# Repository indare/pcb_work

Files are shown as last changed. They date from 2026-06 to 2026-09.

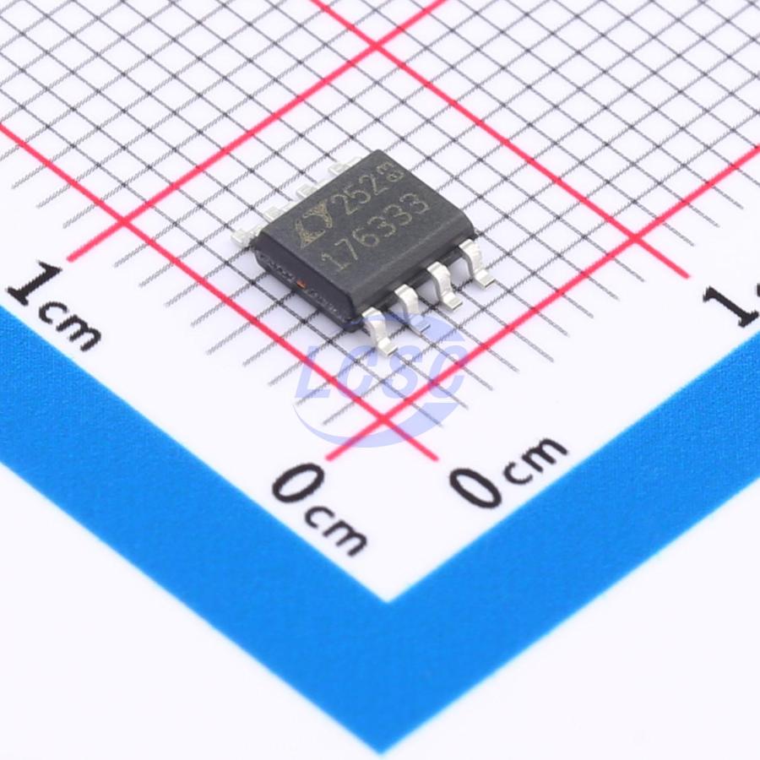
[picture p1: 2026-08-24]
tmp_lt1763_ref/lcsc_tr_front.jpg

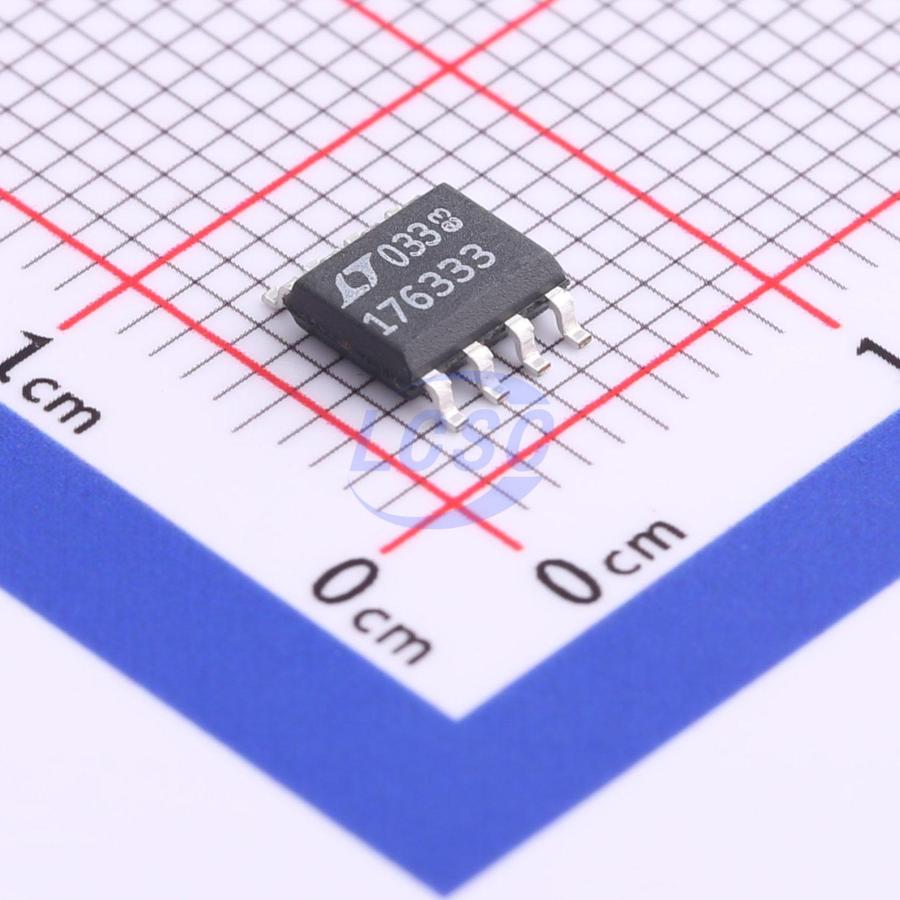
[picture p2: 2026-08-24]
tmp_lt1763_ref/lcsc_is8_front.jpg

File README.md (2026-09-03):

# PCB Work

KiCad 10 の基板・回路図リポジトリです。**いま設計作業をしているのは `AudioV2/`**。
v1 の実機（AudioCase / MeasurementADC）は `Audio/` にあり、こちらは組んで動いているものです。

## ディレクトリ

| パス | 内容 |
| --- | --- |
| `AudioV2/` | 現行の設計作業。回路図・生成スクリプト・検討メモ。[案内](AudioV2/AGENT_HANDOFF.md) |
| `Audio/` | v1 実機。AudioCase 本体・MeasurementADC・分割 Gerber・計測 FW。[案内](Audio/README.md) |
| `Control/` | Controll 用 Pico2 ファーム（親／子） |
| `docker/` | KiCad 10.0.6 のヘッドレス検証環境（ERC / ネットリスト / DRC / Gerber）。[案内](docker/kicad-cloud-build/README.md) |
| `scripts/` | 環境セットアップ。ローカルで回せない検証をクラウドエージェントへ投げるための導入手順。[案内](scripts/README.md) |
| `.cursor/` | Cursor 用ルール・MCP 設定 |

## いまの実機（要約）

- **Amp → MeasurementADC（LCD スペアナ）** が接続して動作中
- Controll 2 段は外している。EQ は今号では使わない
- 次は MeasurementADC 初号ジャンパの次号解消 → 端子台／ケース
- 詳細: [Audio/MeasurementADC_STATUS.md](Audio/MeasurementADC_STATUS.md)

## Cursor MCP（KiCad）

プロジェクト設定: [`.cursor/mcp.json`](.cursor/mcp.json)  
雛形: [`.cursor/mcp.json.example`](.cursor/mcp.json.example)

個人の絶対パスはコミットしません。Cursor の変数展開を使います。
**2026-09-04 に Cursor で実際に動作確認済み**（`${workspaceFolder}` は展開され、`uvx` は PATH から解決される）。

```json
{
  "mcpServers": {
    "kicad": {
      "type": "stdio",
      "command": "uvx",
      "args": ["kicad-mcp-pro"],
      "env": {
        "KICAD_MCP_PROJECT_DIR": "${workspaceFolder}/AudioV2",
        "KICAD_MCP_PROFILE": "full",
        "KICAD_MCP_OPERATING_MODE": "write"
      }
    }
  }
}
```

### 前提

1. [uv](https://docs.astral.sh/uv/) を入れる（`uvx` が PATH に載ること）
2. Cursor を再起動し、**Settings → Tools & MCP** で `kicad` を ON
3. KiCad で基板を開くときは IPC API を有効にしておく（MCP のライブ連携用）

### 変数

| 値 | 意味 |
| --- | --- |
| `${workspaceFolder}` | このリポジトリのルート（`.cursor/mcp.json` がある側） |
| `KICAD_MCP_PROJECT_DIR` | KiCad プロジェクトディレクトリ（現行は `AudioV2/`） |
| `KICAD_MCP_PROFILE` | `full`（2026-09-02 に `build` から変更。AudioV2 移行と同時） |
| `KICAD_MCP_OPERATING_MODE` | `write`（読み取り専用にしたい場合は `readonly`） |

### PATH に `uvx` が無い場合

ユーザー設定 `~/.cursor/mcp.json`（コミット対象外）にだけフルパスを書いてください。  
ローカル上書き用: `.cursor/mcp.local.env`（gitignore 済み）。

### Windows / Git Bash

このリポジトリの KiCad CLI は Git Bash 経由を想定しています。`kicad-cli` は KiCad 10.0 の bin が PATH にあること。

## MeasurementADC メモ

- 進捗: `Audio/MeasurementADC_STATUS.md`
- 発注: `Audio/MeasurementADC_ORDER.md`
- ブリングアップ履歴: `Audio/MeasurementADC_BRINGUP.md`
- MBC2596-01 FP（0°）: 左上 IN+ / 左下 IN- / 右上 OUT+ / 右下 OUT-

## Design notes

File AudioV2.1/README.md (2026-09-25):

# AudioV2.1

**「オペアンプを電子的に切り替えて、なんとなく音が違うのを楽しむ箱」の KiCad プロジェクト。**
計測系が載っているのは表示と簡易分析のためで、装置そのものは計測器ではない。優劣は測定ではなく耳で決める。

v2.1 は「選んだ ch だけ電源と入力を生かす」構成。何を決めたかは [DECISIONS.md](DECISIONS.md)、いま何待ちかは [NOW.md](NOW.md)。
この段落より詳しいことは以下の文書が正。**README には書かない。**

## 入口

| | 何が書いてあるか |
|---|---|
| [NOW.md](NOW.md) | **いま何待ちか・次の一手。再開はここから** |
| [CLAUDE.md](CLAUDE.md) | 守ること。シートの所有権・禁止事項・検証コマンドと期待値 |
| [DECISIONS.md](DECISIONS.md) | **決定の正。** 何を決めたか・なぜか・何を捨てたか。v2 から引き継いだものは §7 |

## この下にあるもの

| | |
|---|---|
| `*.kicad_sch` / `AudioV2.kicad_sym` / `AudioV2Case.kicad_pro` / `AudioV2Case.kicad_pcb` | 回路図と PCB |
| [lib/](lib/) | プロジェクトの KiCad ライブラリ（`Library.pretty`・`BP5293_ROHM`・`MeasurementADC1804`・`MeasurementADC_Extras`）。名前は図の `lib_id` と PCB の footprint 名が使うので変えない |
| [ds_facts/](ds_facts/) | データシートから読んだ事実（照合済み） |
| [datasheets/](datasheets/README.md) | 参照したデータシート PDF。手持ちオペアンプの DS は `datasheets/opamps/` |
| [OPAMP_STOCK.md](OPAMP_STOCK.md) | 手持ちオペアンプの一覧（ユーザー申告） |
| [PARTS.md](PARTS.md) | 品番と機能等価の代替。BOM のブロックは回路図から生成する |
| [review/](review/README.md) | 調査・否定側査読・棚卸しの記録（凍結。行番号の基準は `review/README.md`） |
| [spice/](spice/README.md) | 設計判断の根拠に回した ngspice ネットリスト |
| [scripts/](scripts/) | 回路図の生成・編集・検証の道具（v2 からの写し。扱いは [CLAUDE.md](CLAUDE.md)） |
| [firmware/](firmware/README.md) | Pico のファーム（骨格） |
| [legacy/](legacy/README.md) | 道具が読む旧シート（v2 からの写し。設計には反映されない） |
| 発注リスト | **持たない。** 発注のときに [PARTS.md](PARTS.md) の生成部品表から起こす。ベンダのデータを読むときの罠は §0b |

部品数・ERC 件数・ネット名・ピン接続は**回路図が正**。文書の値は当時のもの。

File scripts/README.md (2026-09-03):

# scripts/

リポジトリ横断のインフラ・環境系スクリプト。

## `cloud-agent-setup.sh`

Cursor Cloud Agent の**ダッシュボード管理（DB管理）開発環境**用の冪等セットアップスクリプト。

このリポジトリの検証ワークフローが前提とするツールを導入する:

| ツール | 用途 |
|---|---|
| KiCad 10 本体 (`kicad-cli` + `pcbnew`) | S式チェック後の `kicad-cli sch export netlist`、ERC / DRC / Gerber / ドリル出力、`Audio/scripts` の pcbnew 依存スクリプト |
| KiCad 標準ライブラリ (`kicad-symbols` / `kicad-footprints` / `kicad-templates`) | 標準シンボル / フットプリントの解決、グローバル lib-table |
| `ngspice` | `AudioV2/spice/*.cir` を `ngspice -b` で回す（設計判断の根拠にした波形の再現） |
| `uv` / `uvx` | README「前提」記載の kicad-mcp-pro（KiCad MCP サーバ）の起動 |

KiCad は公式 PPA `ppa:kicad/kicad-10.0-releases`（Ubuntu 24.04 で `10.0.6`）から
`--no-install-recommends` で導入する。GUI ではなくヘッドレス CLI 検証が目的のため、
`docker/kicad-cloud-build/` のソースビルドイメージと違いフルビルドは不要。

パッケージ構成は `docker/kicad-cloud-build/Dockerfile.10.0.6` の runtime 段にそろえてある
（本体 + シンボル / フットプリント / テンプレート + `ngspice` + グローバル lib-table のシード）。
3D モデル (`kicad-packages3d`, 展開 ~5.6GB) は Dockerfile 側も含めないため対象外。

### モード

| | 動き |
|---|---|
| 既定 | `apt-get` があれば導入する。無ければ**検証のみに落ちる**（下記） |
| `--verify` | 何も導入せず、揃っているかだけ見て報告する。足りなければ非ゼロ終了 |

```sh
bash scripts/cloud-agent-setup.sh            # Cloud Agent の install コマンド
bash scripts/cloud-agent-setup.sh --verify   # 環境が揃っているかだけ見る
```

冪等なので再実行しても安全。

### Windows / macOS では検証のみ

`apt-get` が無い環境では導入せず検証だけする。**黙って「セットアップ完了」と
言わせないため** — 以前は `kicad-cli` と `uv` が既にあるとどちらもスキップし、
`/usr/share/kicad/template/` が無いので lib-table のコピーも飛ばして、
何も検証せずに成功を名乗っていた。

検証は置き場の違いを吸収する。KiCad の設定は Linux が `~/.config/kicad/<ver>`、
Windows が `%APPDATA%/kicad/<ver>`。lib-table の雛形は `kicad-cli` の実体から
`../share/kicad/template` を辿るので、`/usr/share` でも
`C:/Program Files/KiCad/<ver>/share` でも同じ式で当たる。

Windows で KiCad は公式インストーラで入れる（このリポジトリは WSL2 / Docker を
前提にしない）。詳細は `.cursor/rules/kicad-cli-git-bash.mdc`。

> **`ngspice` は Windows の KiCad には CLI が入らない。** 同梱されるのは内蔵
> シミュレータ用の `ngspice.dll` と `lib/ngspice` だけで、`ngspice -b` は打てない。
> `AudioV2/spice/*.cir` を回すなら別途入れる。`--verify` はこれを検出する。

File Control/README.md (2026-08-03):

# Pico 2 Control Notes

## Board

- Board: Raspberry Pi Pico 2
- MCU: RP2350
- Firmware: MicroPython v1.28.0
- Bootloader drive name before flashing: `RP2350`

## Dual-board layout

| | Parent | Expansion (child) |
| --- | --- | --- |
| Firmware | `main.py` | `slave.py`（書き込み時は `:main.py`） |
| OLED | あり（J17） | なし |
| Encoder | あり（J13） | なし |
| Relays | UI CH1–5 | UI CH6–10（基板上はローカルCH1–5） |
| I2C role | master `400kHz` | slave `0x42` |

Parent J17（`GND` / `3V3` / `SCL` / `SDA`）を child J17 に延長する。エンコーダは親だけ。

## OLED Connection

| Pico 2 physical pin | Pico 2 signal | OLED signal |
| --- | --- | --- |
| 26 | GP20 / I2C0 SDA | SDA |
| 27 | GP21 / I2C0 SCL | SCL |
| 36 | 3V3 OUT | VCC |
| GND | GND | GND |

## I2C expansion protocol

Shared constants live in `protocol.py`.

| Register | Meaning |
| --- | --- |
| 0 | command（親が書く） |
| 1 | status |
| 2 | completion counter（コマンド完了で +1） |

| Command | Meaning |
| --- | --- |
| `0x00` | 全ローカルCH RESET |
| `0x01`–`0x05` | ローカルCH apply（ポップ対策シーケンス込み） |
| `0x10` | ping → status `0xA5` |

バス速度は 400kHz。100kHz に落とすと SSD1306 の 1KB フレーム転送が I2C タイムアウトに掛かり、描画が砂嵐になる。カスケードで波形が厳しい場合は速度を下げるのではなく `show()` をページ分割すること。

親の挙動:

- 起動時に `0x42` を scan + ping。いなければ **CH1–5 のみ**
- CH1–5 apply 時: 子へ RESET → 親ローカル apply
- CH6–10 apply 時: 親ローカル RESET → 子へ apply(`CH-5`)

## Files

| File | Role |
| --- | --- |
| `main.py` | 親UI（エンコーダ / OLED / 振り分け） |
| `slave.py` | 子I2Cスレーブ |
| `relays.py` | リレーGPIOと切替シーケンス |
| `protocol.py` | アドレス・コマンド定義 |
| `ssd1306.py` | OLEDドライバ |
| `encoder_debug.py` | エンコーダ生ログ |

## Rotary Encoder Connection

| Pico physical pin | Pico signal | Encoder signal |
| --- | --- | --- |
| 29 | GP22 | ENC_A |
| 31 | GP26 / ADC0 | ENC_B |
| 32 | GP27 / ADC1 | ENC_SW |

J13 pinout: `1=ENC_A`, `2=ENC_B`, `3=ENC_SW`, `4=3V3`, `5=GND`  
（逆挿しすると 3V3–GND 短絡でハングするので向き注意）

## Relay mapping (local board)

| Local CH | AUDIO | PWR |
| --- | --- | --- |
| 1 | K4 | K3 |
| 2 | K2 | K1 |
| 3 | K8 | K5 |
| 4 | K9 | K6 |
| 5 | K10 | K7 |

Apply sequence: AUDIO RESET → 0.1s → PWR RESET → selected PWR SET → 0.3s → selected AUDIO SET。コイルは 0.1s パルス。

## Upload

macOS example（親）:

```bash
python3 -m mpremote connect /dev/cu.usbmodem* fs cp Control/protocol.py :protocol.py
python3 -m mpremote connect /dev/cu.usbmodem* fs cp Control/relays.py :relays.py
python3 -m mpremote connect /dev/cu.usbmodem* fs cp Control/ssd1306.py :ssd1306.py
python3 -m mpremote connect /dev/cu.usbmodem* fs cp Control/main.py :main.py
python3 -m mpremote connect /dev/cu.usbmodem* reset
```

macOS example（子 / 拡張）:

```bash
python3 -m mpremote connect /dev/cu.usbmodem* fs cp Control/protocol.py :protocol.py
python3 -m mpremote connect /dev/cu.usbmodem* fs cp Control/relays.py :relays.py
python3 -m mpremote connect /dev/cu.usbmodem* fs cp Control/slave.py :main.py
python3 -m mpremote connect /dev/cu.usbmodem* reset
```

Windows では `py -3.13 -m mpremote connect COMx ...`。

BOOTSEL 時は Pico 2 の UF2 を `RP2350` ドライブへコピーして MicroPython を入れる。

## Confirmed so far (single board)

- MicroPython v1.28.0 on Pico 2
- OLED `0x3c` SSD1306 128x64
- Encoder channel select + relay apply on CH1–5
- Controll schematic ERC 0

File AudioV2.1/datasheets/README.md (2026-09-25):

# AudioV2.1 — データシート

v2.1 の設計・査読で引いている部品の一次資料。オフライン参照用にローカル PDF を置く。
DS から読んだ事実（照合済み）は [../ds_facts/](../ds_facts/)、決定は [../DECISIONS.md](../DECISIONS.md)。
2026-09-25 に、v1 の置き場から引いていた手持ちオペアンプの DS と Traco `TMR9`・`TMR6` をここへ写した（v2.1 はここだけを読む）。

## サブディレクトリ

| | 中身 |
|---|---|
| [opamps/](opamps/) | 手持ちオペアンプ 16 石＋ NE5532 本家の DS。石と PDF の対応は [../OPAMP_STOCK.md](../OPAMP_STOCK.md) |
| [boundary/](boundary/) | 境目の切替素子の候補（照合は [../ds_facts/verify_boundary.md](../ds_facts/verify_boundary.md)） |
| [detect/](detect/README.md) | 娘のレール検知の候補 |
| [relay4/](relay4/) | 4 回路リレーの候補（`ds_facts/relay4.md` は未照合） |
| [tap/](tap/) | 計測タップの結合・絶縁の候補 |
| [arch/](arch/) | 制御の木（デコーダ・ロードスイッチ・監視）の候補 |
| [reference/](reference/) | 参考製品の取説 |

## 電源・PD

| 部品 | 用途 | ローカル | 取得元 |
|---|---|---|---|
| **RS6-1215D**（Recom） | ±15 V DC-DC（v2.1 の主電源、DECISIONS §3-1） | [Recom_RS6.pdf](Recom_RS6.pdf) | Recom |
| **REC20K-2415DZ**（Recom） | ±15 V DC-DC（今の図。v2 から） | [Recom_REC20K-Z_Rev3-2025.pdf](Recom_REC20K-Z_Rev3-2025.pdf) | Recom |
| **TMR 9 / TMR 6**（Traco） | 主電源の比較の候補 | [TMR9_Datasheet.pdf](TMR9_Datasheet.pdf)・[TMR6_Datasheet.pdf](TMR6_Datasheet.pdf) | Traco |
| **[50224] CH224** | USB-PD（外付けモジュール、板上は受け端子） | [StrawberryLinux_CH224K_manual.pdf](StrawberryLinux_CH224K_manual.pdf) 他 | ストロベリーリナックス |
| **DKMW20F-15** | ±15 V DC-DC（v2 の初期に使った。今の図には無い） | [MeanWell_SKMW20_DKMW20.pdf](MeanWell_SKMW20_DKMW20.pdf) | [Mean Well SKMW20/DKMW20](https://www.meanwell.com/webapp/product/search.aspx?prod=DKMW20) |
| **BP5293-50** | +5 V（コイル・デジ） | [ROHM_BP5293-xx.pdf](ROHM_BP5293-xx.pdf) | [ROHM BP5293-xx](https://www.rohm.com/products/power-management/switching-regulators-integrated-fet/bp5293-xx-series) |
| **L7805C / L7809** | コイルの 5 V（v2.1）／PT2314E の 9 V | [ST_L78.pdf](ST_L78.pdf) | ST |
| **TPS7A49 / TPS7A30** | ch ごとの LDO（v2.1） | [TI_TPS7A49.pdf](TI_TPS7A49.pdf)・[TI_TPS7A30.pdf](TI_TPS7A30.pdf) | TI |

### DC-DC の候補（2026-09-05 の再探索。**採否は未決**）

`dcdc_survey.py` で 431 件を引き、±12 V 両レール・MOQ 1・在庫あり・12 V 入力対応の
220 件から実読した分。**選定の決め手になる `Cout`（最大容量負荷）・軽負荷での `Fsw` の
扱い・絶縁容量・最小負荷は、どれも DigiKey API には無くデータシートにしかない。**
だからここに置いてある（以下は v2 のときの探索の記録。v2.1 の比較は `../review/main_power_compare.md` ほか）。

**⚠ この表の数値は ±12 V 両出力版のもの。** 同じ系列でも単出力版・±15 V 版では `Cout` が
まるで違う（TEL 10WI は単出力 12 V が 560 µF、±12 V dual は 390 µF。EC7AW は単出力 24S12 が
833 µF、±12 V dual は 417 µF）。**モデル行を取り違えると倍以上ずれる。**

**⚠⚠ `Fsw` の欄で候補を比べてはいけない。** 「Aimtec は @100% load と条件付き、Recom は
条件が書いていない」という差は**見せかけ**だった —— Recom は同じ条件を**表の見出し**に
書いている（`REC10K-AW.pdf` p2 *"BASIC CHARACTERISTICS (measured @ TAMB= 25°C, nom. VIN,
**full load** and after warm-up unless otherwise stated)"*）。Cincon も Traco も同様の全負荷注記が
あり、**下の候補は9品すべて全負荷規定**。しかも Recom の 350 kHz は **Max. 列**（Min./Typ. 欄は空）で、
軽負荷で下がることと矛盾しない。

**この欄で意味があるのは次の2つだけ:**
- **Mornsun `URA_ZP-10WR3` / `URA_LD-20WR3` は「軽負荷（50%以下）で周波数を下げる」と明記**（不採用の根拠。この箱が追っている 1.2 kHz スパーの第一容疑者と同系統の挙動）
- **Traco `TEL`/`TMR` は "(PWM)" と明記**（PFM／バーストではない、という積極的な主張）

それ以外の「書いていない」は**全部同じ**で、優劣を付ける材料にならない。

| 部品 | ローカル | `Cout`（±12V dual） | `Fsw` の書かれ方 | 絶縁容量 | 最小負荷 | 効率 |
|---|---|---|---|---|---|---|
| **REC20K-Z**（Recom） | [Recom_REC20K-Z_Rev3-2025.pdf](Recom_REC20K-Z_Rev3-2025.pdf) | `2415DZ`=**±3000 µF** / `2412DZ`=**±4000 µF**（p1） | "Internal Operating Frequency" 265 kHz、Max. 列（p2） | **2000 pF** typ（p6） | **0 %**（p2） | 88 % |
| **REC10K-AW**（Recom） | [Recom_REC10K-AW_Rev2-2025.pdf](Recom_REC10K-AW_Rev2-2025.pdf) | `2412DAW`=**±470 µF** / `2415DAW`=±270 µF（p1） | "Internal Operating Frequency" 350 kHz、**Max. 列**・条件欄空（p2） | 1000 pF typ（p6） | **0 %**（p2、Min. 列） | 85 % |
| **AM10TW-LPZ**（Aimtec） | [Aimtec_AM10TW-LPZ.pdf](Aimtec_AM10TW-LPZ.pdf) | `2412DLPZ`=**470 µF**（± 表記なし、p2） | 300 kHz、条件 **"100% load"**、Min./Max. 欄空（p3） | **2000 pF**（p2） | 項目なし | 87 % |
| **AM15CW-LPZ**（Aimtec） | [Aimtec_AM15CW-LPZ.pdf](Aimtec_AM15CW-LPZ.pdf) | `2412DLPZ`=**±470 µF**、±625 mA（p2） | 300 kHz、条件 **"100% load"**（p3） | **2000 pF**（p3） | 項目なし | 90 % |
| **NSD10-D**（MEAN WELL） | [MeanWell_NSD10-D.pdf](MeanWell_NSD10-D.pdf) | **±1000 µF** と最大。ただし**6モデル横断の1セル**でモデル別値ではない（p1） | 仕様表に**記載なし**。p2 ブロック図に "fosc : 350KHz" とあるだけ | **記載なし** | 項目なし（`CURRENT RANGE` 下限が 0.02 A） | **77 %** |
| **EC7AW**（Cincon） | [Cincon_EC7AW.pdf](Cincon_EC7AW.pdf) | **417 µF**（± 表記なし、p1） | **"Fixed Switching Frequency"**（p1 Features、**文書内ここ1箇所のみ**）。特性表は 477/530/**583** kHz ≒ ±10 % の幅で、**両者を結ぶ注記は無い**（p3） | 1000 pF typ（p3） | 項目なし（`OUTPUT CURRENT MIN.` が 0 mA） | 88.5 % |
| **EC2SBW**（Cincon） | [Cincon_EC2SBW.pdf](Cincon_EC2SBW.pdf) | **470 µF**（± 表記なし、p1） | **"100 kHz min."**（p2、条件記載なし。**下限表記＝可変を示唆**） | 1000 pF typ（p2） | 項目なし（`OUTPUT CURRENT MIN.` が 0 mA） | 86 % |
| **TEL 10WI**（Traco） | [Traco_TEL10WI.pdf](Traco_TEL10WI.pdf) | **390 / 390 µF**（p2） | 355-485 kHz (PWM) / 420 kHz typ（p3） | **1'500 pF max**（p3、候補中で最大） | **"Not required"**（p2） | 87 % |
| **TMR 10WI**（Traco） | [Traco_TMR10WI.pdf](Traco_TMR10WI.pdf) | **390 / 390 µF**（p2） | 390-450 kHz (PWM) / 420 kHz typ（p3） | 1'000 pF typ / **1'500 pF max**（p4） | **"Not required"**（p2） | 88 % |

**⚠ 絶縁容量は候補ごとに桁ではなく倍で違う。** この設計の絶縁は `PD_GND` と `A_GND` を
分ける構造そのもので、効くのは耐電圧（functional）ではなく**絶縁容量**の方
（v2 のときの否定側査読）。**Aimtec 2品は 2000 pF で Recom / Cincon の2倍。**
安いのはこの2品だが、**この設計がいちばん気にしている欄で最下位**にいる。

**`U1604` の下流 LDO**（置き換え候補の足切りを決める）:

| 部品 | ローカル | この設計に効く数字 |
|---|---|---|
| **LT1763**（ADI） | [ADI_LT1763.pdf](ADI_LT1763.pdf)（`1763fh`） | **⚠ `LT1763-5` の実負荷での規定は `6V < VIN < 20V, 1mA < ILOAD < 500mA`**（p4）。`VIN=5.5V` の行は `ILOAD=1mA` のときだけ。**これで固定 6 V の三端子が全部落ちる**（DECISIONS `V21-継-13`）。Ripple Rejection **50 min / 65 typ dB**（p5、条件に `CBYP` は入っていない）。Figure 3（p16）が「容量を増やせば最小 ESR は 0 に近づく」を示す |

⚠ `analog.com` はこの環境から不通（接続自体が落ちる）。**DigiKey API の `DatasheetUrl` で正しい版（`1763fh`）を特定し、`bdtic.com` のミラーから取得**した。

**`+9V` の三端子レギュレータ**（±12 V 化の障害③に直結）:

| 部品 | ローカル | この設計に効く数字 |
|---|---|---|
| **NJM7809FA**（日清紡マイクロデバイス） | [NJR_NJM7800.pdf](NJR_NJM7800.pdf)（`Ver.1.2`） | **規定入力範囲の下限は 11.5 V**（p3、Line Regulation の試験条件が `VIN=11.5 to 25V, IO=0.5A`）。**ドロップアウト特性のグラフは NJM7805 と NJM7812 にしかなく、7809 には無い**（p8-9）＝ 30 mA 級での規定が無い。`IQ` typ 4.3 / max 6.0 mA、絶対最大入力 35 V |

**⚠ 上の値は2版で照合済み。** 旧 `Ver.2007-05-16`（New JRC 表記）と現行 `Ver.1.2`（日清紡）を
突き合わせたところ、**NJM7809 の行は 19 年間まったく変わっていない** —— 出力 8.65/9.0/9.35 V、
`VIN=11.5 to 25V`、`IQ` 4.3/6.0 mA、絶対最大 35 V、**7809 のドロップアウト曲線が無いことまで同じ**。
違ったのは絶対最大定格のモデル群の括り方（`7805 to 7809` → `7805 to 7810`）と
パッケージ表記（`DL1` → `DL1A`）だけ。**旧版はリポジトリに置かない**（同じ事実を2箇所に
置くと片方が腐る）。

**⚠ `L7809CV` は ST 純正が DigiKey に存在しない**（UMW / Lumimax / EVVO のセカンドソースのみ。
2026-09-05 に API で確認）。**なので入力範囲の議論は ST 版ではなく、実際に買える石で
やること。** 手持ちの `NJM7809FA`（在庫 9263・アクティブ）は**同じ 11.5 V 下限**なので、
**障害③は石を替えても消えない。** ⚠ `NJM7809FA` は TO-220F なのでフットプリントが別。

**不採用が確定した候補の一次資料**（落選根拠がデータシートの一文にあるので置く）:

| 部品 | ローカル | 落選根拠（原文） |
|---|---|---|
| **URA_ZP-10WR3**（Mornsun） | [Mornsun_URA_ZP-10WR3.pdf](Mornsun_URA_ZP-10WR3.pdf) | **p3 注①** *"Switching frequency is measured at full load. **The module reduces the switching frequency for light load (below 50%) efficiency improvement.**"* —— この箱が追っている 1.2 kHz スパーと同系統の挙動を自分で作りに行くことになる。`Cout` 470 µF（**注③「Vo1 と Vo2 の値は同一」＝片レール**）・絶縁容量 **2000 pF** |
| **URA_LD-20WR3**（Mornsun） | [Mornsun_URA_LD-20WR3.pdf](Mornsun_URA_LD-20WR3.pdf) | **p3 Note \*** に同一文。加えて 2"×1" で面積が倍 |
| **PYBE10**（CUI / Bel） | [CUI_PYBE10.pdf](CUI_PYBE10.pdf) | **p3 note 9** *"Value is based on full load. **At loads <50%, the switching frequency decreases with decreasing load**"* —— Mornsun と同じ。`Cout` 470 µF・絶縁容量 2000 pF・350 kHz PWM・±416 mA と**数値が全部一致**する。DigiKey では **NFND**。⚠ `belfuse.com` のリンクは製品ナビの HTML を返す。**実体は CUI 側**（`cui.com/product/resource/pybe10.pdf`） |

**TDK-Lambda `CCG15-30W`**（2026-09-05）。`product.tdk.com` は TDK 自身の Akamai が 403 を返し、
`curl`・`WebFetch`・実 Chromium すべて不可。**⚠ ただし「取得不能」と結論したのは誤りだった** ——
**公開ミラーで取れる**（`docs.rs-online.com/b44f/A700000006915758.pdf` が取説、
`4donline.ihs.com` にカタログ。どちらも認証なしで 200）。**4つ試して諦めたのが早すぎた。**
Farnell と Octopart のミラーが単出力のみだったのは事実だが、**それは短縮版を引いていただけ**:

| ローカル | 中身 |
|---|---|
| [TDK-Lambda_CCG15-30.pdf](TDK-Lambda_CCG15-30.pdf) | カタログ。p1 モデル表、p3 仕様表 |
| [TDK-Lambda_CCG15-30_manual.pdf](TDK-Lambda_CCG15-30_manual.pdf) | 取説。**p8 Table 5-1 が最大外部出力容量** |

| 項目 | 値 | 出典 |
|---|---|---|
| **最大外部出力容量** | **±12V: ±1,200 µF / ±15V: ±1,000 µF** | 取説 p8 Table 5-1・カタログ p3 |
| **その容量はどこに繋ぐ値か** | **`CCG-D` は「+Vout と COM の間」「−Vout と COM の間」＝ 片レール**（取説 p8 に明記） | 取説 p8 |
| 最小負荷 | **"No minimum load required"** | カタログ p3 |
| `Fsw` | `CCG-D`: **430 kHz**。**取説 p4 のブロック図が `Switching Frequency(fixed) : 430kHz` と "fixed" を明記**（⚠ 当初「記載なし」としたのは誤り。同上） | カタログ p3 / 取説 p4 |
| **絶縁容量** | **1000 pF**（取説 p17 §6-19 *"This product has internal capacitor connected between input and output. Capacitance of input - output : 1000pF"*）。**⚠ 当初「非公表」と記録したのは誤り —— カタログ p3 にしか無いと思い込み、同時に持っていた取説を見ていなかった。** この欄では `EC4SBW`(1500 pF) より良く、`REC20K`(2000 pF) の半分 | 取説 p17 |
| **`RC` ピン** | **⚠ サフィックス無しは負論理 —— *"ON when pin is shorted, OFF when open"*。`REC10K` の「開放 = ON」と逆で、ON にするのに `−Vin` へのショートが要る**（取説 §6-7 Note 1）。`/P` サフィックスが正論理（開放 = ON）だが、**`/P` 品は DigiKey に無い**（`CCG15-24-12D/P` / `-15D/P` / `CCG30-24-15D/P` すべて 0 件）。**⚠ この事実は Farnell / Octopart の短縮版 p1 にも書かれていた**（*"Standard: Low = ON, Open = OFF"*）。**欄の名前だけ見て行を読まなかったせいで「DigiKey 属性は信用できないので裏取り待ち」と誤って記録した** | カタログ p2・p3、取説 §6-7 |
| OCP | **hiccup mode, >105 %**（`REC10K` の 150 % に比べてかなり狭い） | カタログ p3 |
| 寸法 | 25.4×25.4×9.9（1"×1"） | カタログ p3 |
| 該当品 | `CCG15-24-12D` ±12V ±650 mA 89 % ¥5,082 在庫 80 ／ `CCG15-24-15D` ±15V ±500 mA 90 % ¥5,082 在庫 108 | カタログ p1・API |

**⚠⚠ 記録が「`Cout` ≥ 102 µF の足切りで TDK-Lambda `CC`/`CCG` 系が落ちた」としていたのは誤り。**
`CCG` の `Cout` は **1,000〜1,200 µF** で、その足切りの10倍以上ある。**落ちる理由が無かった。**

**不採用が確定した候補の一次資料**（落選根拠がデータシートの一文にあるので置く）:

| 部品 | ローカル | 落選根拠（原文） |
|---|---|---|
| **URA_ZP-10WR3**（Mornsun） | [Mornsun_URA_ZP-10WR3.pdf](Mornsun_URA_ZP-10WR3.pdf) | **p3 注①** *"Switching frequency is measured at full load. **The module reduces the switching frequency for light load (below 50%) efficiency improvement.**"* —— この箱が追っている 1.2 kHz スパーと同系統の挙動を自分で作りに行くことになる。`Cout` 470 µF（**注③「Vo1 と Vo2 の値は同一」＝片レール**）・絶縁容量 **2000 pF** |
| **URA_LD-20WR3**（Mornsun） | [Mornsun_URA_LD-20WR3.pdf](Mornsun_URA_LD-20WR3.pdf) | **p3 Note \*** に同一文。加えて 2"×1" で面積が倍 |
| **PYBE10**（CUI / Bel） | [CUI_PYBE10.pdf](CUI_PYBE10.pdf) | **p3 note 9** *"Value is based on full load. **At loads <50%, the switching frequency decreases with decreasing load**"* —— Mornsun と同じ。`Cout` 470 µF・絶縁容量 2000 pF・350 kHz PWM・±416 mA と**数値が全部一致**する。DigiKey では **NFND**。⚠ `belfuse.com` のリンクは製品ナビの HTML を返す。**実体は CUI 側**（`cui.com/product/resource/pybe10.pdf`） |

**⚠ TDK-Lambda `CC`/`CCG` 系はこの環境から取得できない。** `product.tdk.com` は
**TDK 自身の Akamai** が 403 を返す（本文に `errors.edgesuite.net` の参照番号）。
`curl`・`WebFetch`・**プリインストールの実 Chromium** すべて 403 で、
**クライアント指紋ではなく IP レピュテーションでの遮断**。代理店ミラー
（Farnell / Octopart）は本物の TDK 文書だが**単出力のみ・`Cout` 欄そのものが無い**短縮版。
`Cout` は `ccg_e.pdf`（カタログ）と `ccg_apl.pdf`（取説 Table 5-1）にしかなく、
どちらも `product.tdk.com` のみ。**`CCG15-24-12D`（¥5,082・在庫 80・±650 mA・1"×1"）は
`Cout` 不明のまま未評価。** 判断するには通常回線からの人手が要る。

| **EC4SBW**（Cincon） | [Cincon_EC4SBW.pdf](Cincon_EC4SBW.pdf) | `24D15`=**650 µF/レール**（p1） | **p1 features に "Fixed Switching Frequency" を明記**。`Others` は **330 kHz typ**、3.3/5V のみ 270 kHz（p2） | **1500 pF typ**（p2） | **0 mA**（p1） | 89 % |

**⚠ `REC20K-2415DZ` にはメーカーの EMC フィルタ推奨が無い。** `Recom_REC20K-Z_Rev3-2025.pdf` p8
**Note8: *"Filter suggestions are valid for `REC20K-2405SZ` only."*** —— `REC10K` 側の
「Dual 用推奨に `2415DAW` が入っていない」より穴が広い（`REC20K` は単出力1品にしか無い）。

**⚠⚠ `REC20K-Z` は ±15 V のままで `Cout` の宿題を閉じられる。** 現行 `REC10K-2415DAW/H2` の
`Cout ±270 µF` はレール総容量に対して余裕が無いが、**同じ Recom・同じ 1"×1"・同じピン配置**
（Dual: 1 +Vin / 2 −Vin / 3 CTRL / 4 −Vout / 5 COM / 6 +Vout。`REC20K-Z` p9）の
`REC20K-2415DZ` は **±3000 µF**・±667 mA・88 %・絶縁 2 kVDC（**grade basic**、`REC10K` は
functional）で、差額は **+¥1,216**（¥3,620 / 在庫 162 / MOQ1）。
**`TMUX7612` の膝も `L7809` の入力下限もネット名の改名も、一切触らずに済む。**
代償は絶縁容量が 1000 → **2000 pF** に悪化することと、ピン径が Ø1.0→**Ø1.4 mm**（穴径が別。PCB 未設計なので実害なし）。
**この選択肢は 2026-09-05 の否定側査読で出た。それまでの記録は ±15 V 側を「逃げ道が乏しい」と
誤って結論していた（REC10K 系列しか見ていなかった）。**

**⚠ Recom の EMC フィルタ推奨は `2412DAW` にあって `2415DAW` に無い。**
`Recom_REC10K-AW_Rev2-2025.pdf` **p8** の EN55032 Class B / Dual Output の Component List に
挙がっているのは `REC10K-2412DAW/H2` / `REC10K-2405DAW/H2` / `REC10K-4824DAW/H2` の3つで、
**現行採用の `2415DAW/H2` は入っていない**。Note7: *"Filter suggestions are valid for indicated
part numbers only. For other part numbers, please contact RECOM for advice."*
なお部品表に載っているのは**定数だけ**（C 10 µF / L1 10 µH / CMC1 5 µH / C4,C5 4.7 nF）で、
フィルタ部品のメーカ型番は書かれていない。単出力版は L1 が 33 µH で Dual と違う。

## 音量・トーン

| 部品 | 用途 | ローカル | 取得元 |
|---|---|---|---|
| **PT2314E SOP-28** | Bass / Treble（I²C、Amp 前） | **[Princeton_PT2314E.pdf](Princeton_PT2314E.pdf)** | PT2314E V1.0 / 2010-01 / **15ページ完全版**。ELECTRICAL CHARACTERISTICS あり（`VIH` min 3 V・`RL` 5 kΩ・THD 0.03 % 等 → DECISIONS `V21-継-05`） |
| ~~PT2314 DIP-28~~ | 無印（**不採用**。参考） | [Princeton_PT2314.pdf](Princeton_PT2314.pdf) | v1.1 の**3ページ抜粋**。ピン配置とアプリケーション回路のみで**電気的特性が無い**。ピン配置は E と同一 |
| **Alps RK27112A00CF** ×2 | HP / LINE 手回し音量（A50k Dual） | （メーカーカタログ） | [PARTS.md](../PARTS.md) |
| **Cosland 2MD1 / 2MS1** | DEST（DPDT ON–ON）／PWR | （秋月の商品ページ） | [PARTS.md](../PARTS.md) §2.1 |
| ~~PGA2310PA~~ | **不採用**（DECISIONS `V21-継-02`） | [TI_PGA2310.pdf](TI_PGA2310.pdf) | TI |

## アンプ切替

v2.1 は娘ごとの電源用・音声用ラッチングリレー（1 段目）と、娘の中の TMUX7612（2 段目）の 2 段（DECISIONS §2）。

| 部品 | 用途 | ローカル | 取得元 |
|---|---|---|---|
| **TMUX7612** | 娘の中で ch を選ぶ（4回路SPST） | [TI_TMUX7612.pdf](TI_TMUX7612.pdf) | [TI TMUX7612](https://www.ti.com/lit/ds/symlink/tmux7612.pdf) |
| **AZ850P2-5** | ラッチング DPDT（5 V コイル）。娘の電源用・音声用（DECISIONS §2-2） | [Zettler_AZ850.pdf](Zettler_AZ850.pdf)（[detect/AmericanZettler_AZ850.pdf](detect/AmericanZettler_AZ850.pdf) も） | Zettler |
| **TBD62083A** | コイル駆動（DMOS。ULN2803A とピン互換） | [Toshiba_TBD62083A.pdf](Toshiba_TBD62083A.pdf) | Toshiba |
| **MCP23017** | I²C GPIO 拡張（UI・娘。娘に残すかは V21-未決-03） | [Microchip_MCP23017.pdf](Microchip_MCP23017.pdf) | [Microchip DS20001952C](https://ww1.microchip.com/downloads/en/devicedoc/20001952c.pdf) |
| ~~ULN2803A~~ | コイル駆動（**不採用**） | [ST_ULN2803A.pdf](ST_ULN2803A.pdf) | ダーリントンの約 1 V 降下が 5 V レールの 20 % を食い、40 ℃ で仕様割れ |

## UI・MCU

| 部品 | 用途 | ローカル | 取得元 |
|---|---|---|---|
| ~~SSD1306 / SSD1309~~ | 制御 OLED（**廃止**。図・PCB に無い） | [Solomon_SSD1306.pdf](Solomon_SSD1306.pdf) | — |
| **WAVESHARE-29318** | スペアナ 3.5″ タッチ LCD（ST7796S + FT6336U） | （Wiki） | [スイッチサイエンス 10138](https://www.switch-science.com/products/10138)。状態表示もここ |
| **RP2350** | Pico 2 | [RaspberryPi_RP2350.pdf](RaspberryPi_RP2350.pdf) | [Raspberry Pi RP2350](https://datasheets.raspberrypi.com/rp2350/rp2350-datasheet.pdf) |
| **ロータリ ENC ×3** | CH / BASS / TREBLE | [RotaryEncoder_EC11_generic.md](RotaryEncoder_EC11_generic.md) | 押し SW 付き EC11（DECISIONS `V21-継-01`） |

## 計測

| 部品 | 用途 | ローカル | 取得元 |
|---|---|---|---|
| **PCM1804** | 計測 ADC | [TI_PCM1804.pdf](TI_PCM1804.pdf) | [TI PCM1804](https://www.ti.com/lit/ds/symlink/pcm1804.pdf) |

## 未収録（回路起こし時に追加）

- PD モジュールの差し替え候補（CH224 以外を試す場合）
- 購入 ENC のメーカー寸法図（フットプリント作成時）
- Alps RK27 の紙 DS（メーカーページで足りる。必要なら追加）

## 更新

- 2026-09-25: v2.1 の索引に書き直した。手持ちオペアンプの DS（`opamps/`）と `TMR9`・`TMR6` を v1 の置き場から写した。v2 の決定ログへのリンクを外した
- それより前の更新履歴は v2 のもの（git の履歴にある）

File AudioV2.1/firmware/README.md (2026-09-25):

# AudioV2.1 firmware（MicroPython / Pico 2）

1 台の Pico（`MeasureControl` の Pico）向けの**骨格**。v2 から写したままで、v2.1 の制御の木（電源用・音声用リレー、ch の LDO の EN、レール監視）はまだ入っていない。
v2.1 でファームが守ること・ハードが保証することの正は [DECISIONS.md](../DECISIONS.md) §6。コード中のコメントで v1・v2 を引いているところは v2 のときの記録。

## 方針（今の骨格の形）

| | |
|---|---|
| 操作 | ENC×3 / DEST SW / ポット（回路どおり。タッチ必須にしない） |
| 表示 | Waveshare LCD に CH / DEST / Bass / Treble（OLED なし） |
| Amp 切替 | `amp_select.py` が入口。今は v2 の 2 版（Switch / Relay）用の形。v2.1 の娘は 1 種類で、娘の MCP を残すかは未決（V21-未決-03） |
| I²C0 | PT2314E 同居のため **100 kHz** |
| 計測 | スペアナ／キャプチャは v2.1 には無い。後で同じ LCD 上にモードとして足す |

ピン・アドレスの正は回路図（MeasureControl の Pico 注記、FrontPanel の MCP）。ここに数値を複製しない。

### Switch SEL（起動、今の骨格）

外付け SEL→`D_GND` プルは回路に置かない（TMUX7612 内蔵プルダウン）。
v2.1 では EN は既定 OFF のデコーダと ±15 V の確認の後にだけ出す（DECISIONS §2-9・§6）。詳細は [`amp_select.py`](amp_select.py) 先頭（v2 の形）。

## ディレクトリ

```
firmware/
  README.md
  main.py           # 起動（状態表示＋ENC ループ）
  board.py          # ネット名 → GP / I²C の対応（回路図と揃える）
  encoders.py       # FrontPanel MCP23017（INTA/INTB）
  tone.py           # PT2314E（Bass/Treble）
  amp_select.py     # CH 切替の共通入口
  ui_status.py      # LCD 上の状態バー
  vendor/
    lcd_st7796.py   # Waveshare ST7796S（v1 の計測ファームの LCD ドライバから分岐）
```

## 書き込み（骨格）

```bash
cd AudioV2.1/firmware
mpremote connect <port> fs cp board.py encoders.py tone.py amp_select.py ui_status.py main.py :
mpremote connect <port> fs cp vendor/lcd_st7796.py :lcd_st7796.py
mpremote connect <port> reset
```

実機未検証の骨格。動かすときはまず `ui_status` の静的表示、次に ENC INT、最後に Amp 切替。

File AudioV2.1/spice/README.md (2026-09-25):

# AudioV2 回路シミュレーション

設計判断の根拠として回した ngspice ネットリスト。**v2.1 の判断そのものは [DECISIONS.md](../DECISIONS.md) が正。**
ここはその根拠となった波形を再現するためのもの。多くは v2 の構成（全ソケット常時通電）のときに回したもので、
本文の判定文・「v2 の決定ログ §nn」は v2 のときの記録（v2.1 の決定ではない）。

```bash
ngspice -b AudioV2.1/spice/<file>.cir
```

## `ampbank_switch_pop.cir` — 出力カップリングの置き場所

`AmpBank` でアンプ出力をバスへ繋ぐとき、カップリングコンデンサをアナログスイッチの
**前**に置くか**後**に置くか。後に置けば全 ch 共通の1組で済むが、前に置くと ch 毎に要る。

オペアンプの DC オフセット（NE5532 代表 ±3 mV）を持つ 2 台の間で切り替え、
バスに出る段差を測る。信号を載せると段差が振幅に埋もれるので DC のみで観測する。

| | バスに出る段差 |
|---|---|
| 案A: カップリングが SW の前 | **≈ 0 V**（4e-18） |
| 案B: カップリングが SW の後（共通1組） | **−6.0 mV**、150 ms かけて減衰 |

6 mV は信号 7 V に対し −61 dB でアンプの雑音フロアの約3000倍。低周波過渡なので
「ボツッ」と聴こえる。**案A（ch 毎に前置き）を採用。**

> **⚠ このデッキの限界（2026-09-02 追記）:** 案A側の `a1s`（`Ca1` とスイッチの間）には
> 漏れ電流源を入れていない。そのため「前置きにすると今度はカップリング C の右極板が
> 非選択中に浮く」という論点をこのデッキは検証していない。実際その節点は
> `ampbank_input_pulldown.cir` が扱ったのと同じ構造で、**出力側にも 220 kΩ の
> プルダウンが要る**（2026-09-02 に追加）。2.2 µF に 0.15 nA で 68 µV/s、
> 非選択 1 分で 4 mV。ここで案B を却下した根拠の −6 mV を数分で超える。
出力カップリングを 470 µF → 2.2 µF に小さくしたことで、ch 毎に持っても
面積が 3.6 cm² に収まる（470 µF なら 24.5 cm² で不可能だった）。

## `ampbank_input_pulldown.cir` — 入力 220 kΩ プルダウンの置き場所

現行 AmpModule の入力プルダウン（`R701`/`R706` = 220 kΩ）を、スイッチの
**前**（音源側）と**後**（結合コンデンサの左極板側）のどちらに置くか。

スイッチのオフ漏れ電流（TMUX7612 の max 0.15 nA）を注入し、非選択を 5 秒続けた
あとに再接続する。

| | 非選択中の結合C左極板 | 再接続時の段差 |
|---|---|---|
| 案P: 220 kΩ が SW の**後** | **0.000033 V** | なし |
| 案Q: 220 kΩ が SW の**前** | **150 V**（浮いて漏れ電流で充電） | **−149 V** |

案Q の 150 V は理想モデルゆえの誇張（実機では ESD ダイオードや基板漏れでクランプ
される）だが、「浮いた節点が漏れ電流で充電され再接続時に放電する」機序は実在し、
数百 mV〜数 V の段差になる。**案P（SW の後ろへ移す）を採用。**

これにより 220 kΩ の役割は「ケーブル未接続時に入力を浮かせない」から
**「非選択中に結合コンデンサの左極板を 0 V に保つ」**へ変わる。10 ch すべてに必要。

## `switch_thd.py` — アナログスイッチが足す THD（2026-09-02）

「TMUX7612 は高いので DG412 で足りないか」という検討のために作った。
**`ΔRon / R_load` は THD ではない**（あれは非線形分圧の大きさの目安で、
実際の THD は `Ron(V)` 曲線の形で決まる。TI SCDA058 も同じ説明）ので、
データシートのグラフを **PDF のベクタパスから数値として抽出**し、
時系列を解いて FFT した。目視の読み取りではない。

    data/dg412_ron_curve.json     Vishay 61564 の ±15V カーブ（68点）
    data/tmux7612_ron_curve.json  TI Figure 5-4 の ±15V カーブ（151点）

### 分かったこと1: TMUX7612 の平坦領域は ±11V で終わる

| 信号範囲 | TMUX7612 | DG412 |
|---|---:|---:|
| ±6.5 V（入力側） | 0.001 Ω※ | 1.59 Ω |
| ±13 V（出力側） | **0.313 Ω** | 5.70 Ω |
| ±15 V | 6.309 Ω | 5.70 Ω |

※ グラフの分解能限界。仕様表は 0.0003 Ω。**グラフから mΩ 精度を主張しないこと。**

TI が DS 本文で「best linear performance には上下レールから 5V の headroom」と
書いているのが数値で裏付けられた（±15V 電源なら ±10V まで）。

### 分かったこと2: 出力振幅に膝がある

通し（入力SW → OpAmp×2 → 出力SW → 50kΩ）の THD、Rbias 47k:

| 出力 | TMUX7612 | DG412 |
|---|---:|---:|
| 7.07 Vrms（±10V） | **−162.8 dB** | −90.9 dB |
| 9.2 Vrms（±13V、現仕様） | −115.2 dB | −90.0 dB |
| 10.0 Vrms（±14.1V） | −88.3 dB | −91.2 dB |

**現仕様の 9.2 Vrms は TMUX7612 の性能を 47 dB 捨てている。** ±14V では DG412 に逆転される。

### 分かったこと3: DG412 は出力側で律速される

DG412 は Rbias をいくら上げても通しで −90 dB 止まり（出力側スイッチが −93 dB で律速、
しかも振幅を下げても改善しない）。**出力を理想スイッチ（機械リレー）にすると**
入力側の真の限界が見え、Rbias 220k で −113 dB、1M で −126 dB まで伸びる。

### 手法の妥当性

- **linear と PCHIP の差は 0.1 dB 以内。** cubic spline は点間でオーバーシュートして
  偽の曲率＝偽の THD を作るので使わない
- `ΔRon/R_load` の目安は実際の THD より 11〜14 dB 悲観的だった

## `switch_offiso.py` — OFF の9chから何が漏れるか（2026-09-02）

ON のスイッチの THD だけ見ていては足りない。10ch セレクタでは**非選択9chの OFF 経路**が
別の律速になりうる。`CS(off)` の比では判断できない（あれはソース対グランド容量）。
**ソース→ドレインの貫通は OISO 規格が捉えている**ので、そこから実効直列容量を逆算する。

| | OISO @100kHz (RL=50Ω) | 逆算 C_off |
|---|---:|---:|
| TMUX7612 | −105 dB | **0.18 pF** |
| TMUX4821 | −50 dB | **100.6 pF**（562倍） |

10ch を節点方程式で解いた結果（Rbias 47k / 負荷 50k / 1 ON・9 OFF）:

| 周波数 | TMUX7612 BUS漏れ | TMUX4821 BUS漏れ | TMUX4821 の特性誤差 |
|---:|---:|---:|---:|
| 1 kHz | −126 dB | −71 dB | 0.0024 dB |
| 20 kHz | −100 dB | **−46.8 dB** | **0.040 dB** |

**漏れは信号の同相コピーなので THD にはならない**（周波数特性の誤差になる）。
非選択アンプ自身の歪みが漏れてくる分は −145 dB で無視できる。
つまり OISO の差は TMUX4821 を失格にしない。

ただし **20kHz では非選択アンプの入力に −5.9 dB も漏れる**（TMUX7612 は −59.5 dB）。
高域では10台全部が信号を増幅している。害はないが「非選択chは休んでいる」は成り立たない。

## `adg1407_ron_curve.json` — ADG1407 の実測（2026-09-02）

「入力を10 DUTへ常時ブロードキャストし、出力だけ切替える」構成の検討で、ADG1407（ADI、
dual 8:1 差動マルチプレクサ、EN付き）が2 IC で10ch分の出力選択を賄える候補として浮上した。
データシート（`AudioV2.1/datasheets/ADI_ADG1406_1407.pdf`）の **Figure 10**（VDD=+15V/VSS=−15V
固定、TA=−40/+25/+85/+125℃の4本）をベクタパスから数値抽出した（TMUX7612/DG412と同じ手法。
目視ではない）。

**⚠ 電気的特性表の「1.6 Ω typ」はこのボードの±15V電源の値ではない。** 表の条件は
`VDD=+13.5V, VSS=−13.5V, VS=±10V`（TMUX7612で踏んだのと同じ「表の電源電圧を読み違える」罠）。
Figure 10（実電源±15V固定）から読むと:

| 温度 | Ron@VS≈0 | flatness(\|VS\|≤10V) | Ron@\|VS\|≈13V |
|---|---:|---:|---:|
| −40°C | 6.32 Ω | 0.874 Ω | 8.88 Ω |
| **+25°C(typ)** | **7.79 Ω** | **1.063 Ω** | **10.55 Ω** |
| +85°C | 9.74 Ω | 1.251 Ω | 13.08 Ω |
| +125°C | 10.70 Ω | 1.477 Ω | 14.46 Ω |

+25°C カーブを `data/adg1407_ron_curve.json` として保存し、`switch_thd.py` で通しの THD を実測
（9.2Vrms、curve-based）:

| 部品 | 入力段のみ(Rbias47k) | 出力段のみ | 入出力通し |
|---|---:|---:|---:|
| **ADG1407** | −114.3 dB | −96.1 dB | **−95.1 dB**（Rbias を上げても頭打ち＝出力側律速） |
| DG412（参考） | — | −92.9 dB | −90.0 dB |
| TMUX7612（現行） | −166.2 dB | −115.2 dB | −115.2 dB |

**ADG1407 は TMUX7612 に対し約20dB劣るが、PT2314自身の歪み（0.1%≈−60dB）は余裕で下回る。**
DG412 が却下された理由（Rbias を上げても改善しない＝出力側律速）と同じ症状が出ており、
DG412 よりは5dB良いが同じ弱点を共有する。IC 2個で済むメリットとのトレードオフ。

**この抽出の未解決点:** 同じ Figure 7（±10/12/13.5/15/16.5V の5本重ね書き）から±13.5V条件の
カーブを分離して flatness を再計算すると 2.46 Ω となり、表の「1.6 Ω typ」と約1.5倍の開きがある
（5本の重なりで色の対応付けが厚みのある推定になった可能性。x軸の実データ範囲＝供給電圧に応じた
プロット幅からの推定で色を同定したが、確信度はFigure 10単独の抽出より低い）。**Figure 10 自体
（1本のグラフに温度4本のみ、混雑が少なく色分離の曖昧さが小さい）は単独では内的整合性が高い**
（4本が物理的に妥当な単調順序＝高温ほど高Ron、を示す）ので、上表はFigure 10由来の数値として
相応の信頼度で扱ってよいが、他部品より一段低い confidence として扱うこと。

## `switch_offiso.py --broadcast` — 入力ブロードキャスト構成でのBUS合成誤差（2026-09-02）

`solve()`（既存）は「入力OFF→DUT→出力OFF」の2段OFFモデルで、旧アーキテクチャ
（入出力とも切替）向け。**入力を全DUTへ常時配信し出力だけ切替える**構成では前提が違う
——非選択9chも選択chと**同じ強さの信号**を出しているので、「弱い幽霊信号の漏れ」ではなく
「ほぼ同一信号を出す9台がCoff経由でBUSに相乗りする合成誤差」になる。`solve_broadcast()`
を追加し、非選択9chに意図的なゲイン/位相ミスマッチとDUT自身のTHDを持たせる感度分析も
できるようにした（`--broadcast --gain-pct --phase-deg --dut-thd`）。

**結果: 確認した4部品（TMUX7612/TMUX4821/ADG1407/DG507B）すべてで、BUS合成誤差は無視できる。**

| | 誤差なし・20kHz | ±1%gain/±1°phase(最悪ケース)・20kHz | DUT自身THD(-94dB)漏れ・20kHz<br>RSS / coherent |
|---|---:|---:|---:|
| TMUX7612 | 0.0000 dB | −0.0000 dB | −203.7 / **−194.2** dB |
| TMUX4821 | 0.0000 dB | −0.0008 dB | −148.9 / **−139.4** dB |
| ADG1407 | 0.0000 dB | −0.0000 dB | −190.6 / **−181.1** dB |
| DG507B | 0.0000 dB | −0.0000 dB | −189.7 / **−186.2** dB |
| MAX14753 | 0.0000 dB | −0.0002 dB | −156.8 / **−147.3** dB |
| MAX14778 | 0.0000 dB | −0.0000 dB | −178.8 / **−169.3** dB |

**漏れ歪みは RSS（位相ランダム）と coherent（9ch 同相＝最悪）の両方を出す**
（`--broadcast --dut-thd`）。全 DUT は同一正弦波を受けているので同じ次数の高調波が
同相で揃う可能性があり、そのとき 9ch では RSS の √9 倍 = **+9.5dB** 悪化する。
最悪の TMUX4821 でも −139.4dB。**ただしこの1点だけで「非問題」と断定してはいけない** ——
下の「20kHz 単発で判断しない」を読むこと。

### OFF漏れを「20kHz 単発」で判断しない（#33 で再指摘、2026-09-03）

`TMUX4821` の −139.4 dB は `OPA1612`（−136 dB）と **3.4 dB しか離れていない**。
振幅比 0.68 なので同相で重なれば **合成 −131.5 dB** になり、DUT の −136 dB を数dB動かせる。

ただしこの数字は条件が混ざっている。**OFF 結合は容量性主体なので漏れは周波数に比例し、
非選択ソケットに何が刺さっているかで絶対値が変わる。**

    python3 AudioV2.1/spice/switch_offiso.py --harmonics

基本波 1kHz の THD 試験で実際に見るのは H2=2k / H3=3k / H5=5k:

| 非選択9ch | 部品 | H2=2k | H3=3k | H5=5k | 20kHz |
|---|---|---:|---:|---:|---:|
| NE5532(−94dB) | TMUX7612 | −214.2 | −210.7 | −206.2 | −194.2 |
| NE5532(−94dB) | **TMUX4821** | **−159.4** | **−155.9** | **−151.4** | **−139.4** |
| OPA1612(−136dB) | TMUX4821 | −201.4 | −197.9 | −193.4 | −181.4 |

**10石を比較する装置なので「最良の石を測っている最中に、残り9ソケットに最悪の石が
刺さっている」は現実に起きる**（表の1〜2行目がその条件）。それでも:

- **基本波 1kHz なら TMUX4821 でも H2 で −159.4 dB**、`OPA1612` の −136 dB より 23dB 下。余裕はある
- −139.4 dB が効くのは **基本波を 10kHz まで掃引して H2 が 20kHz に来たとき**だけ。
  その領域ではオペアンプ自身の THD も上がるので、−136 dB を保つ前提の方が先に崩れる
- `TMUX7612` はどの周波数でも 55dB 以上の余裕があり、この論点の影響を受けない

**用途別の結論:** PT2314 通常経路とリスニング比較では完全に無視してよい。
DIRECT 絶対 THD でも 1kHz 基本波なら余裕があるが、**高域まで掃引するなら `TMUX4821` は
再確認が要る**。なお ②の ADC 側（THD+N −102 dB）が先に効くので、実務上はそちらの実測が先。

理由は単純: `Coff` がどの部品も sub-pF〜約100pF しかなく、20kHz でもインピーダンスが
（選択ch側の `Ron+47Ω` に対して）桁違いに高い。非選択chが選択chと**同じ信号**を出している
分、漏れても「相関のある信号がわずかに位相/振幅ズレて足される」だけで、独立ノイズのように
は効かない。**この構成では OFF isolation は、ON経路の THD（`switch_thd.py` 側）ほどには
効かない**——ただし `TMUX4821` の高域だけは上記のとおり例外扱いにする。TMUX4821 だけ ±1%/±1° 感度で −0.0008dB と非ゼロだが、
これも実用上無視できる水準。

## `switch_compare.py` — 候補5部品の同条件比較（2026-09-02）

入力ブロードキャスト＋出力のみMUX構成での最終比較。条件は
**±15V電源 / ゲイン2 / 出力最大 9.2Vrms(±13Vpk) / 負荷50kΩ / Riso 47Ω / 1kHz**。

    python3 AudioV2.1/spice/switch_compare.py

| 部品 | IC数 | 確度 | 4.0Vrms | 7.07Vrms | 8.0Vrms | **9.2Vrms** |
|---|---:|---|---:|---:|---:|---:|
| TMUX7612 (4×SPST) | 5 | 実カーブ | −166.2 | −166.8 | −136.1 | **−115.2 dB** |
| ADG1407 (dual 8:1) | 2 | 実カーブ | −117.8 | −105.3 | −101.6 | **−96.1 dB** |
| DG507B (dual 8:1) | 2 | 実カーブ | −84.6 | −75.6 | −72.5 | **−70.3 dB** |
| MAX14753 (dual 4:1) | 3 | モデル | −158.1 | −148.5 | −146.4 | **−144.0 dB** |
| MAX14778 (dual 4:1) | 3 | モデル | −168.7 | −167.3 | −166.5 | **−165.3 dB** |

`|V|≤13V` での Ron(V) の広がり（これが歪みを決める。絶対Ronではない）:

| 部品 | Ron@0V | flatness |
|---|---:|---:|
| TMUX7612 | 1.11 Ω | 0.313 Ω |
| ADG1407 | 7.82 Ω | 2.758 Ω |
| DG507B | 139.8 Ω | 62.151 Ω |
| MAX14753 | 60.0 Ω | 0.013 Ω |
| MAX14778 | 0.84 Ω | 0.001 Ω |

**絶対 Ron は歪みをほとんど決めない。** MAX14753 は Ron 60Ω で TMUX7612 の44倍あるが、
**仮定モデル上では** 9.2Vrms で29dB良い（実 Ron(V) 由来の値ではない。後述の確度を参照）。
50kΩ負荷では Ron 130Ω（max）でも挿入損失は −0.031dB に過ぎない。
効くのは信号振幅にわたる Ron の変動幅だけ。

### 判定の基準線 — 3つの「床」を混ぜないこと

> **ここは3回間違えた場所**なので経緯ごと残す（すべて [issue #33](https://github.com/indare/pcb_work/issues/33)）。
> 1. 「測定床 = PCM1804 の DR 112dB」→ **DR は広帯域の雑音指標で、歪みの床ではない**
> 2. 「FFT 処理利得 30.1dB を足して −142.1dBFS」→ **処理利得が効くのはランダム雑音だけで、
>    ADC 自身の高調波（離散トーン）には効かない**。加えて実使用 N は 1024、窓は Hann
> 3. 「THD+N から SNR を引いて ADC の高調波は −102.6dB」→ **THD+N は無加重、SNR は A特性で
>    条件が揃っておらず引き算できない**。さらに「床より下だから見えない」も誤り（合成は残る）
>
> 共通する誤りは **「雑音の床」と「歪みの床」を同じものとして扱ったこと**、そして
> **「下にあれば無視できる」と考えたこと**。同じ次数の成分は複素ベクトル和で必ず残る。

**性質の違う量が3つあり、用途ごとに効くものが違う。そして「下にあれば無視できる」わけではない。**

> **⚠ ①②はどちらも「確定した測定床」ではない**（#33、2026-09-03）。
> **理想化した概算**であって、実測で置き換えるべき目安。**これを根拠に部品を落とさないこと。**

| # | 量 | 概算値 | FFT長で下がるか | 性質 |
|---|---|---:|---|---|
| ① | 理想化した bin noise floor | 約 **−137 dBFS** | **下がる** | **雑音**。白色仮定を置いた概算 |
| ② | PCM1804 の **THD+N 基準値** | typ **−102 dB** | **下がらない** | **歪み+雑音の総量**。次数別内訳は不明 |
| ③ | 前段の歪み（PT2314） | −60 dB | — | 通常経路では常にこれが支配 |

- **絶対 THD で効くのは ②側**（①は雑音なので歪みの床ではない）
- ただし ②は **THD+N のデータシート基準値**であって、**「絶対 THD の床」そのものではない**。
  **実際の高調波測定限界は、これから行う H2/H3 baseline 実測で決まる**

#### ① 理想化した bin noise floor（約 −137 dBFS）← **概算。実測で置き換える**

`DR = 112 dB`（**A特性**、`fS=48k`）に FFT の処理利得を足した**理想化値**。2点直した:

- **実使用 N は 1024**。`spectrum.py` の `MAX_N = 2048` はコメントどおり
  「起動時に確保する最大点数」で、`SpectrumAnalyzer.__init__` の既定は `n=1024`、
  `spectrum_lcd.py` も `FFT_SIZES = (1024, 2048)` / `self.ni = 0` なので既定は 1024。
  2k は明示的に切り替えたときだけ
- **窓は Hann**（`fft.py:51` `_hann`）なので ENBW ≈ 1.5 bin ぶん（1.76 dB）床が上がる

    N=1024: 10log10(512) − 10log10(1.5) = 27.09 − 1.76 = 25.33 dB → 約 −137 dBFS
    N=2048: 30.10 − 1.76 = 28.34 dB → 約 −140 dBFS

> **⚠ これは確定値ではない。** `112 dB` は **A特性の積分値**なので、
> **雑音スペクトルが白色・平坦だと仮定しない限り、ここから正確な 1 bin の floor は決まらない**。
> ΔΣ 変調器は原理的に雑音整形をしていて高域が持ち上がるので、平坦ではない。
> **実際の bin noise floor は ADC 無入力の実測で確定させること。**

#### ② PCM1804 の THD+N 基準値（typ −102 dB）← **床そのものではない**

| 条件 | THD+N |
|---|---:|
| `VIN = −0.5 dB`, `fS=48k/256fS` | **−102 dB** |
| `VIN = −0.5 dB`, `fS=96k/192k` | −101 dB |
| `VIN = −60 dB` | −47〜−49 dB（信号比。絶対では約 −107 dBFS） |

> **⚠ 「THD+N から SNR を引いて高調波分 −102.6 dB」という計算は取り下げた**（#33、2026-09-03）。
> **2つの値は測定条件が揃っていない。** データシート p.7 の脚注より:
> - **THD+N**: `fIN = 1 kHz`, Audio Precision System Two, RMS mode, **20-kHz LPF + 400-Hz HPF**（無加重）
> - **SNR / DR**: **A-weighted** と明記
>
> 加重の違う量を線形電力で引き算することはできない。**ADC 自身の H2/H3 の実値は不明。**

したがって言えるのはここまで:

- `THD+N typ ≈ −102 dB` は **TI 公式値**（この数字自体は正しい）
- **絶対 THD の測定能力はこの近辺で制約される可能性が高い**
- ただしこれは **THD+N（歪み+雑音の総量）の基準値**であって、**「絶対 THD の床」ではない**
- **実際の高調波測定限界は、ADC 直結の H2/H3 baseline 実測で決まる**

#### 「床より下だから見えない」は言い過ぎ（合成を忘れない）

ADC の高調波と切替素子由来の高調波は、**同じ次数なら複素ベクトル和**になる。
差が何dBあってもゼロにはならない。同相最悪の誤差は `20log10(1 + 10^(−margin/20))`:

| 下位成分とのマージン | 同相最悪の誤差 |
|---:|---:|
| 13 dB | +1.75 dB |
| 18 dB | +1.03 dB |
| 25 dB | +0.48 dB |
| 30 dB | +0.27 dB |
| 39 dB | +0.10 dB |

> **⚠ この式を PCM1804 と切替素子にそのまま当てはめてはいけない**（#33、2026-09-03）。
> **合成できるのは同じ次数の成分どうし**だが、比較しようとしている2つはどちらも「総量」:
> - `−102 dB` は **THD+N の総量**（次数別の内訳は不明）
> - 切替素子の `−115.2 dB` は **H2〜H9 を RSS した総 THD**
>
> **総量どうしをベクトル合成しても意味がない。** 上の表は
> **「仮に同一次数の成分がそのレベルにあれば」という一般式の例示**として読むこと。
> `PCM1804` と `TMUX7612` が実際に何dB動くかは、**ADC の実測 H2/H3 と素子の H2/H3 を
> 次数別に突き合わせるまで分からない。**

#### 切替素子側は次数別に出せる（ADC 側が未知なだけ）

`switch_thd.py` は H2 / H3 を総 THD と別に返しているので、素子側は次数別に見られる。

    python3 AudioV2.1/spice/switch_compare.py

> **⚠ 2026-09-03 に条件バグを修正**（#33）。この表を最初に出したとき
> `stage="both"` / `rbias=100k` をハードコードしており、**上の総 THD 比較表
> （`--stage` 既定 `output`、`--rbias` 既定 47k）と違う回路を計算していた**。
> 現行構成は入力ブロードキャスト＋**出力のみ MUX** なので `output` が正しい。
> 修正後は **THD(RSS) 列が上の表と完全一致**する（一致していなければ条件がずれている）。

| 部品 | Vrms | THD(RSS) | H2 | H3 |
|---|---:|---:|---:|---:|
| TMUX7612 | 4.0 | −166.2 | −166.6 | −181.1 |
| **TMUX7612** | **9.2** | **−115.2** | **−121.2** | **−119.7** |
| ADG1407 | 4.0 | −117.8 | −133.6 | −117.9 |
| **ADG1407** | **9.2** | **−96.1** | **−133.4** | **−96.3** |
| DG507B | 4.0 | −84.6 | −91.2 | −85.9 |
| DG507B | 9.2 | −70.3 | −73.1 | −77.4 |

**総 THD で比べると像が変わる部品がある:**

- **`ADG1407` は H3 支配。** 9.2Vrms で **H2 −133.4 / H3 −96.3 と 37 dB も違う**。
  総 THD（−96.1）だけ見ていると、この偏りが完全に隠れる。
  H2 は `TMUX7612` @9.2Vrms（−121.2）より 12 dB も**良い**
- `TMUX7612` @9.2Vrms は総 THD −115.2 だが、**個々の次数は −121.2 / −119.7 で
  総量より 4〜6 dB 低い**。「ADC の −102 dB と 13 dB 差」という比較は
  総量どうしの比較で、次数別ではない
- `DG507B` は逆に H2 支配（9.2Vrms で H2 −73.1 / H3 −77.4）
- `MAX14753`/`MAX14778` の H2 が両振幅で同値（−169.1 dB）なのは**数値床**。
  モデルが左右対称パラボラなので偶数次が原理的に出ない。**実チップの値ではない**

#### 経路歪みリスクの一次スクリーニング（ADC 非依存）

> **⚠ 「②より上だから確実に測定を汚す」は撤回した**（#33）。①②を確定床ではないと書いた
> 直後に②を確定床として部品を落としており、自己矛盾だった。
> 代わりに **ADC を経由しない基準**を使う —— スイッチ自身の H2/H3 を DUT の THD と比べる。
>
> **ただしこれも「判定」ではなく「スクリーニング」。条件が揃っていない**（#33、2度目の指摘）:
> - **switch 側** = この計算の実条件（`G=2` / `Vout 4.0・9.2 Vrms` / `RL 50k` / ±15V）
> - **DUT 側** = データシート値。**DUT どうしですら条件が揃っていない**（下表）
> - さらに switch は **H2/H3 の最大次数**、DUT は **THD+N の総量**（内訳不明）
>
> **保守的なふるい分けには使えるが、「その石は測れない」の証明にはならない。**

**DUT 側の条件（`AudioV2.1/datasheets/opamps/` で確認済み）:**

| DUT | 値 | 条件 | 出典 |
|---|---:|---|---|
| OPA1612 | −136.0 dB | `G=+1, f=1kHz, VO=3Vrms` | `TI_OPA1612.pdf` p.5 |
| LME49860 | −130.5 dB | `AV=1, f=1kHz, VOUT=3Vrms, RL=2k` | `TI_LME49860.pdf` p.3 |
| MUSES02 | −100.0 dB | **`AV=+10`**, `f=1kHz`, **`Vo=5Vrms`**, `RL=2k` | `NJR_MUSES02.pdf` p.3 |
| NE5532 | −94.0 dB | **★TI DS に THD 規定なし。通説値で出典不明** | — |

**`MUSES02` だけゲインも振幅も違い、`NE5532` に至っては規定自体が無い。**
`RL=2k` はこちらの `50k` より重い（＝ DS 値は悲観側）ので、実回路の DUT は
これより良い可能性があり、**その場合スイッチが支配的になる方向**に効く。

#### 振幅を揃えて比べ直した（`extract_dut_thd.py`、2026-09-03）

条件不一致のうち**一番効いていた振幅軸**は、データシートのカーブを抽出すれば揃えられる。
`OPA1612` p.1「THD+N Ratio vs Output Amplitude」を Ron 曲線と同じベクタ抽出で数値化した。

    python3 AudioV2.1/spice/extract_dut_thd.py

**校正の検証:** 抽出カーブの `G=+1, RL=2k` @3.0Vrms は **−138.4 dB**。
データシート実表の規定値（`G=+1, f=1kHz, VO=3Vrms`）は **−136 dB**。2.4 dB 差で妥当。
軸校正は左軸の % 目盛（0.01% = −80dB）とも一致する。

| 条件 | 3.0V | 4.0V | 9.2V | クリップ開始 |
|---|---:|---:|---:|---|
| G=−1, RL=2k | −136.9 | −139.4 | **−145.3** | 9.59〜10.28 Vrms |
| G=+10, RL=2k | −137.2 | −139.5 | −144.3 | 9.95〜10.62 Vrms |
| G=+1, RL=2k | −138.4 | −140.6 | **クリップ** | 8.94〜9.59 Vrms |

> **⚠ クリップ点をまたいで内挿しないこと。** 曲線の末端は出力が電源に当たって
> THD が数十dB跳ね上がる。**実際にやらかした** —— 9.2Vrms を 8.94V/−141.3 と
> 9.59V/−99.8 の間で内挿して **「−124.8 dB」という存在しない値**を作った。
>
> **代理カーブに `G=−1, RL=2k` を使う理由**（#33 で補強された）:
> - **`G=−1` のノイズゲインは 2 で、非反転 `G=+2` のノイズゲインと一致する**
> - `G=+1` が早くクリップするのは**非反転バッファの入力同相電圧の制限**。
>   `OPA1612` の同相入力範囲は電源レールから 2V 内側＝±15V なら約 ±13V。
>   **`G=+2` で 9.2Vrms 出力なら +入力は約 6.5 Vpk しか振れない**ので余裕がある

**振幅を揃えて掃引した結果:**

| Vrms | Vpk | switch 最大次数 | OPA1612 THD+N | 差 |
|---:|---:|---:|---:|---:|
| 4.00 | 5.66 | −166.6 | −139.4 | −27.2 |
| 5.00 | 7.07 | −166.8 | −141.1 | −25.7 |
| 7.00 | 9.90 | −167.2 | −143.4 | −23.8 |
| 7.50 | 10.60 | −167.1 | −144.0 | −23.1 |
| **7.78** | **11.00** | **−150.5** | −144.4 | **−6.1** |
| **7.90** | **11.17** | **−144.9** | −144.5 | **−0.4 ← 交差** |
| 8.00 | 11.31 | −141.4 | −144.5 | **+3.1** |
| 9.20 | 13.01 | −119.7 | −145.3 | **+25.6** |

**交差点 7.9 Vrms は `Ron` 平坦領域の膝（±11V = 7.78 Vrms）とほぼ一致する。**
膝を越えた瞬間にスイッチが DUT を上回る。独立に出した2つの数字が一致したので、
**「膝より下で使う」は数値でも裏付いた。**

**データシートの規定点（−136 dB）で比べると 9.2V の問題を過小評価する。**
THD+N は*比*なので振幅が上がるほど（雑音支配から外れて）良くなり、
9.2Vrms の `OPA1612` は規定点より 9 dB 良い。
**つまり振幅を揃えると、スイッチの相対的な悪さは 16 dB → 26 dB へ拡大する。**

> **⚠ `OPA1612` の値は typical グラフのベクタ抽出**なので、**小数点1桁の絶対値として
> 扱わないこと**。9.2Vrms なら **「概ね −144〜−146 dB 級」**が適切な言い方。
> ただし差が 25 dB あるので、抽出誤差 2〜3 dB では結論は逆転しない
> （3Vrms での校正差が 2.4 dB）。

**この掃引から経路ごとの振幅上限が決まる**（v2 の決定ログ §11.1a。v2.1 での扱いは [DECISIONS.md](../DECISIONS.md) §1-5）:
**通常 4〜5 Vrms / 精密 DIRECT 約 7 Vrms（10 Vpk）/ フルレンジ 9.2 Vrms はリレー等**。
**`TMUX7612` を「4〜5 Vrms まで」に縛る必要はない。**

> **⚠ 7 Vrms の根拠を「`OPA1612` より 23.8 dB 下だから」に置かないこと。**
> その差は設計保証値にならない —— DUT 側は `G=−1, RL=2k` の THD+N、実回路は
> `G=+2, RL≈50k`、switch 側は H2/H3 の個別次数。**`50k` の軽い負荷なら実 `OPA1612` は
> `2k` 時より良くなる可能性が高く、差は縮む方向。**
>
> **直接の根拠はスイッチ単独で完結させる: 7 Vrms = 9.90 Vpk は膝（±11V）の明確に内側で、
> その領域ではスイッチ自身の歪みが約 −167 dB 級（絶対値）。**
> こうしておけば `OPA1612` の 50kΩ 実測がどれだけ良くても設計判断は崩れない。
>
> **交差点 7.9 Vrms は物理モデルの検証用**（膝 7.78 Vrms と独立に一致したことが
> 「膝を外れると急に悪化する」の裏付けになる）。**設計上限の根拠ではない。**

**残る不一致:** switch は H2/H3 の個別次数 / DUT は THD+N 総量、
負荷 DS 2k vs 実回路 50k、ゲイン DS −1 vs 実回路 +2。
`LME49860` p.5 と `MUSES02` p.5 にも同種のカーブがあるが未抽出。

    python3 AudioV2.1/spice/switch_compare.py

| 部品 | Vrms | 最大次数 | NE5532 −94 | MUSES02 −100 | LME49860 −130.5 | OPA1612 −136 |
|---|---:|---:|---:|---:|---:|---:|
| TMUX7612 | 4.0 | −166.6 | −72.6 | −66.6 | −36.1 | −30.6 |
| TMUX7612 | 9.2 | −119.7 | −25.7 | −19.7 | **要注意** | **要注意** |
| ADG1407 | 4.0 | −117.9 | −23.9 | −17.9 | **要注意** | **要注意** |
| **ADG1407** | **9.2** | **−96.3** | −2.3 | **要注意** | **要注意** | **要注意** |
| **DG507B** | **4.0** | **−85.9** | **要注意** | **要注意** | **要注意** | **要注意** |
| **DG507B** | **9.2** | **−73.1** | **要注意** | **要注意** | **要注意** | **要注意** |

「要注意」＝ switch の高調波成分が DUT の公称総量を上回る。**「測れない」ではない。**

- **`DG507B` は 4Vrms でも全 DUT で要注意。差が大きく条件差では覆らないので不適**
  （ADC を持ち出すまでもない）
- **`ADG1407` @9.2Vrms は H3≈−96dB。** 低歪比較系には高リスク。
  落とすなら「②より上だから」ではなく**「素子自身が H3 −96dB を出すから」**
- **⚠ `TMUX7612` も 9.2Vrms では H3 が −119.7 dB まで悪化する**（4Vrms は −166.6 dB）。
  **「9.2V では `OPA1612` を絶対測れない」とまでは言えない**（条件不一致）が、
  **46 dB の悪化は低歪比較系にとって余計な変数**。
  **「膝（±11V）より下で使う」の設計理由としては、これで十分強い**

厳密な可否は**同一条件の DUT 特性 or ADC baseline 実測**後に確定する。

#### ⚠ 繰り返している失敗パターン: 「条件を揃えずに数値を比べる」

**この議論だけで3回やっている。**（すべて [issue #33](https://github.com/indare/pcb_work/issues/33) で指摘された）

| # | やったこと | なぜ駄目か |
|---|---|---|
| 1 | `THD+N`(無加重) − `SNR`(A特性) | **加重が違う量**は引き算できない |
| 2 | 総THD表は `a.stage`、次数別表は `"both"` 固定 | **同じスクリプト内で違う回路**を計算 |
| 3 | switch(G2/9.2Vrms/50k) vs DUT(DS の G1/3Vrms/2k) | **測定条件が違う量**を直接比較 |

**数値を並べる前に、必ず「この2つは同じ条件で測られたものか」を確認すること。**
データシートから数字を拾うときは、**値だけでなく脚注の条件も一緒に写す。**
（1 は同じデータシートの同じページに条件が書いてあったのに読まなかった）

#### 「相対比較は成立する」も条件付き

「ADC の歪みは全 DUT に共通に乗るからキャンセルする」は**単純には成り立たない**。
観測される H2 は `H2_ADC + H2_DUT` の**複素ベクトル和**で、DUT ごとに振幅も位相も違うので、
ADC の −102 dB に対してわずかに足したり引いたりする（−136 dB の DUT なら最大 ±0.17 dB）。

| 用途 | 可否 |
|---|---|
| 大きな THD 差の相対比較 | **十分可能** |
| −90〜−100 dB 級 と −130 dB 級 の区別 | 条件次第 |
| −130 dB vs −136 dB の絶対比較 | **そのままではかなり難しい** |
| baseline を**複素振幅**で測って差分を取る | 可能性あり |

**正確な言い方は「相対比較は成立」ではなく
「ADC の再現性と baseline 除去精度の範囲で相対比較可能」。**

#### ⚠ ②は実測で確定させること ← **ここが今の最大の未決事項**

`−102 dB` は **THD+N の typ 値**で、条件は `VIN = −0.5 dB` の1点。雑音込みなので
**ADC 自身の H2/H3 の実値ではない**し、実機では入力バッファ・基準電圧・レイアウトでも変わる。

**必要なのは SPICE ではなく実測。** 手順:

1. **ADC 直結 baseline** — 基準信号を直接 ADC へ入れ、H2/H3 の**振幅と位相**を測る
2. **同レベルで繰り返し測定** — 再現性（振幅・位相のばらつき）を見る
3. その再現性が、**「どこまでの THD 差を比較できるか」の実用的な限界**になる
4. できればレベルスイープも取る（②は `VIN` 依存。`VIN=−60dB` では絶対値が約 −107 dBFS）

**この実測が済むまで、②を根拠に部品を落とさないこと。**

### データ確度の違い（重要）

- **実カーブ**（TMUX7612 / DG412 / ADG1407 / DG507B）: データシートの Ron vs 信号電圧
  グラフをベクタパスから数値抽出。
- **モデル**（MAX14753 / MAX14778）: flatness スペックを満たす対称パラボラの仮定形状。
  MAX14753 はグラフのy軸分解能（0.0816Ω/px）が 0.03Ω の flatness を解像できず、
  MAX14778 は Ron(V) グラフ自体が存在しない。**実チップにキンクや非対称があれば外れる。**

### 手法の妥当性検証（DG507B で取れた）

DG507B のデータシートは THD **0.04% @ RL=10kΩ, 5Vrms** を公称している。
抽出カーブによる計算は 4.0Vrms/50kΩ で −84.6dB。負荷を 10k→50k にすると +14dB
効くので、公称値 −68dB は 50kΩ換算で約 −82dB に相当し、**振幅差を考えれば一致する**。
メーカー実測値と抽出＋シミュレーションが合った初めての例で、手法の裏付けになる。

## `max14753` / `max14778` の Ron(V) について（2026-09-02）

**MAX14753**: p.10「ON-RESISTANCE vs. VOUT (DUAL SUPPLIES)」はモノクロで線種違い。
色分離できないので、各水平ダッシュ群の x 範囲（=その電源条件でプロットされている
信号範囲）で同定した。

| 電源 | Ron | プロット範囲 |
|---|---:|---|
| ±35V | 55.00 Ω | −35.0 .. +34.7 V |
| ±30V | 54.91 Ω | −30.0 .. +29.7 V |
| ±20V | 54.60 Ω | −20.1 .. +19.8 V |
| ±10V | 54.40 Ω | −10.1 .. +9.8 V |

**4本とも完全にフラットで、±10V電源でもレールぎりぎりまでフラット。**
これが TMUX7612（±15V電源で±11Vから膝）との決定的な差。
なお表の flatness 0.03Ω の測定条件は **±35V電源/±20V信号**（レールまで15Vの余裕）で、
うちの ±15V/±13V ではない。グラフが「±10V電源でもレールまでフラット」を示しているので
外挿してよい、という理屈で使っている。

**MAX14778**: Ron(V) グラフが存在しない。THD+N の公称 0.003% も
**振幅条件がテーブルにもグラフにも書かれていない**（`RS=RL=1kΩ, f=20Hz to 20kHz` のみ）
ため 9.2Vrms 条件との直接比較には使えない。flatness 3mΩ（−25V≤VIN≤+25V 全域、
ICOM=−300mA）だけが手がかり。

## MAX14778 の charge-pump スプリアスと ADC エイリアス（2026-09-02）

MAX14778 は内部に3つのチャージポンプを持つ。p.9「CHARGE PUMP NOISE — SWITCH ENABLED」
（MEASURED AT BCOM, RBW=5.1kHz）をベクタ抽出したピーク:

| 周波数 | レベル |
|---:|---:|
| 35 MHz | **−74.6 dB** |
| 71 MHz | **−76.4 dB** |
| （フロア） | −101 dB |

AudioV2 の計測系は `PCM1804`、**48kHz / 256fs（SCKI=12.288MHz）マスタ**。
前段のアンチエイリアスは `R709-712 (1kΩ) + C713-716 (1.8nF C0G)` の**1次RC、fc≈88kHz**。
1次なので 35MHz で約 52dB、71MHz で約 58dB の減衰。
スプリアス −75dB を仮に dBV とすると 178µV、RC 後で約 0.45µV。
PCM1804 は FS ±2.5V・DR 約112dB なので自身の雑音フロアが約 8.9µV あり、
**最悪（帯域内へ丸ごと折り返した場合）でも ADC 雑音フロアより約26dB下**。

エイリアス先も、12.288MHz でも 64fs=3.072MHz でも 35/71MHz は整数倍から外れている。

**結論: 一次見積では問題なさそう。ただし実測必須。** 以下3点が未確定なので、
この計算を「ブロッカーではない」の根拠にしてはいけない。

1. **グラフの dB 基準が明示されていない。** 上の 178µV は dBV 仮定。dBm/50Ω なら別値
2. **35/71MHz が信号ピンからだけ来るとは限らない。** 内部チャージポンプなので
   電源・GND 経由の結合もありうる。その経路は入力側の 1次RC では落ちない
3. **エイリアスは「クロックの整数倍から外れている」だけでは保証できない。**
   ΔΣ変調器の実効サンプリングと折り返しは単純な整数倍判定では決まらず、
   スプリアスの実周波数も ±数MHz の幅がある

## `input_topology.py` — 入力側 A / B / C 案（2026-09-02）

入力ブロードキャスト化にあたり、バイアスの持たせ方3案を比較した。

    A案: PT2314 ─┬─[C]─┬─Rb(100k)─GND        （×10）
    B案: PT2314 ─[C]─┬─Rb_c(10k)─GND ├─[Rs]─ DUT （×10）
    C案: PT2314 ─[共通バッファ]─┬─[C]─┬─Rb(10〜22k)─GND （×10）

PT2314 の特性規定は RL=10kΩ なので、直結する A/B 案は「10本並列で 10kΩ 以上」の
制約を受ける（A案 Rb=100k、B案 Rb_c=10k）。C案はバッファが受けるので Rb を小さくできる。

> **⚠ 2026-09-07: `PT2314E` に確定して前提が緩んだ。** 完全版 DS
> （[`../datasheets/Princeton_PT2314E.pdf`](../datasheets/Princeton_PT2314E.pdf) p.12）は
> **`RL` 最小を 5 kΩ** と規定している（`OUT_L`/`OUT_R`。`LOUT`/`ROUT` も Vo=2 Vrms で 5 kΩ）。
> この設計が使うのは `OUT_L`/`OUT_R` なので、**A案の 10ch 並列 10.0 kΩ は下限の2倍**になる。
> 「10 kΩ が下限で余裕ゼロ」という評価は E では過剰。上の 10kΩ は**特性を測った条件**であって
> 動作の下限ではなかった、という読みが正しい。**`Rb` 100k 据え置きでよく、ch を増やす余地もある。**

**交流と直流で効き方が違うのが要点。** 結合Cが直流を切るので、DC 経路は Rb だけ
＝オフセットは Rb に比例する。一方 AC では結合Cが短絡なので、雑音は前段の出力抵抗
（PT2314 typ **1.9Ω**）が支配し、Rb にほとんど依存しない。

| | A案 Rb=100k | B案 Rb_c=10k | C案 Rb=22k | C案 Rb=10k |
|---|---:|---:|---:|---:|
| 前段が見る負荷 | 10.0 k | 10.0 k | 2.2 k | 1.0 k |
| 必要な結合C（-3dB 2Hz） | **0.80 µF** | 7.96 µF | 3.62 µF | 7.96 µF |
| フィルム化 | **現実的** | 非現実的 | やや大きい | 非現実的 |
| 雑音 @1kHz [nV/√Hz] | 0.195 | 1.295 | 0.056 | 0.048 |
| 雑音 @20Hz | 4.040 | 1.818 | 1.894 | 1.277 |
| Ib×Rb（LT1364 typ/max） | 60 / **200** mV | 6 / 20 mV | 13 / 44 mV | 6 / 20 mV |
| Ib×Rb（NE5532 typ/max） | 20 / 80 mV | 2 / 8 mV | 4.4 / 17.6 mV | 2 / 8 mV |
| 結合C漏れ×Rb（電解上限） | 300 mV | 30 mV | 66 mV | 30 mV |
| 結合C漏れ×Rb（**フィルム**） | **0.036 mV** | — | — | — |
| 部品 | C×10+R×10 = 20 | C×1+R×1+Rs×10 = 12 | buf+C×10+R×10 | 同左 |
| ch 独立性 | 独立 | **全ch連動** | 独立 | 独立 |

### 電解コンデンサの漏れ電流について

PT2314 の出力は直流 4.5V（データシート `DC Voltage Level` typ）なので結合Cには
直流がかかる。アルミ電解の漏れ電流スペックは一般に `0.01·C·V または 3µA の大きい方`
で、**A案の 100k と組むと最大 300mV** になる。これは Ib×Rb より大きい。

**ただし A案は Rb が大きいぶん必要な結合容量が 0.80µF まで下がり、フィルムが使える。**
フィルムの絶縁抵抗（10,000MΩ·µF 級）なら漏れは 0.036mV で消える。
逆に C案は Rb が小さいので必要容量が 3.6〜8µF になり、フィルムは非現実的＝電解確定。
**「電解の漏れ」は A案の弱点ではなく、A案でだけ回避できる。**

### 20Hz で A案の雑音が上がる理由

0.80µF は 20Hz で 9.9kΩ あり、Rb=100k との並列の実部が 982Ω になるため
4.04nV/√Hz まで上がる（1kHz 以上では 0.2nV/√Hz 未満）。オペアンプ自身の
雑音（2〜8nV/√Hz）と同程度なので実用上は問題ないが、C案より不利な唯一の帯域。

### 判断

- **A案 + 1µF フィルム結合C** — 1kHz 以上の雑音・漏れ電流とも最小、ch 独立、
  前段の追加なし。残る代償は Ib×100k の直流オフセット（LT1364 max 200mV）だが、
  出力は 47Ω+2.2µF で AC 結合されるので後段には出ず、ヘッドルームにも影響しない
- **B案** — 共通ノードの直流が「刺さっている全10石の Ib の和」で決まり、
  1石差し替えると全chが動く。比較装置としては筋が悪い
- **C案** — Ib の影響を 1/5〜1/10 にでき、現行の Rb=1k に近い条件で比較できる点は
  A案より優れる。代償は (a) バッファ自身の歪み・雑音が全DUTの前に入る
  (b) 電解C確定 (c) 部品と電源が増える。
  **(a) は全chに共通なので「比較」には効かないが、DIRECT 経路で「オペアンプ単体の
  絶対THD」を測る用途では新しい床になる**（在庫最良の OPA1612 が −136dB なので、
  バッファもそれ以上でなければ意味がない）。その用途を残すならDIRECTはバッファも迂回が要る

**LT1364 級の 200mV を許容できるなら A案 + フィルム。許容できないなら C案。**
この判断は「Ib×Rb の直流オフセットを、比較条件の乱れとしてどこまで嫌うか」に尽きる。

## 前提と限界

- オペアンプは理想（電圧源）で置いている。GBW・スルーレート・出力インピーダンスは見ていない
- スイッチは ngspice の `SW` モデルに `Ron` と漏れ電流を与えただけ。
  チャージインジェクションと寄生容量は入っていない
- **切替時のクリック音そのもの**（チャージインジェクション由来）は別問題で、
  ここでは扱っていない。TMUX7612 の 2 pC は ADG1412 の 1/10

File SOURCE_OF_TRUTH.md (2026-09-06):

# source of truth — 何をどこに書くか

このリポジトリには「同じことが2箇所に書いてある」ことによる事故が繰り返し起きている。
その予防のための方針。**エージェント（Claude / Cursor）も人間もこれに従う。**

関連: シートごとの「生成スクリプト vs KiCad」の所有権と再生成の順は
[CLAUDE.md](CLAUDE.md) が正。ここでは重複させない。
そう決めた理由と移行期の記録は [AudioV2/AGENT_HANDOFF.md §2.8](AudioV2/AGENT_HANDOFF.md)。
**いま何待ちか・次の一手**は [AudioV2/NOW.md](AudioV2/NOW.md) が正（HANDOFF の現況節より優先）。

---

## 1. 判断ロジック（これ1問）

> **その情報は回路図から機械的に導出できるか？**

| | 正 | 具体例 |
|---|---|---|
| **導出できる** | **KiCad の回路図** | ネットリスト、参照(designator)、ピン接続、部品数、部品値 |
| **導出できない** | **ドキュメント** | 決定と理由、却下した代替案、外部世界（パネル配置・現物端子・箱配線）、意図・制約・未確定事項 |

導出できる情報をドキュメントに書き写した時点で、それは**必ず腐る負債**になる。書くなら生成する。

---

## 2. なぜこの方針なのか（2026-09-01 の実例）

KiCad で再アノテーションした結果、58件の参照が振り直された。そのとき壊れたもの:

- `PARTS.md` の「R705–708 = 20 kΩ」→ 振り直しで連番でなくなり**嘘になった**
- `AGENT_HANDOFF.md` の「I2Cプルアップは `R210`/`R211`」→ 実物は `R501`/`R502`
- `wire_circuit_design.py` が旧参照をハードコードしており、**再生成するとアノテーションが巻き戻る**状態だった

いずれも「回路図から導出できる事実を手書きしていた」ことが原因。

---

## 3. 語彙のルール — designator でなくネット名で書く

同じアノテーションで、**動いたもの／動かなかったもの**がはっきり分かれた。

| | 例 | 2026-09-01 の再アノテーションで |
|---|---|---|
| **designator** | `U301`, `R210`, `C205`, `SW1`, `RV101` | **58件が変わった** |
| **ネット名 / 機能名** | `CH1_SET`, `I2C_SDA`, `TONE_L`, `AMP_SEL_L` | **1件も変わらなかった** |

designator は **KiCad が採番する割り当ての産物**で、再アノテーションで動く。
ネット名は**設計者が決めた意図**なので動かない。だからドキュメントはネット名で書く。

```
❌ 「I2Cプルアップは R210/R211 の 4.7 kΩ」
⭕️ 「I2Cプルアップは ControlPanel 側にのみ置く（並列化を避けるため RelayBoard には置かない）」
```

後者は designator を含まないのに情報量が落ちておらず、しかも**なぜそうするか**という
導出不能な情報（＝ドキュメントが本来担うべきもの）まで書けている。

### 適用状況（2026-09-01 時点）

この語彙ルールを**適用済み**なのは `AudioV2/AGENT_HANDOFF.md` と `AudioV2/WIRING.md` の2本だけ。
`AudioV2/CIRCUIT_DESIGN.md` と `AudioV2/DECISIONS.md` は**まだ旧記法（designator 直書き）**が残っている。
どちらが現行か迷ったら、この節が正。未適用の文書を読むときは designator が古い可能性を疑うこと。

---

## 4. それでも designator が要る場所

BOM・発注・パネルの現物対応表は designator が本質的に必要。
ここは**手書きせず回路図から生成する**。

```bash
docker/kicad-cloud-build/kicad-run.sh cli sch export bom -o @OUT@/bom.csv @WORK@/AudioV2/AudioV2Case.kicad_sch
```

`PARTS.md` の AmpModule 部品表は 2026-09-01 にこの方式へ移行済み（`AudioV2/scripts/gen_parts_bom.py`、マーカー囲みブロック）。他に手書きで残っている導出可能な表があれば、同じように生成へ寄せる。

---

## 5. 実務チェックリスト

ドキュメントに1行足すとき:

1. これは回路図を見れば分かることか？ → **Yes なら書かない**
2. 書く必要があるなら、designator でなくネット名・機能名で書けないか？
3. designator を書くしかないなら、それは BOM 系か？ → **生成に寄せる**
4. どれでもない（＝決定理由・外部世界・意図）→ **ドキュメントが正。しっかり書く**

回路図を変えたとき:

- 参照が変わる操作（再アノテーション等）をしたら、`wire_circuit_design.py` と
  `*.md` の追随が必要か確認する。**追随が必要になった時点で、それは 1. 違反のサイン**
- 検証は `docker/kicad-cloud-build/kicad-run.sh erc` / `netlist`

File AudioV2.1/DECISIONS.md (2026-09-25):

# AudioV2.1 決定ログ（DECISIONS）

> **これは v2.1 自身の決定ログ（2026-09-25 から）。** v2 から引き継いだ決定は §7 に v2.1 の項目（`V21-継-nn`）として書き直してある。v2 の決定ログは読まない。
> このファイルは、v2 の全コピーのときにできた v2 の決定ログの写し（バイト一致）を置き換えたもの。

- 2026-09-25: エージェントの下書き（[review/DECISIONS_v21_draft.md](review/DECISIONS_v21_draft.md)）に、否定側査読（[review/DECISIONS_v21_review.md](review/DECISIONS_v21_review.md)）とユーザーの回答を反映して置いた
- 現況（いま何待ちか・次の一手）の正は [NOW.md](NOW.md)。この文書は「何を決めたか・なぜか・何を捨てたか」だけを持つ
- 回路図から導出できる事実（ネットリスト・参照・部品数・部品値）は書かない（[../SOURCE_OF_TRUTH.md](../SOURCE_OF_TRUTH.md)）。部品は機能名かネット名で書く。**選定として決めた型番**（RS6-1215D など）と、決定を支える DS の数値は書き、出典を付ける
- v2 から引き継いだものは §7、v2.1 では成り立たない v2 の決定と訂正された記録の表は [review/v2_carryover.md](review/v2_carryover.md)。本文で「v2 の『…』」と書くのは v2 でそう決めていたことの呼び名で、v2 の本文は引かない
- **`[NOW] Lnn` はコミット `a63caac` の NOW.md の行番号**（`git show a63caac:AudioV2.1/NOW.md`）。この文書を置いたときに NOW の「v2.1 で決まったこと」を短い要旨へ差し替えたので、今の NOW.md とは行が合わない

---

## 0. v2.1 とは

### 0-1 目的

オペアンプを電子的に切り替えて、音の差を耳で楽しむ箱。**計測器ではない。** 切替素子の優劣も耳で決める（[NOW.md](NOW.md)「装置」）。
計測系（ADC・スペアナ）は表示と簡易分析のためにあり、**本線（聴く経路）を汚さないことが計測の精度より優先**する（§4-2）。

### 0-2 v2 との関係

- v2.1 は 2026-09-25 に v2 の図・スクリプトを**全部写して**始めた（[NOW.md](NOW.md) 冒頭）
- 目的は「選んだ ch だけ電源と入力を生かす」構成の検討。v2 は「全ソケット常時通電・入力はブロードキャスト」だった
- v2 の決定のうち、v2.1 でもそのまま効くものは §7、成り立たなくなったものは [review/v2_carryover.md](review/v2_carryover.md) に表で置いた（棚卸し: [review/decisions_audit_1.md](review/decisions_audit_1.md)・[_2](review/decisions_audit_2.md)・[_3](review/decisions_audit_3.md) とそれぞれの `_review`。**査読が監査を直したところは査読を採った**）

### 0-3 読み方

各項目は次の形で書く。

| 欄 | 中身 |
|---|---|
| **決定** | 1〜3 行 |
| **理由** | いちばん強い理由 1 つ |
| **根拠** | `ds_facts/`・`review/`・`spice/`・`scripts/`・DS へのリンク |
| **前提・外れる条件** | これが崩れたら見直す |
| **却下した案** | 1 案 1 行、理由とリンク |
| **状態** | 下の表のどれか。1 項目に複数あるときは箇条に割る |

| 状態 | 意味 |
|---|---|
| **決定** | ユーザーが決めた。条件つきのものは条件を書く |
| **いったんの決め** | 推奨をユーザーが受けた（「よい」「おすすめで」「良さそう」）もの、査読で出た値を仮に採ったもの |
| **未決（推奨）** | 推奨はあるが、ユーザーは決めていない |
| **未決** | 推奨もまだ無い |
| **要実測** | 実測の結果で決める |
| **v2 の却下を引き継ぐ** | v2 で却下され、v2.1 で個別の判断はしていない |
| **v2 から引き継ぎ（v2.1 で再考していない）** | v2 で決め、v2.1 の前提で見直さずに持っている（§7） |
| **DS の制約** | DS が求めること。判断ではない |

略記: [NOW] = 上の注のとおり（コミット `a63caac` の [NOW.md](NOW.md)）、[pow] = [ds_facts/power.md](ds_facts/power.md)、[sw] = [ds_facts/switch_control.md](ds_facts/switch_control.md)、[op] = [ds_facts/opamps.md](ds_facts/opamps.md)、[tap] = [ds_facts/tap.md](ds_facts/tap.md)、[bnd] = [ds_facts/boundary.md](ds_facts/boundary.md)（照合 [verify_boundary.md](ds_facts/verify_boundary.md)）。`ds_facts/relay4.md` は**未照合**なので根拠に使っていない。
§10 の未決・実測は `V21-未決-nn`・`V21-実測-nn` で呼ぶ（他の査読ファイルの記号と衝突させないため）。

---

## 1. 設計の根本

### 1-1 コールドスタンバイ — 電源要求の違う回路を切り替える

- **決定**: 解く問題を「電源要求の違う回路を同じバスへ切り替えること」と置く。非選択の回路は**電源ごと落とし**、バスとの境目には「電源が無いときにも切れている素子」を置く（コールドスタンバイ）。回路ごとに自分の電源（LDO で電圧を選ぶ）を持たせて同じバスに混ぜる
- **理由**: v2 の形では、非選択の回路が境目の素子（TMUX7612）を生かすために通電していた（ホットスタンバイ）。TMUX7612 の DS には**電源を切ったときの漏れ・高インピーダンスの規定が無く**、端子はレールへダイオードでクランプされている
- **根拠**: [NOW] L22「設計の根本」／[bnd] §1.1（TMUX7612: 電源断時の規定なし、"Pins are diode-clamped to the power-supply rails."、電源シーケンスは任意）。[NOW] L22 は「議論中」と書いているが、境目の素子（ラッチングリレー）と 1 枚の ch 数（4）は L24 で決まった
- **前提・外れる条件**: 境目の素子が電源断でも切れていること（§2-1 のラッチングリレー）。境目の外（親）の PT2314E と計測系は常時通電。TMUX7612 は娘の上で電源リレーの後ろにあり、**選んだ娘の中では ch の EN で切らずに通電したまま**、選んでいない娘では電源ごと落ち、境目のリレーでバスから切られる
- **却下した案**: v2 の「全 ch 常時通電・入力ブロードキャスト」— 選んだ ch だけを生かす目的と逆
- **状態**: 決定（ユーザー判断 2026-09-25）

### 1-2 同時に生かすのは厳密に 1 ch

- **決定**: 電源と入力を生かすのは**選んだ 1 ch だけ**。ファームは全 OFF → 1 ch ON。温めておく ch は作らない。ハードは ch ごとに独立して切れる。ヘッドホンは 32 Ω を想定
- **理由**: 主電源（RS6-1215D、±200 mA）の予算がこの前提で成り立つ（§3-1）。温めておく ch を許すと、同時に通電できる数が DC-DC の型番で決まってしまう（最悪の石で 5 ch、80 % で使うなら 3 ch という見積もりがあった）
- **根拠**: [NOW] L9／[review/rejected_review.md](review/rejected_review.md) #5・[rejected_review_review.md](review/rejected_review_review.md) #5（温める数の見積もりと訂正）
- **前提・外れる条件**: 石の熱の整定（通電してから音が落ち着くまで）が許せる長さであること。v2 の反対理由「今つけた石と、ずっとついていた石を比べる」はハードでは解けず、切り替えてから聴くまでの待ち時間の問題として残る（[rejected_review_review.md](review/rejected_review_review.md) §6 U2、V21-実測-09）
- **却下した案**: 「最低 1 ch、温める数はファームが決める」— 同上（DC-DC の余裕を食う）
- **状態**: 決定（ユーザー判断 2026-09-25）

### 1-3 制御の木は 2 段

- **決定**: 1 段目＝**基板（娘）1 枚だけ ON**、2 段目＝**その基板の中で 1 ch だけ**。どちらも「全リセット → 1 つだけセット」のブレーク・ビフォア・メイク
- **理由**: 選んだ 1 ch だけ給電する形なら、1 段目の故障（別の基板にも電源が入る）でも ch の EN が 2 つ目の関門になる（[review/dcdc_2stage_review.md](review/dcdc_2stage_review.md) 要約 3）。逆に基板をまたぐ排他が無いと、娘 4 枚が 1 ch ずつ ON の最悪で RS6 の +15 V が定格の 110 % になり、過負荷保護（150 %）は働かない
- **根拠**: [NOW] L24／[review/bulk_parent_sim.md](review/bulk_parent_sim.md) §0.3（4 枚 110 %、2 枚以下なら 89 %）／[review/dcdc_2stage.md](review/dcdc_2stage.md)・[_review](review/dcdc_2stage_review.md)
- **前提・外れる条件**: 1 段目・2 段目の中身は §2
- **却下した案**: 親のスロットごとの電源スイッチで 1 段目を作る案 — §2-1 の縦積みリレーに差し替えた（[NOW] L24「旧 N1/N2 は不要」、§2-1 の却下欄）
- **状態**: 決定（ユーザー判断 2026-09-25）

### 1-4 基板は 1 種類、1 枚 4 ch、切替素子の聴き比べはしない

- **決定**: 娘は 1 種類だけ（中は TMUX7612 で ch を選ぶ）、1 枚 4 ch。ch ごとのリレーの基板と、切替素子の聴き比べは v2.1 ではやらない
- **理由**: ユーザーの判断（[NOW] L24–25）
- **根拠**: [NOW] L24「決定（2026-09-25、差し替え）: DC-DC は RS6、1 枚 4 ch、基板は 1 種類だけ」、L25
- **前提・外れる条件**: —
- **却下した案**: v2 の「リレー版とスイッチ版を別 PCB 2 種で起こし、実機で比べる」— v2.1 の目的から外した／ch ごとにラッチングリレーを置く娘（[review/arch_zero_base.md](review/arch_zero_base.md) §0.1 #11）— 同上
- **状態**: 決定（ユーザー判断 2026-09-25）

### 1-5 DIRECT（PT2314E を飛ばす経路）は聴くためのライン入力用

- **決定**: DIRECT はライン入力を聴くための経路とする。v2 の「経路ごとの振幅上限」のうち**精密 DIRECT・フルレンジ DIRECT は要件から外す**。PT2314E を通る通常経路の上限の考え方は残る
- **理由**: 装置は計測器ではない（§0-1）。精密 DIRECT は TMUX の膝の近くまで振る運用のためのもので、耳で比べる用途には要らない
- **根拠**: [NOW] L18／[review/decisions_audit_3_review.md](review/decisions_audit_3_review.md)（v2 の「経路ごとの振幅上限」は「無効」ではなく「前提変更」。無効なのは DIRECT の 2 行だけ）
- **前提・外れる条件**: DIRECT の置き場所・切替の形、ライン入力の振幅の定義（2 Vrms か、それ以上か）は未決（V21-未決-14、[NOW] L27、[review/rejected_review.md](review/rejected_review.md) §3.4）
- **却下した案**: —
- **状態**:
  - 決定: DIRECT は聴くためのライン入力用、精密／フルレンジ DIRECT は要件外（ユーザー判断 2026-09-25）
  - 未決: 置き方（V21-未決-14）

---

## 2. 制御の木

### 2-1 1 段目: 縦積みの各娘に電源用ラッチングリレー → レールがそろってから音声用

- **決定**: ±15 V は全段に常時通す。各娘で **電源用ラッチングリレー（DPDT 1 個、+15 V と −15 V に 1 極ずつ）** をセット → 両レールがそろってから **音声用ラッチングリレー（DPDT 2 個、`TONE_L/R` と `AMP_SEL_L/R` の 4 本）** をセット。リセット（NC 側）は切り離し。**コイルの電源（`+5V_COIL`）と全リセットは常時系統から出す**（電源の無い娘にもリセットが届く）
- **理由**: ラッチングなら聴取中に音声の近くを制御電流が流れない（ユーザーの好み）
- **根拠**: [NOW] L24／[review/arch_zero_base.md](review/arch_zero_base.md) §1.1「ユーザーはラッチングリレーを好む」／[review/stack_relay_power.md](review/stack_relay_power.md)・[_review](review/stack_relay_power_review.md)
- **前提・外れる条件**:
  - ラッチングリレーは衝撃・前歴で状態が変わりうる（G6K・TQ の DS が「リセット位置で出荷、衝撃で変わりうる、初期化せよ」と明記 [bnd] §3、[verify_boundary.md](ds_facts/verify_boundary.md) 要約）。**電源投入時とすべての切替で全リセットから始める**こと（§6）
  - 縦積みで上下・隣のリレーは **5 mm 以上離す**（AZ850 p2 が隣接 5.0 mm を推奨、Panasonic・Omron も近接の影響を明記。[review/stack_relay_power_review.md](review/stack_relay_power_review.md) §3 (c)、[review/rail_detect_review.md](review/rail_detect_review.md) §1 の表）。PCB を起こすときの制約
- **却下した案**:
  - 親のスロットごとの電源 IC（TPS26600 eFuse）— 内部にチャージポンプがあり周波数も DS に無い（電源経路に発振器・チャージポンプを置かない要件に反する）（[review/arch_zero_base_review.md](review/arch_zero_base_review.md) §0.1）
  - スロットごとの ±15 V スイッチ（LM5067／ディスクリート、発振器なしで合格。[review/arch_zero_base_review.md](review/arch_zero_base_review.md) §6 冒頭・§6.1）— [NOW] L24 で電源リレーに差し替えた。**差し替えの理由の記録は無い**
  - 境目を非ラッチングリレー／電源断保護つきアナログ SW／PhotoMOS にする案 — [NOW] L22 の候補で、L24 でラッチングリレーに決めた。**個別の却下理由の記録は無い**（DS 事実は [bnd]）
- **状態**:
  - 決定: 電源用 → 音声用の縦積みラッチングリレー、コイル電源と全リセットは常時系統から（ユーザー判断 2026-09-25、[NOW] L24）
  - DS の制約: リレーの間隔 5 mm 以上

### 2-2 リレーの品種 — 音声用は AZ850P2-5（v2 から）、電源用も同じ石を推奨

- **決定**: 音声用は `AZ850P2-5`（v1/v2 と同じ石）。電源用にも同じ石を使う方向（推奨）
- **理由**: 直列 R を 15 Ω 以上にすれば電源の役でも突入のピークが抵抗負荷の開閉電流 1 A の内に入り（22 Ω で 0.68 A）、音声の役は最小開閉 10 mV / 10 µA・AgPd 金クラッド。2 コイル型なので今のシンク型ドライバ（TBD62083A）で SET/RESET とも駆動でき、FP・BOM・駆動が 1 種で済む
- **根拠**: [review/stack_relay_power.md](review/stack_relay_power.md) §0.1-5・§1.4／[sw] §2（AZ850）／[NOW] L222（v2 から引き継いだ「リレーは AZ850P2-5 に固定（2026-09-09）」）
- **前提・外れる条件**: 容量負荷のメイクは DS の規定の外（1 A は抵抗負荷）。**実機のメイク回数試験**が最終的な根拠（[review/stack_relay_power_review.md](review/stack_relay_power_review.md) 1-3・1-4、V21-実測-11）。直列 R を 15 Ω 未満にするなら電源用だけ 2 A 級（TQ2SA-L2）
- **却下した案**: Omron G6KU・Fujitsu FTR-B3 — 単巻線ラッチで極性反転の駆動が要り、シンク型ドライバでは組めない（[review/stack_relay_power.md](review/stack_relay_power.md) §1.1）／`TQ2-L2` を AZ850 の FP に挿す — COM/NC/NO のピン番号が違い SET/RESET が反転する（[NOW] L222）
- **状態**:
  - 決定: 音声用は AZ850P2-5（v2 の確定 2026-09-09 を引き継ぐ、[NOW] L222）
  - 未決（推奨）: 電源用にも AZ850P2-5。推奨は両役、容量負荷のメイク試験で決める（V21-未決-05、V21-実測-11）

### 2-3 配線: COM＝娘側、NO＝バス（スタック）、NC＝抵抗越しに GND

- **決定**: 音声・電源とも、接点の COM を娘側、NO をバス側、NC を抵抗越しに GND へ。リセット状態で娘側の音声の節とレールが抵抗で放電される
- **理由**: この向きなら NC の抵抗はセット・リセットのどちらの状態でもバスに載らない（バスに見えるのは開いた NO 接点だけ）。逆にするとバスを抵抗で負荷する
- **根拠**: [review/stack_relay_power.md](review/stack_relay_power.md) §0.1-6・§5.1／[review/stack_relay_power_review.md](review/stack_relay_power_review.md) 5-1・5-2（AZ850 p2 の図と v1 のピンの使い方で確認）
- **前提・外れる条件**: 抵抗値は推奨どまり（音声 10 kΩ、レール 2.2 kΩ）
- **却下した案**: 逆向きの配線 — NC の抵抗が並列でバスを負荷する（[review/stack_relay_power_review.md](review/stack_relay_power_review.md) 5-2）
- **状態**:
  - いったんの決め: 配線の向き
  - 未決: 抵抗値（V21-未決-04）

### 2-4 電源接点に直列 22 Ω（ヒューズ抵抗）、NO（スタック）側

- **決定**: 電源接点の後ろに各レール **22 Ω**。品種は**ヒューズ抵抗**（突入パルスには耐え、2 W 連続で開く）。**±15 V は DPDT 1 個で切り、22 Ω は NO（スタック）側へ置く**
- **理由**: 22 Ω で突入のピークが 0.68 A（接点の開閉電流 1 A の 68 %）。NO 側に置けば、リレーの中でどこの極間が短絡しても ±15 V の間に 44 Ω 以上が入る
- **根拠**: [NOW] L25／[review/stack_relay_power.md](review/stack_relay_power.md) §1.3（R ごとの突入のピーク）／[review/rail_detect.md](review/rail_detect.md) §0.4／[review/rail_detect_review.md](review/rail_detect_review.md) 冒頭のユーザー決定 (3)・§6（極間短絡のときの 22 Ω の電力。耐パルスの 1206 では焼けるので溶断型が要る）／[spice/stack_relay/](spice/stack_relay/)
- **前提・外れる条件**: 査読の範囲は 15〜33 Ω。22 Ω は [review/stack_relay_power.md](review/stack_relay_power.md) の推奨を採ったもの（33 Ω を退ける理由は、しきい値を下げた後は残っていない: [_review](review/stack_relay_power_review.md) 3-4・§4、[review/rail_detect_review.md](review/rail_detect_review.md) 要約 5）。最悪の角でも LDO のヘッドルームは目安（≥ 1 V、DS の設計例の "for optimal performance"）を満たす（[_review](review/stack_relay_power_review.md) 3-2〜3-4）。**ヒューズ抵抗の品番の単発パルス曲線は未収集**
- **却下した案**:
  - 4.7〜10 Ω — 突入のピーク 1.48〜3.10 A は DS の保証の外（抵抗負荷の開閉 1 A を物差しにすると超える）。RS6 が 300 mA で頭打ちなら、娘のバルク無しでも親の +15 V は 9.8〜10.7 V まで落ちる〔仮定〕（[review/stack_relay_power_review.md](review/stack_relay_power_review.md) 1-3・2-2）
  - 22 Ω を COM 側 — 極間短絡が ±15 V の直結になる（[review/rail_detect.md](review/rail_detect.md) §0.4）
  - ±15 V を DPDT 2 個に分ける — ユーザーが 1 個のままを選んだ
- **状態**:
  - 決定: ±15 V は DPDT 1 個・22 Ω は NO 側（[review/rail_detect_review.md](review/rail_detect_review.md) 冒頭のユーザー決定 (3)）
  - いったんの決め: 22 Ω・ヒューズ抵抗（[NOW] L25）

### 2-5 制御線は全段共通、各娘はジャンパで自分の段を選ぶ

- **決定**: 制御線は全段に同じ番号で素通しする。電源用 SET は段ごと（4 本）で、各娘はジャンパで 1 本を選ぶ。**リセットは音声用（ARST）と電源用（PRST）の 2 本で、どちらも全段共通**。ch 選択線は共通。音声用 SET は共通 1 本（§2-6）。スタックの制御・電源のコネクタは **2×12（24 本、[NOW] L25）**
- **理由**: 縦積みで各娘が同じピンを見るので、段ごとに違う線を通すなら番号をずらす仕掛けが要る。全段共通＋ジャンパなら娘の基板は 1 種類のまま
- **根拠**: [NOW] L24・L25／[review/stack_relay_power.md](review/stack_relay_power.md) §7.2（線の表）・§5.3（リセットの順番）／[review/stack_relay_power_review.md](review/stack_relay_power_review.md) 6-1・7-2（音声 SET を共通にしても 21 本で 2×10 には入らない）。[NOW] L24 の「RESET 共通 1 本」は古い（順番をファームで守るには 2 本要る）
- **前提・外れる条件**:
  - 24 本の内訳は下書きの算術〔計算〕: [review/stack_relay_power.md](review/stack_relay_power.md) §7.2 の 24 本（段ごとの音声 SET 4 本を含む）から 3 本を引いた 21 本（`PG_N` を含む）に、`MON_P`・`MON_N`・`RAIL_OK`（§5-2・§5-3）を足した数。`PG_N` を残すか、予備の GND を何本にするかは未確定（V21-未決-22）
  - 娘の MCP23017 を残して I²C を通すなら 2 本増えて入らない（同 §7.2、V21-未決-03）。電源用 SET と音声用 SET で選ぶ段を食い違えない配置が要る（同 §7.2）
- **却下した案**: 今の 2×8 のまま — 本数が足りない（同 §7）／親にスロット 4 口を横に並べるバックプレーン — 縦積みに決めた（[review/arch_zero_base.md](review/arch_zero_base.md) §0.1 #15 は横並びを推していた）
- **状態**:
  - 決定: 全段共通・ジャンパで段を選ぶ（[NOW] L24）
  - いったんの決め: 2×12・24 本（[NOW] L25。音声 SET を共通 1 本にした決定の帰結）

### 2-6 音声用 SET は全段共通の 1 本（査読で D10 と呼んだ件）

- **決定**: 音声用リレーの SET は**スタック全段に共通の 1 本**。条件: 音声 SET は「全リセット（全娘の電源リレーと音声リレー）→ 選んだ娘の電源 SET → レール良好 → 共通の音声 SET」の**1 つの手順の中でだけ出す**（ファームの責務、§6-2）
- **理由**: レールの無い娘は B1（§5-4）で音声 SET のコイルに電源が来ないので、共通の SET が届いても**セットできない**。共通線だけに残る弱点（選んでいない娘の電源リレーが衝撃でラッチすると、その娘でも B1 が通る）は、上の手順が必ず全リセットから始まることで消える
- **根拠**: ユーザー判断（2026-09-25「共通で破綻しないならそれで決定」）／[NOW] L25／[review/stack_relay_power.md](review/stack_relay_power.md) §7.2（共通案の弱点）／[review/stack_relay_power_review.md](review/stack_relay_power_review.md) 7-4（段ごとの SET でも、衝撃でセットされた音声リレーは消せない）／[review/rail_detect_review.md](review/rail_detect_review.md) §3.3（B1）
- **前提・外れる条件**: 聴取中に衝撃で別の娘の電源リレーがラッチすると、その娘はレールが立ち、共通の ch 選択でその娘の ch の LDO も入る（音声リレーはリセットのままなのでバスには出ない）。RS6 の負荷は最悪 2 ch 分で +15 V 89 %（HP 最大、[review/bulk_parent_sim.md](review/bulk_parent_sim.md) §0.3）。次の切替の全リセットで切れる。ジャンパの重複で 2 枚が同じ段を選ぶ事故は [review/stack_relay_power.md](review/stack_relay_power.md) §7.2 の弱点として残る
- **却下した案**: 段ごとの音声 SET（4 本）— 衝撃でラッチした音声リレーはどちらでも防げず、残る弱点はファームの手順で消せるので、ピンを 3 本使う理由が弱い
- **状態**: 決定（条件つき、ユーザー判断 2026-09-25）

### 2-7 全リセット → 1 つだけセット。リセットの順番はファーム

- **決定**: 切替はいつも全リセットから。リセットの順番（音声を先・電源を後）は**ファームで守り、ハードは足場だけ**置く。パルス幅もファーム（§6）
- **理由**: 娘のバルクを外したので、電源接点が開いてから LDO が落ち始めるまで 0.4〜3.8 ms しかなく、リセット時間と同じ桁。同時に切るとバスに制御されない過渡が出うる。ただし**壊れはしない**ので、ハードで保証するのは必須ではなく保険
- **根拠**: [NOW] L25／[review/stack_relay_power.md](review/stack_relay_power.md) §0.1-7・§5.3／[review/stack_relay_power_review.md](review/stack_relay_power_review.md) 6-1（ファームの ARST → 20 ms → PRST で足りる）
- **前提・外れる条件**: ハードで順序を保証する（PRST が音声のリセットも叩き、電源だけ 10 ms 遅らせる）かは未決（V21-未決-06、[review/rail_detect.md](review/rail_detect.md) §0.5 D6）
- **却下した案**: —
- **状態**: いったんの決め（[NOW] L25）

### 2-8 2 段目: 娘の中は TMUX7612 で ch を選び、選んだ ch の石だけ LDO の EN で給電

- **決定**: 娘の中の ch 選択は TMUX7612。ch の**出力だけでなく入力も**切る（入出力 L/R＝ch あたり 1 パッケージ）。選んだ ch のソケットだけ、ch ごとの正負 LDO（TPS7A49／TPS7A30）の EN で給電する。TMUX は娘の電源リレーの後ろの ±15 V（LDO の前）に載り、**選んだ娘の中では常時（ch の EN では切らない）**。選んでいない娘では電源ごと落ち、境目のリレーでバスから切られる
- **理由**: 電源を落とした石の入力が共有の `TONE` バスにつながったままだと、どの石でも入力の絶対最大を越え、入力保護ダイオード越しにバスを低いインピーダンスで負荷する（PT2314E の最小負荷 5 kΩ を大きく割る）。アナログスイッチ自身も、バスにつながっている間は通電していないとスイッチがクランプになる
- **根拠**: [NOW] L9・L17・L25／[review/pm12_judgement.md](review/pm12_judgement.md) §5・[_review](review/pm12_judgement_review.md) §E／[review/ds_errata_review.md](review/ds_errata_review.md) O1〜O3（OPA1652・OPA1612・NJM5532 の入力保護ダイオード）／[review/dcdc_2stage_review.md](review/dcdc_2stage_review.md) 1.1（ch に 1 パッケージ、娘の上なので板スイッチの後ろに載る）／V21-継-15（入力クランプ）・V21-継-16（アナログスイッチはバスにつながっている間は通電）
- **前提・外れる条件**: 電源を切った石の出力も ESD 構造でレールにつながるので、出力も切る（V21-継-14）。正側 LDO だけが切れて負側が残る状態は NJM5532 の DS が注意する形（[review/pm12_judgement.md](review/pm12_judgement.md) §5.3-2）
- **却下した案**: 出力だけ切る（v2 の図）— 電源の無い石の入力に信号がかかる（[review/arch_zero_base_review.md](review/arch_zero_base_review.md) §6.3-2）／ch ごとの絶縁 DC-DC — 同時に生きる ch が 1 つなら守る相手が無い（[review/rejected_review.md](review/rejected_review.md) N1）
- **状態**: 決定（ユーザー判断 2026-09-25）

### 2-9 EN は娘の切られたレールから作る。1 ch だけ ON のデコーダは既定 OFF

- **決定**: ch の LDO の EN の論理は娘の切られたレール（電源リレーの後ろ）から給電し、**EN が LDO の IN を超えない形にする**。娘ごとに「1 ch だけ ON できる」デコーダを置き、有効化の既定は OFF。レールが落ちたら EN も切る（§5-5）
- **理由**: TPS7A49 の絶対最大は「EN – IN −36 / +0.3 V」。`3V3` が生きていて ±15 V が無いとき（主電源スイッチ OFF で Pico が USB だけで動く場合、RS6 が保護で止まっている間）に 3.3 V の EN を出すと定格を破る。起動の順序では防げず、DC-DC の型番でも直らない
- **根拠**: [NOW] L15・L25／[pow] §2（TPS7A49 絶対最大 EN–IN、VEN(high) 2.1 V、VEN ≤ VIN）・§3（TPS7A30 EN–IN −0.3/+36 V）／[review/main_power_compare_review.md](review/main_power_compare_review.md) 1-6・§3.3／[review/arch_zero_base_review.md](review/arch_zero_base_review.md) §6 冒頭・§6.2・§6.3-1
- **前提・外れる条件**: EN 保護は要る（ユーザー決定、[review/arch_zero_base.md](review/arch_zero_base.md) 冒頭）。手段は「EN をレールから作る」（決定）で、[NOW] L15 の直列 R＋EN→IN ショットキー＋プルダウンは査読の読みでは不要（[review/arch_zero_base_review.md](review/arch_zero_base_review.md) §6.2）。残すかは未決。**1 ch だけ**をハードで守るのは娘の中だけで、娘をまたぐ排他は §2-6・§6 に残る
- **却下した案**: ファームの規約だけで排他する — MCP23017 の POR 後は全ピンが入力で、プルダウンが守るのはリセット中だけ。ファームのバグ（ポートに全ビット 1 を書く等）には効かない（[review/main_power_compare_review.md](review/main_power_compare_review.md) 1-5）
- **状態**:
  - 決定: EN の論理を娘の切られたレールから給電（[review/arch_zero_base_review.md](review/arch_zero_base_review.md) §6 冒頭のユーザー決定、[NOW] L25）。1 ch だけ ON のデコーダ・既定 OFF（[NOW] L15）
  - 未決: デコーダの素子と置き場所、娘の 3.3 V の作り方（発振器・チャージポンプの無いもの）、直列 R＋ショットキーを残すか（V21-未決-02、[review/arch_zero_base_review.md](review/arch_zero_base_review.md) §6.4 A1）

### 2-10 切替の間は音声を GND へ落とすミュート

- **決定**: 切替の間は、音声を GND へ落として無音にする
- **理由**: 過渡の出どころ（TMUX と境目のリレーの切替、LDO の立ち上がり、出力結合の整定、娘のレールの切替）は全部 `AMP_SEL` バスに出るので、バスより上流の PT2314E のミュートでは消せない
- **根拠**: [NOW] L25／[review/arch_zero_base_review.md](review/arch_zero_base_review.md) §6.3-5／参考製品 [datasheets/reference/Kyohritsu_KP-HAMP61_manual.pdf](datasheets/reference/Kyohritsu_KP-HAMP61_manual.pdf) — PDF p2（本文テキスト層）「切り替え時はオペアンプの電源の切り替えと音声回路の切り替えを行いますが、…1 秒程度の無音期間（音声回路を安全な GND 信号と接続）が取られる構造」、PDF p3（画像、[review/arch_zero_base_review.md](review/arch_zero_base_review.md) §6 で読んだもの）「選択されていないオペアンプが、電源も含めて回路から完全に切り離されている」。操作子はスイッチ 1 個（p1）。無音を検出して電源を切る機構がある（p1・p2）
- **前提・外れる条件**:
  - `AMP_SEL` を直接 GND に落とすと、選んだ石の出力を結合コンデンサ越しに交流短絡するので避ける（[review/arch_zero_base_review.md](review/arch_zero_base_review.md) §6.3-5）
  - ミュートの長さの 2τ/3τ は τ 0.48 s の場合。NC 10 kΩ を採り、TMUX で ch を選んでから音声リレーをセットする順なら τ は約 21 ms で、待ちはずっと短くなりうる（[review/stack_relay_power.md](review/stack_relay_power.md) §0.1-6、[_review](review/stack_relay_power_review.md) 5-3）。実測（V21-実測-12）で決める
- **却下した案**: —
- **状態**:
  - 決定: 方針（切替の間は GND へ落とすミュート）
  - 未決: 場所（ポットの前／HP 入力と LINE 出力／HP 出力の後ろ）、素子（常開・常閉・ラッチング・半導体）、時間（V21-未決-01、[review/arch_zero_base_review.md](review/arch_zero_base_review.md) §6.4）

### 2-11 `TONE` バスに 100 kΩ のプルダウン

- **決定**: 親の `TONE_L/R` に 100 kΩ で GND への DC の基準を置く
- **理由**: `TONE` バスは直列のコンデンサに挟まれて DC が浮いている（査読時の回路図で確認: [review/stack_relay_power_review.md](review/stack_relay_power_review.md) 5-4）。音声リレーをセットした瞬間に娘側（NC 抵抗で 0 V）とバスの DC の段差が入りうる
- **根拠**: [NOW] L25／[review/stack_relay_power_review.md](review/stack_relay_power_review.md) 5-4／[review/arch_zero_base_review.md](review/arch_zero_base_review.md) §6.1（20 Hz で約 −0.08 dB、PT2314E の最小負荷 5 kΩ の内側）
- **前提・外れる条件**: —
- **却下した案**: —
- **状態**: いったんの決め（[NOW] L25）

---

## 3. 電源

### 3-1 主電源の DC-DC は RS6-1215D

- **決定**: ±15 V の絶縁 DC-DC は `RS6-1215D`（入手できれば）。SIP8 の新しいフットプリント（推奨穴 Ø1.00 +0.15/−0 mm）を作る
- **理由**: 1 ch の設計点で出力の合計が定格の **36〜63 %** で、候補の中で軽負荷の領域からいちばん遠い（軽負荷の振る舞いを決めるのは片側ではなく合計の電力）。あわせて最大容量性負荷 ±660 µF（出力ごと）、絶縁容量 110 pF max
- **根拠**: [NOW] L14／[review/main_power_compare.md](review/main_power_compare.md)・[_review](review/main_power_compare_review.md) §3.1（理由の順番を直した）／[pow] §1（±200 mA、9–18 V、±660 µF、110 pF max、内部動作周波数「0-100% load」Min 200 kHz、起動 2 ms、UVLO ON 9 V typ、OLP 150 %、SIP8 のピン配置と穴径。CTRL は開放で ON）／[scripts/rail_budget.py](scripts/rail_budget.py)（`--adc-from-pd`）／[scripts/dcdc2/](scripts/dcdc2/)
- **前提・外れる条件**:
  - ADC の LDO を ±15 V に載せない（§4-4。載せると定格に入らない）
  - 突入をどこまで出せるか・OLP の形（出力ごとか合計か、定電流かヒカップか）は要実測（V21-実測-01）。8 ch が同時に入る故障では +15 V が定格の 136〜161 % のまま流れ続けうるので、§2-9 のデコーダと §6 の手順で防ぐ
  - 今のフットプリント（1″×1″）にも、リポジトリにある SIP8 の FP（穴 Ø0.8）にも合わないので、新しい FP が要る
  - v2 の記録にある 6 W 低 Ciso 群（10〜20 pF）は 1 ch 通電で候補の電力帯に入ったが、比較に入れていない（[review/v2_carryover.md](review/v2_carryover.md) の「絶縁 DC-DC の絶縁容量 — 探索結果」の行、V21-未決-21）
- **却下した案**:
  - `TMR 9-1223` — Cout ±200 µF でレールの見込みの上側を超えうる、500 kHz は全負荷の値で軽負荷の記載が無い、金属ケース（[review/main_power_compare.md](review/main_power_compare.md) §2.1、[_review](review/main_power_compare_review.md) 1-3）（次点。絶縁容量 50 pF max は RS6 より良い。−15 V は軽負荷側でベンチ確認が要る、[_review](review/main_power_compare_review.md) §3.1）
  - `TMR 10-1223WI` — Cout ±220 µF、絶縁容量 1000 pF typ、4.1〜4.5 V で起動するので PD が交渉する前の 5 V で動いてしまう（同上）
  - `REC20K-2415DZ`（v2 の石）— 1 ch では −15 V が定格の約 8 % で DS の Note4（10 % 未満は仕様を満たさないことがある）より下、絶縁容量 2000 pF typ（同上、[review/dcdc_2stage_review.md](review/dcdc_2stage_review.md) 1.2）
  - Mornsun `URA` — v2 と同じく NFND（V21-継-13）。「軽負荷で周波数を下げる」は決め手ではない（[review/rejected_review_review.md](review/rejected_review_review.md) #12）
  - ±15 V を 2 台に分ける（ソケット用と常時系）— HP バッファの電流は分けても共有側に残る（[review/rejected_review_review.md](review/rejected_review_review.md) N4）
- **状態**: 決定（ユーザー判断 2026-09-25、入手できれば）

### 3-2 PD は 12 V 固定

- **決定**: PD の受け電圧は 12 V に固定する（他の設定にしない）
- **理由**: ADC の LDO（LT1763）を PD 12 V から直接取るので、IN の絶対最大 ±20 V に対して 20 V 設定は許容差の分だけ超えうる。RS6 の入力範囲も 9〜18 V（サージ 25 V は 1 秒まで）
- **根拠**: [NOW] L11／[review/adc_gnd_retree_review.md](review/adc_gnd_retree_review.md) §1 の表（LT1763 の IN 絶対最大）・§7.4／[pow] §1（RS6 入力範囲）
- **前提・外れる条件**: PD モジュールは交渉前に 5 V を出す。主電源スイッチを入れたまま USB-C を挿すと、その間 ADC 側だけが立つ（[review/adc_gnd_retree_review.md](review/adc_gnd_retree_review.md) §7.4「PD の 5 V の窓」）。RS6 は UVLO で止まっている
- **却下した案**:
  - 20 V — LT1763 の絶対最大を許容差の分だけ超えうる
  - 15 V — LT1763・RS6 とも範囲内だが、固定にした（v2 の「PD 入力 — どの電圧で受けるか」「12 V が出なかったときの手順」の 15 V は v2.1 では使わない）。15 V を退ける理由の記録は無い
- **状態**: いったんの決め（[NOW] L11）

### 3-3 PT2314E・計測は生の ±15 V、TMUX は娘の切られた ±15 V、ソケットは ch ごとの LDO で ±12 V

- **決定**: ±15 V はそのまま、親の PT2314E（9 V レギュレータ経由）と計測系、娘の TMUX7612 に使う（TMUX は娘の電源リレーの後ろ。選んだ娘の中では ch の EN で切らない、§2-8）。ソケットは ch ごとの正負 LDO（TPS7A49／TPS7A30）で ±12 V。LDO の出力電圧は帰還の分圧で決まるので、ch ごとに選べる
- **理由**: ±12 V を DC-DC で直に作ると TMUX7612 の平坦域の膝がレールに追従して下がる（DS 本文: 平坦域は「概ね VSS+5 V〜VDD−5 V」。Figure 5-4 の目読みで Ron が底から離れ始めるのは ±15 V で約 +10.6 V、±12 V で約 +7.6 V）。ソケットだけを LDO の後ろで ±12 V にすれば膝は動かず、ch ごとの EN（§2-8）と PSRR も LDO が持つ
- **根拠**: [NOW] L17・L22／[sw] §1（平坦域の本文、Figure 5-4）／[pow] §2（TPS7A49 の出力電圧の式 R1 = R2 (VOUT/VFB − 1)、PSRR 72 dB @120 Hz）・§3（TPS7A30）／[review/rejected_review.md](review/rejected_review.md) #9／[review/pm12_judgement.md](review/pm12_judgement.md)・[_review](review/pm12_judgement_review.md)
- **前提・外れる条件**: ±12 V で電源範囲から外れる石は無い。ただし ±12 V で振幅が保証されるのは OPA1612・OPA2140 だけ。最悪要求（9.45 Vpk）と LDO の総合精度 ±2.5 % を入れると、余裕が正で残るのは保証の 2 石と typ グラフの 5 石。推定 min の石は 0 dB 前後か負（[review/pm12_judgement_review.md](review/pm12_judgement_review.md) 要約 3・5・6、A 表）。TPS7A49 の IOUT は 150 mA まで（[pow] §2）
- **却下した案**:
  - ±12 V の DC-DC で系全体を ±12 V（v2 の「±15 V の理由は3つとも消えた…±12 V 側にも重い障害」の検討、`REC10K-2412DAW/H2` ほか）— TMUX の膝が下がる。PT2314E の 9 V レギュレータ（L7809）の入力も 11.5 V（出力の許容差を保証する試験条件の下限）を割る（v2 の「`+9V`…が規定入力範囲を割る」。11.5 V の読みは [review/v2_carryover.md](review/v2_carryover.md) の訂正 #5）
  - `NSD10-12D12` — 2″×1″ で新しいフットプリント、最小負荷 20 mA/レール（1 ch 運転と合わない）、±12 V 出力（V21-継-13、[review/decisions_audit_1.md](review/decisions_audit_1.md)）
- **状態**: 決定（ユーザー判断 2026-09-25）

### 3-4 PT2314E は +15 V → L7809 のまま

- **決定**: PT2314E の電源は今までどおり +15 V から L7809 で 9 V
- **理由**: 電源だけ一次側（PD）へ移すと、PT2314E の帰り電流がグランドの木の中の唯一の橋を通る（v2 で一度潰したバグの再導入）
- **根拠**: v2 の「副次案『`+9V` 枝を `+15V` から外す』は一度潰したバグの再導入」／[review/decisions_audit_1_review.md](review/decisions_audit_1_review.md) 修正の要点 1（この v2 の項は「却下の再検討」ではなく維持）／[review/rejected_review_review.md](review/rejected_review_review.md) #8
- **前提・外れる条件**: +15 V の負荷を非対称にする唯一の塊がこれ（+15 V だけに 35〜48 mA）で、動かせない（[review/main_power_compare.md](review/main_power_compare.md) §3.2）
- **却下した案**: PT2314E を PD 12 V 側へ — 上の理由
- **状態**: 決定（ユーザー判断 2026-09-25。[review/decisions_audit_1.md](review/decisions_audit_1.md) の決定⑤）

### 3-5 娘のダンパのバルクは外す

- **決定**: 娘の ±15 V のバルク（ダンパ）を外す
- **理由**: 直列 R が 1 Ω 以上なら、どの角でも親→娘の伝達に共振の山が無い。バルクを残すと突入の電荷が増えて親の落ち込みを大きくするだけになる
- **根拠**: [NOW] L25／[review/stack_relay_power.md](review/stack_relay_power.md) §0.1-3・§4（1 Ω 以上で 144/144 組とも山なし、22 Ω・バルク無しで fsw 帯 −42.7 dB 以下）／[review/stack_relay_power_review.md](review/stack_relay_power_review.md) 4-1（安定性の懸念なし）／[spice/stack_relay/](spice/stack_relay/)
- **前提・外れる条件**: ch LDO の CIN は 10 µF（DS の強い推奨、[pow] §2）。リセット時に電源接点が開いてから LDO が落ちるまでの余裕は小さくなる（§2-7）
- **却下した案**: 娘ごとに RC ダンパ（35〜45 µF・0.1〜0.2 Ω）— [NOW] L19–20 の旧方針。直列 22 Ω を入れた後は突入を増やすだけ（上の根拠）／親だけにバルク（直列 R なし、**ユーザー案**）— 共振が娘の側に残り、親を盛っても直らない（[review/bulk_parent_sim.md](review/bulk_parent_sim.md) §0.1・§0.2）
- **状態**: いったんの決め（[NOW] L19 の「残す」を L25 で差し替え）

### 3-6 親の +15 V/−15 V に +100 µF は任意

- **決定**: 親のバルク +100 µF は足場として置けるようにし、**要否は RS6 の突入を実測して決める**。実測は基板を起こす前に
- **理由**: 22 Ω・娘のバルク無しなら、RS6 が 300 mA で頭打ちでも親の最低は約 12.25 V で、PT2314E の 9 V は動かない。+100 µF が効くのは RS6 の OLP がヒカップ型か 300 mA 以下で頭打ちするときの保険だけ
- **根拠**: [NOW] L25／[review/stack_relay_power_review.md](review/stack_relay_power_review.md) 2-5・2-6（L7809 の挙動モデル）・2-3（どの R でも RS6 の電流は 300 mA を超える）
- **前提・外れる条件**: RS6 の出力インピーダンスと電流制限の形は DS に無く、シミュレーションは〔仮定〕の上（[review/stack_relay_power.md](review/stack_relay_power.md) §8）
- **却下した案**: 必須にする（[review/stack_relay_power.md](review/stack_relay_power.md) §0.2 の推奨）— 査読で任意に格下げ
- **状態**:
  - いったんの決め: 任意＝足場を置く（[NOW] L25）
  - 要実測: 実装するか。基板を起こす前に（V21-実測-01）

### 3-7 ch LDO: CNR/SS は必須、後ろの容量は合計 22 µF 以下

- **決定**: ch の LDO には CNR/SS（10 nF）を付ける。LDO の出力側の容量は合計 22 µF 以下
- **理由**: CNR 無しだと立ち上がりが電流制限になり、娘のレールが 8.6〜12.6 V まで落ちる。DS 上は安定に必須ではないが、この構成では必須
- **根拠**: [NOW] L25／[review/stack_relay_power_review.md](review/stack_relay_power_review.md) 4-4・2.4（自作の LDO 起動モデル）／[pow] §2（tSS = 1.4 × CNR[nF] ms）
- **前提・外れる条件**: 22 µF の上限は、レール良好のしきい値を 13.0 V に置いていたときの制約。しきい値を約 10.5 V に下げた（§5-1）後は制約が消える、と査読が支持している（[review/rail_detect.md](review/rail_detect.md) §0.2、[review/rail_detect_review.md](review/rail_detect_review.md) 要約 5）
- **却下した案**: —
- **状態**: いったんの決め（CNR/SS 必須・合計 22 µF 以下: [NOW] L25）。**ただし 22 µF の前提（しきい値 13.0 V）はしきい値を下げたことで消えた** → 上限を外すかはユーザー確認待ち（V21-未決-07）

### 3-8 コイル電源は L7805C（PD 12 V からのリニア）

- **決定**: `+5V_COIL` は `BP5293-50` をやめて `L7805C`。入力側の PPTC は、コイルの最悪の同時通電（約 560 mA・30 ms）で切れない値にする
- **理由**: `+5V_COIL` は全娘へ配られ、娘の上でリレーの間を音声の近くに通る。BP5293 は 570 kHz の内部発振器を持ち、軽負荷で間欠動作に入る。聴取中はコイル電流が 0 なので、スイッチングの無いリニアで足りる
- **根拠**: [NOW] L25／[review/arch_zero_base.md](review/arch_zero_base.md) §0.1 #9／[review/arch_zero_base_review.md](review/arch_zero_base_review.md) §0.1（BP5293 の発振器）・§6.1／[review/stack_relay_power_review.md](review/stack_relay_power_review.md) 7-3（最悪 46.7 mA × 12 ＝ 560 mA、リニアでは入力電流＝出力電流で、今の PPTC 0.4 A 保持をパルスの間超える）
- **前提・外れる条件**: PPTC のトリップ曲線は未照合
- **却下した案**: BP5293 のまま — 発振器（上の理由）
- **状態**: いったんの決め（[NOW] L25）

### 3-9 電源系統の独立は b-1、PD 入口に CMC の足場

- **決定**: 「電源系統の独立」は **b-1**（系統ごとに自分のレギュレータ、グランドは 1 点で結ぶ木）と読む。PD の受け端子の直後にコモンモードチョークの足場（0 Ω で素通し）を置く
- **理由**: ADC のグランドの付け替え（§4-4）で ADC の LDO の直流が `A_GND` を通らなくなり、b-1 が成り立つ形になった。ガルバニックに切る読み（b-2・b-3）が効くかは、PD 充電器が音に出ているかで決まり、誰も測っていない
- **根拠**: [NOW] L16／[review/rejected_review.md](review/rejected_review.md) §0（b-1/b-2 の定義）／[review/rejected_review_review.md](review/rejected_review_review.md) §2（b-3〜b-6）／[review/main_power_compare.md](review/main_power_compare.md) §4／[_review](review/main_power_compare_review.md) 1-7（「字義どおり」なのは ADC の LDO の直流についてだけ。AFE は ±15 V から取って `ADC_GND` へ帰る）
- **前提・外れる条件**: PD 充電器の A-B-A（V21-実測-03）で差が高域なら CMC を実装、音声帯なら b-3（PD だけを絶縁）を検討。木が成り立つのはシャーシを 1 点で落とすときだけ（パネル部品の金属部・ジャックのスリーブ・PD モジュールのシェルがパネルに触れる閉路）（[review/adc_gnd_retree_review.md](review/adc_gnd_retree_review.md) §3.2・§8-1）
- **却下した案**: b-2（一次と音声側を電気的に切る）— ADC の LDO を PD から取る決定と両立しない（帰り道が無くなる）（[review/rejected_review.md](review/rejected_review.md) §3.1-4）
- **状態**:
  - いったんの決め: b-1 の読み、CMC の足場（0 Ω で実装）（推奨をユーザーが受けた、2026-09-25）
  - 要実測: CMC を実装するか（V21-実測-03）

### 3-10 −15 V のプリロード抵抗は足場（DNP、3.0 kΩ）

- **決定**: DC-DC の −Vout と COM の足元に 3.0 kΩ の足場を置き、実装しない（±15 V 間のブリーダではなく −15 V と COM の間のプリロード）
- **理由**: RS6 のクロスレギュレーションは「25 % to 100 % load」で typ だけ規定。1 ch・typ・無音の −15 V は 26.2〜26.7 % で、INA1650 が min 側に振れるか軽い石を挿すと 25 % を割る（軽い端 23.6 %）。3.0 kΩ（5 mA、75 mW）を入れれば軽い端でも 26 % を超える
- **根拠**: [NOW] L16／[review/main_power_compare.md](review/main_power_compare.md) §3.4／[review/dcdc_2stage_review.md](review/dcdc_2stage_review.md) 要約 5・1.2
- **前提・外れる条件**: −15 V が軽いときに電圧がどちらへ振れるかは DS に無い。電圧の偏り自体は、±15 V に直結の負荷をどれも止めない（[review/main_power_compare.md](review/main_power_compare.md) §3.3）。実装は実測で決める（V21-実測-02）
- **却下した案**: —
- **状態**:
  - いったんの決め: 足場（DNP）（推奨をユーザーが受けた、2026-09-25）
  - 要実測: 実装するか（V21-実測-02）

### 3-11 ヘッドホンバッファの電源に RC の足場

- **決定**: ヘッドホンバッファ（OPA1652）の電源に自前の RC を入れられる足場を置く
- **理由**: 32 Ω を鳴らす信号電流（各レール平均 5〜25 mA、瞬時 16〜80 mA）は音声帯で変わる負荷として共有の ±15 V に載る。加えて 32 Ω に連続で出すとバッファの接合温度が定格を超える
- **根拠**: [NOW] L16／[review/main_power_compare.md](review/main_power_compare.md) §1.4・§4（b-5）／[review/main_power_compare_review.md](review/main_power_compare_review.md) 1-2・§3.5（連続正弦で約 0.82 W・+117 °C）
- **前提・外れる条件**: LINE 出力に HP と相関する成分が出るかは未測定（V21-実測-08）。HP の帰りをバッファのデカップの GND へ寄せる配線と組にしないと効きが半分（同 1-7）
- **却下した案**: —
- **状態**:
  - いったんの決め: 足場（推奨をユーザーが受けた、2026-09-25）
  - 要実測: 実装するか（V21-実測-08）

---

## 4. ADC 経路

### 4-1 タップは今の位置（`AMP_SEL_L/R`、ポットの前）

- **決定**: 計測のタップは `AMP_SEL_L/R`（ch 選択の直後、DEST スイッチ・音量ポット・HP バッファの手前）のまま
- **理由**: ユーザーの判断
- **根拠**: [NOW] L12／[review/tap_facts.md](review/tap_facts.md) §1.1（v1 もポットの前で取っていた）
- **前提・外れる条件**: 本線に直接触るのは計測タップのバッファ（OPA1656 フォロワ）だけ。バス負荷は v2 と同じ
- **却下した案**: —
- **状態**: 決定（ユーザー判断 2026-09-25）

### 4-2 ADC 経路に絶対の品質は求めない。優先は本線を汚さないこと

- **決定**: ADC 経路は LCD のスペアナ・VU メーター・USB で Pico 経由の簡易分析ができれば足りる。**本線を汚さないことを優先**する
- **理由**: 装置は計測器ではない（§0-1）
- **根拠**: [NOW] L13・L33／参考値: ソケットの抜き差しで再現できる範囲は記録上 −106 dBc（H3 の差の検出限界、v1 仮配線、n=1）（[review/tap_facts.md](review/tap_facts.md) §4.1）
- **前提・外れる条件**: −106 dBc は「差の再現性」で、鎖の絶対歪みではない。v1 は鎖のベースライン −76 dBc のまま −106 の差を出した（[review/tap_compare_review.md](review/tap_compare_review.md) 2-2・2-3）
- **却下した案**: 分解能を上げること自体を目的にする — v2 の「そもそも: 測定系が答えるべき問いには既に答えが出ている」と同じ
- **状態**: 決定（ユーザー判断 2026-09-25）

### 4-3 結合は差動（INA1650 をタップのバッファの後ろ）、片側（今の形）に戻せる足場

- **決定**: タップのバッファの後ろに INA1650 を置き、− 入力を GND センス線へ、REF を `ADC_GND` へ。逆相を作る反転段は残し、その基準を `ADC_GND` へ移す。ジャンパ／0 Ω で今の片側（Q1）へ戻せる形にする
- **理由**: ch 側のグランドと計測側の `A_GND` の差は、今の片側では信号と直列に乗る（除去 0 dB）。差動なら DS の CMRR（85 dB min、±18 V 条件）で落ち、REF を `ADC_GND` に取れば ADC の電源・グランドの置き場が自由になる（§4-4 の付け替えの前提）
- **根拠**: [NOW] L12／[review/tap_compare.md](review/tap_compare.md) §2.2・[_review](review/tap_compare_review.md) §2.1（「43 dB」は別の差の値で、Q1 の ch↔計測側の差は 0 dB）／[review/adc_gnd_retree.md](review/adc_gnd_retree.md) §2・[_review](review/adc_gnd_retree_review.md) §4／[tap] Q2-2（INA1650: CMRR 85/91 dB、IQ 10.5/12 mA、入力バッファ内蔵）
- **前提・外れる条件**: **そのグランド差が実際に効いているかは測っていない**（V21-実測-07）。効いていなければ Q2 は保険で、実績があるのは Q1（v1 の同じ形で −106 を出した）だけ（[review/tap_compare_review.md](review/tap_compare_review.md) §3）。±15 V での CMRR の規定値は無い
- **却下した案**: INA1620・SSM2141・SSM2143・AD8274・INA134/137・THAT1200 — 入力インピーダンスが低く両脚にバッファが要る、差動アンプとしての CMRR の規定が無い、個別高調波の規定が無い、など（[review/tap_compare.md](review/tap_compare.md) §2.2）／絶縁系の結合は §4-10
- **状態**:
  - 決定: Q2（差動）と、Q1 に戻せる足場（ユーザー判断 2026-09-25）
  - いったんの決め: REF を `ADC_GND`・反転段の基準を `ADC_GND` へ（提案で査読が支持したもの）
  - 未決: GND センス点と切替の形（V21-未決-08）

### 4-4 ADC の LDO は PD 12 V（主電源スイッチの後ろ）から。ADC のグランドの木を付け替える

- **決定**: 計測系の LDO（`+3V3_A` / `+5V_A`）は PD 12 V（ネット `PD_12V_SW`、主電源スイッチの後ろ）から取る。`ADC_GND`–`A_GND` の NetTie をやめ、**グランド選択の 1×3 ヘッダ**で Q2 は `ADC_GND` を `D_GND` 側の葉に、Q1 へ戻すときは `A_GND` 側へ結ぶ
- **理由**: RS6 で ADC を +15 V に載せると、1 ch・max・無音で約 212 mA（定格の 106 %）、HP 最大で約 237 mA（119 %）〔計算: [review/main_power_compare.md](review/main_power_compare.md) §1.5 の 124.8／150.2 mA ＋ `rail_budget.py` の ADC 枝 max 86.9 mA〕。**定格に入らない**。記録の 197.7 mA／98.9 % は INA1650 を足す前の値（[review/v2_carryover.md](review/v2_carryover.md) の訂正 #31）
- **根拠**: [NOW] L10／[review/adc_gnd_retree.md](review/adc_gnd_retree.md) §0.1・§3・[_review](review/adc_gnd_retree_review.md) §0・§3（骨格は覆らなかった。付け替え後は ADC の直流の帰りが `ADC_GND` → ヘッダ → `D_GND` → `PD_GND` と帰り、`A_GND` を通らない）／[review/DECISIONS_v21_review.md](review/DECISIONS_v21_review.md) B2（212 mA の算術）／[scripts/rail_budget.py](scripts/rail_budget.py) `--adc-from-pd`
- **前提・外れる条件**: 1×3 ヘッダ＋シャント 1 個なら、Q1・Q2 を同時に結ぶ閉路は物理的に起きない（[review/adc_gnd_retree_review.md](review/adc_gnd_retree_review.md) §3.1）。「木」はガルバニックな話で、DC-DC の絶縁容量の輪・`±15V_AFE` の R・筐体の閉路は別（同 §3.2）。PD 給電では電源断のたびに「±15 V はあるが ADC の電源が無い」窓が開く（§4-6）
- **却下した案**:
  - ADC の LDO を +15 V のまま（v2 の「非絶縁バック…を削除。ADC の LDO は `+15V` 直結」）— 上の理由（RS6 の定格に入らない）
  - `ADC_GND` を `PD_GND` へ結ぶ — 木にはなるが I²S の帰りが 2 ホップになる（[review/adc_gnd_retree.md](review/adc_gnd_retree.md) §3.1）
  - ADC 枝の電源に絶縁 DC-DC（v2 の「…を別の DC-DC に替える案」「絶縁コンバータで置き換える案について」）— b-1 の読み（§3-9）では要らない。スイッチング源が 1 つ増える（[review/rejected_review.md](review/rejected_review.md) #2）
- **状態**: 決定（PD 12 V から・付け替えの方向: ユーザー判断 2026-09-25）

### 4-5 ADC の枝に PPTC を新設

- **決定**: PD 12 V から ADC の LDO へ行く枝に PPTC を置く
- **理由**: PD 本線（受け端子 → 主電源スイッチ → `PD_12V_SW`）には枝より手前のヒューズが無く、他の枝はそれぞれ自分の保護を持つ。ADC の枝だけが無保護になる。v2 の「戻さない」は LDO が +15 V（DC-DC の短絡保護の後ろ）にあることが前提だった
- **根拠**: [NOW] L10–11／[review/adc_gnd_retree.md](review/adc_gnd_retree.md) §6.1・[_review](review/adc_gnd_retree_review.md) §2・§7.4／v2 の「ADC 枝の PPTC は戻さない」（[review/v2_carryover.md](review/v2_carryover.md)）
- **前提・外れる条件**: 定格は PPTC の DS（温度ディレーティング）を取ってから（hold 0.25 A 級が候補、未照合）。LDO 前の直列 R はフォールト電流を受けるのでパルス定格のある品（[review/adc_gnd_retree_review.md](review/adc_gnd_retree_review.md) §6.2）
- **却下した案**: 計測の 5 V レギュレータ入口の PPTC の後ろ（`PD_12V_MEAS`）から取る — PPTC は増えないが、ADC の枝の短絡で Pico も落ち、5 V レギュレータの入力脈流の隣になる（同 §7.4 の表・§10-4）
- **状態**: いったんの決め（[NOW] L11）

### 4-6 ADC 前の直列 47 Ω → 100 Ω（電源断ごとの窓は許す）

- **決定**: ADC を直接駆動するドライバと ADC 入力の間の直列抵抗を 47 Ω から 100 Ω にする。電源を切るたびに開く窓は許す
- **理由**: PD 給電では電源断のとき ADC の電源が ±15 V より先に落ち、その間（約 15〜40 ms）ドライバの出力が ADC 入力のクランプへ流れる。フルスケールで 14〜16 mA pk と PCM1804 の絶対最大 ±10 mA を超えるが、100 Ω なら 6.5 mA
- **根拠**: [NOW] L11／[review/adc_gnd_retree_review.md](review/adc_gnd_retree_review.md) §7.1・§7.4（代償は ADC 入力 10 kΩ との分圧 −0.09 dB と DS の値からの逸脱）
- **前提・外れる条件**: この構成では 47 Ω はドライバの帰還ループの外にあるので電流を制限できる（DS の図はループの中）（同 §9 訂正の一覧、47 Ω の行）
- **却下した案**: ドライバを `+5V_A` の単電源にする — 構造で解けるが `+5V_A` の負荷と ADC の VCC への信号電流が増え、過剰（同 §7.4 (b)）／何もしない — 窓は「事故のときだけ」ではなく電源を切るたびに開く（同 (c)）
- **状態**:
  - いったんの決め: 100 Ω、窓は許す（[NOW] L11）
  - 未決: VCOM とドライバ +IN の間の 1 kΩ（逆向きの窓の保険。RS6 なら故障時だけの保険）（同 (d)、V21-未決-10）

### 4-7 `±15V_AFE` の直列は 22〜33 Ω

- **決定**: ADC 側のオペアンプ（INA1650・反転段・ドライバ）の ±15 V デカップを `ADC_GND` に揃え、その手前に各レール 22〜33 Ω の直列抵抗（`±15V_AFE`）
- **理由**: デカップを `ADC_GND` に置くと、±15 V のリップル電流が `ADC_GND` → `D_GND` → `A_GND` と渡り、その大きさはほぼ Vripple / R。4.7 Ω だと 265 kHz で最大 10〜21 mA p-p を `A_GND` の星点へ入れるが、22〜33 Ω なら 1.5〜4.5 mA p-p
- **根拠**: [NOW] L11／[review/adc_gnd_retree_review.md](review/adc_gnd_retree_review.md) §6.1（表）・§9 C3
- **前提・外れる条件**: 33 Ω で V+ が約 13.7 V まで下がっても、INA1650 の同相の上限（V+ − 2 V）はフルスケール 7.74 Vpk の上（同 §1 の表）。ADC の HF の電流（ドライバのキックバック）は `ADC_GND` の中で閉じる（[review/adc_gnd_retree.md](review/adc_gnd_retree.md) §4）
- **却下した案**: 4.7 Ω — 上の理由／フェライトビーズ — 265 kHz ではほとんど効かない（[review/adc_gnd_retree_review.md](review/adc_gnd_retree_review.md) §6.1）
- **状態**: いったんの決め（[NOW] L11）

### 4-8 INA1650 の RCOM は 0 Ω（1 MΩ に替えられる足場）

- **決定**: INA1650 の COM は 0 Ω で `ADC_GND` へ。1 MΩ に替えられるフットプリントにする
- **理由**: RCOM = 0 ならセンス線が切れても Q1 相当に落ちるだけで、センス線の電流は nA 級。1 MΩ だと断線で −9.5 dB になり、センス線に約 6 µA pk/ch の信号電流が出る
- **根拠**: [NOW] L11／[review/adc_gnd_retree_review.md](review/adc_gnd_retree_review.md) §4・§9 C1・C2・§10-6／[tap] Q2-2（20 Ω の不整合で 83.7 dB、RCOM 1 MΩ で 89.6 dB）
- **前提・外れる条件**: 源インピーダンスの不整合は 1 Ω 未満の見込みで、RCOM の差は小さい（同 §1 の表）
- **却下した案**: 1 MΩ（[review/adc_gnd_retree.md](review/adc_gnd_retree.md) の推奨）— 上の理由で仮置きは 0 Ω
- **状態**: いったんの決め（仮置き、[NOW] L11）

### 4-9 計測側の予備 12 V 入口は残し、主電源スイッチを迂回する旨を注記

- **決定**: 計測側の予備 12 V 入口とそのヒューズは残し、「ここから給電すると主電源スイッチを迂回する（受け端子から給電しているときはスイッチ後の 12 V が出ている端子になる）」と図に注記する
- **理由**: 予備入口はスイッチ後の `PD_12V_SW` につながっている（査読時の回路図、[review/adc_gnd_retree_review.md](review/adc_gnd_retree_review.md) §2）
- **根拠**: [NOW] L11／[review/adc_gnd_retree_review.md](review/adc_gnd_retree_review.md) §2（副作用）・§10-7
- **前提・外れる条件**: 両方から同時に給電すると電源が並列になる（同 §2）
- **却下した案**: —
- **状態**: いったんの決め（仮置き、[NOW] L11）

### 4-10 却下した結合・絶縁の案

- **決定**: 計測タップの経路は、絶縁アンプ・信号トランス・デジタル絶縁・ADC の絶縁島のどれも採らない
- **理由**: どれも −106 dBc（差の検出）を良くする根拠が記録に無く、ADC の電源の置き場を先に決めてしまうか、ADC の隣に新しい高周波源を置く
- **根拠**: [review/tap_compare.md](review/tap_compare.md) §2.3〜§2.5・[_review](review/tap_compare_review.md) §2・§3／[review/rejected_review.md](review/rejected_review.md) #1・[_review](review/rejected_review_review.md) #1
- **前提・外れる条件**: b-2（ガルバニックに切る）を採るなら見直す（§3-9）
- **却下した案**:
  - 絶縁アンプ（ISO224B・AMC3330 ほか）— DS の THD は −84 dB（10 kHz）で 1 kHz 未満の規定が無い。ISO224 の雑音は DS の中で 3 倍食い違い、悪い方なら雑音だけで −106 を割る。内部の ΔΣ・搬送波・DC-DC が ADC の隣に来る（[review/tap_compare_review.md](review/tap_compare_review.md) 6-1・6-2）
  - ライン・トランス（JT-11P-1）— 1 kHz の「<0.001 %」は typ 列で、1320 Hz の H3 とその安定性は DS に無い。二次側にバッファが要り、寸法も不明（同 3-5・6-3）
  - デジタル絶縁（ISO7741 を I²S に）— −106 に効く筋が記録から立たず（「本命」の記録は ADC 自身の床の話）、ADC の電源を ±15 V 側に固定する。部品代ほぼゼロの比較相手（ADC 出力への直列抵抗）がある（同 5-4〜5-6、§3「別枠」）
  - ADC を絶縁した島（v2 の「【却下】ADC を絶縁した島にする案」）— 却下のまま。島が動かすのは測定床の実用律速より下の部分で、装置は計測器ではない（[review/rejected_review.md](review/rejected_review.md) #1）。RS6 で絶縁容量が下がっても「島の性能は DC-DC の絶縁容量で決まる」構図は残る（[review/decisions_audit_1_review.md](review/decisions_audit_1_review.md) 修正の要点 4）
  - PT2314E 境界の絶縁 I²C（`ADuM1250` 級、v2 の「`DGND`(25) はチップの足元で `A_GND` へ」の節。V21-継-05）— b-1 なら理由（`D_GND` はどのみち娘へ引く）は成り立ち、むしろ強まる（[review/decisions_audit_2_review.md](review/decisions_audit_2_review.md) 3.3）
  - USB アイソレータ（`ADuM3160`）— USB を抜いた A/B で床の差 2.9 dB（n=1）（[review/rejected_review_review.md](review/rejected_review_review.md) #10）
- **状態**: v2 の却下を引き継ぐ（v2.1 で個別の判断はしていない。Q2 の選択はこれらを退けた判断ではない）。絶縁アンプ・トランス・デジタル絶縁は v2.1 の査読の順位で採っていないだけで、ユーザーは判断していない

---

## 5. 監視と連動

### 5-1 レール検知はしきい値つき、しきい値は下げる

- **決定**: 娘の ±レールの検知はしきい値で行い、立ち上がり（遅延つき）で音声 SET を許し、立ち下がり（即時）で音声を自動リセット。+ と − の両方。しきい値は 13.0 V から下げる。検知の分圧は **0.1 %**、ただし他の公差・不良にも耐える作りにする
- **理由**: 立ち下がりのしきい値を約 10.5 V まで下げると、ch LDO の起動時の落ち込み（最悪 13.44 V）から離れて迷惑トリップしない。分圧 1 % だと立ち下がり帯の下端が約 10 V を割る
- **根拠**: [NOW] L25／[review/rail_detect.md](review/rail_detect.md) 冒頭（ユーザー決定）・§0.2（0.1 % で帯 10.24〜10.79 V / 11.68〜12.22 V（+））／[review/rail_detect_review.md](review/rail_detect_review.md) 冒頭（ユーザー決定）・要約 3・§2（帯の重なりの判定は不要な条件、1 % の弱点は下端だけ）
- **前提・外れる条件**: 13.0 V のしきい値（[review/stack_relay_power.md](review/stack_relay_power.md) §0.2）は公差込みで窓の上端に張り付いていた（[review/stack_relay_power_review.md](review/stack_relay_power_review.md) 3-7）。EN の保護（EN ≤ IN + 0.3 V）だけなら、しきい値を高く置く必要は DS 上は無い
- **却下した案**: 13.0 V — 上の理由
- **状態**:
  - 決定: しきい値で検知・しきい値を下げる・分圧 0.1 %（ユーザー判断 2026-09-25）
  - 値は案: 立ち上がり ≈ ±12 V・遅延 10〜20 ms／立ち下がり ≈ ±10.5 V（[NOW] L25）

### 5-2 レールは Pico が読む（共通の `MON_P`/`MON_N`、LM4040 で比率校正）

- **決定**: 各娘の分圧したレールをダイオード OR でスタック共通の `MON_P`/`MON_N` に載せ、Pico の ADC で読む。**ADC0 の `DEST_ADC` を解放**して LM4040-2.5 を読み、比率で校正する。しきい値・遅延・読みの妥当性の判定はファーム
- **理由**: 娘の部品が監視 IC 案の約半分で、しきい値をファームで変えられ、読みの妥当性（張り付き・片側だけ等）を見て誤「良」の多くを検出できる
- **根拠**: [NOW] L25／[review/rail_detect_review.md](review/rail_detect_review.md) §7・§8-1（(c) を第一候補）
- **前提・外れる条件**: RP2350 の ADC はオフセット・利得・INL の規定が無く、比率校正が前提。Pico の 3V3 の公差はどの DS にも無い（V21-実測-04）。`DEST_ADC` は v2 で位置センスラダーを廃止した後の空きで、ファームは読んでいない（[NOW] L208）。Pico 2 の `AGND` の扱いは Pico 2 の DS で確かめる（リポジトリに無い）（[review/rail_detect_review.md](review/rail_detect_review.md) §7.1・§10）
- **却下した案**:
  - (a) 娘ごとに窓型の監視 IC（TPS3701 ＋ TPS3808 ＋ LM4040）— 単一の不良（オープンドレインの配線の開放、基準側の抵抗の開放、LM4040 の短絡など）で誤「良」になる経路が 4 つ以上あり、TPS3808 の遅延は CT の公差込みで 9.1〜23.4 ms と 10〜20 ms に入らない。娘 1 枚で IC 約 10 個（[review/rail_detect_review.md](review/rail_detect_review.md) §3.2・§2-3・§1 表）
  - (b) Pico だけ（I²C 経由で切る）— 突然の断では EN が切れる前にレールが割れる（I²C の書き込み 0.29 ms ＋ 待ち 最大約 0.9 ms に対し 0.20 ms）。ファームが止まると何も守られない（同 §7.4・§7.5）
  - ディスクリート（ツェナー＋トランジスタ）だけで精度の層を作る — ツェナーの公差で下端 10 V を守れない（[review/rail_detect.md](review/rail_detect.md) §2.2）
- **状態**: いったんの決め（[NOW] L25）

### 5-3 `RAIL_OK` を Pico から直接（Pico が High を出している間だけ「良」）

- **決定**: Pico の空き GPIO から直接 `RAIL_OK` をスタックへ出す。**Pico が能動的に High を出している間だけ「良」**（外付けプルダウン）。娘の上で EN の許可と音声 SET のゲートに AND し、立ち下がりで音声リレーをリセット。Pico のリセット・停止で全段の音声がリセットされる
- **理由**: I²C（100 kbit/s・共用）経由では突然の断に間に合わない。直結の GPIO なら EN が 0.1〜0.2 ms で切れる。既定が「不良」なのでフェイルセーフの向き
- **根拠**: [NOW] L25／[review/rail_detect_review.md](review/rail_detect_review.md) §7.4・§7.5・§9 R3
- **前提・外れる条件**: ファームがハングして High を出し続ける形は残る → §5-4 の後ろ盾で塞ぐ。BOOTSEL・デバッガの停止・起動中はウォッチドッグも助けない（同 §7.5）
- **却下した案**: 娘がオープンドレインで引き下げる PG 線 — 電源の無い娘が線を放すと既定が「良」になる向き（[review/arch_zero_base_review.md](review/arch_zero_base_review.md) §6.3-3）
- **状態**: いったんの決め（[NOW] L25）

### 5-4 精度の要らない後ろ盾（B1・B2）

- **決定**: **B1**: 音声 SET のコイル電源を、娘の ±レールがおおむねある（約 ±7 V を越える）ときだけ ON になる PMOS 越しにする（ツェナー＋トランジスタ）。どこが開放しても SET 不可に倒れる。RESET のコイル電源は常時の `+5V_COIL` のまま。**B2**: その「レールがある」信号の立ち下がりでもリセットの単安定を撃つ
- **理由**: 精度の層（§5-2）が誤「良」で固まっても、電源の無い娘の音声がバスにつながる形をハードで消せる。AZ850P2 は SET と RESET のコイルの＋端子が別ピンなので、SET 側だけをゲートできる
- **根拠**: [NOW] L25／[review/rail_detect_review.md](review/rail_detect_review.md) §3.3・§8-2／[review/arch_zero_base_review.md](review/arch_zero_base_review.md) §6.3-6
- **前提・外れる条件**: 部品の DS は未収集。TBD62083A のクランプの COMMON をどちらへ繋ぐかは要整理（同上）。B1 は §2-6（音声 SET を共通にした決定）の理由そのもの
- **却下した案**: —
- **状態**: いったんの決め（[NOW] L25）

### 5-5 レールが落ちたら音声を自動リセット、EN も切る

- **決定**: レールが落ちたら音声リレーをハードで自動リセットする。同じ信号で ch の LDO の EN も切る
- **理由**: 接点の瞬断や衝撃で電源が切れても、音声がバスにつながったまま・ミュートも掛かっていない状態が残る。EN を切らないと EN が IN を超えうる（§2-9）
- **根拠**: [NOW] L25／[review/stack_relay_power_review.md](review/stack_relay_power_review.md) 6-3（自動リセットの経路が無いという指摘）／[review/rail_detect.md](review/rail_detect.md) §0.3／[review/rail_detect_review.md](review/rail_detect_review.md) §8-1
- **前提・外れる条件**: 律速はリレーの復帰時間（AZ850 は 1 ms typ、max は DS に無い、V21-実測-05）。SET と RESET のコイル電流の重なりは µs ではなく sub-ms〜ms になりうるが、リセットパルスが長いので最後はリセットで終わる（[review/rail_detect_review.md](review/rail_detect_review.md) 2-4）。電源リレーまで自動で切るかは未決（[review/rail_detect.md](review/rail_detect.md) §0.5 D5、V21-未決-06）
- **却下した案**: —
- **状態**: いったんの決め（[NOW] L25）

### 5-6 TBD62083A は 5 V 振幅で駆動（`+5V_COIL` の AHCT を 1 段）

- **決定**: コイルドライバ TBD62083A の入力を、`+5V_COIL` で動く AHCT 系を 1 段通して 5 V 振幅にする
- **理由**: TBD62083A の出力電圧（VDS）は VIN = 5 V の条件でしか規定されていない。3.3 V 駆動で保証されるのは「100 mA で VOUT = 2 V」だけで、コイル端の電圧が感動電圧に届く保証が無い。自動リセットという安全機能がこの保証外に乗っていた
- **根拠**: [NOW] L25／[review/arch_zero_base_review.md](review/arch_zero_base_review.md) §0.2-5／[review/rail_detect_review.md](review/rail_detect_review.md) §5-1・§8-3／[sw] §3（TBD62083A）
- **前提・外れる条件**: AHCT の DS は未収集。LVC を 5 V で動かすと 3.3 V の信号を受けられない（同 §5-1）。TBD62083A は VCC ピンが無く入力電圧だけで動くので、電源の無い娘にもリセットが届く（[review/arch_zero_base_review.md](review/arch_zero_base_review.md) §6.1）
- **却下した案**: 3.3 V で直接駆動 — 上の理由（v1/v2 で動いた実績はありうるが DS の保証ではない）
- **状態**: いったんの決め（[NOW] L25）

### 5-7 ±15 V の有無を Pico へ知らせる

- **決定**: ±15 V（スタックの常時側）の有無を Pico が読めるようにし、ファームは ±15 V が無い間は電源 SET も EN も出さない
- **理由**: Pico は USB だけで動くので、主電源 OFF でも `3V3` と制御線が生きている（§2-9 の EN–IN の件）
- **根拠**: [NOW] L15／[review/main_power_compare_review.md](review/main_power_compare_review.md) §3.3
- **前提・外れる条件**: 形は未決（`MON_P`/`MON_N` で兼ねるか、親の +15 V を別に分圧して読むか）
- **却下した案**: —
- **状態**:
  - 決定: 検知線を置く（[NOW] L15）
  - 未決: 形（V21-未決-23）

---

## 6. ファームの責務

ハードが保証することと、ファームが守ることを分けて置く。ハードの後ろ盾は「ファームが間違えたときに壊さない・つながない」ためのもので、手順そのものはファームが持つ。

### 6-1 ハードが保証すること（ファームに依らない）

各行の状態は右端の項目の状態に従う。

| 何を | どうやって | 項目 |
|---|---|---|
| レールの無い娘は音声 SET できない | B1（音声 SET のコイル電源をレールでゲート） | §5-4 |
| レールが落ちたら音声リセット、EN 切り | B2 と `RAIL_OK` の立ち下がりで単安定 → RESET コイル。EN の許可にも AND | §5-4・§5-5 |
| Pico が止まったら全段の音声リセット | `RAIL_OK` は Pico が High を出している間だけ良 | §5-3 |
| 電源の無い娘にもリセットが届く | コイル電源と全リセットは常時系統、TBD62083A は VCC 無し | §2-1・§5-6 |
| EN が LDO の IN を超えない | EN の論理を娘の切られたレールから | §2-9 |
| 娘の中で同時に ON は 1 ch まで、既定 OFF | デコーダ | §2-9 |
| 切ったノードが浮かない | NC 抵抗 → GND、`TONE` バスに 100 kΩ | §2-3・§2-11 |
| 極間短絡で ±15 V を直結しない | 22 Ω を NO 側、溶断型 | §2-4 |

### 6-2 ファームが守ること

- **厳密に 1 ch**: 全 OFF → 1 ch ON。温めておく ch は作らない（§1-2）。状態: 決定
- **切替の手順（娘をまたぐとき）**: ミュート → **全リセット（全娘の音声リレーと電源リレー。音声が先・電源が後、例: ARST → 20 ms → PRST）** → 選んだ娘の電源 SET → レール良好（立ち上がりのしきい値 ＋ 遅延）→ ch 選択 → 整定待ち → **共通の音声 SET** → ミュート解除（[review/arch_zero_base_review.md](review/arch_zero_base_review.md) §6.3-9、[review/stack_relay_power_review.md](review/stack_relay_power_review.md) 6-1）。状態: 決定（全リセットから始め、音声 SET をこの中でだけ出す: §2-6）／いったんの決め（音声を先・電源を後の順: §2-7）
- **音声 SET の規則**: 音声 SET は、上の「全リセット → 電源 SET → レール良好 → 共通の音声 SET」の 1 つの手順の中でだけ出す。それ以外で音声 SET を出さない（§2-6）。状態: 決定（ユーザー判断 2026-09-25）
- **同じ娘の中で ch を変えるとき**: ミュート → ch を全 OFF → 番地 → ch を ON（TMUX と LDO の EN が同時に切り替わる）→ LDO の立ち上がり（CNR 10 nF で正側 14 ms・負側 9 ms、[pow] §2・§3）＋整定待ち → ミュート解除。境目のリレーは動かさない（[review/arch_zero_base_review.md](review/arch_zero_base_review.md) §6.3-9）。状態: 未決（推奨。[NOW] に無い）
- **パルス幅**: コイルのパルスは 20 ms 以上（Panasonic の「セット・リセット時間の 5 倍以上」、AZ850 の typ 2 ms の 10 倍）。SET と RESET のコイルに同時に電圧を加えない（[review/stack_relay_power.md](review/stack_relay_power.md) §6、[review/stack_relay_power_review.md](review/stack_relay_power_review.md) 8-1、[bnd] §3.3 TQ）。状態: 未決（推奨。[NOW] に無い、V21-未決-24）
- **EN を上げる条件**: ±15 V があることを確かめてから（主電源スイッチ OFF で Pico が USB だけで動いているときに EN を上げない）（§2-9・§5-7、[review/main_power_compare_review.md](review/main_power_compare_review.md) 1-6）。状態: 決定（§5-7）
- **レール監視**: `MON_P`/`MON_N` を読み、LM4040 を ADC0 で読んで比率校正。しきい値（案: 約 ±12 V / 約 ±10.5 V）と遅延をファームで持つ。張り付き・片側だけなどの妥当性を見る。`RAIL_OK` は能動的に High を出し、異常では落とす（§5-1〜§5-3）。状態: いったんの決め
- **迷惑トリップを無限に再試行しない**（誤「不良」で EN 切り → 回復 → 良 → EN → 落ち込み…を繰り返しうる）（[review/rail_detect_review.md](review/rail_detect_review.md) §3.1）。状態: 未決（推奨）
- **電源投入時**: 全リセットから始める（ラッチングリレーは停電前・衝撃の状態を保持しうる、§2-1）。PT2314E には電源投入後 50 ms は I²C を送らない（v2 の「電源投入後 Td ≈ 50 ms は叩かない」、[sw] §5）。PT2314E の I²C は 100 kbit/s（3.3 V ロジック × VDD 9 V で Standard）。状態: 決定（全リセット: §2-1）／v2 から引き継ぎ（PT2314E）
- **運用**: 娘は電源を切ってから抜き挿しする。挿したら起動し直す（起動時の全リセットで前歴を消す。セットのまま外した娘を電源の入った箱へ挿すと、音声が前歴のままバスにつながり、起動時のリセットは走らない）（[review/stack_relay_power_review.md](review/stack_relay_power_review.md) §3 (e)）。状態: 未決（推奨、V21-未決-25）
- **待ち時間の目安**: ch の入力結合の整定は 5τ で 0.5 s 級。ミュートの長さは τ の取り方で変わる（§2-10 の前提）。状態: 未決（V21-未決-01、V21-実測-12）

---

## 7. v2 から引き継ぐもの

v2 から引き継いだ決定。どれも状態は「**v2 から引き継ぎ（v2.1 で再考していない）**」— v2 で決めたことを、v2.1 の前提で見直さずにそのまま持っている。
どれを引き継ぐかは棚卸し（[audit_1](review/decisions_audit_1.md)・[_review](review/decisions_audit_1_review.md)／[audit_2](review/decisions_audit_2.md)・[_review](review/decisions_audit_2_review.md)／[audit_3](review/decisions_audit_3.md)・[_review](review/decisions_audit_3_review.md)）の「維持」から選んだ。「前提変更」で原則だけ引き継ぐものはそう書いた。
棚卸しの行番号は [review/README.md](review/README.md) の基準（`5d2cd25` 時点の v2.1）で読む。**v2 の決定ログは読まない。** ここに書いていない v2 の決定は、v2.1 の決定ではない。

### 7-1 UI・操作

- **V21-継-01 エンコーダ ×3（CH / BASS / TREBLE）**
  - 決定: EC11 系・押し SW 付き ×3。回して候補、押して確定。CH の確定で入るのは入力切替と ch LDO の EN（§2-8）
  - 理由: 操作は v2.1 で変えない。音量と DEST は物理操作子なのでエンコーダに載せない
  - 出典: `FrontPanel.kicad_sch`（ENC）、[datasheets/RotaryEncoder_EC11_generic.md](datasheets/RotaryEncoder_EC11_generic.md)
  - 状態: v2 から引き継ぎ（v2.1 で再考していない）
- **V21-継-02 音量は Amp の後の手回し A50k デュアル ×2（HP / LINE 独立）。IC にしない**
  - 決定: PGA2310・digipot は信号経路に入れない。音量は LCD に出さない
  - 理由: 遠隔操作が要らないので音量 IC を入れる理由が無い（UI・コスト・SNR）。「±5 V で振幅が足りない」は振幅の上限の話で、専用電源を足しても解けない
  - 出典: `FrontPanel.kicad_sch`、[datasheets/TI_PGA2310.pdf](datasheets/TI_PGA2310.pdf)（却下した側）、[PARTS.md](PARTS.md) §2.2（ポット）
  - 状態: v2 から引き継ぎ（v2.1 で再考していない）
- **V21-継-03 出力段: PHONE はユニティバッファ、LINE はポット直出し、ゲインは付けない**
  - 決定: HP のバッファは OPA1652（DIP-8 ソケット）、LINE はバッファ無し。バッファは全 ch に共通に掛かるので、1 回の比較の中では差し替えない
  - 理由: ワイパー（最大 12.5 kΩ）では 64〜120 Ω を駆動できない。LINE の相手はアクティブスピーカー。つなぐ実機（HD 560S 120 Ω・Cloud III 64 Ω）では出力は足りないのでなく過剰で、ゲインを足すとポットの使用域が下端に寄る
  - 出典: [ds_facts/opamps.md](ds_facts/opamps.md) §8（OPA1652 の出力 ±30 mA、p1）、[datasheets/opamps/TI_OPA1652.pdf](datasheets/opamps/TI_OPA1652.pdf)、[PARTS.md](PARTS.md) §0a
  - 状態: v2 から引き継ぎ（v2.1 で再考していない）
- **V21-継-04 DEST は機械スイッチ。リレーは使わない**
  - 決定: DPDT ON–ON 1 本で PHONE↔LINE。MUTE 位置と位置センスのラダーは無い（電源断は PWR SW）
  - 理由: 出口はユーザーが手で選ぶもので、ファームが知る必要が無い。音声経路の接点が増えない
  - 出典: `FrontPanel.kicad_sch`
  - 状態: v2 から引き継ぎ（v2.1 で再考していない）
- **V21-継-05 トーンは PT2314E。`DGND` はチップの足元で `A_GND`。I²C 境界は BSS138 ×2 のレベルシフタ**
  - 決定: Bass/Treble だけ使い、音量は 0 dB 固定。ch 選択の前に置き、全 ch に配る。PT 側のプルアップは `VCC_TONE`（9 V）へ
  - 理由: 無印 PT2314 は買えない（E はピン・外付け網とも同じ）。PT2314E の VIH min 3.0 V に 3.3 V のプルアップでは余裕 0.3 V しか無い。P82B96 は Sx 側の VOL 0.8〜1.0 V が PT2314E の VIL max 1.0 V・RP2350 の VIL 0.8 V を食い切る（`PCA9306` 等の見送りも成立）
  - 出典: [ds_facts/switch_control.md](ds_facts/switch_control.md) §5（PT2314E の VIL/VIH、p12）、[datasheets/Princeton_PT2314E.pdf](datasheets/Princeton_PT2314E.pdf)、[datasheets/RaspberryPi_RP2350.pdf](datasheets/RaspberryPi_RP2350.pdf)。P82B96 の DS はリポジトリに無い（v2 で読んだ値）
  - 状態: v2 から引き継ぎ（v2.1 で再考していない）
- **V21-継-06 HP の固定パッドは付けない（0 Ω）。DNP で後から付けられる足場**
  - 理由: ソケットは ±12 V（§3-3）で、固定 −20 dB は過剰
  - 出典: ルート回路図の HP 経路
  - 状態: v2 から引き継ぎ（v2.1 で再考していない）

### 7-2 計測（Q1 の土台）

- **V21-継-07 計測タップの「+」側にユニティバッファ**
  - 理由: 無いとバスから見た負荷が重くなり、TMUX7612 の H3 が悪くなる
  - 出典: `MeasureControl.kicad_sch`、[ds_facts/tap.md](ds_facts/tap.md)、[review/tap_facts.md](review/tap_facts.md) §2、[datasheets/opamps/TI_OPA1656.pdf](datasheets/opamps/TI_OPA1656.pdf)
  - 状態: v2 から引き継ぎ（v2.1 で再考していない）
- **V21-継-08 ADC 前段の入力抵抗 6.19 k（PT2314E 経路について）**
  - 理由: PT2314E の VOMAX typ 2.6 Vrms × Amp ゲイン 2 を ADC のフルスケールに入れる（ヘッドルームの不足を直した）。LPF の極は変えない。DIRECT の振幅は V21-未決-14
  - 出典: [ds_facts/switch_control.md](ds_facts/switch_control.md) §5（PT2314E の VOMAX）、[datasheets/TI_PCM1804.pdf](datasheets/TI_PCM1804.pdf)、`MeasureControl.kicad_sch`
  - 状態: v2 から引き継ぎ（v2.1 で再考していない）
- **V21-継-09 `MCLK_SENSE` は無い**
  - 理由: ファームが読んでいない。12.288 MHz がグランドの境目を渡る経路が一本減る
  - 出典: `MeasureControl.kicad_sch`、`firmware/board.py`
  - 状態: v2 から引き継ぎ（v2.1 で再考していない）
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

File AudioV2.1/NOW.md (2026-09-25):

# AudioV2.1 — いま（現況）

**更新:** 2026-09-25  
v2.1 は 2026-09-25 に v2 の図・PCB・スクリプトを全部写して始めた。**回路図と PCB はまだ写したときのまま**（下の「図と PCB の現況」はその状態）。
v2.1 の決まりごと・検証の期待値は [CLAUDE.md](CLAUDE.md)。`kicad-run.sh erc` の既定は v2 なので、v2.1 は `kicad-run.sh erc AudioV2.1/AudioV2Case.kicad_sch` と明示する。

**v2.1 の決定（2026-09-25・未実装）** — 一覧・理由・状態（決定／いったんの決め／未決）の正は [DECISIONS.md](DECISIONS.md)。ここは要旨だけ:
- **根本**: 選んだ 1 ch だけ電源と入力を生かす（コールドスタンバイ、同時に生かすのは厳密に 1 ch）。娘は 1 種類・1 枚 4 ch・縦積み — DECISIONS §1
- **制御の木**: 1 段目＝各娘の電源用ラッチングリレー（±15 V を DPDT 1 個、22 Ω ヒューズ抵抗を NO 側）→ レール良好 → 音声用ラッチングリレー（DPDT 2 個）。2 段目＝娘の中は TMUX7612 で ch を選び、選んだ ch の石だけ ch ごとの LDO（±12 V）の EN で給電。EN は娘の切られたレールから作る。音声 SET は全段共通 1 本（全リセットから始まる一続きの手順の中でだけ出す）。スタックのコネクタは 2×12 — §2
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

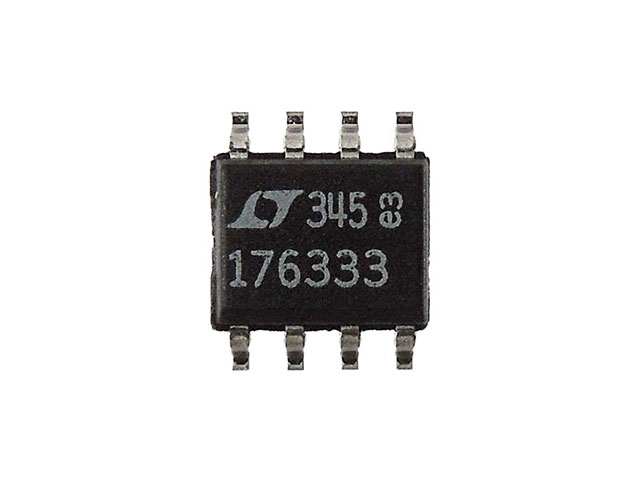
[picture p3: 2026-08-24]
tmp_lt1763_ref/akizuki_L.jpg

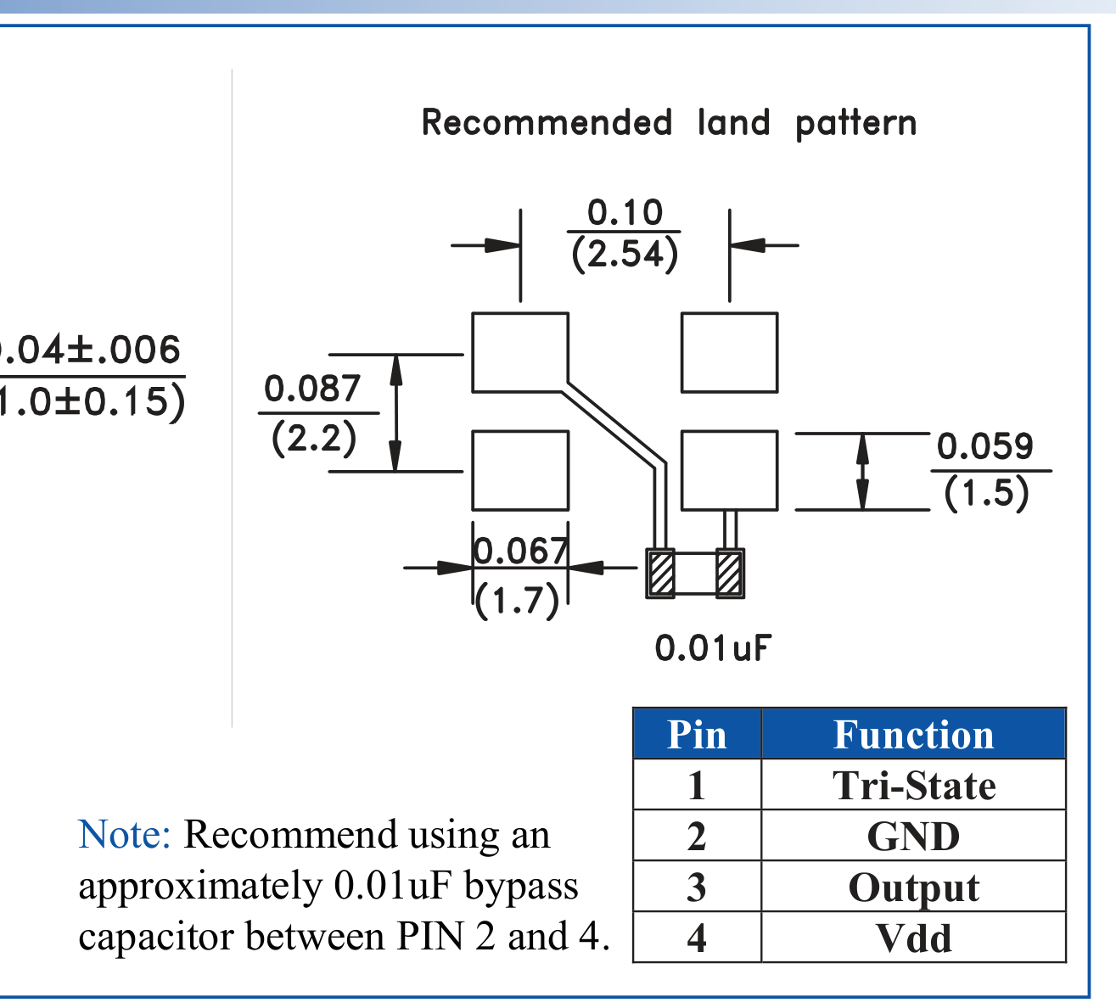
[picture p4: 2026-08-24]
tmp_asfl1_ref/crop_C.png

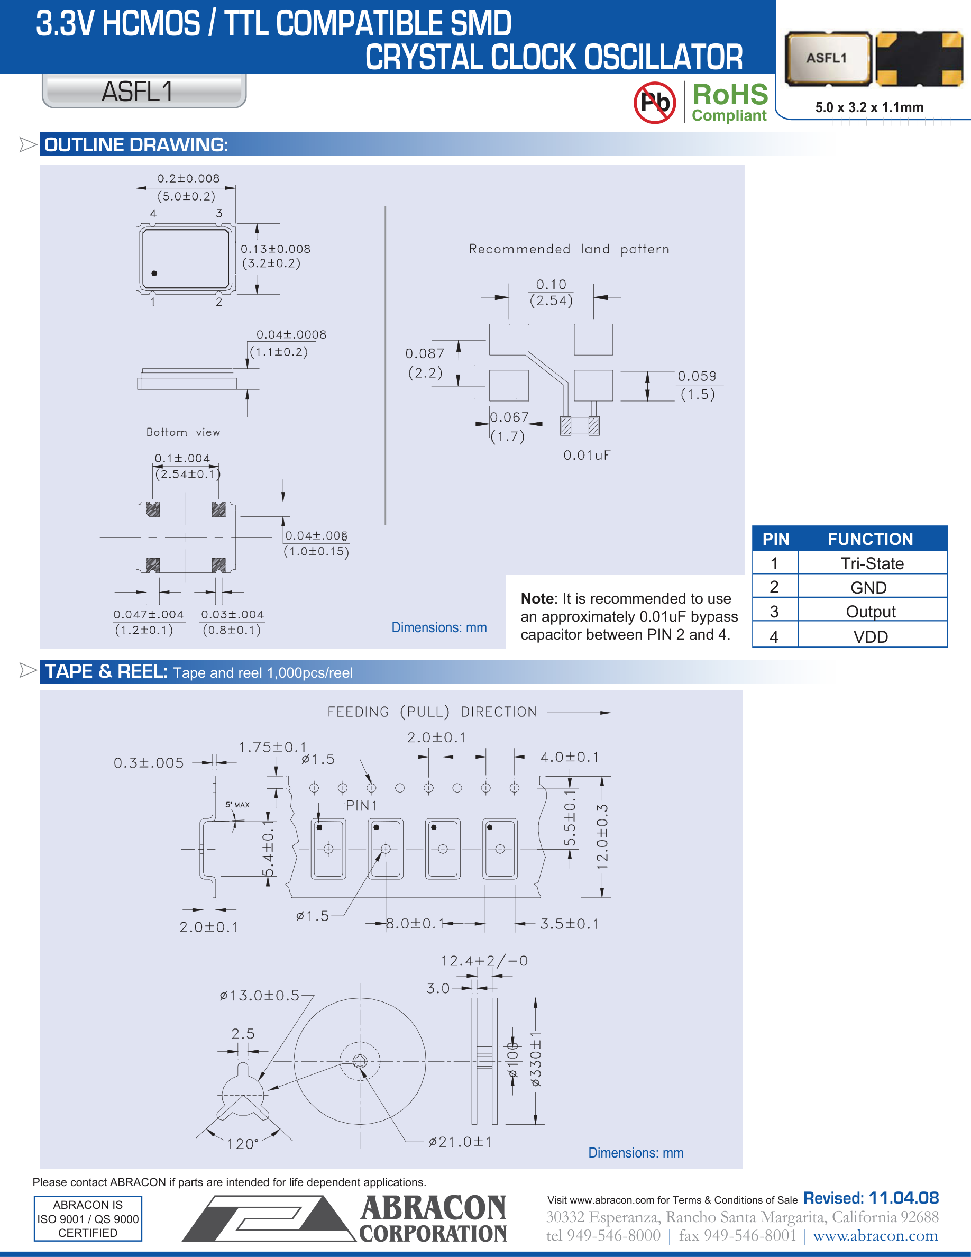
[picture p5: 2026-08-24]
tmp_asfl1_ref/octo_outline.png

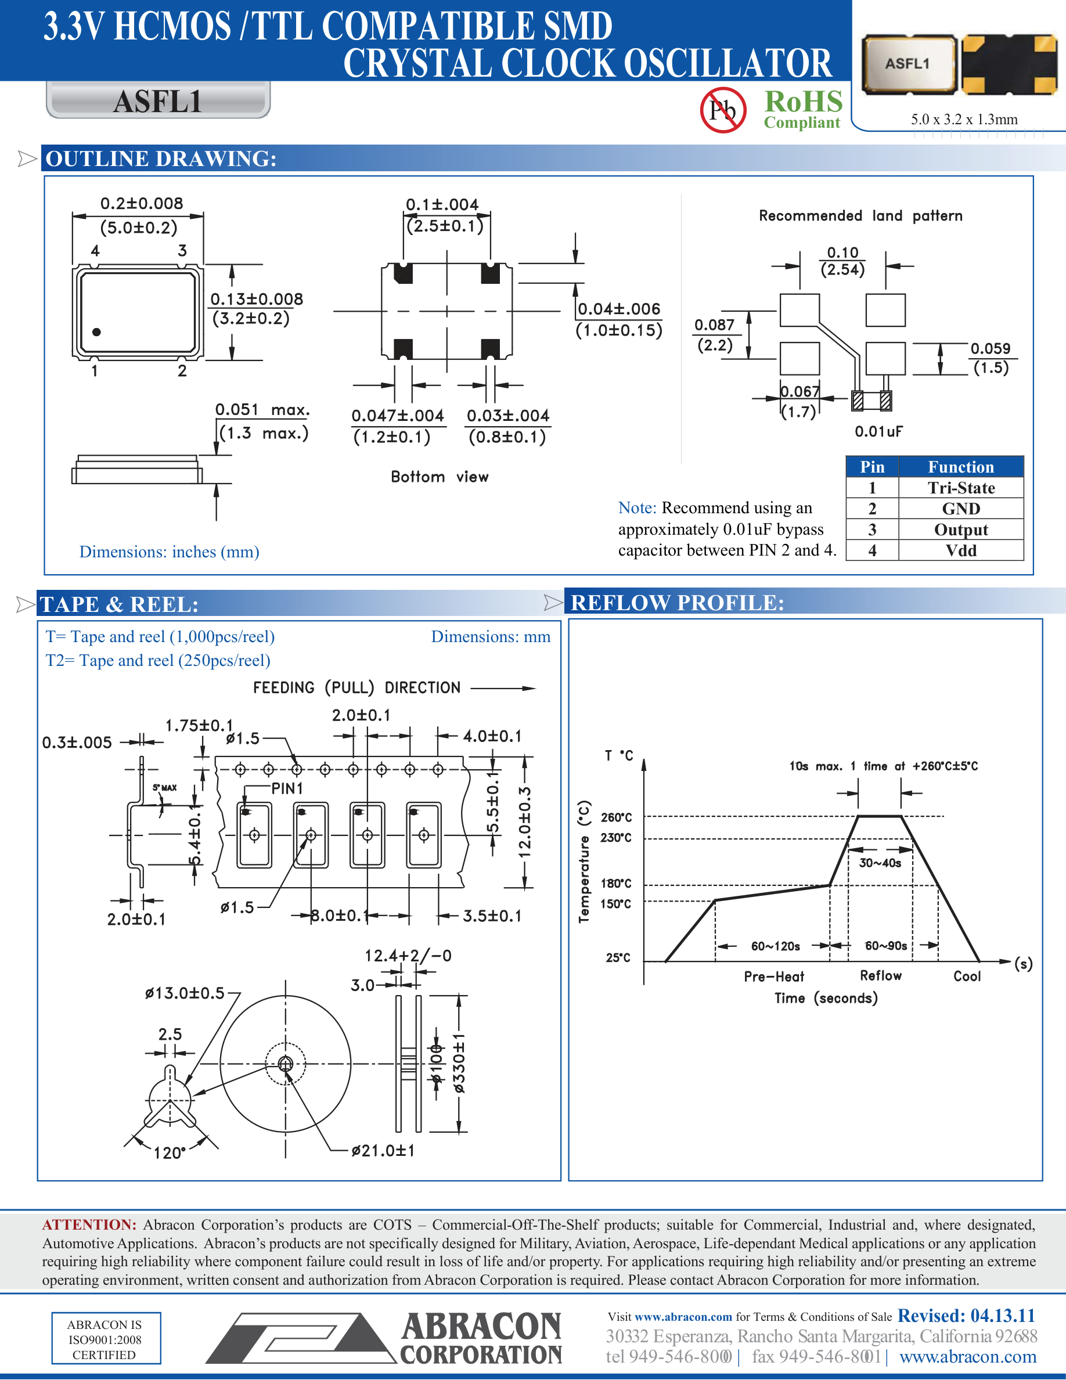
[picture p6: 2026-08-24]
tmp_asfl1_ref/ds_p2.png

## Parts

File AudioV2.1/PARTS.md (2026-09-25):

# AudioV2.1 品番（回路から決めた第一候補）

**目的:** 回路が要求する電気・機械条件から型番を決める。在庫は変動するので **機能等価の代替** を併記する。
決定とその理由は [DECISIONS.md](DECISIONS.md)。ここは品番・調達・実装の置き場。

**実装の型:** RV / SW_DEST / ENC / PWR SW は **パネル実装**（操作系は FrontPanel 子基板に集約）。

> **この文書の読み方 — どこが生成で、どこが手書きか**
>
> `<!-- BEGIN GENERATED: ... -->` 〜 `<!-- END GENERATED: ... -->` で囲まれたブロックは
> **回路図から自動生成**したもの（§4.1 の部品表）。
> **手で編集しても次の再生成で消える。** 直すときは KiCad の回路図側を直して再生成する。
>
> それ以外はすべて**手書きで、こちらが正**。調達先・代替品・選定理由など、**回路図から導出できない情報**を置く場所。
> 手書きの部分は 2026-09-25 の図（v2 から写した状態）に合わせてある。v2.1 の変更（RS6・リレー・LDO など）を図に入れたら、品番もここへ足す。
>
> ```bash
> python3 AudioV2.1/scripts/gen_parts_bom.py          # 再生成して埋め込み直す
> python3 AudioV2.1/scripts/gen_parts_bom.py --check  # 実図とズレていれば非ゼロ終了（検査のみ）
> ```

---

## 0a. 何を繋ぐか（**2026-09-06 確定。バッファの設計はここで決まる**）

**出力段の設計は「先に何を繋ぐか」で決まる**のに、それがどこにも書かれていなかった。ユーザー確定分:

| 出口 | 繋ぐもの | 公称仕様 | 出典 |
|---|---|---|---|
| **PHONE** | **Sennheiser HD 560S** | **120 Ω** / 110 dB SPL/V @1 kHz | メーカー公称（**二次情報**。データシート PDF ではない） |
| **PHONE** | **HyperX Cloud III** | **64 Ω** / 100 dB SPL/mW @1 kHz | 同上 |
| **LINE** | **IK Multimedia iLoud Micro Monitor** | RCA 不平衡 ＋ TRS 1/8" 平衡。**⚠ 入力インピーダンスと入力感度はメーカーが公表していない**（仕様ページは出力特性のみ） | メーカー仕様ページ |

**⚠ 32 Ω 級は無い。** 「32 Ω の低能率を駆動する」という前提で部品を選ばないこと
（v1 の `NJM4556A` 70 mA 級はその前提で選ばれたと思われる）。

**⚠ `iLoud` の入力インピーダンスが不明なのは、ライン出力バッファの要否に直結する。**
`A50k` ポットのワイパーは電気的中点で `Zout` 最大 12.5 kΩ。負荷による追加損失は
**10 kΩ で −7.0 dB / 20 kΩ で −4.2 dB / 47 kΩ で −2.1 dB**（`600 Ω` なら −26.8 dB）。
**アクティブモニタの RCA は 10〜47 kΩ 級が普通**なので、**この範囲なら「損失」ではなく
「A カーブが崩れてつまみの位置が変わる」だけ**で、上に 10 dB 以上の余裕がある以上、実害は小さい。
**測定用途で「つまみを動かすと 20 kHz の応答が動く」ことを嫌うなら、バッファを入れる理由になる。**

---

## 0b. ベンダのデータを読むときの罠（実際に踏んだもの）

価格・在庫は変動するので**スナップショットは残さない**。代わりに読み方を残す。
すべて 2026-09-02 の DC-DC 選定（v2 のとき）で実際に踏んだもの。

| 罠 | どうする |
|---|---|
| **通貨単位** | 当時の価格表が **¥ と $ を取り違えていた**（`¥9.98` と書かれた値の実体は **¥1,581**）。桁が3つ違っても表の中では気づかない。**通貨を明示していない数字を比較に使わない** |
| **MOQ（最小注文数量）** | `UnitPrice` だけで並べると**順位を間違える**。MOQ 19（チューブ）の品は単価最安でも実際に払うのは 19 個分。**「最低購入額 = 単価 × MOQ」で並べる**。API では `ProductVariations[].MinimumOrderQuantity` |
| **包装で品番が分かれる** | 同じ石でもカットテープ / テープ&リール / Digi-Reel で別品番になり、**テープ&リールは MOQ 3000・在庫0**、Digi-Reel は別途リール手数料。**買うのはカットテープ（`...CT-ND`）** |
| **入手性フィールド** | **DigiKey API の入手性フィールドは信用できない**（`AM10TW` で判明。正規ルートから消えているのに在庫ありに見えた）。在庫の判断は実ページで確認する。**⚠ ただし実ページが見られない環境では下の「販売元」を使う** |
| **販売元（Marketplace か直販か）** | **`ProductUrl` のスラグが `Manufacturer.Name` と食い違ったら Marketplace 出品**。DigiKey の商品 URL は `/products/detail/<メーカのスラグ>/<型番>/<id>` なので、両者は普通一致する。**2026-09-05 に 1023 件で試したら不一致は `aimtec → dcomponents` の 25 件だけで、うち 22 件が `BackOrderNotAllowed=True`。** 記録にある `AM10TW` の在庫誤認はこれ —— **在庫を持っていたのは DigiKey ではなく出品者**だった。`MarketPlace` フィールド自体は `None` を返すので役に立たない。**`www.digikey.com` が塞がっている環境でも、この判別は API だけでできる** |
| **`ProductStatus`** | **「新規設計向けに不適合」(NFND) は候補から即落とす。** 性能で比べる前に見ること。2026-09-05 の再探索では `URA2412ZP-10WR3`（Mornsun）と `PYBE10-Q24-D12`（Bel）がこれで、**どちらも `NormallyStocking=False` かつ `BackOrderNotAllowed=True`**。データシートを読む手間ごと省ける |
| **属性 vs データシート** | DigiKey の属性が**データシートと矛盾する**ことがある（`REC10K` の絶縁は属性 3 kV / DS は **1.6 kVDC**）。**データシートを正とする** |
| **足切りは価格ではない** | DC-DC の決め手は価格ではなく **最大容量負荷 Cout** だった。**回路が課す制約（§0）で先に落とす**、価格で並べるのはその後 |

探索そのものは [`scripts/dcdc_survey.py`](scripts/dcdc_survey.py) / [`scripts/digikey_search.py`](scripts/digikey_search.py) で再実行できる。
**ライブ API を叩くので結果は当時と変わる** — 変わってよい。固定したいのは上の読み方だけ。

---

## 0c. 受動部品の調達クラス（PRECISION / MATCH / SPEC）— [issue #38](https://github.com/indare/pcb_work/issues/38)

この箱はオペアンプ以外の部品差が比較結果へ混入しないことが大事。
**高価な部品を目的にしない。** 比較チャネル間の再現性・対称性を優先する。

| クラス | やり方 | いつ使う |
|---|---|---|
| **PRECISION** | メーカ公差で性能を保証。個体選別はしない | 公差がそのままチャネル差になる抵抗など。低コストで 0.1% が買えるとき |
| **MATCH** | 同一シリーズを必要数より多く買い、LCR で実測選別 | 公称公差が ±5〜20% でも個体差が大きいコンデンサなど。「公称に近い」より「互いが近い」 |
| **SPEC** | 回路上必要な仕様を満たせば個体選別しない | デカップ・電源バルク・プルアップ／プルダウン・LED 抵抗など |

計測器は **周波数指定できる LCR メータ**（例: DER EE DE-5000）。TC-1 は選別の主器にしない。
必要なら ZT-703S＋正弦波で実回路の周波数応答を確認する。

### PRECISION（確定）

| 役割 | 値 | 方針 |
|---|---|---|
| AmpChannel `Rf` / `Rg` | **20 kΩ 0.1%**（薄膜、図上 Value も `20k 0.1%`） | ch 間ゲインの支配項。1%→0.174 dB、0.1%→0.017 dB。候補例: Susumu `RG2012` 系（FP は図の 0805）。ADC 前段の 0.1% と同じクラス |
| ADC 前段抵抗 | 既に図上 `… 0.1%` | 据え置き |

### MATCH（確定）

同一ロット／同一シリーズを多めに買い、**同一測定周波数**で C（必要なら ESR / D）を揃える。
絶対値より個体間一致を優先。目安: 必要数の **2〜3 倍**を買い、近い個体を実装。

| 役割 | シリーズ／条件 | 選別 |
|---|---|---|
| AmpChannel 入力カップリング **1 µF film** | **PET（MKT）・P5**。採用: TDK `B32529C0105J000`。FP は図どおり L7.2/W4.5/P5。PP は歪み差が見えず巨大になるので採らない（v2 で決めた） | C 一次 → D/ESR 二次確認 |
| AmpChannel 出力カップリング **2.2 µF film** | 同系統 TDK `B32529D0225…`（P5）。FP は L7.2/W7.2/P5。公称 ±5〜10% で足りるが、**低域カットオフ差は容量差そのもの**なので選別する | 同上 |
| ADC LPF **1.8 nF C0G** | C0G/NP0・1206。公称 ±5% 級を買い、**ch / L/R で C を揃える** | C @ 同一周波数 |
| HP 出力 **470 µF NP** | Muse ES `UES1E471MHM` 想定（Ø16/P7.5）。**L/R をペア選別** | C + ESR |
| ADC 信号経路の **10 µF NP** | 左右対称が目的のカップリング | C で L/R を揃える |

### SPEC（据え置き）

100 nF デカップ、電源バルク、プルアップ／プルダウン、LED 抵抗など。
耐圧・ESR・寿命・温度など、用途ごとのデータシート条件を優先。個体選別しない。

---

## 2. パネル部品と周辺の第一候補

### 2.1 SW_DEST / PWR SW — **Cosland 2MD1 / 2MS1**

| | |
|---|---|
| DEST | **Cosland 2MD1**（DPDT ON–ON、秋月 104028）。PHONE↔LINE の 1 本。MUTE 位置は無い（DECISIONS `V21-継-04`） |
| PWR | **Cosland 2MS1**（秋月 100300）。片側 NC で ON–OFF として使う |
| FP | `Library:SW_Toggle_Cosland_2MD1_VS2_DPDT`／`Library:SW_Toggle_Cosland_2MS1_VS2_SPDT` |

### 2.2 RV_HP / RV_LINE — **Alps RK27112A00CF** ×2

| | |
|---|---|
| 機能 | **A（対数）50 kΩ デュアル**、カーボン、1 回転 |
| 外形 | RK27 **27 mm**、軸 φ6 × 20 mm、取付 M9 |
| 電力 | 0.05 W — 本回路の ~1 mW に対し十分 |
| ギャング誤差 | DS 目安 2 dB（-60〜0 dB）— ステレオ音量として実用 |
| 実装 | **パネル**。ポット本体はユニバーサル基板から `JST XH 6P` で FrontPanel へ（`Device:R_Potentiometer_Dual` のピン番号のまま） |
| なぜ RK097 でないか | v1 は RK097 水平実装。この箱は **ノブを主操作子**にするので 27 mm を第一にする |

**代替**

| 状況 | 内容 |
|---|---|
| RK27 欠品・高い | パネル用 **A50k デュアル**ならピン互換で可（台湾 Alpha RD901 系など）。カーブが **A** であること |
| v1 と見た目を揃える | Alps **RK097 デュアル A50k**（水平ピン）。9 mm で「目立たない」。回路は同一 |
| A100k | 可。中点 Zout が上がるので **A50k 優先** |

RK097 のカタログ現役は 10 kΩ デュアルが多く、**A50k デュアルは RK27 の方が型番が取りやすい**。

### 2.3 その他・回路上まだ曖昧だったもの

| 用途 | 第一候補 | 理由 |
|---|---|---|
| **ENC×3** | 秋月 **EC11 系・押し SW 付き**（D カット、固定足東西） | DECISIONS `V21-継-01`。PPR は CH/Bass/Treble では何周でも可。購入品の寸法で FP を切る |
| **操作 Pico** | **Raspberry Pi Pico 2**（RP2350、**W なし**、SC0915 相当） | Wi-Fi 不要。ヘッダ後付け可 |
| **LCD（スペアナ）** | **Waveshare 29318**（スイッチサイエンス [10138](https://www.switch-science.com/products/10138)） | v1 の計測器と同じ LCD。ST7796S SPI + FT6336U I²C。状態表示（CH / DEST / Bass / Treble）もここへ寄せた（OLED は無い） |
| **12 V LED** | **12 V 内蔵抵抗付き 5 mm**（緑または青、~10 mA） | 素 LED なら 680 Ω–1 kΩ |
| **DEST LED×2** | 3 mm 通常 LED（Vf≈2 V）+ 既存 **1 kΩ** | 3.3 V で ~1.3 mA。暗ければ 330 Ω に落とす |
| **AZ850** | **AZ850P2-5**（秋月 118017） | コイル **5 V** / 125 Ω / ~40 mA。`TBD62083APG` + BP5293-50 と一致。**12 V コイルは使わない**。電源は母板の `BP5293-50` が `PD_12V_SW` から作る **`+5V_COIL`** で、帰路は専用の `GND_COIL`（`NT101` で1点結合）。娘基板側に 100 µF + 100 nF のローカルバイパスがあるので、パルスとフライバックは娘基板内で閉じる |
| **MCP23017** | **`MCP23017-E/SP`**（DIP-28） | UI 側は 0x22。娘の番地はジャンパ（今の図の形。v2.1 で娘の MCP を残すかは V21-未決-03）。**個数は回路図から導出できるので §4.1 の部品表を見る** |
| **DIP-28 ソケット** | **板バネ（dual-wipe）型**、28 pos / 行間隔 0.300"（7.62 mm） | 挿さるのは `MCP23017` だけ＝ I²C のデジタルなので接触抵抗も歪みも効かない。品番は発注時（DECISIONS `V21-継-12`） |
| **リレードライバ** | **`TBD62083APG`**（DIP-18。`ULN2803` とピン互換） | **`ULN2803` は不採用**（D24）。ダーリントンの約 1 V 降下では 40 ℃ 超で `AZ850` の Must Operate を満たさない。DMOS なら 40 mA で 0.13 V |
| **PT2314E** | **PT2314E SOP-28 300 mil**（回路値 `PT2314E`） | 無印 DIP は入手不可。2026-09-07 に E へ確定（DECISIONS `V21-継-05`） |
| **+9 V LDO** | **ST `L7809CV`**（TO-220） | 入力は **+15 V**（`U202.1 → /+15V`）。PT2314 typ 30 mA → 散逸 **(15−9)×30 mA ≈ 0.18 W**。TO-220 なら放熱器なしで余裕。⚠ TI の `LM78xx` は廃番系なので**回路図の Value も `L7809CV` に揃えてある**（KiCad のシンボル名 `Regulator_Linear:LM7809_TO220` は 78xx 共通の型で、そのまま使える）。**⚠ 2026-09-05 に予備として `NJM7809FA`（Nisshinbo/JRC）を購入。これは `TO-220F`（フルモールド）で `L7809CV` の `TO-220` とは別パッケージ。** ピン配置は同じ（1=IN / 2=GND / 3=OUT）だが、**フットプリントは `TO-220F-3_Vertical` に差し替えが要る**。タブが絶縁されているのでシャーシへ直付けするなら絶縁ワッシャが不要という利点はある。散逸 0.18 W なので放熱はどちらでも問題にならない。**実装に使うと決めるまで回路図は `L7809CV` のまま置く** |
| **一次ヒューズ**（PD 入力〜DC-DC 間） | **5×20 mm `F2 A` 速断**（ガラス管＋ホルダ。**ホルダは Schurter OGN `0031.8201`**。中身は秋月 `MF51NR 250V2A` や Littelfuse `0217.002` 系）**確定 2026-09-04、ホルダ 2026-09-09、定格・特性は 2026-09-09 に T1.6A スロー→F2A 速断（入手性＋2Aなら突入猶予は要らない）** | 想定 0.75〜1.00 A に対し余裕。`REC20K` 全能力 1.89 A では定格付近。旧 `T3.15 A` は PD 能力全域で切れず実質「保護なし」だった（DECISIONS `V21-継-13`）。v2.1 での見直しは V21-未決-16 |
| **各コンバータ手前のリセッタブル** | **PPTC** — `+5V_D` に **0.5 A** / `+5V_COIL` に **0.40 A**（0.35 A の品が無い。2026-09-09） / `+9V` に **0.1 A**（I_hold）**確定 2026-09-04**。**型番 2026-09-09: Littelfuse `RXEF050` / `RXEF040` / `RXEF010`（Bourns `MF-R050` / `MF-R040` / `MF-R010` も同寸で可）、FP は `Library:PPTC_Radial_D7.9mm_T3.1mm_P5.08mm`（自作。DigiKey 寸法から）** | 立ち上げ中はプローブを当てるので自己復帰品にする（一発品だと外して交換になる）。**2026-09-06 に全枝が回路図へ入った**。v2.1 では ADC 枝に PPTC を新設し、コイル枝の値を選び直す（DECISIONS §3-8・§4-5） |
| **BP5293** | **BP5293-50**（秋月 111188） | v1 と同じ +5 V |
| **PD 給電モジュール** | **ストロベリーリナックス `50224`**（CH224K。DS: [`datasheets/StrawberryLinux_CH224K_manual.pdf`](datasheets/StrawberryLinux_CH224K_manual.pdf)） | **外付けモジュールとして使う。** 板上に USB-C / CH224K チップは載せず、受けの端子（`PD module in`）で 12 V を受ける。**部品は当初と同じで、変わったのは実装形態だけ**（基板内蔵 → 外付け、2026-09-04 訂正）。12 V/15 V のジャンパはモジュール側 |
| **PD 供給元（AC アダプタ）** | **UGREEN 卓上急速充電器 200 W Type-C 6C2A 8ポート PPS** | 手持ちの実機。⚠ **多ポート充電器は総出力を分配する**ので、他ポートに何を挿すかでネゴシエートされるプロファイルが変わりうる。**12 V 固定が出るかは実機で確認する**（多ポート品は 5/9/15/20 V のみで 12 V を持たない機種がある）。v2.1 は PD 12 V 固定（DECISIONS §3-2）。**実機は 2026-09-04 の実測で 15 V が入っていた** |

---

## 4. 部品表と実装メモ

### 4.1 部品表（回路図から自動生成）

> **1つ目の表が発注数の正。** 階層ルートの `AudioV2Case.kicad_sch` から取っているので、
> `AmpChannel` のインスタンス別参照上書きまで解決されている。
>
> **娘基板シートを単体で export してはいけない。** `AmpBankSwitch` / `AmpBankRelay` を
> ルートとして渡すと kicad-cli は上書きを解決できず、**1ch 分の値しか出ない**。2つ目の表は「1ch に何が要るか」を
> 見るためのテンプレートで、**発注数の根拠にはならない**。
>
> 1つ目の表の部品総数がネットリストの部品数より少ないのは、NetTie が BOM 対象外
> だから（差は NetTie の個数ぶん）。NetTie は基板上の銅箔で、買う部品ではない。
> KiCad 標準 `Device:NetTie_2` の既定も `in_bom=no`。

<!-- BEGIN GENERATED: case-bom -->
**AudioV2 全体部品表（母板 + 娘基板 + 計測 + 親）** — 下の表は `AudioV2.1/AudioV2Case.kicad_sch` から自動生成しています。
**手で編集しないでください**（次の再生成で消えます）。値・フットプリント・役割を直すときは KiCad の回路図側を直し、
`python3 AudioV2.1/scripts/gen_parts_bom.py` で再生成します。

行数 105 / 部品総数 351。

> `Refs` 列と `Value` / `Role` 列に**位置の対応はありません**。kicad-cli はグループ内の値を重複除去してアルファベット順に並べるため、「n 番目の参照 = n 番目の役割」とは読めません。

| Refs | Value | Footprint | Qty | Role |
|---|---|---|---|---|
| A1601 | ADC1804_F_MODULE | `Library:ADC1804_F_KYOHRITSU_56x33mm` | 1 | 共立 ADC1804_F PCM1804 module — Library:ADC1804_F_KYOHRITSU_56x33mm (measured) |
| A1602 | Pico2 | `Module:RaspberryPi_Pico_Common_THT` | 1 |  |
| AMP601,AMP701,AMP801,AMP901,AMP1001,AMP1101,AMP1201,AMP1301 | NE5532 / DIP-8 compatible | `Package_DIP:DIP-8_W7.62mm_Socket` | 8 | Socketed dual op amp under test |
| C201,C205,C207 | 47u | `Capacitor_THT:CP_Radial_D8.0mm_P3.50mm` | 3 |  |
| C202,C204,C206,C208,C402 | 0.1u | `Capacitor_SMD:C_1206_3216Metric_Pad1.33x1.80mm_HandSolder` | 5 |  |
| C203 | 10u | `Capacitor_THT:CP_Radial_D5.0mm_P2.00mm` | 1 |  |
| C311,C312,C313,C314,C322,C_IO301,C_IO302 | 100nF | `Capacitor_SMD:C_0603_1608Metric_Pad1.08x0.95mm_HandSolder` | 7 |  |
| C315,C316,C317,C318 | 1uF 50V X7R | `Capacitor_SMD:C_0603_1608Metric_Pad1.08x0.95mm_HandSolder` | 4 |  |
| C321 | 100uF 25V | `Capacitor_SMD:CP_Elec_10x12.6` | 1 |  |
| C401 | 22u | `Capacitor_THT:CP_Radial_D6.3mm_P2.50mm` | 1 |  |
| C403,C404,C410,C411 | 100n | `Capacitor_SMD:C_1206_3216Metric_Pad1.33x1.80mm_HandSolder` | 4 |  |
| C405,C406,C407,C409 | 2.2u | `Capacitor_THT:C_Rect_L7.2mm_W2.5mm_P5.00mm_FKS2_FKP2_MKS2_MKP2` | 4 |  |
| C408,C412 | 2.7n | `Capacitor_SMD:C_1206_3216Metric_Pad1.33x1.80mm_HandSolder` | 2 |  |
| C501,C502 | 470uF 25V NP | `Capacitor_THT:CP_Radial_D16.0mm_P7.50mm` | 2 | HP 出力の DC ブロック（v1 C901）。無極性電解。役目はオフセットではなく素子故障時の保護（DECISIONS）。FP は Ø16/P7.5（2026-09-10）— Muse ES UES1E471MHM（470µF 25V BP）が入るサイズ / HP 出力の DC ブロック（v1 C902）。無極性電解。FP は Ø16/P7.5（2026-09-10）— Muse ES UES1E471MHM（470µF 25V BP）が入るサイズ |
| C503,C504 | 10uF 25V X7R | `Capacitor_SMD:C_1206_3216Metric_Pad1.33x1.80mm_HandSolder` | 2 | U501 の +15V ローカルバルク（v1 C903） / U501 の -15V ローカルバルク（v1 C905 相当） |
| C505,C506,C608,C609,C708,C709,C808,C809,C908,C909,C1008,C1009,C1108,C1109,C1208,C1209,C1308,C1309,C1604,C1605,C1607,C1612,C1614,C1615,C1617,C1618,C1622,C1624,C1625,C1629,C1634,C1636,C1637,C1638,C1639,C1641,C1642,C1643,C1646,C1647,C1650 | 100nF | `Capacitor_SMD:C_1206_3216Metric_Pad1.33x1.80mm_HandSolder` | 41 | A701 +3V3_A local bypass 100nF / 1206 / A701 +5V_A local bypass 100nF / 1206 / U1611 の +15V_A デカップリング / U1611 の -15V_A デカップリング / U501 の +15V デカップリング / U501 の -15V デカップリング（v1 C906） / U704/U705 VIN HF bypass 100nF / return ADC_GND_IN. / U709 VDD bypass 100nF / VCOML bypass to ADC_GND / VCOMR bypass to ADC_GND / op amp V+ local decoupling / switch VSS local decoupling |
| C601,C604,C701,C704,C801,C804,C901,C904,C1001,C1004,C1101,C1104,C1201,C1204,C1301,C1304 | 2.2uF film | `Capacitor_THT:C_Rect_L7.2mm_W7.2mm_P5.00mm_FKS2_FKP2_MKS2_MKP2` | 16 | L output coupling (before switch) / R output coupling (before switch) |
| C602,C605,C702,C705,C802,C805,C902,C905,C1002,C1005,C1102,C1105,C1202,C1205,C1302,C1305 | 1uF film | `Capacitor_THT:C_Rect_L7.2mm_W4.5mm_P5.00mm_FKS2_FKP2_MKS2_MKP2` | 16 | L input film coupling / R input film coupling |
| C1601,C1608,C1623 | 10nF | `Capacitor_SMD:C_1206_3216Metric_Pad1.33x1.80mm_HandSolder` | 3 | Y701 VDD bypass 10nF (ASFL1 データシート指定: pin2-pin4 間) |
| C1602,C1613,C1626,C1628 | 10uF 25V NP | `Capacitor_THT:C_Radial_D5.0mm_H7.0mm_P2.00mm` | 4 | AC couple unpolarized 10uF 25V (not polar electrolytic) |
| C1603 | 10uF 10V X7R | `Capacitor_SMD:C_1206_3216Metric_Pad1.33x1.80mm_HandSolder` | 1 | LT1763-3.3 OUT bulk, >=10V X7R 1206 |
| C1606,C1619 | 10uF 50V X7R | `Capacitor_SMD:C_1210_3225Metric_Pad1.33x2.70mm_HandSolder` | 2 | LT1763 IN bulk / 16V X7R 1206 (6.7V rail) |
| C1609,C1620,C1627,C1632 | 1.8nF C0G | `Capacitor_SMD:C_1206_3216Metric_Pad1.33x1.80mm_HandSolder` | 4 | LPF C0G/NP0 ceramic |
| C1610 | 47uF 35V | `Capacitor_THT:CP_Radial_D8.0mm_P3.50mm` | 1 | ADC_V_IN bulk 47uF 35V. Return on ADC_GND_IN. |
| C1611,C1631,C1633 | 10uF | `Capacitor_SMD:C_1206_3216Metric_Pad1.33x1.80mm_HandSolder` | 3 | U704/U705 VIN mid-freq ceramic 10uF (unpolarized), return ADC_GND_IN. Parallel with C723 bulk and C725 100nF.,積セラ 10uF50V 3216（秋月 117338・購入済）。U708(XC8107) 入力コンデンサ CIN。データシート推奨 1.0uF 以上、VIN-VSS 間を最短で。,積セラ 10uF50V 3216（秋月 117338・購入済）。U708(XC8107) 出力コンデンサ CL。データシート推奨 1.0uF 以上、IC 直近に配置。 |
| C1616 | 10uF 16V X7R | `Capacitor_SMD:C_1206_3216Metric_Pad1.33x1.80mm_HandSolder` | 1 | LT1763-5 OUT bulk, 10V or 16V X7R 1206 |
| C1621 | 47uF | `Capacitor_THT:CP_Radial_D8.0mm_P3.50mm` | 1 | 導電性高分子アルミ固体電解コンデンサー OS-CON相当 47uF16V以上 +5V_D |
| C1630 | 22uF | `Capacitor_THT:CP_Radial_D6.3mm_P2.50mm` | 1 | 導電性高分子アルミ固体電解コンデンサー OS-CON相当 22uF16V以上 LCD_VCC |
| C1635,C1640 | 10uF 50V | `Capacitor_THT:CP_Radial_D5.0mm_P2.00mm` | 2 | 導電性高分子アルミ固体電解コンデンサー ハイブリッド相当 10μF50V +15V_A / 導電性高分子アルミ固体電解コンデンサー ハイブリッド相当 10μF50V -15V_A |
| C1645 | 10uF 50V | `Capacitor_SMD:C_1206_3216Metric_Pad1.33x1.80mm_HandSolder` | 1 | U1607(BP5293-50) の入力コンデンサ CIN。DS p.2 推奨 10uF。帰り先は D_GND（U1607 の GND と同じ）。PD_GND に落とすと入力の脈流ループが NT1602 を通ってしまう。 |
| C_BULK_N301,C_BULK_N302,C_BULK_P301,C_BULK_P302 | 100uF 35V | `Capacitor_SMD:CP_Elec_10x12.6` | 4 |  |
| D403 | 12V panel LED | `LED_THT:LED_D5.0mm` | 1 |  |
| D1601 | RB160M-30 | `Diode_SMD:D_SOD-123` | 1 | SOD-123 Schottky, +5V_D anode -> Pico VSYS cathode. Blocks USB backfeed into +5V_D. |
| D1610 | DEST 1 | `LED_THT:LED_D5.0mm` | 1 |  |
| D1611 | DEST 2 | `LED_THT:LED_D5.0mm` | 1 |  |
| ENC1601 | ENC_CH | `Rotary_Encoder:RotaryEncoder_Alps_EC11E-Switch_Vertical_H20mm` | 1 | Alps EC11E-class vertical + push SW; shaft L=25mm. Panel nut unused (Z vs Cosland/RK09L). FP pads same as H20mm. |
| ENC1602 | ENC_BASS | `Rotary_Encoder:RotaryEncoder_Alps_EC11E-Switch_Vertical_H20mm` | 1 | Alps EC11E-class vertical + push SW; shaft L=25mm. Panel nut unused (Z vs Cosland/RK09L). FP pads same as H20mm. |
| ENC1603 | ENC_TREBLE | `Rotary_Encoder:RotaryEncoder_Alps_EC11E-Switch_Vertical_H20mm` | 1 | Alps EC11E-class vertical + push SW; shaft L=25mm. Panel nut unused (Z vs Cosland/RK09L). FP pads same as H20mm. |
| F201 | F2A fast 5x20 | `Fuse:Fuseholder_Cylinder-5x20mm_Schurter_0031_8201_Horizontal_Open` | 1 | 入口ヒューズ（PD 12V → U201 REC20K）。ホルダは Schurter OGN 0031.8201（基板用 5×20 オープン型、KiCad 標準 FP）。中身は 5×20 ガラス管速断 F2A（例: 秋月 MF51NR 250V2A / Littelfuse 0217.002HXP 系）。ホルダ FP は 2026-09-09。定格は入手性で T1.6A スロー→F2A 速断（2026-09-09） |
| F202 | PPTC 0.4A hold | `Library:PPTC_Radial_D7.9mm_T3.1mm_P5.08mm` | 1 | リレーコイル電源（U403 前）の PPTC。0.35 A の品は Littelfuse/Bourns とも無いので 0.40 A に寄せた（コイル枝のピークは約 0.16 A）。ラジアル PPTC。Littelfuse RXEF040（Ih 0.40 A / It 0.80 A / 72 V）。Bourns MF-R040 も同寸で可。FP は DigiKey の寸法（φ7.4〜7.9×3.1、ピッチ 5.05〜5.10）から起こした Library の自作。2026-09-09 に軸リード FP から直した |
| F203 | PPTC 0.1A hold | `Library:PPTC_Radial_D7.9mm_T3.1mm_P5.08mm` | 1 | +9V LDO（U202）入口の PPTC。ラジアル PPTC。Littelfuse RXEF010（Ih 0.10 A / It 0.20 A / 60 V）。Bourns MF-R010 も同寸で可。FP は DigiKey の寸法（φ7.4〜7.9×3.1、ピッチ 5.05〜5.10）から起こした Library の自作。2026-09-09 に軸リード FP から直した |
| F1601 | T1A slow 5x20 | `Fuse:Fuseholder_Cylinder-5x20mm_Schurter_0031_8201_Horizontal_Open` | 1 | 計測側 12V 入口（J1602）のヒューズ。J1602 を外すなら一緒に消える。ホルダは Schurter OGN 0031.8201（基板用 5×20 オープン型、DigiKey 在庫 6 万・¥240、KiCad 標準 FP）。中身は 5×20 ガラス管スローブロー T1A（例: Bel 0652C1000/1600-11、Littelfuse 0218 系、秋月の 5.2×20 スロー品も挿さる）。2026-09-09 に軸リード FP からホルダ FP へ直した |
| F1602 | PPTC 0.5A hold | `Library:PPTC_Radial_D7.9mm_T3.1mm_P5.08mm` | 1 | 計測側 +5V_D（U1607）入口の PPTC。ラジアル PPTC。Littelfuse RXEF050（Ih 0.50 A / It 1.0 A / 72 V）。Bourns MF-R050 も同寸で可。FP は DigiKey の寸法（φ7.4〜7.9×3.1、ピッチ 5.05〜5.10）から起こした Library の自作。2026-09-09 に軸リード FP から直した |
| H301,H302,H303,H304,H311,H312,H313,H314 | M3 | `MountingHole:MountingHole_3.2mm_M3` | 8 |  |
| J201 | +15/A_GND/-15 out | `TerminalBlock_Phoenix:TerminalBlock_Phoenix_MKDS-1,5-3-5.08_1x03_P5.08mm_Horizontal` | 1 |  |
| J202 | PD module in (1=GND 2=+12V) | `TerminalBlock_Phoenix:TerminalBlock_Phoenix_MKDS-1,5-2-5.08_1x02_P5.08mm_Horizontal` | 1 |  |
| J1601 | AUDIO | `TerminalBlock_Phoenix:TerminalBlock_Phoenix_MKDS-1,5-2-5.08_1x02_P5.08mm_Horizontal` | 1 | Generic screw terminal, single row, 01x02, script generated (kicad-library-utils/schlib/autogen/connector/) |
| J1602 | V_IN | `TerminalBlock_Phoenix:TerminalBlock_Phoenix_MKDS-1,5-2-5.08_1x02_P5.08mm_Horizontal` | 1 | 計測側の 12V 入口（F1601 経由で U1607 へ）。1=PD_GND / 2=+12V —— 母板 J202（1=GND 2=+12V）と同じ並び。2026-09-09 に揃えた。残すか外すかは B5 のハーネス判断 |
| J1603 | 15_V_IN | `TerminalBlock_Phoenix:TerminalBlock_Phoenix_MKDS-1,5-3-5.08_1x03_P5.08mm_Horizontal` | 1 | 計測側の ±15V 入口。1=+15V_A / 2=A_GND / 3=-15V_A —— 母板 J201（+15/A_GND/-15）と同じ並び。2026-09-09 にミラーで揃えた（それまで逆だった）。残すか外すかは B5 のハーネス判断 |
| J_ANA101 | SLOT1 ANA (D18) | `Connector_PinSocket_2.54mm:PinSocket_2x05_P2.54mm_Vertical` | 1 |  |
| J_ANA301,J_ANA302 | SLOT ANA (D18) | `Connector_PinHeader_2.54mm:PinHeader_2x05_P2.54mm_Vertical` | 2 |  |
| J_HP501 | HP OUT | `Connector_JST:JST_XH_B3B-XH-A_1x03_P2.50mm_Vertical` | 1 | ヘッドホン出力端子（箱のパネルのジャックへ）。1=PHONE_L / 2=A_GND / 3=PHONE_R。U501 バッファの出力（10Ω・470µF NP 経由）。2026-09-08 に 2P→3P（帰路を入れた。J_IN401/J_RAIL501 と同じ流儀）。旧 Value「to Audio HP Buffer」= 図の外の v1 バッファは同日 U501 として取り込んだ |
| J_IN401 | AUDIO IN L/R | `TerminalBlock_Phoenix:TerminalBlock_Phoenix_MKDS-1,5-3-5.08_1x03_P5.08mm_Horizontal` | 1 | 箱の外部音声入力。1=L / 2=A_GND / 3=R。ここから結合C経由で PT2314E の LIN/RIN へ入る（セレクタとボリューム段は LOUT/ROUT->LIN/RIN のインサートで飛ばしている）。L と R の間に GND を挟むため 3P にした。 |
| J_LCD1601,J_PNL_A1602_2 | LCD cable A (XH8) | `Connector_JST:JST_XH_B8B-XH-A_1x08_P2.50mm_Vertical` | 2 |  |
| J_LCD1602 | LCD cable B (XH8) | `Connector_JST:JST_XH_B8B-XH-A_1x08_P2.50mm_Vertical` | 1 |  |
| J_LINE501 | LINE OUT | `Connector_JST:JST_XH_B3B-XH-A_1x03_P2.50mm_Vertical` | 1 | ライン出力端子（箱のパネルへ）。1=LINE_L / 2=A_GND / 3=LINE_R。RV502 直出し（バッファ無し）。2026-09-08 に 2P→3P（帰路を入れた） |
| J_PNL1601_1,J_PNL1602_1 | FrontPanel digital A (odd) | `Connector_JST:JST_XH_B10B-XH-A_1x10_P2.50mm_Vertical` | 2 |  |
| J_PNL1601_2,J_PNL1602_2 | FrontPanel digital B (even) | `Connector_JST:JST_XH_B10B-XH-A_1x10_P2.50mm_Vertical` | 2 |  |
| J_PNL_A1601_1,J_PNL_A1602_1 | FrontPanel analog A (odd) | `Connector_JST:JST_XH_B8B-XH-A_1x08_P2.50mm_Vertical` | 2 |  |
| J_PNL_A1601_2 | FrontPanel analog B (even) | `Connector_JST:JST_XH_B8B-XH-A_1x08_P2.50mm_Vertical` | 1 |  |
| J_PNL_P1601,J_PNL_P1611 | FrontPanel 12V raw | `Connector_JST:JST_XH_B3B-XH-A_1x03_P2.50mm_Vertical` | 2 |  |
| J_PNL_P1602,J_PNL_P1612 | FrontPanel 12V switched | `Connector_JST:JST_XH_B3B-XH-A_1x03_P2.50mm_Vertical` | 2 |  |
| J_PWR101 | SLOT1 PWR/CTRL (D18) | `Connector_PinSocket_2.54mm:PinSocket_2x08_P2.54mm_Vertical` | 1 |  |
| J_PWR301,J_PWR302 | SLOT PWR/CTRL (D18) | `Connector_PinHeader_2.54mm:PinHeader_2x08_P2.54mm_Vertical` | 2 |  |
| J_RAIL501 | AMP_SEL OUT | `TerminalBlock_Phoenix:TerminalBlock_Phoenix_MKDS-1,5-3-5.08_1x03_P5.08mm_Horizontal` | 1 | 選択された Amp 出力の取り出し端子。1=AMP_SEL_L / 2=A_GND / 3=AMP_SEL_R で、DEST スイッチ(SW501/SW502)の手前。旧 Value の RAIL IN と旧記述の +12V/A_GND/-12V は、娘基板がスロット直結(J_PWR/J_ANA)になる前の名残で電源ではない。A_GND 極を持つ唯一の音声取り出し口。 |
| K301,K302,K303,K304 | AZ850P2-5 | `Relay_THT:Relay_DPDT_FRT5` | 4 | 双コイル・ラッチングリレー。v1 と同じ AZ850P2-5 に固定（2026-09-09）。接点 3/8・4/7 を使い 2/9 は開放、コイル 1-5 / 10-6 —— v1 のネットリストと同一の使い方で、v1 実機で動作実績あり。⚠ 外形（FRT5）が同じセカンドソース（TQ2-L2 など）は接点の COM/NC/NO のピン番号が同じとは限らず、挿すと SET/RESET の意味が反転しうる。AZ850P2-5 以外を挿さない。 |
| Q401,Q402 | BSS138 | `Package_TO_SOT_SMD:SOT-23` | 2 | I²C SCL 側の双方向レベルシフタ。役目・理由は Q401（SDA 側）と同じ / I²C 双方向レベルシフタ（2026-09-08）。S=Pico 側 3V3 バス、D=PT2314E 側 9V バス、G=3V3。PT2314E の VIH min 3.0 V に対し 3.3 V プルアップでは余裕 0.3 V しか無いので、PT 側を VCC_TONE(9V) で釣る。P82B96 を使わないのは Sx 側 VOL 0.8–1.0 V が PT2314E VIL max 1.0 V / RP2350 VIL 0.8 V を食い切るため（DECISIONS）。 SDA。 |
| R401,R1651,R1652 | 1k | `Resistor_SMD:R_1206_3216Metric_Pad1.30x1.75mm_HandSolder` | 3 |  |
| R410,R411 | 5.6k | `Resistor_SMD:R_1206_3216Metric_Pad1.30x1.75mm_HandSolder` | 2 |  |
| R412,R413,R1611,R1657,R1661,R1662 | 10k | `Resistor_SMD:R_1206_3216Metric_Pad1.30x1.75mm_HandSolder` | 6 | ADC_nRST pull-up 10k / 1206 / PT2314E 側 I²C SCL のプルアップ（9V=VCC_TONE） / PT2314E 側 I²C SDA のプルアップ（9V=VCC_TONE）。10k: 0.9 mA / 立ち上がり ~0.3 µs（100 kbit/s） / U1610 MCP23017 ENC_INTA open-drain pull-up to 3V3 / U1610 MCP23017 ENC_INTB open-drain pull-up to 3V3 |
| R501,R502 | 10R | `Resistor_SMD:R_1206_3216Metric_Pad1.30x1.75mm_HandSolder` | 2 | HP 出力の直列抵抗（v1 R901）。ケーブル容量からの分離 / HP 出力の直列抵抗（v1 R903） |
| R503,R504,R601,R607,R701,R707,R801,R807,R901,R907,R1001,R1007,R1101,R1107,R1201,R1207,R1301,R1307,R1620,R1659,R1660 | 100k | `Resistor_SMD:R_1206_3216Metric_Pad1.30x1.75mm_HandSolder` | 21 | HP ジャック側ノードのブリード（v1 R902）。未接続時に C501 の DC を落とす / HP ジャック側ノードのブリード（v1 R904） / L non-inverting bias / R non-inverting bias / U1611 L バッファの入力バイアス（v1 R805 相当）。J1601 を抜いても入力が浮かない / U1611 R バッファの入力バイアス（v1 R810 相当） / U708(XC8107) CE プルダウン。Active High なので Pico GPIO が Hi-Z の間は LCD OFF がデフォルト。CE に内部プルダウンは無いため必須。 |
| R602,R608,R702,R708,R802,R808,R902,R908,R1002,R1008,R1102,R1108,R1202,R1208,R1302,R1308 | 47R | `Resistor_SMD:R_1206_3216Metric_Pad1.30x1.75mm_HandSolder` | 16 | L output isolation / R output isolation |
| R603,R609,R703,R709,R803,R809,R903,R909,R1003,R1009,R1103,R1109,R1203,R1209,R1303,R1309 | 220k | `Resistor_SMD:R_1206_3216Metric_Pad1.30x1.75mm_HandSolder` | 16 | L output pulldown (before switch) / R output pulldown (before switch) |
| R604,R606,R610,R612,R704,R706,R710,R712,R804,R806,R810,R812,R904,R906,R910,R912,R1004,R1006,R1010,R1012,R1104,R1106,R1110,R1112,R1204,R1206,R1210,R1212,R1304,R1306,R1310,R1312 | 20k 0.1% | `Resistor_SMD:R_0805_2012Metric_Pad1.20x1.40mm_HandSolder` | 32 | L feedback Rf; default 20k 0.1% = GAIN 2 / L gain resistor Rg; GAIN=1+Rf/Rg / R feedback Rf; default 20k 0.1% = GAIN 2 / R gain resistor Rg; GAIN=1+Rf/Rg |
| R1601,R1606,R1612,R1615 | 4.7k 0.1% | `Resistor_SMD:R_1206_3216Metric_Pad1.30x1.75mm_HandSolder` | 4 |  |
| R1602,R1608,R1613,R1617 | 47 | `Resistor_SMD:R_1206_3216Metric_Pad1.30x1.75mm_HandSolder` | 4 | OPA to ADC VIN series 47 / 1206 |
| R1603,R1609,R1614,R1618 | 6.19k 0.1% | `Resistor_SMD:R_1206_3216Metric_Pad1.30x1.75mm_HandSolder` | 4 |  |
| R1604 | 33 | `Resistor_SMD:R_1206_3216Metric_Pad1.30x1.75mm_HandSolder` | 1 | Y701 MCLK series 33, 1206 |
| R1607,R1610,R1616,R1619 | 1k 0.1% | `Resistor_SMD:R_1206_3216Metric_Pad1.30x1.75mm_HandSolder` | 4 |  |
| R1653,R1654 | 4.7k | `Resistor_SMD:R_1206_3216Metric_Pad1.30x1.75mm_HandSolder` | 2 |  |
| RV501 | A50k Dual HP | `Connector_JST:JST_XH_B6B-XH-A_1x06_P2.50mm_Vertical` | 1 |  |
| RV502 | A50k Dual LINE | `Connector_JST:JST_XH_B6B-XH-A_1x06_P2.50mm_Vertical` | 1 |  |
| R_ADDR_A0,S_ADDR_A0 | ADDR A0 | `Jumper:SolderJumper-3_P1.3mm_Bridged12_Pad1.0x1.5mm_NumberLabels` | 2 |  |
| R_ADDR_A1,S_ADDR_A1 | ADDR A1 | `Jumper:SolderJumper-3_P1.3mm_Bridged12_Pad1.0x1.5mm_NumberLabels` | 2 |  |
| R_ADDR_A2,S_ADDR_A2 | ADDR A2 | `Jumper:SolderJumper-3_P1.3mm_Bridged12_Pad1.0x1.5mm_NumberLabels` | 2 |  |
| SW402 | Cosland 2MS1 PWR | `Library:SW_Toggle_Cosland_2MS1_VS2_SPDT` | 1 | PWR Cosland 2MS1-T1-B4-VS2-Q-E-S (Akizuki 100300) SPDT ON-ON; COM=PD_12V, throw=PD_12V_SW, other throw NC. |
| SW501 | Cosland 2MD1 DEST | `Library:SW_Toggle_Cosland_2MD1_VS2_DPDT` | 1 | DEST PHONE/LINE DPDT ON-ON. Cosland 2MD1-T1-B4-VS2-Q-E (Akizuki 104028). |
| TP1601 | ADC_MCLK | `TestPoint:TestPoint_Pad_D1.5mm` | 1 | ADC_MCLK probe pad after R718. |
| U201 | REC20K-2415DZ | `Library:REC20K-Z_1in_THT` | 1 | Recom REC20K-2415DZ isolated DC/DC, 9-36Vin, ±15V/±667mA (20W), eff 88% typ, DIP 1in x 1in, Cout ±3000uF/rail, pin3=CTRL open=ON。REC10K-2415DAW/H2（±333mA・Cout ±270uF）から 2026-09-07 に差し替えた。理由は独立に3つ: ①ソケット10個が常時通電なので ±333mA だと 1ソケットあたり 27mA しか使えず、在庫の MUSES03（20mA）で既に窮屈 ②実レール容量 259.8uF が Cout ±270uF の 96% ③計測系の電源を +15V へ寄せる余地。ピン配置は REC10K と同一で、推奨穴が Ø1.0 -> Ø1.4 になるのでフットプリントも替えた（Ø1.4 なら REC10K も挿さる） |
| U202 | L7809CV +9V | `Package_TO_SOT_THT:TO-220-3_Vertical` | 1 |  |
| U311,U312 | TMUX7612 | `Package_SO:TSSOP-16_4.4x5mm_P0.65mm` | 2 |  |
| U321 | TBD62083APG | `Package_DIP:DIP-18_W7.62mm` | 1 |  |
| U402 | PT2314E | `Package_SO:SOIC-28W_7.5x17.9mm_P1.27mm` | 1 | SOP-28 300 mil（表面実装。無印 PT2314 の DIP 版は入手不可）。LCSC C90034。トーン段だけ使う — 入力セレクタとボリューム段は LOUT/ROUT -> LIN/RIN の インサート点で飛ばしていて、未使用12ピンには no_connect を立ててある。 DGND(25) は 2026-09-08 にチップの足元で A_GND へ（旧 D_GND）。I²C は Q401/Q402 レベルシフタ越しに 9V（VCC_TONE）プルアップの I2C_SDA_9V/I2C_SCL_9V で受ける。 |
| U403 | BP5293-50 +5V | `Library:BP5293-50_ROHM_SIP-3` | 1 |  |
| U501 | OPA1652 | `Package_DIP:DIP-8_W7.62mm_Socket` | 1 | HP バッファ（v1 HeadphoneBufferModule AMP901 の移設・2026-09-08）。ユニティフォロワ ×2（A=L, B=R）。DIP-8 ソケットで AmpChannel と同じ。標準実装は OPA1652（DIP 化モジュール、出力 ±30 mA）。入力は RV501 ワイパー（PHONE_BUF_L/R）、出力は 10Ω→470µF NP→PHONE_L/R。⚠ 比較セッション中は差し替えない（10 石すべてに共通に掛かる）。 |
| U1601,U1602,U1608,U1611 | OPA1656 | `Package_SO:SOIC-8_3.9x4.9mm_P1.27mm` | 4 | 計測タップの「+」側バッファ（v1 の AdcBuffer を復元）。ユニティフォロワ、入力 100k→A_GND。音声バスから見た負荷を 1.87k→約30k（RV501 50k ∥ R603 220k ∥ R1659 100k）に戻し、両ブランチが 10µF を見る源インピーダンスを揃える（Vg 除去 20Hz 10.5→43dB、TMUX7612 の H3 −94.9→−115.5dB（spice/switch_thd.py --rload 30.4e3 実測）、低域 39→17Hz）。v1 の出力 47Ω は対称性のため付けない（負荷は R1612/R1614 系の抵抗で容量性ではなく、OPA1656 は CL 100 pF まで規定内。DS Electrical Characteristics）。2026-09-07 |
| U1603 | LT1763-3.3 | `Package_SO:SOIC-8_3.9x4.9mm_P1.27mm` | 1 | ADI LT1763 3.3V fixed LDO, SO-8, low noise |
| U1605 | TPS3307-33 | `Package_SO:SOIC-8_3.9x4.9mm_P1.27mm` | 1 | Triple supervisor SO-8: SENSE1=5V (4.55V), SENSE2=3.3V (2.93V), SENSE3=adj 1.25V. Push-pull RESET / ~RESET, 200ms delay, ~MR. VDD from +3V3_A so ~RESET is 3.3V. |
| U1606 | LT1763-5 | `Package_SO:SOIC-8_3.9x4.9mm_P1.27mm` | 1 | ADI LT1763 5V fixed LDO, SO-8, low noise |
| U1607 | BP5293-50 | `Library:BP5293-50_ROHM_SIP-3` | 1 |  |
| U1609 | XC8107AC20MR-G | `Package_TO_SOT_SMD:SOT-23-5_HandSoldering` | 1 | LCD/タッチ用ロードスイッチ。秋月 131334。CE=LCD_EN は Active High（VCEH 1.5V min なので Pico 3.3V で直接ON）。R717 100k で CE プルダウン＝起動時 OFF。ソフトスタート 0.6ms typ で LCD_VCC バルクへの突入電流を抑制。C740(CIN)/C739(CL) は 10uF 3216 を IC 直近に。FLG 未使用。 |
| U1610 | MCP23017 (UI 0x22) | `Package_DIP:DIP-28_W7.62mm` | 1 |  |
| U_IO301,U_IO302 | MCP23017 | `Package_DIP:DIP-28_W7.62mm` | 2 |  |
| Y1601 | ASFL1-12.288MHZ-EC-T | `Library:Oscillator_SMD_Abracon_ASFL-4Pin_5.0x3.2mm_HandSoldering` | 1 | Abracon ASFL1 12.288MHz CMOS osc, 3.3V. pin1=Tri-State (H/open=発振), pin4=Vdd. データシート指定: pin2-pin4 間に 0.01uF バイパス |
<!-- END GENERATED: case-bom -->

<!-- BEGIN GENERATED: ampchannel-bom -->
**AmpChannel 1ch テンプレート（×10 される中身）** — 下の表は `AudioV2.1/AmpChannel.kicad_sch` から自動生成しています。
**手で編集しないでください**（次の再生成で消えます）。値・フットプリント・役割を直すときは KiCad の回路図側を直し、
`python3 AudioV2.1/scripts/gen_parts_bom.py` で再生成します。

行数 8 / 部品総数 17。

> `Refs` 列と `Value` / `Role` 列に**位置の対応はありません**。kicad-cli はグループ内の値を重複除去してアルファベット順に並べるため、「n 番目の参照 = n 番目の役割」とは読めません。
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

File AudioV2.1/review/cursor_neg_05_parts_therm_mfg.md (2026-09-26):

# v2.1 否定側査読 — ⑤ 部品の入手・熱・実装のしやすさ（Cursor）
- 作成: 2026-09-26（Cursor 並行査読、読み取り専用）
- 判定: 支持/修正/棄却/穴/確かめられず。重さ: 損傷/聴こえる/無害（入手不能は実装停止＝損傷扱いでよい）

## 0. 結論（表）

| # | 対象の決定・主張 | 判定 | 重さ |
|---|---|---|---|
| 1 | 縦積み 4 枚でも DIP ソケットに手が届く（継-22／未決-20 を後回しに決定が進む） | **穴** | **損傷** |
| 2 | RS6-1215D「入手できれば」で主電源を固定 | **穴**（在庫の一次確認が§10に残る） | **損傷**（入手不能時） |
| 3 | トーン＝NJW1194。控え未定。代替は同等単体が無い | **支持（代替困難）／修正（控え）** | **損傷**（調達・破損で止む） |
| 4 | NJW1194＝SSOP32・手実装前提が文書に無い | **穴** | 聴こえる〜損傷（実装歩留まり） |
| 5 | TMUX7612×4／娘・TSSOP 0.65 mm・員数 16 | **修正**（実装負荷を軽く見ている） | 聴こえる |
| 6 | ch／トーンの TPS7A49／30（PowerPAD・員数多） | **修正**（熱は軽い／実装は重い） | 無害（熱）／聴こえる（実装） |
| 7 | HP バッファは R1（±15 V 直結）のまま | **条件つき支持**（熱は運用頼み） | 聴こえる〜損傷（連続大音量時） |
| 8 | 箱の熱・L7805C・DC-DC 損失の扱い | **修正**（箱内熱の合計の読み） | 聴こえる |
| 9 | AZ850P2-5 を音声・電源とも 1 品種 | **条件つき支持**（電源役は実測待ち） | 聴こえる（接点寿命）／無害（入手） |
| 10 | 充電器 C1〜C4 に 12 V/3 A | **支持**（ユーザー確認）／**穴**（再交渉） | 無害／損傷（再交渉で 12 V 喪失時） |
| 11 | 鉛フリー手半田で全 SMD を組めるか | **確かめられず** | — |
| 12 | 縦積みリレー間隔 ≥5 mm | **支持**（DS 制約として正しい） | 無害（守れば）／損傷（詰めるとラッチ誤動作） |

**総評:** 電源容量（R1・63 %）と充電器電流は数字が揃う。否定側で残るのは **(a) 縦積みと DIP 手の届きの未決、(b) RS6／NJW1194 の単点調達、(c) 0.65 mm 級 SMD＋PowerPAD の手実装量、(d) HP 熱の運用依存**。入手不能・DIP 不到達は実装停止＝損傷扱い。

---

## 1. 指摘詳細（何が/なぜ/確度/外れる条件/判定）

### 1.1 [重大] 縦積み 4 枚と「DIP に手が届く」が同時に成立していない

**何が** — DECISIONS §2-13 は娘 4 枚（いったんの決め）。V21-継-22 は「DIP ソケットに手が届くこと」を最大の制約とする。V21-未決-20 は「縦積みで下の段の DIP に手が届くか」を**未決のまま**残し、NOW も「残る未決: -20（模型）」と書く。装置の目的は石の差し替え（§0-1）。

**なぜ効くか** — 下段に手が届かないなら、縦積み 4 枚の決定は装置の存在理由と衝突する。届かない＝その構成では作れない＝実装停止。

**確度** — 一次（DECISIONS・NOW の状態欄）。立体の可否は未実測〔推論〕。

**外れる条件** — 模型で 4 段でも届く／段数を減らす／下段を引き抜いて差し替える運用をユーザーが受ける。

**判定:** 穴。重さ: **損傷**。

---

### 1.2 [重大] RS6-1215D は「入手できれば」のまま、在庫の一次確認が §10 に残る

**何が** — §3-1 決定文が「入手できれば」。§10-1「確かめる事実」に RS6 の入手性。既存 SIP8 FP は穴 Ø0.8、RS6 推奨 Ø1.00＋0.15/−0（`ds_facts/power.md`）。次点 TMR9 は Cout ±200 µF・軽負荷の記載なし（§3-1 却下欄）。

**なぜ効くか** — 主電源が単点。入手不能なら図・FP・予算の前提が全部動く。TMR9 に戻すと容量・軽負荷の再検討が要る。

**確度** — 一次（決定の文言・§10）。流通数量は本査読では未再取得〔確かめられず〕。

**外れる条件** — DigiKey／Mouser／代理店で少量・短納期が取れる一次確認。

**判定:** 穴。重さ: 入手不能なら **損傷**。

---

### 1.3 [重大] NJW1194 は機能上の単点。控えが「未定」

**何が** — §1-6: スルー＋音量段を持つ単体は調査範囲でこれだけ（`njw1194_alternatives_review`）。却下 PT2314E。控え未定。ユーザーは Arrow・LCSC で入手の心配は解けたとする（2026-09-26）。一方 LCSC API 再取得では在庫 0・取り寄せ窓口（同査読 M5）。Digi-Key 最小 2,000 は二次。

**なぜ効くか** — 壊れた・リードタイムが伸びたときの次善が無い。C1'（PT＋NJU72343）は却下したトーン床（0.03/0.07 %）に戻る。同等単体は無い＝代替困難。

**確度** — 一次（DECISIONS・代替査読）。Arrow の数量・納期はユーザー確認〔二次〕で、本査読は再取得できず。

**外れる条件** — Arrow で必要数を押さえ済み／控え（C1' 等）をユーザーが受ける。

**判定:** 支持（代替困難）／修正（控えを「保険」と書くだけでは足りない）。重さ: **損傷**。

---

### 1.4 [要確認] SSOP32（0.65 mm）の手実装が決定に載っていない

**何が** — 品番 `NJW1194V-TE1`（SSOP32）。DS に外形図無し。メーカー資料 PI-SSOP32-E-A（ピッチ 0.65 mm）。実装例は KiCad `TSSOP-32_6.1x11mm_P0.65mm` を当てるが本体幅 5.6 mm との差あり（`njw1194_power_impl` §4）。PD 1000 mW（JEDEC 基板、`njw1194.md`）。

**なぜ効くか** — 親板の中心部品が手半田難パッケージ。FP を誤ると実装不能・ショート。鉛フリー手半田の可否は文書に無い（§3）。

**確度** — 一次（ds_facts・実装メモ）。手半田可否は〔推論〕。

**外れる条件** — 外注 SMT／アダプタ／既に手半田実績がある。

**判定:** 穴。重さ: 聴こえる〜**損傷**（歩留まり）。

---

### 1.5 [要確認] TMUX7612 は入手可だが員数と 0.65 mm が実装を重い

**何が** — 娘あたり 4 パッケージ（入出力 L/R＝ch 1 個、§2-8）×4 枚＝16。`PARTS.md`: `TMUX7612PWR` カットテープ・MOQ1・2026-09-02 在庫 1,772。TSSOP-16 0.65 mm、パッド上ビア禁止（NOW／実装メモ）。

**なぜ効くか** — 電気・入手は問題になりにくい。実装は NJW1194 と同ピッチが 16 個。WQFN は MOQ 3000 で手実装向きでない。

**確度** — 一次（PARTS・DECISIONS）。

**外れる条件** — SMT 外注／員数を減らす構成（採らない）。

**判定:** 修正（「実装しやすい」とは言えない）。重さ: 聴こえる。

---

### 1.6 [要確認] TPS7A49／30 — 熱は軽い、員数と PowerPAD は重い

**何が** — ch ごと正負（娘 1 枚で 8、4 枚で 32）＋トーン ±7 V で 2。DGN＝HVSSOP PowerPAD、RθJA 63.4 °C/W（`power.md`）。損失例: トーン (15−7)×17 mA ≈ 0.14 W／側（`njw1194_power_impl`）；ch は DUT 十数 mA 級で (15−12)×I は数十 mW。§3-7 で出力実効約 5 µF（逆流対策）。

**なぜ効くか** — 熱で落ちる筋は弱い。PowerPAD 直下ビア＋はんだは手作業で失敗しやすい。員数 34 は BOM・検品の負荷。

**確度** — 一次（DS・予算査読）。実装難易は〔推論〕。

**外れる条件** — SMT／PowerPAD 用工程がある。

**判定:** 修正。重さ: 熱は無害、実装は聴こえる。

---

### 1.7 [要確認] HP バッファ R1 — 熱は「連続正弦を出さない」前提

**何が** — §3-13: 大きい音の連続正弦はしない、R1 のまま。歪み始め 40 mA pk で約 0.82 W・+117 K（SOIC θJA 143.6 °C/W）。図は DIP-8 ソケットの DIP 化モジュール → 中が VSSOP なら 218.9 °C/W → +180 K（`power_budget_v21_review`）。箱内発熱は PD 入力 3.7〜7.4 W（同・対象の「3〜4 W」は反対）。

**なぜ効くか** — 容量は足りる。熱は運用違反や測定用連続正弦で接合が上がる。θJA の置き方が甘い。

**確度** — 算術は一次再現。モジュール内パッケージは確かめられず。

**外れる条件** — 連続大音量をしない運用が守られる／RC の R を大きくする／±10 V LDO。

**判定:** 条件つき支持。重さ: 聴こえる（運用破りで損傷寄り）。

---

### 1.8 [軽微〜要確認] L7805C・RS6・箱の熱の読み

**何が** — `+5V_COIL`＝L7805C（§3-8）。定常は薄い。12 コイル 560 mA で (12−5)×0.56 ≈ 3.9 W・20〜30 ms。聴取中 `RAIL_OK` の AHCT ΔICC で数〜11 mA が最小負荷 5 mA 議論に効く（予算査読）。RS6 損失は効率曲線代用＋無負荷 55 mA max。箱内はレギュレータ損失だけでなく PD 入力ほぼ全部が熱。

**なぜ効くか** — L7805C 単体で箱を焼く筋は弱い。箱内気温が上がると HP・LDO の余熱が乗る。

**確度** — 一次（予算査読・L78 DS）。箱の通風は未設計〔推論〕。

**外れる条件** — 通風・ヒートシンク・連続コイル通電バグなし。

**判定:** 修正（箱内熱の合計）。重さ: 聴こえる。

---

### 1.9 [要確認] AZ850P2-5 両役 — 入手は易、電源役は DS 外

**何が** — §2-2: 音声・電源とも AZ850P2-5（秋月実績、`PARTS.md`）。容量負荷メイクは抵抗負荷 1 A の規定外 → V21-実測-11。隣接 5.0 mm 推奨（AZ850 p2 NOTES 6）。娘 1 枚 3 個×4＝12。TQ2-L2 はピン非互換で挿せない。

**なぜ効くか** — 品種統一は実装・BOM に有利。電源役の寿命・溶着は実測待ち。5 mm を縦積み上下にも守ると板面積と段高さが増える。

**確度** — 一次（DS・DECISIONS）。

**外れる条件** — 実測-11 が合格／電源用だけ 2 A 級へ分離。

**判定:** 条件つき支持。重さ: 入手は無害、電源接点は聴こえる。

---

### 1.10 [軽微] 充電器 12 V/3 A は足りる。再交渉は穴

**何が** — §3-13: UGREEN 200 W の C1〜C4 に 12 V/3 A（ユーザー確認）。PD 最悪約 1.3 A。CH224K はジャンパはんだ固定（説明書）。ほかポート機器での再交渉は「確かめられず」。

**なぜ効くか** — 電流枠は余裕。再交渉で 12 V が落ちると規則①で全リセット、聴取中断。ジャンパ外れは 9 V/5 V へ（UVLO・検知「無し」）。

**確度** — PDO はユーザー一次。再交渉は未測。

**外れる条件** — 専用ポート運用／再交渉で 12 V 維持を実測。

**判定:** 支持＋穴。重さ: 電流は無害、再交渉は聴こえる〜損傷。

---

### 1.11 [要確認] 代替困難さのまとめ（単点の重なり）

| 部品 | 単点の中身 | 次善 |
|---|---|---|
| NJW1194 | スルー＋音量の単体 | 未定（C1' は床が戻る） |
| RS6-1215D | ±200 mA・Cout 660 µF・軽負荷帯 | TMR9 等は制約あり |
| AZ850P2-5 | ピン互換のセカンドソース不可（TQ 等） | 品種変更＋駆動見直し |
| TMUX7612 | 電源断規定の穴がコールドスタンバイを決めた | 電源断保護 SW は別アーキ |

**判定:** 穴（控えの欠落）。重さ: 重なると **損傷**。

---

## 2. 問題なし

- **R1 の RS6 容量（設計点 max 約 63 %）** — `power_budget_v21`／`_review` で算術再現。悲観重ねても 1 ch で約 80 %。容量不足では棄却できない。
- **TMUX7612 の流通（カットテープ・MOQ1）** — `PARTS.md` の DigiKey 実ページ記録。入手自体は問題にならない。
- **AZ850P2-5・TBD62083A の入手・THT** — 秋月／既存実績。手実装は SSOP／TSSOP より易しい。
- **L7805C 定常散逸** — 聴取中コイル 0 なら損失は小さい。パルス 3.9 W は ms 級。
- **ch LDO の定常熱** — (15−12)×DUT 電流は数十 mW。θJA 63 °C/W でも問題にならない。
- **トーン LDO 損失 ≈0.14 W／側** — 熱単体では問題にならない。
- **充電器 3 A 対最悪 1.3 A** — 枠としては足りる（ユーザー確認の 12 V/3 A 前提）。
- **リレー間隔 5 mm を制約と書いたこと** — DS どおり。守る前提なら正しい。

---

## 3. 確かめられず

- RS6-1215D の**現時点の正規在庫・納期・単価**（§10-1。本査読では流通サイト未取得）。
- Arrow 上の NJW1194 の**数量・最小発注・納期**（ユーザー確認の再検証不可。LCSC は在庫 0）。
- **鉛フリー手半田**で SSOP32／TSSOP-16×16／HVSSOP PowerPAD×34 を組めるか（決定・PARTS に工程の記載なし）。
- HP DIP 化モジュール**内部パッケージ**（SOIC か VSSOP か）とソケット越しの実効 θJA。
- 縦積み 4 段の**実寸模型**での DIP 到達（未決-20）。
- 充電器の**他ポート再交渉**で 12 V が切れるか（§3-13）。
- AZ850 の**容量負荷メイク寿命**（V21-実測-11 未実施）。
- RS6 の**突入・OLP の形**（V21-実測-01）— 親バルク・22 Ω ヒューズ抵抗の品番選定に効く。
- 箱の**通風・内気温**（3.7〜7.4 W を受けた実温度）。
- ヒューズ抵抗・速断チップヒューズの**I²t／単発パルス曲線**（§10-1、DS 未収集）。

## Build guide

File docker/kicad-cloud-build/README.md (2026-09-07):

# KiCad 10.0.6 クラウドビルド環境

`kicad-cli`（KiCad 10.0.6）をソースからビルドするDockerイメージと、それを使ってこのリポジトリの基板ファイルをヘッドレス検証するラッパースクリプト。GUIなしで ERC・ネットリスト出力・DRC・Gerber出力などをCIやクラウド上で実行するためのもの。

| ファイル | 役割 |
|---|---|
| `Dockerfile.10.0.6-ppa` | `kicad-cli` 10.0.6 を **PPA から**入れるイメージ定義。**約2分** |
| `Dockerfile.10.0.6` | 同じ 10.0.6 を**ソースビルド**するイメージ定義。約45分 |
| `kicad-ppa-10.0.asc` | `ppa:kicad/kicad-10.0-releases` の署名鍵（同梱。指紋は使う側が必ず検証する） |
| `kicad-run.sh` | リポジトリのファイルに対して kicad-cli を回すラッパー |
| `sch_drift.py` | 旧構成向けの回路図突き合わせ（S式パーサ + 差分）。**`kicad-run.sh` からは呼ばれない**（下の「生成スクリプトと実図の突き合わせ」） |

イメージの作り方は2つあり、**できあがる `kicad-cli` は同じ 10.0.6**。違うのはビルド時間と、PPA に依存するかどうかだけ。

- **`Dockerfile.10.0.6-ppa`**（既定）— `ppa:kicad/kicad-10.0-releases` に noble 向けの 10.0.6 がある。約2分。署名鍵を同梱しているので `add-apt-repository` も keyserver への HTTPS も要らず、**HTTP しか通らない制限された網でもビルドできる**。
- **`Dockerfile.10.0.6`** — KiCad公式リポジトリの `10.0.6` タグから直接ビルドする。レシピは KiCad 公式の [`kicad/packaging/kicad-docker`](https://gitlab.com/kicad/packaging/kicad-docker)（`Dockerfile.10.0-stable`）をベースに、Debian trixie 向けの内容を Ubuntu 24.04 用のパッケージ名に置き換えたもの。**PPA から 10.0.6 が消えたらこれが唯一の再現手段に戻るので、消していない。**

公式の Docker Hub イメージ (`kicad/kicad`) は 2026-09-07 時点でまだ 10.0.5 止まりで、10.0.6 が無い。Ubuntu 標準アーカイブは 7.0.11。

**Docker を使わずホストに直接入れる**なら [`scripts/cloud-agent-setup.sh`](../../scripts/cloud-agent-setup.sh)（冪等）。下の「Cloud Agent 環境での使い方」の対応表を参照。

---

## クイックスタート

```sh
# 1. イメージをビルド（初回のみ・約2分）
docker build -f docker/kicad-cloud-build/Dockerfile.10.0.6-ppa \
  -t kicad-cloud:10.0.6 docker/kicad-cloud-build

# 2. AudioV2 全体の ERC を実行
docker/kicad-cloud-build/kicad-run.sh erc
```

`kicad-run.sh build` はソースビルド版（`Dockerfile.10.0.6`・約45分）を回す。

出力は `out/erc.json` と `out/erc.rpt`。標準出力には違反の種別ごとの集計が出る（下は `KICAD_BACKEND=local` で実行したときの例）。**件数は 2026-09-01 の実測で、現在の期待値は [`CLAUDE.md`](../../CLAUDE.md) が正**（ここでは追随しない）。

```
ERC: AudioV2/AudioV2Case.kicad_sch  (backend=local, image=kicad-cloud:10.0.6)

ERC 違反 合計 54 件
  error     pin_not_connected                30
  error     label_dangling                   12
  warning   isolated_pin_label                9
  error     power_pin_not_driven              2
  warning   lib_symbol_issues                 1
出力: /path/to/pcb_work/out/erc.json, /path/to/pcb_work/out/erc.rpt
```

`out/` は `.gitignore` 済み。リポジトリは**読み取り専用でマウント**されるため、検証実行が作業ツリーを書き換えることはない。

---

## `kicad-run.sh`

### コマンド

| コマンド | 内容 |
|---|---|
| `erc [SCH]` | ERC実行。既定の対象は `AudioV2/AudioV2Case.kicad_sch`（階層ルート）。`out/erc.json` + `out/erc.rpt` |
| `netlist [SCH]` | ネットリスト出力（kicadsexpr）。`out/netlist.net` |
| `cli ARGS...` | 任意の `kicad-cli` コマンドをそのまま実行 |
| `version` | 使用中の kicad-cli のバージョン |
| `shell` | コンテナ内で対話シェル（dockerバックエンド専用） |
| `build` | イメージをビルド |

`erc` に `--strict` を付けると、違反があるとき非ゼロで終了する（CI用）。

```sh
# AudioV2 全体
docker/kicad-cloud-build/kicad-run.sh erc

# シート単位（例: 母板だけ）
docker/kicad-cloud-build/kicad-run.sh erc AudioV2/MotherBoard.kicad_sch

# 違反があれば失敗させる
docker/kicad-cloud-build/kicad-run.sh erc --strict

# ネットリスト
docker/kicad-cloud-build/kicad-run.sh netlist
```

### 生成スクリプトと実図の突き合わせ（`drift` は廃止）

`kicad-run.sh drift` と、それが使っていた「`wire_circuit_design.py` を一時ディレクトリで回して
実図と突き合わせる」仕組みは **2026-09-03 に削除した**。理由は2つ。

- **前提が消えた。** 構成刷新で現行シートを作るのは `AudioV2/scripts/build_motherboard.py` /
  `build_daughter.py` になり、`wire_circuit_design.py` は**どのシートも書き出さない**
  （旧構成のロジックの記録として残っているだけ）。drift はそれを回していたので比較対象が空になる。
  `--force-*` で無理に書かせても出てくるのは `AudioV2/legacy/` に凍結された旧シートで、
  **現行シートは全部「対象外・比較していない」に落ちる**。実際の出力は
  「リポジトリ側に旧シートが無い＝乖離あり」という**逆向きの警告**になっていた
- **もともと配線の検証には使えない。** ワイヤ・ジャンクション・`no_connect` の実配線と、
  ラベルがどのワイヤに付いているかを比較対象に入れていない
  （[`CLAUDE.md`](../../CLAUDE.md)・[`AGENT_HANDOFF.md`](../../AudioV2/AGENT_HANDOFF.md) §2.8）

代わりに使うもの:

| 見たいもの | 道具 |
|---|---|
| 生成スクリプトと実図のズレ | **生成スクリプトを回して `git diff` が空か見る。** 母板・娘基板の生成は冪等でバイト一致する（[`CLAUDE.md`](../../CLAUDE.md)）ので、これが drift より強い検査になる |
| 統合・移設で接続が保たれたか | **`AudioV2/scripts/netlist_partition.py`** — ネットリストを「ピン集合の集合」で比較する |
| 接続そのもの | `kicad-run.sh erc` / `kicad-run.sh netlist` |

`sch_drift.py` はファイルとしては残してある（旧構成向けの突き合わせとして手で回せる。
`sch_drift.py GEN_DIR REPO_DIR`）。**ただし上記のとおり配線は見ないので、接続の検証にはならない。**
どのシートを誰が作るかは [`CLAUDE.md`](../../CLAUDE.md) と
[`AGENT_HANDOFF.md`](../../AudioV2/AGENT_HANDOFF.md) §2.8 が正。ここでは重複させない。

### `cli` によるパススルー

`erc` / `netlist` 以外は `cli` で任意のコマンドを渡せる。引数中の `@WORK@` はリポジトリルート、`@OUT@` は出力ディレクトリに置換される（Docker実行時はコンテナ内パス、ローカル実行時はホストパス）。

AudioV2 の PCB はまだ未設計（`AudioV2Case.kicad_pcb` は空のスキャフォールドだけ）。以下は旧 `Audio/`
の基板を例にした PCB 系の実行例で、AudioV2 の PCB を起こしたら同じ形でパスを差し替える。

```sh
# BOM 出力（AudioV2 の階層ルートから。子シートも含めて集計される）
docker/kicad-cloud-build/kicad-run.sh cli sch export bom --group-by Value \
  -o @OUT@/bom.csv @WORK@/AudioV2/AudioV2Case.kicad_sch

# DRC / Gerber / ドリル（旧 Audio プロジェクトの基板を例に）
docker/kicad-cloud-build/kicad-run.sh cli pcb drc --format json \
  -o @OUT@/audio-drc.json @WORK@/Audio/split/AudioCase_4_amp.kicad_pcb
```

### バックエンド

既定は `auto`。イメージ `kicad-cloud:10.0.6` があればそれを使い、無ければホストの `kicad-cli` にフォールバックする。どちらも無ければビルド方法を案内して終了する。

| 環境変数 | 既定 | 内容 |
|---|---|---|
| `KICAD_IMAGE` | `kicad-cloud:10.0.6` | 使用するイメージ |
| `KICAD_BACKEND` | `auto` | `auto` / `docker` / `local` |
| `KICAD_OUT` | `<repo>/out` | 出力ディレクトリ |

```sh
# Docker を必ず使う（ホストに別バージョンの kicad-cli があるときに）
KICAD_BACKEND=docker docker/kicad-cloud-build/kicad-run.sh erc

# ホストの kicad-cli を使う
KICAD_BACKEND=local docker/kicad-cloud-build/kicad-run.sh erc
```

ローカルフォールバックはホストの kicad-cli のバージョンに依存する。**バージョン差が結果に効く検証では `KICAD_BACKEND=docker` を明示すること。** `version` サブコマンドで実際に使われている版を確認できる。

---

## イメージのビルド

`kicad-run.sh build` は次と等価:

```sh
docker build -f docker/kicad-cloud-build/Dockerfile.10.0.6 \
  -t kicad-cloud:10.0.6 docker/kicad-cloud-build
```

ソースを `gitlab.com` から `git clone` し、そこから ninja でフルビルドするため、初回は数十分かかる（実測で約45分）。2回目以降は Docker のレイヤーキャッシュが効く。

HTTPSプロキシ経由でしかgitlab.comに出られない環境では `--build-arg HTTPS_PROXY=http://...` を渡す（`kicad-run.sh build --build-arg ...` でそのまま透過する）。プロキシがTLSを終端して独自CAを使っている場合は、Dockerfile内の `ca-certificates` インストール行の前に、そのCA証明書を `/usr/local/share/ca-certificates/` へ `COPY` して `update-ca-certificates` を追加する必要がある。

---

## 直接 `docker run` する場合

`kicad-run.sh` を使わない場合の同等コマンド。イメージの既定ユーザは非rootの `kicad`（uid 1001）なので、ホスト側の所有権を合わせるため呼び出し元の uid/gid で実行し、その uid にホームが無いぶんを `HOME` とグローバル lib-table のコピーで補っている。

```sh
mkdir -p out
docker run --rm \
  -u "$(id -u):$(id -g)" \
  -e HOME=/tmp/kicad-home \
  -v "$PWD":/work:ro \
  -v "$PWD/out":/out \
  -w /work kicad-cloud:10.0.6 \
  bash -c '
    v=$(kicad-cli -v | cut -d . -f 1,2)
    mkdir -p "$HOME/.config/kicad/$v"
    cp -n /usr/share/kicad/template/*-lib-table "$HOME/.config/kicad/$v/" 2>/dev/null || true
    exec "$@"
  ' _ kicad-cli sch erc --format json --severity-all \
      -o /out/erc.json /work/AudioV2/AudioV2Case.kicad_sch
```

`-u` を付けずに既定の `kicad` ユーザで走らせる場合は、`out/` をそのuidから書けるようにしておくこと（例: `chmod 777 out`）。

## バージョン確認

```sh
docker/kicad-cloud-build/kicad-run.sh version
# => 10.0.6
```

---

## 動作確認済み事項

- `mirror.gcr.io` 経由のベースイメージ + `gitlab.com` からのソース取得で、Docker Hub のイメージ配信やKiCad公式サイトへの直接アクセスが制限された環境でもビルド可能なことを確認済み。
- `Audio/split/AudioCase_4_amp.kicad_pcb` に対して実際に DRC・Gerber・ドリル出力を実行し、成功を確認済み（DRC違反7件検出）。
- `drift` は **2026-09-03 に削除**（理由は上の「生成スクリプトと実図の突き合わせ」）。2026-09-01 の確認記録もここから外した。削除したのは `drift` 専用のコードと `--help` の記述だけで、`erc` / `netlist` / `cli` / `version` / `build` の引数解釈には触っていない（`AudioV2/scripts/gen_parts_bom.py` が `cli` 経由で BOM を出すため、ここの互換性は壊せない）。
- `kicad-run.sh` の `erc` / `netlist` / `cli` / `version`、`erc --strict` の非ゼロ終了、存在しないファイルのエラー処理は **`KICAD_BACKEND=local`（kicad-cli 10.0.6）で実行確認済み**。プロジェクトツリーを読み取り専用にした状態でも ERC が完走することを確認しており、`:ro` マウント前提の設計はこれに基づく。
- **未確認**: Docker バックエンド経由の実行（イメージが未ビルドのため）。初回は `kicad-run.sh build` の後に `kicad-run.sh version` で 10.0.6 が返ることを確認すること。

---

## Cloud Agent 環境での使い方

Cursor Cloud Agent の VM には Docker が入っていないので、Dockerfile を `docker build` する経路は使えない。

代わりに、ランタイム成果物（`kicad-cli` 10.0.6 + シンボル / フットプリント / テンプレート）を **apt パッケージで揃える**。その手順が [`scripts/cloud-agent-setup.sh`](../../scripts/cloud-agent-setup.sh)（冪等・[案内](../../scripts/README.md)）で、ダッシュボード管理環境の `install` コマンドとして実行する想定。

**Claude Code on the web も同じスクリプトを通る。** コンテナは回収されると消えるので、毎セッション何も入っていない状態から始まる。それを埋めるのが `.claude/hooks/session-start.sh` で、中身は書かずに `scripts/cloud-agent-setup.sh` を呼ぶだけにしてある（`CLAUDE_CODE_REMOTE=true` のときだけ動くので、手元の macOS / Windows では何もしない）。

> **`~/.config/kicad/<ver>/*-lib-table` を置き忘れると ERC が壊れる。** `kicad-cli` とシンボルが入っていても、これが無いと標準ライブラリを解決できず `lib_symbol_issues` 197 件 + `footprint_link_issues` 161 件の偽陽性が乗り、**ERC が 29 件ではなく 387 件になる**（2026-09-07 実測）。`cloud-agent-setup.sh` も Dockerfile も `kicad-run.sh` の docker バックエンドも、それぞれこのコピーをしている。手で入れたときだけ抜ける。

| `Dockerfile.10.0.6` | `Dockerfile.10.0.6-ppa` / `scripts/cloud-agent-setup.sh` |
|---|---|
| KiCad 10.0.6 をソースからフルビルド | PPA `ppa:kicad/kicad-10.0-releases` から `apt install kicad`（Ubuntu 24.04 で 10.0.6） |
| `kicad-symbols` / `kicad-footprints` / `kicad-templates` を gitlab から clone して install | 同名の apt パッケージ |
| `ngspice` を apt で導入 | 同じ |
| ユーザー設定へ `*-lib-table` をコピー | `~/.config/kicad/<ver>/` へ同じファイルをコピー |
| 3Dモデル (`kicad-packages3d`) は入れない | `--no-install-recommends` で `kicad-libraries` 経由の巻き込みを避ける（展開 ~5.6GB） |
| （対象外） | `uv` / `uvx` — `uvx kicad-mcp-pro` 用。root [README](../../README.md) の「前提」参照 |

**ローカルで回せない検証をクラウドエージェントへ投げるための導線がこれ。** ERC / ネットリスト / DRC / Gerber が向こう側でも同じ結果になることを、パッケージ構成をこの表で Dockerfile に揃えることで担保している。

> スナップショットを取り直したら `kicad-cli version` が `10.0.6` を返すことを確認する。PPA は 10.0 系の最新を出すので、将来 10.0.7 以降に上がるとホスト側の `KICAD_BACKEND=local` と版がずれる。**版差が結果に効く検証では Docker バックエンドを明示する**（上の「バックエンド」節）。

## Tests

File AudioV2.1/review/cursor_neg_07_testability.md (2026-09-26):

# v2.1 否定側査読 — ⑦ 起動・テスト可能性・デバッグ（Cursor・追加観点）
- 作成: 2026-09-26（Cursor 並行査読、読み取り専用）
- 対象: `/tmp/v21-claude/DECISIONS.md` §5・§6・§10 と電源・制御の足場、`NOW.md`、`design_eval_review.md` の C 項目（必要時 `ds_facts/`）。`AudioV2/`・`Audio/` 文書は未読。図は未実装の前提で文書だけを潰した。

## 0. 結論（表）

| # | 重さ | 指摘 | 確度 |
|---|---|---|---|
| ⑦-1 | **要確認** | 初回 bring-up／単体試験の切り方が DECISIONS・NOW に無い。実装順は「査読→娘・親の図」へ飛び、観測手順が無い | 文書事実 |
| ⑦-2 | **要確認** | `MON`/`PG_N` は全段 OR。どの娘・どのレール・ch LDO かを切り分けられない。TP 一覧も無い | 文書事実＋推論 |
| ⑦-3 | **要確認** | ファーム無しのハード安全は §6-1 で厚いが、「デバッガ停止中」「娘だけ／親だけ」の試験切りは未定義。差し替えモードは評価にあって §6-2 に無い | 文書事実 |
| ⑦-4 | **要確認** | DNP／0 Ω 足場は多いが、「いつ・何を載せて何を切り分けるか」の使い方が無い | 文書事実 |
| ⑦-5 | **要確認** | §10 に C1（PD 突入・5 V 窓）・C4（E9／ADC IE／WDT）が ID として無い。実測-02 の手順が §3-13 と食い違う | 文書事実 |
| ⑦-6 | **要確認** | 2×12 ピン配置未確定のまま実装へ進むと、MON と論理の隣接禁止・観測アクセスが PCB 一発でロックされる | 文書事実＋推論 |
| ⑦-7 | 軽微 | ソケット短絡用の「整定後 ≈13 V」しきい値（評価 B1）が §6-2 に必須化されていない | 文書事実 |
| — | — | ファーム無しの既定 OFF・電源検知 AND・B1/B2・排他ゲートの骨格自体は、起動安全の観点では問題を見つけにくかった | — |

**総評:** 動作中の安全網（§5・§6-1）は厚い。欠けているのは「組み立てて最初にどう切って測るか」と、OR 観測だけでは足りない故障分離、§10／C の突合せ、レイアウト前に固定すべきピンと TP である。

## 1. 指摘詳細

### [要確認] ⑦-1 初回 bring-up と単体試験の切り方が文書に無い

**何が** — NOW の「次にやること」は否定側査読のあと、娘（電源／音声リレー・ゲート・デコーダ・B1/B2・排他）と親（RS6・ADC・検知・制御 MCP・NJW1194…）の実装へ進む。DECISIONS §5・§6・§10 にも、段階（例: 親だけの PD／`+5V_D` → RS6 無負荷 → 娘 0 枚で全リセットと `MON` 空 → 娘 1 枚で PSET のみ → 音声 SET → ch EN）の手順が無い。  
**なぜ効くか** — ラッチング・縦積み・共通音声 SET・OR の `MON` は、一括配線してからだと「誰が生きているか」が最初から曖昧になる。単体で親と娘を切れないと、初回短絡・溶着・ジャンパ重複をファーム手順の奥まで持ち込む。  
**確度** — 文書事実（NOW L22、§6-2 は運用手順のみ）。  
**外れる条件** — 別文書に bring-up 手順がある／実装担当が口頭で同じ段階を守る、と明示される場合。

### [要確認] ⑦-2 `MON`/`PG_N` だけでは故障分離できず、TP も未定義

**何が** — §5-2: 各娘の生レールをダイオード OR → 親で分圧 → Pico ADC。`PG_N` は「どれかの娘に両レールあり」のワイヤード OR。規則③（§5-7）は全リセット後に `MON` が約 10 V を割ることで「戻らないリレー」を見る。DECISIONS 全体に、親の `PD_12V_SW`／±15 V／`+5V_COIL`／分圧後 `MON`／娘ローカル ±15 V（22 Ω 後）／ch LDO ±12 V／`AMP_SEL` などの**測点（TP）一覧が無い**。§4-14 の外出し端子は聴取用で、電源・制御の bring-up 用ではない。  
**なぜ効くか** — OR は「どれかがある」しか言わない。溶着・ジャンパ重複・片レール落ち・ch LDO 短絡をオシロ／DMM で切り分けるとき、どこに当てるかがレイアウト後まで決まらない。`MON` は生の ±15 V 側で、ch LDO 出力の短絡は間接（レール落ち込み）にしか見えない。  
**確度** — 文書事実（§5-2・§5-7・§2-5）＋推論（観測点の欠落が切り分けを阻害する）。  
**外れる条件** — スタック 24 本のピン配置で各娘ローカルレールや段 ID を探針できると決める／PCB で TP をネット名付きで置く、と実装前に書く場合。

### [要確認] ⑦-3 ファーム無しの「箱としての安全」は厚いが、「試験切り」とデバッガ経路が穴

**何が** — §6-1: B1/B2、`RAIL_OK` 能動 High、電源検知∧MCP RESET、排他ゲート、EN≤IN、デコーダ既定 OFF は、ファームが止まっても「つながない・両コイル同時通電しない」向き。一方 §5-3 前提: BOOTSEL・デバッガ停止・起動中は WDT も助けない／High 出しっぱなしのハングは B1/B2 頼み。design_eval B11 の「差し替えモード（全リセット→放電確認→LCD）」は §6-2 に無い。娘だけ／親だけでコイルを手で叩く手順も無い。  
**なぜ効くか** — 初回はほぼ必ず SWD／REPL で止める。その間 `RAIL_OK` と MCP の状態は「完成品の安全証明」の外。差し替えモードがファーム責務に無いと、運用約束（電源切って抜き挿し、§6-2）以外の安全な差し替え観測点が無い。  
**確度** — 文書事実（§5-3・§6-1・§6-2、design_eval B11）。  
**外れる条件** — デバッガ使用時は電源 SW OFF を必須にする／差し替えモードを §6-2 に入れる／制御線を外して娘単体治具で試す、と書く場合。

### [要確認] ⑦-4 DNP／0 Ω 足場の「使い方」が bring-up 手順になっていない

**何が** — 足場はある: CMC 0 Ω（§3-9）、−15 V プリロード DNP（§3-10）、HP 電源 RC（§3-11）、親 +100 µF 任意（§3-6）、Q1 戻し／GND ヘッダ（§4-3・§4-4）、RCOM 0 Ω（§4-8）、VCOM・I²S 0 Ω（§4-11）、電源断 GND 落としは R=0 Ω・リレー類 DNP（§2-10）、NJW1194 まわりの 0 Ω／置き場（§1-6）。どれも「実装するかは実測後」で、**どの段階でどの足場を載せて何を切り分けるか**が無い。§4-9 の予備 12 V は SW 迂回で bring-up に使えるが、同時給電の並列と検知「有り」固定の副作用だけの注記。  
**なぜ効くか** — 足場は「後で直せる」ためのもので、初回切り分けの手順書ではない。0 Ω のまま音を出してから CMC／プリロード／RC を載せる順序を間違えると、原因が電源・制御・音声のどこか分からない。予備入口は「SW 無しで動く」試験に便利な一方、§5-7 の検知を常時「有り」にしうる。  
**確度** — 文書事実。  
**外れる条件** — 足場ごとに「未実装で測る項目／実装して測る項目」の表を §10 か NOW に足す場合。

### [要確認] ⑦-5 §10 の抜け — C 項目との突合せと実測-02 の手順矛盾

**何が**  
1. design_eval **C1**（使う充電器で PDO・主 SW 突入・再交渉・12 V 不出時に 5 V 窓が続くか）は §3-13 で「C1 の実測」と参照されるが、§10-1 に **V21-実測 ID が無い**。V21-実測-03 は充電器↔リニア／電池の**音の A-B-A**で、C1 の起動・損傷側とは別。  
2. **C4**（`CHIP_ID.REVISION`／MicroPython ADC の IE／WDT の pad 復帰）は §10 に無い。§5-2・B9 の E9・比率校正・`RAIL_OK` の信頼に直結。  
3. **C3**（縦積みの手の届き）は V21-未決-20 のまま。観測・差し替えの物理アクセス。  
4. V21-実測-02 の表は「1 ch・無音・軽い石」、§3-13 は「待機（娘すべて OFF）で測る」— **同じ ID で手順が食い違う**。  
5. NOW が挙げた NJW1194 実物確認（本物か、スルー段、雑音、電源断時入力電流）も §10 に ID が無い。  
6. 評価 B1 の「整定後 ≈13 V」しきい値・ソケット短絡の必須規則は §6-2 に未反映（⑦-7）。  
**なぜ効くか** — NOW は「基板前に要るのは実測-01」とだけ言い、C1 を基板前必須に格上げしていない。PD 突入でヒューズ／交渉失敗すると bring-up 自体が始まらない。C4 未測のまましきい値とプルダウンを固めると、監視が誤「良／不良」になる。実測-02 の負荷条件が二つあると、プリロード DNP 判断が再現できない。  
**確度** — 文書事実。  
**外れる条件** — C1/C4 を §10 に採番して順序を書く／実測-02 を一方に直す／NJW 実測を §10 に載せる場合。

### [要確認] ⑦-6 実装順で戻れない決定 — ピン配置・コネクタ・観測幾何

**何が** — §2-5: 24 本内訳はいったんの決め、**ピン配置は未確定**。§5-2: `MON` を論理線の隣に置かない。V21-実測-01 は基板前必須と書いてあるが、NOW の実装列挙はそれをゲートにしていない。娘 MCP 廃止（§2-12）で段ごとの I²C デバッグは消えた。B7 毎回全リセットは寿命・音・所要をロック済み。  
**なぜ効くか** — 親・娘同時に 2×12 を切ると、ピン間違い・MON 隣接・探針不能は両方の再版になる。段ジャンパの重複は §2-6 前提で残る弱点で、OR の `MON` では「2 枚同時給電」の切り分けが弱い。実装を図から始めると、観測点を後付けする銅が無い。  
**確度** — 文書事実＋推論（コネクタ／ピンは一発ロック）。  
**外れる条件** — ピン配置＋TP 表を図の前に閉じる／実測-01・C1 を NOW の着手条件に明示する／片方だけ先に治具ピンで試す場合。

### [軽微] ⑦-7 ソケット短絡の観測がファーム案のまま

**何が** — design_eval B1: 立ち下がり 10.5 V ではソケット短絡後の娘レール 10.2〜11.1 V を取り逃しうる → 整定後 ≈13 V を必須に。§6-2 にその行が無く、「迷惑トリップを無限再試行しない」は未決（推奨）。  
**なぜ効くか** — 石差し替えが目的の装置で、初回・運用ともいちばん起きる故障の分離が、ハードの `MON` 帯とファーム未決の間に落ちる。  
**確度** — 文書事実（評価 B1 vs §6-2）。  
**外れる条件** — B1 を §6-2 に必須で書き、しきい値 2 段を bring-up チェックリストに入れる場合。

## 2. 問題なし

- §6-1 のハード保証一覧（B1/B2、電源検知 AND、排他、EN≤IN、デコーダ既定 OFF、NC／バスの DC 基準）は、**完成後・ファーム無し／停止時にバスへつながない**方向として文書上つながっている。  
- §5-7 規則①（起動時すでに検知あり）は、Pico が `PD_12V_SW` 系から来る前提と整合し、USB 先挿しでも主 SW 後に全リセットが走る筋がある。  
- 規則③（全リセット後 `MON` 下降確認）は、OR の弱点（古い娘のレールを「良」と見せる）に対する、ハード追加無しの検出手順として評価 A2 と一致。  
- `PG_N` で `MON_N` 上側開放の誤「良」を別ビットで見る（§5-2／A5）は、監視の妥当性チェックとして足りる最小限。  
- LM4040 を ADC0（旧 `DEST_ADC`）で比率校正する割り当ては、監視の再現に必要で、DEST 位置センス廃止と矛盾しない。  
- V21-実測-01 を「基板を起こす前」と明示している点は、電源系の不可逆（+100 µF・22 Ω 電力）に対して順序が正しい。  
- Q1 戻しヘッダ、RCOM／VCOM／I²S／CMC／プリロード／HP RC など、**音・電源の後追い変更用足場**自体は、テスト可能性の「後から直す」側としては揃っている。

## 3. 確かめられず

- 図がまだ v2 写しのため、実際のネット上に TP・ヘッダ・探針スペースがどう置けるかは未確認（文書レビューの限界）。  
- Pico 2 基板 DS・MicroPython の ADC IE／WDT 範囲（C4）— リポジトリ外。監視・`RAIL_OK` の bring-up 挙動は実機待ち。  
- RS6 OLP・AZ850 max リセット・入力結合整定（実測-01/05/12）未実施のため、規則③の待ちと自動リセットの時間予算は数値で閉じられない。  
- 24 本ピン配置案が「MON を論理の隣に置かない」を満たすかは、配置案が無いので判定不能。  
- 娘単体を親無しで動かす治具（`+5V_COIL`・レベル・±15 V）の要否は、方針が書いていないので要否自体を文書から決められない。  
- NJW1194 実物のスルー段・電源断入力電流は NOW が「実物が来たら」としており、観測手順は未記載。

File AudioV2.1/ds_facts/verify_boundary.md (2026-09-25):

# 境界スイッチ候補 DS 事実表の独立照合（boundary.md）

- 照合日: 2026-09-25
- 対象: `AudioV2.1/ds_facts/boundary.md`（書き換えていない）
- DS: `AudioV2.1/datasheets/boundary/` の 14 本と、`AudioV2.1/datasheets/` の `TI_TMUX7612.pdf` / `ADI_MAX14778.pdf` / `Zettler_AZ850.pdf` / `Panasonic_AQW212EH.pdf`
- やり方: 出典に書かれたページをすべて `pdftoppm -png -r 150` で画像にし、表の罫線・列見出し・ページ見出しの条件・脚注を目で確かめた。
  Panasonic TQ は poppler では文字が描かれないので（`pdftotext` は 150 バイト、`pdftoppm` の画像は罫線だけ。boundary.md §3.3 の記述どおり）、scratchpad に置いた PyMuPDF 1.28.2 で本文を抜き、ページ画像も PyMuPDF で描いた。
  「DS に無い」とされた項目は、各 DS の全文（`pdftotext -layout`）をキーワードで探したうえで、該当しそうなページを画像で見た。
  グラフは boundary.md の数値を見る前に自分で読んだ。TMUX4821 Figure 13-21 と DG458 の「Input Leakage vs. Input Voltage」は PyMuPDF で 400〜576 dpi 相当に描き、軸ラベルの座標から較正して画素で境界・曲線を拾った。そのほかのグラフは 5 倍に拡大して目で読んだ。
  作業ファイルは scratchpad の `verify_boundary/` にある。
- 照合した行: **表の行 337 行**（boundary.md の表の全データ行）＋ **表の外の記述 30 件**（「取得した DS」の下の文 2 件、§1.0 の総論 1 件、§1.6 の前書き 1 件、他のスイッチ DS の検索結果 1 件、§2 冒頭 1 件、§3.3 の poppler の注 1 件、「どの DS にも無かった項目」の箇条 23 件）＝ **367 件**
- 判定の内訳: **一致 330**／**一致・補足あり 27**／**誤り 7**／**条件の誤り 1**／列の誤り 0／引用が無い 0／**確かめられず 2**

## 要約

**(a) 電源断保護つきアナログスイッチ・(b) PhotoMOS・(c) ラッチリレーのどれを選ぶかを変える誤りは無かった。** 比較の決め手になる行は、どれも DS の値・列・条件・ページどおりだった。

- **電源断時の漏れ（列・条件つき）:** TMUX4821 の IS(POFF)/ID(POFF)（25°C は typ 0.02 µA だけ、VDD = 0 V・VS = ±15 V）、TMUX741xF / TMUX7462F の IS(FA)/ID(FA) Grounded・Floating（VS = ±60 V、IS(FA) は typ だけ）、ADG5412F/BF の ±40 µA（typ、−40〜+125°C 列だけに印刷）と ±10 nA typ / ±30 nA max、DG458 の ±2 µA（A suffix）/ ±5 µA（D suffix）（VS = ±25 V）は、すべて一致した。
- **どちらの側が守られるか:** TMUX741xF・TMUX7462F・ADG5412F は source 側だけ（drain は電源へダイオード、絶対最大は電源 ±0.7 V）。ADG5412BF は両側。TMUX4821 は S/D 両方の漏れを規定し、本文でも S と D を切り離すと書いている。ここも一致した。TMUX741xF の DS 内の食い違い（§9.3.2.2 は「source と drain の ±60 V を電源断時に遮断」、§9.3.2.5 と絶対最大は「drain は電源を超えてはならない」）も原文どおりだった。
- **TMUX7612 に電源断時の規定が無いこと:** boundary.md のキーワードに加えて absent / removed / no supply / power loss / power down / isolat などでも全文を探したが、電源を切ったときの漏れ・Hi-Z の規定は無かった。あるのは §7.3.5 の電源シーケンス自由と、絶対最大のダイオードクランプの注だけ。
- **TMUX4821:** 単電源 1.8〜5.5 V で VS/VD = −15〜+15 V を通すこと、RON、OISO（−50 dB、**f = 100 kHz**）、CS(OFF) 70 pF、THD+N（表は **VPP = 0.5 V** だけ）はすべて一致した。**Figure 13-21 は自分で画素較正して読んだ値が boundary.md の値と読み誤差の範囲で合った**（推奨領域の上限は 18 Vpp で約 15 kHz、そのすぐ上の約 16.5 kHz から "No Operation Region"。逆に 20 kHz で推奨領域に入るのは約 16.7 Vpp まで。どちらも VDD = 5 V）。
- **ADG5412F/BF:** VS = ±9 V の RON（9.5 Ω typ、10.7 / 13.5 / 16 Ω max。節見出しの条件は VDD = ±13.5 V）、THD+N（0.0015 %、15 V p-p、10 kΩ）、QINJ（−680 pC、CL = 1 nF）は一致した。DYNAMIC CHARACTERISTICS の注 1 に「設計保証、製造試験なし」とある（補足）。
- **DG458:** VD = ±9.5 V の RDS(on) と、電源断時の入力漏れのグラフ（V+ = V− = 0 V）は一致した。グラフの細かい値は、自分の読みの方が少し小さい（下の表）。
- **HI-548:** 「電源喪失時は各入力が 1 kΩ」は p1 の原文どおりだった。
- **MAX14778:** 電源を入れていないときの本文（typ で 1 µA 未満、個体によっては mA 域）は p12 の原文どおりだった。
- **PhotoMOS:** オン抵抗・漏れ・出力容量（TLP241A だけが表値、ほかはグラフ）・LED 電流は、4 品とも値・条件・列が一致した。
- **リレー:** AZ850 の抵抗値（178 / 250 / 125 Ω）と、そこから計算した電流・電力は正しい。DS の「感動電圧での電力」の下限（79 / 56 / 113 mW）は 3.75² を 178 / 250 / 125 Ω で割った値と一致するので、**P2 の 125 Ω は 1 コイルあたりと読むのが DS の中で整合する**（補足）。G6K の最小セット/リセット信号幅 10 ms、TQ の「10 ms 以上を推奨」、TQ の「セットとリセットのコイルに同時に電圧を加えないこと」、G6K・TQ の「リセット位置で出荷、衝撃で変わりうる、初期化せよ」、接点材質、最小開閉負荷、外形は一致した。

### 誤り（7 件と条件の誤り 1 件。どれも選択を変えない）

1. **DG458 の「電荷注入 DS に無い」**（§1.7 の行と §1 末尾の箇条の 2 件）: p6 に典型値のグラフ "QINJ vs. VS"（V± = 15 V、CL = 1 nF で約 −35〜−46 pC、10 nF で約 −45〜−52 pC）がある。表値が無いのは正しい。
2. **§1 末尾「音声帯域の OFF アイソレーション … 1 kHz〜20 kHz はグラフ（ADG5412F Figure 20）だけ」**: DG458 p6 の "Off Isolation and XTALK vs. Frequency"（V± = 15 V、RL = 1 kΩ）が 10 kHz から始まっていて、10 kHz で約 −103 dB。10〜20 kHz はこのグラフにもある。
3. **§2 末尾「オン抵抗は電流 = 最大（1〜2.5 A）での 1 点だけ」**: AQW212EH は IL = Max. = 0.5 A、VO14642A の AC/DC 接続は IL = 1 A（2 A は DC 接続）なので、範囲は 0.5〜2.5 A。また、原点を通る出力の I–V グラフ（AQV252G 図 8、AQW212EH 図 8-1〜8-3、TLP241A Fig. 14.4）がある。直線性や歪みの規定値が無いのは正しい。
4. **G5V-2 の「バウンス時間 DS に無い」**: p3 に "Distribution of Bounce Time"（非ラッチ、Standard / High-sensitivity、各 50 個）がある。
5. **FTR-B3 の「バウンス時間 DS に無い」**: p6 REFERENCE DATA に "Distribution of Bounce Time"（試料 FBR-B3GA4.5Z = 標準型（非ラッチ）、N = 100）がある。
6. **§3 末尾「値として出ているのは G6K の非ラッチ試料のヒストグラムだけ」**: 4・5 のとおり G5V-2 と FTR-B3 にも非ラッチのヒストグラムがある。「ラッチ型のバウンス時間はどの DS にも無い」という前半は正しい。
7. （条件の誤り）**HI-548 の rON の Note 2**: DS は「VOUT = ±10V, IOUT = ∓100µA」。boundary.md は符号が落ちて「VOUT = 10 V、IOUT = 100 µA」になっている（pdftotext が ± を落とす。Note 4 の「±33V」も同じ）。

「誤り」のうち 1・2・4・5・6 は「DS に無い」という主張で、DS にあったもの。

凡例: 「同上」は「boundary.md の値・列・条件・ページのとおり」という意味。引用は DS の画像から読んだ原文。「私の読み」はこの照合で読んだグラフの値。

---

## 0. 取得した DS と版

| 部品 | 項目 | boundary.md の値 | 判定 | DS の実際 | 根拠（原文の引用） |
|---|---|---|---|---|---|
| TMUX4821 | 版・ページ数・同一文書 | SCDS487A – OCTOBER 2025 – REVISED DECEMBER 2025、37 p、TMUX4819 と同一文書 | 一致・補足あり | 各ページの見出しと `pdfinfo`（37 p）どおり。**補足:** `tmux4819.pdf` が手元に無いのでバイト一致は確かめていない。前の作業が scratchpad に残した `TI_TMUX4819.txt` と `TI_TMUX4821.txt` は中身が一致した | "SCDS487A – OCTOBER 2025 – REVISED DECEMBER 2025" |
| TMUX7412F | 版・ページ数・同一文書 | SCDS404B – MARCH 2021 – REVISED NOVEMBER 2022、48 p、7411F / 7413F と同一文書 | 一致・補足あり | 同上（48 p）。**補足:** PDF は 1 本だけ。scratchpad に残る 7411F / 7412F / 7413F の抽出テキストは 3 本とも一致した | "SCDS404B – MARCH 2021 – REVISED NOVEMBER 2022" |
| TMUX7462F | 版・ページ数 | SCDS394B – MARCH 2021 – REVISED JUNE 2023、43 p | 一致 | 同上 | "SCDS394B – MARCH 2021 – REVISED JUNE 2023" |
| ADG5412F | 版・ページ数・作成ソフト | Rev. B（"1/16—Rev. A to Rev. B"）、28 p、Creator: PDFium | 一致 | 改版履歴・ページ下端・`pdfinfo` どおり（Creator / Producer とも PDFium） | "Rev. B \| Page 3 of 28" / "1/16—Rev. A to Rev. B" |
| ADG5412BF | 同上 | Rev. B、28 p | 一致 | 同上 | "1/16—Rev. A to Rev. B" |
| DG458 | 版・ページ数 | Document Number: 70064, S11-1029–Rev. H, 23-May-11、10 p | 一致 | 各ページの下端 | "S11-1029–Rev. H, 23-May-11" |
| HI-546〜549 | 版・ページ数 | FN3150 Rev 7.00, Jun 15, 2016、25 p | 一致 | p1 右上と各ページの下端 | "FN3150 Rev 7.00 Jun 15, 2016" |
| AQV252G | 版・ページ数 | ASCTB144E 202204、15 p | 一致 | 各ページの下端 | "ASCTB144E 202204" |
| TLP241A | 版・ページ数 | Rev.5.0, 2018-01-30、18 p | 一致 | 各ページの右下 | "2018-01-30 Rev.5.0" |
| VO14642A | 版・ページ数 | Rev. 1.8, 21-Aug-2023, Document Number: 81646、11 p | 一致 | 各ページの下端 | "Rev. 1.8, 21-Aug-2023 ... Document Number: 81646" |
| G6K | 版・ページ数 | Cat. No. K106-E1-11、10 p | 一致 | p10 の下端 | "Cat. No. K106-E1-11" |
| G5V-2 | 版・ページ数 | Cat. No. K046-E1-06、4 p | 一致 | p4 の下端 | "Cat. No. K046-E1-06" |
| TQ | 版・ページ数・メタデータ・暗号化 | ASCTB14E 202507、22 p、"Issued Date: July 10,2025"、AES 暗号化 | 一致・補足あり | `pdfinfo` で Keywords "Issued Date: July 10,2025"、"Encrypted: yes (... algorithm:AES)"。**補足:** PDF p18〜p21 は下端が **"ASCTB414E 202408"** で、TQ 本体ではなく汎用の "GUIDELINES FOR SIGNAL RELAYS USAGE" が綴じ込まれている（§3.3 の p18 を引いた行に効く） | "ASCTB14E 202507"（p2〜p17）/ "ASCTB414E 202408"（p18〜p21） |
| FTR-B3 | 版・ページ数 | "Rev. 03/2002"、10 p | 一致 | 最終ページ | "© 2002 Fujitsu Components America, Inc. ... Rev. 03/2002" |
| 既存 4 本 | 版 | TMUX7612 SCDS466A、MAX14778 19-5929; Rev 3; 7/20、AQW212EH ASCTB53J 202601、AZ850 2019-03-26 | 一致 | 各 DS の表紙・下端どおり | "SCDS466A – AUGUST 2023 – REVISED DECEMBER 2024" / "19-5929; Rev 3; 7/20" / "ASCTB53J 202601" / "page 2 of 2 2019-03-26" |
| MAX4533 | 取れなかった | — | 確かめられず | DS が手元に無い | — |

## 1. アナログスイッチ

| 部品 | 項目 | boundary.md の値 | 判定 | DS の実際（値・列・条件・ページ） | 根拠（原文の引用） |
|---|---|---|---|---|---|
| （総論 §1.0） | 電源断時の漏れの試験条件 | どれも ±15〜±60 V の大きな電圧で、±9 Vpk 程度で規定したものは無い（例外は DG458 のグラフ） | 一致 | TMUX4821 ±15 V、TMUX741xF / 7462F ±60 V、ADG5412F/BF ±55 V、DG458 ±25 V。MAX14778 の本文は電圧を書いていない。HI-548 は表値が無い | 各行を参照 |
| TMUX7612 | 電源断時の漏れ・Hi-Z の規定 | DS に無い | 一致 | boundary.md のキーワードに加え、absent / removed / no supply / power loss / power down / isolat でも全文を探した。該当は §7.3.5 と絶対最大の注だけ。"floating" は N.C. ピンと漏れ測定条件の注だけ | "N.C. ... Can be shorted to GND or left floating" / "When VS is at a voltage potential, VD is floating, ..." |
| TMUX7612 | 電源シーケンス | 任意の順 | 一致 | p28 §7.3.5 | "The TMUX7612 supports any power up sequencing. ... when powering down the supply rails can be powered down in any order." |
| TMUX7612 | 端子のクランプ | 注(3) ダイオードクランプ | 一致・補足あり | p4 §5.1。**補足:** 注(3) が付いているのは "IIK Diode clamp current" の行で、VS/VD の行ではない（内容は boundary.md のとおり） | "IIK Diode clamp current(3) –30 30 mA" / "(3) Pins are diode-clamped to the power-supply rails." |
| TMUX7612 | 絶対最大 VS/VD | VSS–0.5 / VDD+0.5 | 一致 | p4 MIN / MAX 列 | "VS or VD Source or drain voltage (Sx, Dx) VSS–0.5 VDD+0.5 V" |
| TMUX4821 | 構成 | 4821 = SPST × 2、4819 = SPDT × 1 | 一致 | p1 Description | 同上 |
| TMUX4821 | パッケージ | DSG (SON, 8) 2 mm × 2 mm | 一致 | p1 Package Information | "DSG (SON, 8) 2mm × 2mm" |
| TMUX4821 | 推奨 VDD | 1.8 / 5.5 V | 一致 | p5 §8 MIN / MAX 列 | "VDD Positive power supply voltage 1.8 5.5 V" |
| TMUX4821 | 推奨 VS/VD | −15 / 15 V | 一致 | 同上 | "VS or VD Signal path input/output voltage (source or drain pin) (Sx, D) -15 15 V" |
| TMUX4821 | 推奨 VSEL | 0 / 5.5 V | 一致 | 同上 | "VSEL Address/Select pin voltage 0 5.5 V" |
| TMUX4821 | 絶対最大 VDD | −0.5 / 6 V | 一致 | p3 §5 | "VDD to GND Supply voltage -0.5 6 V" |
| TMUX4821 | 絶対最大 VS/VD 対 GND | −17 / 17 V | 一致 | 同上 | "Source or drain voltage (Sx, Dx) to ground -17 17 V" |
| TMUX4821 | 絶対最大 同一 ch | −18 / 18 V、注(4) | 一致 | 同上。注(4) は p4 | "(4) Maximum voltage between source and drain pins within the same channel. For example: S1A to D1 or S1A to S1B" |
| TMUX4821 | 絶対最大 別 ch | −24 / 24 V、注(3) | 一致 | 同上 | "Source to drain or source (seperate channel)(3) -24 24 V" |
| TMUX4821 | 注(3) | ダイオードクランプ | 一致 | p4 | "(3) Pins are diode-clamped to the power-supply rails. Over voltage signals must be voltage and current limited to maximum ratings." |
| TMUX4821 | IDC | 1.1 / 0.87 / 0.27 A、VDD = 3.3 V | 一致 | p5 §9 | "DSG 1.1 0.87 0.27 A" |
| TMUX4821 | **IS(POFF)** | 0.02 µA（25°C、typ だけ）、±0.1 / ±2 µA（min / max）、VDD = 0 V、VS = ±15 V / 0 V、VD = 0 V / ±15 V、注(1) | 一致 | p6 §11。25°C 行は TYP 列だけ、温度行は MIN / MAX 列。注(1) は p7 | "(1) When VS is at a voltage potential, VD is 0 V, or when VS is 0 V, VD is at a voltage potential." |
| TMUX4821 | **ID(POFF)** | 同上 | 一致 | 同上 | "ID(POFF) Drain powered-off leakage current(1) VDD = 0 V ..." |
| TMUX4821 | 真理値（VDD = 0） | 全 ch OFF（Hi-Z）、power-off protection | 一致 | p21 Table 15-1 / 15-2 | "0 X(1) All channels are off (Hi-Z). Device is in power-off protection." |
| TMUX4821 | 本文 §15.3.3 | S/D を高インピーダンスで切り離す | 一致 | p22 | "... isolates the source (Sx) and drain (Dx) pins when the supply is removed (Vdd = 0V)." |
| TMUX4821 | 本文（保護が無い場合） | ESD ダイオード経由で逆給電 | 一致 | p1 §3 | "Without this protection feature, any voltage on the switch can back-power the supply rail through an internal ESD diode ..." |
| TMUX4821 | フェイルセーフ論理 | VDD = 0 V で SEL 5.5 V まで、負は保護なし | 一致 | p22 §15.3.6 | 同上 |
| TMUX4821 | プルダウン | 約 6 MΩ | 一致 | p22 §15.3.5 | "The value of this pull-down resistor is approximately 6MΩ." |
| TMUX4821 | 応用例 §16.2.1 | GPIO で電源を切ると高電圧は出力へ伝わらない | 一致・補足あり | p23。**補足:** §16 の冒頭（p23）に「この節は TI の部品仕様ではない」とある。規定値ではなく説明文 | "Information in the following applications sections is not part of the TI component specification, and TI does not warrant its accuracy or completeness." |
| TMUX4821 | RON | 0.16 / 0.20 Ω（25°C）、0.225 / 0.3 Ω、VDD = 2.5〜5.5 V | 一致 | p6 §11。25°C は TYP / MAX、温度行は MAX。VDD = 1.8〜2.5 V の行（0.16 / 0.25、0.26 / 0.3 Ω）もある | "VDD = 2.5 V to 5.5 V VS = –15 V to +15 V ID = –100 mA 25°C 0.16 0.20" |
| TMUX4821 | RON FLAT | 0.0001 / 0.01 Ω（25°C）、0.05 / 0.07 Ω | 一致・補足あり | p6。**補足（DS 内の食い違い）:** p1 は "1mΩ RON-flatness" と書くが、表の typ は 0.0001 Ω（0.1 mΩ） | "RON FLAT ... 25°C 0.0001 0.01" / "With 0.001% THD+N and 1mΩ RON-flatness" |
| TMUX4821 | ΔRON | 0.0008 / 0.03 Ω | 一致 | p6 | 同上 |
| TMUX4821 | IS(OFF) | 0.001 µA、±0.1 / ±1 µA | 一致 | p6 | 同上 |
| TMUX4821 | IDD | 55 / 125 µA | 一致 | p7 | "Logic inputs = 0 V, 5 V, or VDD 25°C 55 125 µA" |
| TMUX4821 | **OISO** | −50 dB、RL = 50 Ω、CL = 5 pF、200 mVRMS、f = 100 kHz、typ | 一致 | p8 §12 TYP 列 | "RL = 50 Ω , CL = 5 pF VS = 200 mVRMS, VBIAS = 0 V, f = 100 kHz 25°C -50 dB" |
| TMUX4821 | XTALK | −100 dB（4821）/ −55 dB（4819） | 一致 | p8 | 同上 |
| TMUX4821 | **CS(OFF)** | 70 pF、VS = 0 V、1 MHz | 一致 | p8 TYP 列 | "CS(OFF) Source off capacitance VS = 0 V, f = 1 MHz 25°C 70 pF" |
| TMUX4821 | CS(ON), CD(ON) | 40 pF | 一致 | p8 | 同上 |
| TMUX4821 | CD(OFF) | DS に無い | 一致 | 表に行が無い。全文にも "CD(OFF)" "drain off capacitance" は無い | — |
| TMUX4821 | QINJ | 5 pC | 一致 | p8 | "QINJ Charge injection VS = 0 V, CL = 100 pF 25°C 5 pC" |
| TMUX4821 | tON / tOFF | 155 / 300 µs、14 µs | 一致 | p8 | 同上 |
| TMUX4821 | tON(VDD) | 175 µs | 一致 | p8 | 同上 |
| TMUX4821 | ACPSRR | −100 dB | 一致 | p8 | 同上 |
| TMUX4821 | **THD+N（表）600 Ω** | −107 / −105 dB、**VPP = 0.5 V** | 一致 | p9 §12 TYP 列。条件は VPP = 0.5 V だけ | "VPP = 0.5 V, VBIAS = 0 V RL = 600 Ω f = 20 Hz to 20 kHz 25°C -107" |
| TMUX4821 | THD+N（表）32 Ω | −102 dB | 一致 | p9 | 同上 |
| TMUX4821 | THD+N（Features） | 0.001 %（−100 dB）、条件なし | 一致 | p1 | "Low THD+N: 0.001% (-100dB)" |
| TMUX4821 | Figure 13-16 | 15 Vpp: 約 −125〜−118 dB、0.5 Vpp: 約 −107 dB | 一致 | p12。私の読み: 15 Vpp は 20〜200 Hz で約 −124 dB、それより上で約 −120〜−117 dB。0.5 Vpp は約 −106〜−107 dB | 図下 "VDD = 3.3V, RLOAD = 600Ω, TA = 25°C" |
| TMUX4821 | Figure 13-18 | 0.5 V で約 0.00058 %、15 V で約 0.00018 % | 一致 | p12 | 凡例 "1kHz, 32 Ω"、横軸 "Source Voltage (V)" |
| TMUX4821 | **Figure 13-21** | 推奨領域の上限: 13 Vpp まで約 1 MHz、15 Vpp 約 40 kHz、17 Vpp 約 19 kHz、18 Vpp 約 15 kHz、19 Vpp 約 13 kHz、29 Vpp 約 4.5 kHz。No Operation Region は 18 Vpp で約 16 kHz 以上。VDD = 5V | 一致・補足あり | p13。軸ラベルの座標で較正（1 桁 = 32 pt）し、576 dpi 相当で色境界を拾った。**私の読み（推奨領域の上限）:** 13 Vpp まで 1 MHz、14 Vpp 約 98 kHz、15 Vpp 約 37 kHz、16 Vpp 約 23 kHz、17 Vpp 約 18.5 kHz、**18 Vpp 約 14.7 kHz**、19 Vpp 約 12.3 kHz、20 Vpp 約 10.5 kHz、29 Vpp 約 4.7 kHz。**No Operation の下端:** 15 Vpp 約 55 kHz、17 Vpp 約 21 kHz、**18 Vpp 約 16.5 kHz**、29 Vpp 約 5.7 kHz。**補足:** 20 kHz で推奨領域に入る振幅は約 16.7 Vpp まで（計算ではなく図の読み） | 凡例 "No Operation Region / >-100dB Operation Region / Recommended Operation Region"、図下 "VDD = 5V" |
| TMUX4821 | Figure 13-21 の説明文 | DS に無い | 一致 | "Stopping" は図の縦軸ラベルだけ、"13-21" は図題だけ | — |
| TMUX741xF | 構成 | 7411F logic low、7412F logic high、7413F 混在 | 一致 | p3 Device Comparison Table | "TMUX7412F ±60 V fault-protected, latch-up immune, quad SPST switch (logic high)" |
| TMUX741xF | パッケージ | PW (TSSOP, 16) 5.00 × 4.40（Preview）、RRP 4.00 × 4.00 | 一致 | p1 | "PW (TSSOP, 16) (2) 5.00 mm × 4.40 mm" / "(2) Preview package." |
| TMUX741xF | 電源範囲（Features） | 単 8〜44 V、両 ±5〜±22 V | 一致 | p1 | "Single supply: 8 V to 44 V – Dual supply: ±5 V to ±22 V" |
| TMUX741xF | 推奨 VDD – VSS | 8 / 44 V | 一致 | p5 §7.4 | "VDD – VSS (1) Power supply voltage differential 8 44" |
| TMUX741xF | 推奨 VS（非 fault） | VSS / VDD | 一致 | p5 | 同上 |
| TMUX741xF | 推奨 VS（fault） | −60 / 60 V 対 GND | 一致 | p5 | "VS to GND Source pin (Sx) voltage to GND (fault condition) –60 60" |
| TMUX741xF | **推奨 VD** | VSS / VDD | 一致 | p5 | "VD Drain pin (Dx) voltage VSS VDD" |
| TMUX741xF | 絶対最大 VS 対 GND | −65 / 65 V | 一致 | p4 | 同上 |
| TMUX741xF | **絶対最大 VD** | VSS−0.7 / VDD+0.7 V | 一致 | p4 | "VD Drain pin (Dx) voltage VSS–0.7 VDD+0.7 V" |
| TMUX741xF | IDC（WQFN） | 150 / 100 / 60 mA、max | 一致 | p5 MAX 列 | 同上 |
| TMUX741xF | VT | 0.7 V typ | 一致 | p6 | "VT Threshold voltage for fault detector 25°C 0.7 V" |
| TMUX741xF | UVLO | 5.1 / 5.8 / 6.4 V、5 / 5.7 / 6.3 V | 一致 | p6 | 同上 |
| TMUX741xF | **IS(FA) Grounded** | ±125 µA、VS = ±60 V、VDD = VSS = 0 V、typ | 一致 | p7 §7.6。値は TYP 列（MIN / MAX 空欄）、TA は −40〜+125°C の 1 行だけ | "IS(FA) Grounded ... VS = ± 60 V, GND = 0 V VDD = VSS = 0 V –40°C to +125°C ±125 µA" |
| TMUX741xF | IS(FA) Floating | ±125 µA typ | 一致 | 同上 | 同上 |
| TMUX741xF | IS(FA)（電源あり） | ±100 µA typ | 一致 | p7 | 同上 |
| TMUX741xF | **ID(FA) Grounded** | ±0.01 typ、±30 / ±50 / ±90 nA | 一致 | p7。25°C は MIN / TYP / MAX、温度行は MIN / MAX | "25°C –30 ±0.01 30 ... –50 50 ... –90 90 nA" |
| TMUX741xF | ID(FA) Floating | ±2 / ±3 / ±4 µA typ | 一致 | p7 TYP 列 | 同上 |
| TMUX741xF | 電源断・±9〜±15 V での漏れ | DS に無い | 一致 | 表は VS = ±60 V だけ。Figure 7-19〜7-23 はどれも電源あり | — |
| TMUX741xF | Figure 7-23 | +30 V 約 +27 µA、−30 V 約 −33〜−38、+60 V 約 +78〜+88、−60 V 約 −85〜−100 µA、電源 ±15 V | 一致 | p20（私の読み: +30 V は +25→+28、−60 V は −86→−100 µA） | 図下 "±15 V Dual Supply" |
| TMUX741xF | 本文 §9.3.2.2 | 電源を外すと source は Hi-Z、GND 基準必要、±60 V 遮断 | 一致 | p33 | "Source and drain voltage levels of up to ±60 V are blocked in the powered-off condition." |
| TMUX741xF | 本文 §9.3.2.5 | drain は電源へ ESD ダイオード、source は ±60 V 可 | 一致 | p33 | "The drain pins (Dx) have internal ESD protection diodes to the supplies VDD and VSS, therefore the voltage at the drain pins must not exceed the supply voltages ..." |
| TMUX741xF | **DS 内の食い違い** | §9.3.2.2 と §9.3.2.5・絶対最大の食い違い | 一致・補足あり | 原文どおり。**補足:** p1 Description は "The devices block fault voltages up to +60 V or −60 V relative to ground in powered and powered-off conditions" と端子を書かずに言っている。また、電源断時は VDD = VSS = 0 V なので、絶対最大の VD は −0.7〜+0.7 V になる | p33 / p4 / p1 |
| TMUX741xF | 電源なし時の論理 | ch は OFF、論理入力は無視 | 一致 | p1 | 同上 |
| TMUX741xF | フェイルセーフ論理 | +44 V まで、負は保護なし | 一致 | p33 §9.3.2.3 | 同上 |
| TMUX741xF | RON | 8.3 / 11、14、16.5 Ω | 一致 | p7 | 同上 |
| TMUX741xF | RFLAT | 0.01 / 0.4、0.4、0.4 Ω | 一致 | p7 | 同上 |
| TMUX741xF | IS(OFF) / ID(OFF) | 0.03、±0.7、±2、±10 / ±12 nA | 一致 | p7（IS は ±10、ID は ±12 nA） | 同上 |
| TMUX741xF | THD+N | 0.0006 %、VS = 15 VPP、RL = 10 kΩ | 一致 | p8 | 同上 |
| TMUX741xF | OISO | −60 dB、f = 1 MHz | 一致 | p8 | 同上 |
| TMUX741xF | Figure 7-29 | 100 kHz 付近で約 −80〜−90 dB | 一致・補足あり | p21。**私の読み:** 左端の 100 kHz では約 −95〜−100 dB（ノイズで揺れる）。−80〜−90 dB になるのは約 150〜300 kHz。boundary.md の値は安全側（悪い側）に寄っている | 図題 "Crosstalk and Off Isolation vs Frequency" |
| TMUX741xF | XTALK | −100 dB | 一致 | p8 | 同上 |
| TMUX741xF | CS(OFF) / CD(OFF) / CON | 10 / 12 / 14 pF | 一致 | p8 | 同上 |
| TMUX741xF | QJ | −300 pC | 一致 | p8 | 同上 |
| TMUX741xF | tON / tOFF | 480 / 680、50 / 100 ns | 一致 | p8 | 同上 |
| TMUX741xF | IDD / ISS | 0.32 / 0.5、0.26 / 0.4 mA | 一致 | p8 | 同上 |
| TMUX7462F | 構成 | 選択ピン不要の 4 ch プロテクタ | 一致 | p1 | "Channel protector without need for dedicated select pin per channel" |
| TMUX7462F | パッケージ | PW 5 × 6.4、RRP 4 × 4 mm | 一致 | p1 | 同上 |
| TMUX7462F | ON の条件 | VDD – VSS ≥ 8 V ほか | 一致 | p28 §8.4.1 | 同上 |
| TMUX7462F | 電源断時（本文） | 0 V・浮き・UV 未満で source は Hi-Z | 一致 | p26 §8.3.2.2 | 同上 |
| TMUX7462F | **IS(FA) Grounded** | ±135 µA typ | 一致 | p6 §6.6 TYP 列 | "VDD = VSS = VFP = VFN= 0 V –40°C to +125°C ±135 µA" |
| TMUX7462F | IS(FA) Floating | ±140 µA typ | 一致 | p6 | 同上 |
| TMUX7462F | **ID(FA) Grounded** | ±0.01、±30 / ±50 / ±90 nA | 一致 | p6 | 同上 |
| TMUX7462F | ID(FA) Floating | ±0.6 / ±1.2 / ±2.2 µA | 一致 | p6 TYP 列 | 同上 |
| TMUX7462F | drain 側の保護 | 無し、常に VFP〜VFN | 一致 | p28 §8.4.2 | "The overvoltage protection is provided only for the source (Sx) input pins. ..." |
| TMUX7462F | 絶対最大 VD | VFN−0.7 / VFP+0.7 V | 一致 | p4 | 同上 |
| TMUX7462F | RON | 8.3 / 10.7、13.5、16 Ω | 一致 | p6 | 同上 |
| TMUX7462F | RFLAT | 0.005 / 0.4 Ω | 一致 | p6 | 同上 |
| TMUX7462F | THD+N | 0.0006 %、15 VPP | 一致 | p7 | 同上 |
| TMUX7462F | CS(ON), CD(ON) | 14 pF | 一致 | p7 | 同上 |
| TMUX7462F | OISO・OFF 容量 | DS に無い | 一致 | p6〜p7 に行が無い。全文に "Off-isolation" "OISO" "off-capacitance" は無い | — |
| TMUX7462F | IDD / ISS | 0.32 / 0.5、0.26 / 0.4 mA | 一致 | p7 | 同上 |
| ADG5412F | 構成 | 5412F は Logic 1 で全 ON、5413F は 2 / 2 | 一致 | p1 | 同上 |
| ADG5412F | パッケージ | 16-Lead TSSOP / LFCSP | 一致 | p12 Table 6 | "16-Lead TSSOP (4-Layer Board) 112.6°C/W" |
| ADG5412F | 電源範囲 | ±5〜±22 V、8〜44 V | 一致 | p1 | 同上 |
| ADG5412F | 信号範囲 | VDD to VSS（−40〜+125°C 列） | 一致 | p3 Table 1 | 同上 |
| ADG5412F | Features | ±55 V まで電源断保護 | 一致 | p1 | "Power-off protection up to −55 V and +55 V" |
| ADG5412F | **Source Leakage, Grounded or Floating** | ±40 µA、"µA typ"、−40〜+125°C 列だけ、VS = ±55 V | 一致 | p3。+25°C・−40〜+85°C 列は空欄 | "Power Supplies Grounded or Floating ±40 µA typ VDD = 0 V or floating, ..." |
| ADG5412F | Source Leakage, With Overvoltage | ±78 µA typ、"VSS = 16.5 V"（原文の符号のまま） | 一致 | p3。画像でも "VSS = 16.5 V" | 同上 |
| ADG5412F | **Drain Leakage, Grounded** | ±10 nA typ、±30 / ±50 / ±100 nA max | 一致 | p3。typ 行は +25°C 列だけ | 同上 |
| ADG5412F | Drain Leakage, Floating | ±10 µA typ（3 列） | 一致 | p3 | 同上 |
| ADG5412F | 電源断・±9〜±15 V | DS に無い | 一致 | 表は ±55 V だけ。Figure 38 も ±55 V の条件を指す | — |
| ADG5412F | 本文（Power-Off Protection） | OFF、入力は高インピーダンス、出力は仮想開放、GND 基準必要 | 一致・補足あり | p26。**補足:** 同じ段落の最後に「±55 V までの信号は電源断時に遮断」とあり、端子を書いていない（TMUX741xF と同じあいまいさ。drain は p25 で電源を超えてはならないとしている） | "Signal levels of up to ±55 V are blocked in the unpowered condition." |
| ADG5412F | 本文（ESD） | drain は電源へダイオード | 一致 | p25 | "The drain pins have ESD protection diodes to the rails and the voltage at these pins must not exceed supply voltage." |
| ADG5412F | 絶対最大 Dx | VSS − 0.7〜VDD + 0.7 V または 30 mA | 一致 | p12 Table 6、注 1 | "Overvoltages at the Dx pins are clamped by internal diodes." |
| ADG5412F | BF 版の案内 | 両側保護のピン互換品 | 一致 | p25 | 同上 |
| ADG5412F | **RON（±9 V）** | 9.5 Ω typ、10.7 / 13.5 / 16 Ω max、節見出し VDD = 13.5 V、VSS = −13.5 V | 一致 | p3。typ 行と max 行 | "9.5 Ω typ VS = ±9 V, IS = −10 mA / 10.7 13.5 16 Ω max" |
| ADG5412F | RON（±10 V） | 10 / 11.2 / 14 / 16.5 Ω | 一致 | p3 | 同上 |
| ADG5412F | RFLAT（±9 V） | 0.1、0.4 / 0.5 / 0.5 Ω | 一致 | p3 | 同上 |
| ADG5412F | RFLAT（±10 V） | 0.6、0.9 / 1.1 / 1.1 Ω | 一致 | p3 | 同上 |
| ADG5412F | IS(Off) / ID(Off) | ±0.1、±1.5 / ±5.0 / ±21（ID ±18）nA | 一致 | p3 | 同上 |
| ADG5412F | **THD+N** | 0.0015 %、RL = 10 kΩ、15 V p-p | 一致・補足あり | p4 +25°C 列。**補足:** DYNAMIC CHARACTERISTICS 全体に注 1 が付いている（QINJ・Off Isolation も同じ） | "1 Guaranteed by design; not subject to production test." |
| ADG5412F | Figure 25 | 15 V p-p で約 0.0015 % | 一致 | p17（私の読みは約 0.0012〜0.0015 %） | 凡例 "VDD = 15V, VSS = −15V, VS = 15V p-p" |
| ADG5412F | Off Isolation | −70 dB、1 MHz | 一致 | p4 | 同上 |
| ADG5412F | Figure 20 | 1〜10 kHz 約 −110 dB、100 kHz 約 −100 dB | 一致 | p16（私の読みは 100 kHz で約 −95 dB） | 図中 "VDD = +15V VSS = −15V TA = 25°C" |
| ADG5412F | CS(Off) / CD(Off) / CON | 13 / 12 / 24 pF | 一致 | p4 | 同上 |
| ADG5412F | **QINJ** | −680 pC、VS = 0 V、RS = 0 Ω、CL = 1 nF | 一致 | p4 | "Charge Injection, QINJ −680 pC typ VS = 0 V, RS = 0 Ω, CL = 1 nF" |
| ADG5412F | tON / tOFF | 400 / 495、410 / 510 ns | 一致 | p4 | 同上 |
| ADG5412F | IDD / ISS | 0.9 / 1.2、0.5 / 0.65 mA | 一致 | p4 | 同上 |
| ADG5412F | Figure 31 | ±10 V で 1〜約 3 MHz は 20 V p-p まで | 一致 | p18 | 図中 "DISTORTIONLESS OPERATING REGION" |
| ADG5412BF | 同じ値の範囲（節の前書き） | RON・RFLAT・THD+N・容量・QINJ・時間・Off Isolation が同じ | 一致 | BF の p3〜p4 の画像で 1 行ずつ突き合わせた。違うのは漏れの行と ISS の単位だけ | — |
| ADG5412BF | 保護対象 | source と drain | 一致 | p1 | "Switch pins are protected against voltages between −55 V and +55 V, in an unpowered state." |
| ADG5412BF | 絶対最大 Sx and Dx | −55〜+55 V | 一致 | p12 | "Sx and Dx −55 V to +55 V" |
| ADG5412BF | ESD | 3 kV（5412F は 5.5 kV） | 一致 | p12（I/O port は BF も 5.5 kV）。F の p12 は All Other Pins 5.5 kV | "All Other Pins 3 kV" |
| ADG5412BF | **Input Leakage, Grounded or Floating** | ±40 µA typ、VS or VD = ±55 V | 一致 | p3、−40〜+125°C 列だけ | 同上 |
| ADG5412BF | **Output Leakage, Grounded** | ±10 nA typ、±30 / ±50 / ±100 nA | 一致 | p3 | 同上 |
| ADG5412BF | Output Leakage, Floating | ±10 µA typ | 一致 | p3 | 同上 |
| ADG5412BF | Output Leakage, With Overvoltage | ±20、±200 / ±250 / ±250 nA | 一致 | p3 | 同上 |
| ADG5412BF | IS(Off) / ID(Off) | ±1.5 / ±5.5 / ±24（ID ±20）nA | 一致 | p3 | 同上 |
| ADG5412BF | 本文 | 5412F と同文 | 一致 | p26 | 同上 |
| ADG5412BF | ISS max の単位 | "0.7 μA max" | 一致 | p4 の画像でも "µA max" | "0.65 0.7 μA max" |
| DG458 | 構成 | n-p-n 直列 MOSFET | 一致 | p1 | 同上 |
| DG458 | パッケージ | 16-pin Plastic DIP | 一致 | p2 | 同上 |
| DG458 | 電源範囲 | ±4.5 / ±18 V | 一致 | p4 | 同上 |
| DG458 | 信号範囲 | −10 / 10 V（A・D） | 一致 | p3。注 e（設計保証）付き | "Analog Signal Range(e) VANALOG Full - 10 10 - 10 10 V" |
| DG458 | 絶対最大 電源断時 | −35〜+35 V | 一致 | p2 | "VS, Analog Input Overvoltage with Power Off - 35 to + 35" |
| DG458 | **Input Leakage (Power Supplies Off)** | 0.001 µA typ、±2 µA（A）/ ±5 µA（D）、VS = ±25 V、VSUPS = 0 V、Room | 一致 | p3。Typ 列、A / D の Min / Max 列 | "Input Leakage Current (with Power Supplies Off) VS = ± 25 V, VSUPS = 0 V VD = A0, A1, A2, EN = 0 V Room 0.001 - 2 2 - 5 5 µA" |
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

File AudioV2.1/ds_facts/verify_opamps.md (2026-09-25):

# opamps.md の独立照合（手持ちオペアンプ 17 石）

- **照合日**: 2026-09-25
- **対象**: `AudioV2.1/ds_facts/opamps.md`（このファイルでは書き換えていない）
- **DS**: `AudioV2.1/datasheets/opamps/*.pdf`
- **方法**: 出典ページを `pdftoppm -r 150` でページ画像にして目で読んだ。数値・列・条件（表の見出しと脚注を含む）・引用・ページを確かめた。
  グラフは目で読んだうえで、画像のピクセル列を走査して曲線の位置を目盛から換算した（作業ファイルは scratchpad の `verify_opamps/`）。
  「目読み」の許容幅は **その軸の最も細かい目盛の半分**。これを超えたものを「誤り（目読み）」にした
- **照合した行数**: **277 行**（各石の表 232 行と、付録「出力振幅の規定値だけの一覧」45 行）。
  各節の頭書き（DS の版、表の既定条件、型番の注記など）も確かめたが、上の数には入れていない（末尾の「頭書き」節を参照）

## 判定の内訳

| 判定 | 行数 | 該当 |
|---|---|---|
| 一致 | **273** | 下の表で「一致」とした行。うち 3 行は値としては一致だが補足がある（OPA2134 の Headroom、OPA1652・OPA1612 の差動入力） |
| 誤り（目読み） | **3** | OPA2604 の Figure 15（26 → **24 Vp-p**）、OPA1612 の Figure 27 の負側（−14.6 → **−14.0〜−14.35 V**）、MUSES01 の負荷抵抗グラフ ±15 V の正側（+13.5 → **+14.0 V**） |
| 条件の誤り | **1** | OPA627 の Figure 5-23 に「RL = 10 kΩ」と書いているが、そのページにも図にも負荷の記載は無い |
| 列の誤り | 0 | — |
| 引用が無い | 0 | 引用はすべて DS に実在した（TI 版 NE5532 の注 (5) の文法の崩れ、OPA1656 の "groundinsymmetrical" の詰まり、MUSES03 の「VOM2」重複も原文どおり） |
| 確かめられず | 0 | — |

これとは別に、**「探したが DS に無かった」としていたが DS にあったもの**が 3 件、関連するグラフの書き漏れが 5 件ある（末尾の節）。
3 件のうち重いのは、**OPA1652 と OPA1612 の入力間に back-to-back ダイオードがある**という記述（入力保護の扱いと、差動入力が大きく振れる回路での使い方を変える）と、
**NJM5532 のボルテージフォロワでの入力ダイオード破壊の注意**。

---

## 判定表

列の読み方: 「DS の実際」が「同左」なら、値・列・条件・ページとも opamps.md のとおり。目読みの行は、自分の読みを必ず書いた。

### 1. NE5532（TI_NE5532.pdf, SLOS075K）

| 石 | 項目 | opamps.md の値 | 判定 | DS の実際（値・列・条件・ページ） | 根拠（原文の引用） |
|---|---|---|---|---|---|
| NE5532 | 電源電圧（推奨動作） | VCC+ 5〜15 V、VCC– −5〜−15 V | 一致 | 同左。p.3 §5.3、MIN/MAX 列 | `VCC+ Supply voltage 5 15 V` / `VCC– Supply voltage –5 –15 V` |
| NE5532 | 電源電圧（本文） | ±5〜±15 V | 一致 | 同左。p.9 §7.2 | "specified for operation over the range of ±5 to ±15 V" |
| NE5532 | 電源電圧（絶対最大・表） | 0〜+18 V / −18〜0 V | 一致 | 同左。p.3 §5.1、MIN/MAX 列。表見出しは "over operating free-air temperature range" | `VCC+ 0 +18` / `VCC– –18 0` |
| NE5532 | 電源電圧（絶対最大・本文の注意） | ±22 V（表と食い違い） | 一致 | 同左。p.9 CAUTION と p.11 改訂履歴の両方を確認 | "Supply voltages outside of the ±22 V range…" / "Changed Supply voltage positive and negative from 22V to 18V" |
| NE5532 | 静止電流 | typ 6 / max 16 mA（Total） | 一致 | 同左。p.4 §5.5、TYP/MAX 列、VO = 0, No load | `ICC Total supply current VO = 0, No load 6 16 mA` |
| NE5532 | 出力電圧振幅 | 規定なし（削除） | 一致 | p.4 の表に項目なし。p.11 改訂履歴に削除の記載 | "Removed Maximum peak-to-peak output voltage swing, …" |
| NE5532 | 参考: AVD の試験条件 | VO = ±10 V、min 15/25、全温度 10/15 V/mV | 一致 | 同左。p.4、MIN 列（TYP 50/100） | `RL ≥ 600Ω, VO = ±10 V … 15 50` / `RL ≥ 2kΩ, VO±10 V … 25 100` |
| NE5532 | 同相入力電圧範囲 | min ±12 / typ ±13 V | 一致 | 同左。p.4、MIN/TYP 列 | `VICR … ±12 ±13 V` |
| NE5532 | 入力電圧（絶対最大） | −15〜+15 V | 一致 | 同左。p.3、注 (3) も実在 | "The magnitude of the input voltage must never exceed the magnitude of the supply voltage." |
| NE5532 | 差動入力（絶対最大） | 電圧値なし、入力電流 ±10 mA、約 0.6 V 注記 | 一致 | 同左。p.3、注 (4) | "Excessive input current flows if a differential input voltage in exceeding approximately 0.6V is applied…" |
| NE5532 | 入力保護ダイオード | 記述あり | 一致 | p.1 §3、p.6 §6.1 の両方 | "…high slew rate, input-protection diodes, and output short-circuit protection." |
| NE5532 | 出力短絡電流 | typ 38 mA | 一致 | 同左。p.4、TYP 列 | `IOS Output short-circuit current 38 mA` |
| NE5532 | 出力短絡時間（絶対最大） | Unlimited | 一致 | 同左。p.3、注 (5) | "The output can be shorted to ground or either power supply. …" |

### 2. NJM5532（NJR_NJM5532.pdf, 20250306）

| 石 | 項目 | opamps.md の値 | 判定 | DS の実際 | 根拠 |
|---|---|---|---|---|---|
| NJM5532 | 電源電圧（推奨動作） | ±3〜±22 V | 一致 | 同左。p.2、Ta=25°C | `RECOMMENDED OPERATING VOLTAGE (Ta=25°C) … ±3~±22` |
| NJM5532 | 電源電圧（特長） | ±3〜±22 V | 一致 | 同左。p.1 | `Operating Voltage ±3V~±22V` |
| NJM5532 | 電源電圧（絶対最大） | ±22 V | 一致 | 同左。p.2、見出し Ta=25°C | `Supply Voltage V+/V- ±22 V` |
| NJM5532 | 静止電流 | typ 9 / max 16 mA | 一致 | 同左。p.2、TYP/MAX 列、RL=∞。p.5 にも "ICCMAX=16mA at V+/V-=±15V" | `Supply Current ICC RL=∞ - 9 16 mA` |
| NJM5532 | 出力電圧振幅 1 | min ±12 / typ ±13 V、RL ≥ 600 Ω | 一致 | 同左。p.2、MIN/TYP 列 | `Maximum Output Voltage1 VOM1 RL≥600Ω ± 12 ± 13` |
| NJM5532 | 出力電圧振幅 2 | min ±15 / typ ±16 V、±18 V | 一致 | 同左。p.2、行の条件に V+/V-=±18V | `Maximum Output Voltage2 VOM2 RL≥600Ω, V+/V-=±18V ± 15 ± 16` |
| NJM5532 | 出力（特長） | 600 Ω に 10 Vrms typ | 一致 | 同左。p.1 | `Output Drive Capability 600Ω,10Vrms typ.` |
| NJM5532 | 参考: 電力帯域 | 140 kHz / 100 kHz typ | 一致 | 同左。p.2 AC 表、TYP 列 | `WPG VO=±10V - 140` / `VO=±14V, RL=600Ω, V+/V-=±18V - 100` |
| NJM5532 | グラフ: 最大出力電圧 vs 電源電圧 | ±12 V で約 +11 / −11 V | 一致 | p.4。自分の読み（ピクセル換算）: **2 kΩ で +11.2 / −10.8 V、600 Ω で +10.8 / −10.3 V**。縦軸は 5 V 刻みなので許容内。ただし「2 線はほぼ重なる」は負側で約 0.5 V 離れている | 図題 "Maximum Output Voltage vs. Supply Voltage RL=2kΩ, Ta=25ºC" |
| NJM5532 | グラフ: 最大出力電圧 vs 温度 | 25°C で約 +13.7 / −13 V | 一致 | p.4。自分の読み +13.6 / −13.0 V | 図題 "…vs. Temperature V+/V-=±15V, RL=600Ω" |
| NJM5532 | グラフ: 最大出力電圧 vs 負荷抵抗 | 1 kΩ 以上で約 ±14 V | 一致 | p.3。自分の読み: 1 kΩ で +14.05 / −13.6 V、3 kΩ で +14.3 / −13.9 V | 図題 "…vs. Load Resistance V+/V-=±15V, Ta=25ºC" |
| NJM5532 | グラフ: 最大出力電圧振幅 vs 周波数 | 低域で約 26 Vpp | 一致 | p.3。自分の読み 26.3 Vpp | 図題 "Maximum Output Voltage Swing vs. Frequency" |
| NJM5532 | 同相入力電圧範囲 | min ±12 / typ ±13 V | 一致 | 同左。p.2 | `Common Mode Input Voltage Range VICM ± 12 ± 13` |
| NJM5532 | 同相入力電圧（絶対最大） | V+/V- | 一致 | 同左。p.2 | `Common Mode Input Voltage Range VICM V+/V- V` |
| NJM5532 | 差動入力（絶対最大） | ±0.5 V | 一致 | 同左。p.2 | `Differential Input Voltage Range VID ±0.5 V` |
| NJM5532 | 出力短絡電流 | typ 38 mA | 一致 | 同左。p.2、TYP 列 | `Short Circuit Output Current IOS - 38 -` |

### 3. NJM4580（NJR_NJM4580.pdf, 20250303）

| 石 | 項目 | opamps.md の値 | 判定 | DS の実際 | 根拠 |
|---|---|---|---|---|---|
| NJM4580 | 電源電圧（推奨動作） | ±2 / ±18 V | 一致 | 同左。p.2、MIN/MAX 列、Ta=25°C | `Supply Voltage V+/V- ±2 - ±18 V` |
| NJM4580 | 電源電圧（特長） | ±2〜±18 V | 一致 | 同左。p.1 | `Operating Voltage ±2V~±18V` |
| NJM4580 | 電源電圧（絶対最大） | ±18 V | 一致 | 同左。p.2、見出し "Ta=25°C, unless otherwise noted." | `Supply Voltage V+/V- ±18 V` |
| NJM4580 | 静止電流 | typ 6 / max 9 mA | 一致 | 同左。p.2、行に条件なし | `Supply Current ICC - 6 9 mA` |
| NJM4580 | 出力電圧振幅 | min ±12 / typ ±13.5 V、RL ≥ 2 kΩ | 一致 | 同左。p.2 | `Maximum Output Voltage VOM RL≥2kΩ ±12 ±13.5` |
| NJM4580 | グラフ: vs 電源電圧 | ±12 V で約 ±10.8 V | 一致 | p.4。自分の読み **+10.9〜11.0 / −11.0〜−11.1 V**（細目盛 2 V、許容内） | 図題 "Maximum Output Voltage vs. Supply Voltage RL=2kΩ, Ta=25ºC" |
| NJM4580 | グラフ: vs 負荷抵抗 | 2 kΩ で約 +14 / −13.7 V | 一致 | p.3。自分の読み +13.95 / −13.8 V | 図題 "…vs. Load Resistance V+/V-=±15V, Ta=25ºC" |
| NJM4580 | グラフ: vs 温度 | 25°C で約 +13.7 / −13.2 V | 一致 | p.4。自分の読み +13.7 / −13.4 V | 図題 "…vs. Temperature V+/V-=±15V, RL=2kΩ" |
| NJM4580 | グラフ: vs 出力電流 | 1〜10 mA で約 +14 / −13.5、100 mA で約 +4.5 / −10.5 V | 一致 | p.3。自分の読み 1 mA +14.05 / −13.6、10 mA +14.1 / −13.25、約 95 mA +4.8 / −10.3 V | 図題 "…vs. Output Current V+/V-=±15V, Ta=25ºC" |
| NJM4580 | グラフ: vs 周波数 | 低域で約 27.5 Vpp | 一致 | p.3。自分の読み 27.7 Vpp | 図題 "…vs. Frequency V+/V-=±15V, RL=2kΩ, Ta=25ºC" |
| NJM4580 | 同相入力電圧範囲 | min ±12 / typ ±13.5 V | 一致 | 同左。p.2 | `VICM ±12 ±13.5` |
| NJM4580 | 入力電圧（絶対最大） | ±15 V（Note1） | 一致 | 同左。p.2、Note1 実在 | "(Note1) For supply voltage less than ±15V, the absolute maximum input voltage is equal to supply voltage." |
| NJM4580 | 差動入力（絶対最大） | ±30 V（Note1） | 一致 | 同左。p.2 | `Differential Input Voltage VID ±30 (Note1)` |

### 4. OPA2134（TI_OPA2134.pdf, SBOS058B）

| 石 | 項目 | opamps.md の値 | 判定 | DS の実際 | 根拠 |
|---|---|---|---|---|---|
| OPA2134 | 電源電圧（推奨動作） | ±2.5/±15/±18、5/30/36 V | 一致 | 同左。p.5 §5.3、MIN/NOM/MAX 列 | `Dual supply ±2.5 ±15 ±18` / `Single supply 5 30 36` |
| OPA2134 | 電源電圧（絶対最大） | 36 V | 一致 | 同左。p.5 §5.1、MAX 列 | `Supply voltage, (V+) – (V–) Single supply 36` |
| OPA2134 | 静止電流 | typ 4 / max 5 mA（per amplifier） | 一致 | 同左。p.8、TYP/MAX 列 | `IQ Quiescent current (per amplifier) IO = 0mA 4 5 mA` |
| OPA2134 | 出力電圧振幅（10 kΩ） | (V+)–1.2 / (V–)+0.5 | 一致 | 同左。p.8。正側は MIN 列に左寄せ、負側は MAX 列に右寄せ（画像で確認） | `RL = 10kΩ Positive (V+) – 1.2` / `Negative (V–) + 0.5` |
| OPA2134 | 出力電圧振幅（2 kΩ） | (V+)–1.5 / (V–)+1.2 | 一致 | 同左。p.8、同じ配置 | `RL = 2kΩ Positive (V+) – 1.5` / `Negative (V–) + 1.2` |
| OPA2134 | 参考: AOL の試験条件 | 10 kΩ: −14.5〜13.8 V、2 kΩ: −13.8〜13.5 V | 一致 | 同左。p.7、MIN 104 / TYP 120 | `RL = 10kΩ, –14.5V ≤ VO ≤ 13.8V 104 120` |
| OPA2134 | 参考: Headroom | typ 21.3 dBu、"VS = 18V" | 一致（補足あり） | 表の値・文言は同左（p.7、TYP 列）。**ただし同じ DS の p.13 §6.2.1 と p.9 Figure 5-4 は、VS = ±18 V・THD+N < 0.01% で 11.7 Vrms = 23.6 dBu としており、表の 21.3 dBu と食い違う**。表の値だけを「±18 V での Headroom」と読むと外れる | p.13: "…maximum allowable output voltage level of 11.7Vrms (THD+Noise < 0.01%), have a headroom specification of 23.6dBu. See Figure 5-4." |
| OPA2134 | 本文の記述 | レールから 1 V 以内 | 一致 | 同左。p.13 §6.1 | "the OPA134 has a wide output swing, to within 1V of the rails" |
| OPA2134 | グラフ: vs 周波数 | ±15 V 約 27.5、±5 V 約 8.5、±2.5 V 約 3.5 Vpp | 一致 | p.11 Figure 5-13。自分の読み 27.8 / 8.9 / 3.8 Vpp（細目盛 2 Vpp、許容内）。図中に負荷の記載はなく、ページ既定 RL = 2 kΩ | "Maximum output voltage without slew-rate induced distortion" |
| OPA2134 | 同相入力電圧範囲 | (V–)+2.5 / ±13 / (V+)–3.5 | 一致 | 同左。p.7、MIN/TYP/MAX 列 | `VCM Common-mode voltage (V–) + 2.5 ±13 (V+) – 3.5` |
| OPA2134 | 入力電圧（絶対最大） | (V–)–0.5〜(V+)+0.5、±10 mA | 一致 | 同左。p.5、注 (2) 実在 | "Input pins are diode-clamped to the power-supply rails. …" |
| OPA2134 | 差動入力（絶対最大） | 規定なし | 一致 | p.5 §5.1 に項目なし。本文にも入力間ダイオードの記述なし | — |
| OPA2134 | 出力短絡電流 | +36 / −30 mA | 一致 | 同左。p.8、TYP 列 | `ISC Short-circuit current Sourcing 36` / `Sinking –30` |
| OPA2134 | 出力電流制限（本文） | 約 36 / −30 mA、温度で低下 | 一致 | 同左。p.15 §6.2.5 | "Output current is limited by internal circuitry to approximately sourcing 36mA and sinking –30mA at 25°C. …" |
| OPA2134 | 出力短絡（絶対最大） | Continuous（GND、1 パッケージ 1 回路） | 一致 | 同左。p.5、注 (3) | "Short-circuit to ground, one amplifier per package." |
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

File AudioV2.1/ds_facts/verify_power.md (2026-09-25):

# 電源系 DS 事実表の独立照合（power.md）

- 照合日: 2026-09-25
- 対象: `AudioV2.1/ds_facts/power.md`（書き換えていない）
- DS: `AudioV2.1/datasheets/` の `Recom_RS6.pdf` / `TI_TPS7A49.pdf` / `TI_TPS7A30.pdf` / `ADI_LT1763.pdf` / `ST_L78.pdf`
- やり方: 出典に書かれたページをすべて `pdftoppm -r 150` で画像にし、表の罫線・列見出し・脚注・ページ見出しの条件を目で確かめた。
  PSRR のグラフ（TPS7A49 p9、TPS7A30 p10）と L78 Figure 28（p31）は 300 dpi にして、枠線と格子線を画素で探して軸を合わせ、
  指定の周波数（温度）の列で曲線の画素を拾って換算した（PIL が壊れていたので PPM を素の Python で読んだ）。power.md の数値は見ずに読み、あとで突き合わせた。
  寸法図（RS6 p7）は 400 dpi で拡大した。作業ファイルは scratchpad の `verify_power/` にある。
- 照合した行: **表の行 246 行**（power.md の表の全データ行。PSRR グラフは曲線 1 本＝1 行）＋ **表の外の記述 15 件**（各 DS の出典行・表の見出し条件・グラフの下の原文引用・「同じ DS の中での食い違い」）＝ **261 件**
- 判定の内訳: **一致 261**（うち「一致（注記）」7）／誤り 0／条件の誤り 0／列の誤り 0／引用が無い 0／確かめられず 0
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

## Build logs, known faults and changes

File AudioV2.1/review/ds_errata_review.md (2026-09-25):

# DS 事実表と照合結果の再判定（switch_control / power / opamps）

- 実施日: 2026-09-24（ファイル内の日付は 09-25 表記のものがあるが、同じ作業の続き）
- 対象: `AudioV2.1/ds_facts/{switch_control,power,opamps}.md`（facts）と `verify_*.md`（照合）
- 範囲: 照合側が「誤り」「条件の誤り」「一致・補足あり／一致（注記）」「無いとされていたが DS にあった」「facts に載っていない」と書いた行を全部。照合が「一致」とした行は、いくつか抜き取って見ただけで、全部はやり直していない
- 方法: 引用されたページを `pdftoppm` で画像にした（150 dpi、グラフは 300〜600 dpi で切り出し）。グラフは、両者の数値を見る前に自分で読んだ。PIL が壊れていたので、PPM を素の Python で読み、格子線を画素で検出して軸を合わせた（TMUX7612 Fig 5-1/5-4、TPS7A49 Fig 18、TPS7A30 Fig 14/16/18、LT1763 p11、OPA2604 Fig 15、OPA1612 Fig 27、MUSES01 p10）。作業ファイルは scratchpad の `errata/` にある
- リポジトリのファイルは書き換えていない。このファイルだけを書いた

判定の意味: **facts が正** ＝照合の指摘は当たらない／**照合が正** ＝facts を直す（照合の文面どおりで良いとは限らない）／**どちらも不正確**／**判定不能**。
「補足」は、facts の値は正しく、書き足すかどうかだけの話。

---

## 0. 総括

| # | 項目 | 判定 | facts の修正 | v2.1 の設計判断に効くか |
|---|---|---|---|---|
| S1 | TMUX7612 Fig 5-4「正側は 7.5 Ω 超まで」 | 照合が正 | 要（文言） | 効かない（効くのは立ち上がり始めの VS で、そこは両者一致） |
| S2 | TMUX7612 Fig 5-1 の 25°C ≈ 0.95 Ω（表 typ 1.1 Ω と食い違う） | 照合が正（facts に記載なし） | 追記推奨 | 効かない（直列 1 Ω 前後の差） |
| S3 | PCM1804 見出しの食い違いは p9〜11 か p9〜12 か | 照合が正 | 要（ページ範囲） | 効かない |
| S4 | AZ850 220 VDC の注（30 VDC 超は要相談） | 補足（照合が正） | 追記推奨 | 効かない |
| S5 | TBD62083A tON/tOFF は VIH = 5.0 V で測定 | 補足（照合が正） | 追記推奨 | 小（3.3 V 駆動なら時間は保証外。リレー駆動では実害なし） |
| S6 | MCP23017 Table 3-5 は p18 に続く | 補足（照合が正）＋照合の見落とし 1 件 | 要（ページ、アドレス） | ファームのみ（引用のアドレスは BANK=1 の配置） |
| P1 | RS6「無負荷入力電流」 | 補足（照合が正） | 要（項目名） | 小 |
| P2 | TPS7A49 Features「≥ 52 dB（〜400 kHz）」と Fig 18 | 照合が正（facts の表は既に 50 dB を載せている） | 注記追加 | **効く**（200 kHz 超の除去比） |
| P3 | TPS7A30 Features「≥ 55 dB（〜700 kHz）」と Fig 18 | 照合が正、ただし**照合も甘い**（700 kHz では約 45 dB） | 注記追加 | **効く** |
| P4 | TPS7A30 Do's「2.2 µF 以上」 | **facts が正**（同じページの §10 に "at least a 2.2-μF capacitor"） | 出典に §10 を足すだけ | 効かない |
| P5 | LT1763 の PDF は BDTIC のミラー | 照合が正 | 要（出典の注記） | 効かない（中身は Rev G） |
| P6 | LT1763 Note 7（「VOUT(NOMINAL) のみ」） | 照合が正 | 要（1 行） | 効かない（-5/-3.3 品は VOUT の方が大きい） |
| P7 | LT1763 Ripple Rejection 50 dB は 25°C のみ | 照合が正 | 要（条件欄） | 小 |
| P8 | LT1763 PSRR の周波数特性（p11） | 照合が正（facts の抜け） | **追記必須** | **効く**（200 kHz で約 30 dB） |
| P9 | LT1763 最小 ESR（p16 Figure 3） | 照合が正（facts の抜け） | **追記必須** | **効く**（セラミック出力の容量下限） |
| P10 | TPS7A49 EN ヒステリシス「Figure 13 のグラフのみ」 | 照合が正 | 要（括弧内） | 効かない |
| P11 | TPS7A49/TPS7A30 絶対最大の FB・NR/SS 対 IN、TPS7A30 Eq.8 15.4 µF、TPS7A49 p16 ヘッドルームの食い違い | 照合が正（抜け・DS 内の食い違い） | 追記は任意 | 小 |
| O1 | OPA1652 入力間の back-to-back ダイオード | 照合が正（facts は「無い」と書いた） | **要** | **効く**（G = 1 と ch の電源断） |
| O2 | OPA1612 同上 | 照合が正 | **要** | **効く** |
| O3 | NJM5532 入力ダイオードの注意（p5）・V+ 開放時の寄生電流（p6） | 照合が正（facts は「無い」と書いた）。p6 は照合も補足扱いで軽い | **要** | **最も効く**（ch ごとに電源を落とす構成そのもの） |
| O4 | OPA2134 Headroom 21.3 dBu と 23.6 dBu | 照合が正 | 注記追加 | 小（±12 V ではどちらも当たらない） |
| O5 | OPA2604 Fig 15 26 Vp-p | 照合が正（24 Vp-p） | 要 | 小〜中（最大レベルの見積もり） |
| O6 | OPA1612 Fig 27 負側 −14.6 V | 照合が正（facts の誤り）。照合の −14.0 V 端は別の温度の線の疑い | 要 | 小 |
| O7 | MUSES01 ±15 V・2 kΩ +13.5 V | 照合が正（+14.0 V） | 要 | 小 |
| O8 | OPA627 Fig 5-23「RL = 10 kΩ」 | 照合が正 | 要。横軸が 100 kHz から始まることも書く | 効かない |
| O9 | LME49860 Fig 4/8/12、OPA1656 Fig 6-8、OPA2140 Fig 6-22、NE5532 Fig 7-2〜7-4 | 照合が正（存在と読みを確認） | 追記は任意。LME49860 の ±12 V の図は追記推奨 | LME49860 の ±12 V の図は効く（±12 V で直接の資料） |

**facts の誤りのうち設計に効くのは、O1〜O3（「入力保護ダイオードの記述は無い」と書いたのに実はあった）と、P8・P9（LT1763 の抜け）。**
目で読んだグラフの値の誤り（S1、O5〜O7）は、どれも 0.1〜2 V・0.1 Ω 程度で、設計の結論は変わらない。

---

## 1. switch_control.md

| 項目 | facts の記載 | 照合側の主張 | 私の読み（ページ・引用） | 判定 | facts の直し方 |
|---|---|---|---|---|---|
| S1 TMUX7612 Fig 5-4 の正側の上端 | 87 行「正側（VDD 側）は急峻に **7.5 Ω 超まで**立ち上がる」、89 行の表見出し「縦に立ち上がる（〜7.5 Ω）」 | 約 7.4 Ω で水平になり、軸の上限 7.5 Ω は越えない | p17 Figure 5-4、600 dpi。上の枠線（7.5 Ω）と 7.0 Ω の格子線の間は 100 px。5 本とも上端の水平部は枠線の約 15 px 下で、**約 7.42 Ω**。水平部は各曲線の VDD（±10 V の赤なら +9.5〜+10 V）まで続く。7.5 Ω を越える描画は無い | **照合が正** | 87 行を「正側（VDD 側）は急峻に立ち上がり、**約 7.4 Ω（軸上限 7.5 Ω のすぐ下）で水平になって VDD まで続く**。この水平部は測定上限か作図の打ち切りとみられ、実際の Ron を表すものではない（目読み）」に。89 行の見出しは「縦に立ち上がる（〜7.4 Ω で頭打ち）VS」に |
| S2 TMUX7612 Fig 5-1（facts に記載なし） | — | Fig 5-1（±15 V・温度別）では 25°C の線が約 0.95 Ω で、表の typ 1.1 Ω・Fig 5-4 の底 約 1.1 Ω と合わない | p17 Figure 5-1、600 dpi。1.2 Ω と 1.6 Ω の格子線の間は 244 px。薄茶の線（凡例で 25°C）は 1.2 Ω 線の 150 px 下で **0.954 Ω**。青（50°C）1.06、緑（85°C）1.23、紫（125°C）1.45、赤（−40°C）0.73 Ω。どれも VS = −10〜+10 V で完全に水平。Fig 5-4 の底は約 1.12 Ω | **照合が正**（DS の中の食い違い） | Ron の節に 1 行足す:「DS 内の食い違い: p17 Figure 5-1（VDD = 15 V, VSS = −15 V）の 25°C の線は約 0.95 Ω（目読み）で、表 §5.7 の typ 1.1 Ω・Figure 5-4 の底（約 1.1 Ω）と合わない。数値の根拠には表を使う」 |
| S3 PCM1804 見出しの食い違いのページ | 349 行「p9〜11」 | 同じ見出しは p9〜12 の 4 ページ | pdftotext と p12 の画像で確認。p9・p10・p11 上段（SINGLE RATE）は "VCC = 3.3 V, VDD = 5 V, master mode, fS = 48 kHz, …"。p11 下段（DUAL RATE）と p12（QUAD RATE・DSD MODE）も "VCC = 3.3 V, VDD = 5 V"（fS の句が無い短い形）。p13〜14 は見出しなし。**p15 は "VCC = 5 V, VDD = 3.3 V" で正しい向き** | **照合が正** | 「p9〜12 の TYPICAL PERFORMANCE CURVES（SINGLE / DUAL / QUAD / DSD の各見出し）。p15 の見出しは "VCC = 5 V, VDD = 3.3 V" で推奨条件と同じ向き」に |
| S4 AZ850 開閉電圧の注 | 173 行、"220 VDC* or 250 VAC" を引用しているが "*" の中身が無い | 注「30 VDC を越える開閉は要相談」がある | p1 CONTACTS。"\* Note: If switching voltage is greater than 30 VDC, special precautions must be taken. Please contact the factory." | **補足（照合が正）** | 条件欄に「220 VDC には注: 30 VDC を越える開閉は要相談（"special precautions must be taken. Please contact the factory."）」を足す |
| S5 TBD62083A tON/tOFF の試験条件 | 228 行、VOUT = 50 V, RL = 125 Ω, CL = 15 pF | p7 試験回路 8 の注: 入力パルス 50 µs・Duty 10 %・VIH = 5.0 V（TBD62083A）・tr ≤ 5 ns | p5 表の Test Circuit 欄は "8"。p7 "Note 1: Pulse width 50 μs, Duty cycle 10% / Output impedance 50 Ω, tr ≤ 5 ns, tf ≤ 10 ns / … TBD62083A series 5.0 V"、"Note 2: CL includes the probe and the test board capacitance." | **補足（照合が正）** | 条件欄に「試験回路 8（p7）: 入力パルス 50 µs・Duty 10 %・**VIH = 5.0 V**・tr ≤ 5 ns・tf ≤ 10 ns。CL はプローブ・基板を含む」を足す |
| S6 MCP23017 POR 後のレジスタ | 253 行、出典「p17 Table 3-4/3-5」、例に "IOCON 05 …"、"OLATA 0A …" | Table 3-5（BANK = 0）の INTF〜OLAT は p18 に続く | p17 に Table 3-4（BANK = 1）と Table 3-5 の前半、p18 に "TABLE 3-5 … (CONTINUED)"（INTFA 0E〜OLATB 15）。**照合が触れていない点:** 引用の "IOCON 05" と "OLATA 0A" は **BANK = 1 の番地**（Table 3-4）。POR 後は IOCON = 0000 0000 で BANK = 0 なので、POR 直後の番地は IOCON 0A/0B、OLATA 14 | **補足（照合が正）＋照合の見落とし** | 出典を「p16 Table 3-2/3-3、p17 Table 3-4、p17〜18 Table 3-5」に。例の引用のあとに「（引用の番地は BANK = 1 の Table 3-4 のもの。POR 後は BANK = 0 なので番地は Table 3-5: IOCON 0x0A/0x0B、OLATA 0x14）」を足す |

TMUX7612 の Fig 5-4 の他の読み（離れ始め・1.5 Ω 越え・縦の立ち上がり・負側）は、照合も facts と一致としていて、私の 150 dpi の読みとも食い違わない。
ADC1804_F 組立説明書（照合で「確かめられず」）は、誤りの主張ではないので扱っていない。

---

## 2. power.md

| 項目 | facts の記載 | 照合側の主張 | 私の読み（ページ・引用） | 判定 | facts の直し方 |
|---|---|---|---|---|---|
| P1 RS6 "Quiescent Current" の項目名 | 35 行「無負荷入力電流（"Quiescent Current"）」55 mA Max、印字 "2VDC" | 「無負荷」は DS の字句ではない（見出し条件は full load） | p2 画像。行は "Quiescent Current / nom. Vin= 5VDC 2VDC 24VDC 48VDC / 105mA 55mA 28mA 14mA"（Max 列）。条件欄に負荷の記載なし。値・列・誤植 "2VDC" は facts のとおり | **補足（照合が正）** | 項目名を「"Quiescent Current"（DS の字句のまま。負荷の条件は書かれていない。値の大きさからは無負荷時と読めるが DS はそう書いていない）」に |
| P2 TPS7A49 PSRR（Features） | 199 行「≥ 52 dB（10 Hz〜400 kHz）」、Figure 29 の構成 | Fig 14・18（IOUT = 150 mA、10 µF/10 nF）では 400 kHz で約 50 dB と読め、52 dB を下回る | p9 Figure 18、300 dpi・画素換算。CFF = 10 nF の線: 120 Hz 72.6、1 kHz 71.6、10 kHz 58.7、100 kHz 53.8、200 kHz 61.5、**400 kHz 50.1 dB**。p14 §9.1.5 は "above 52 dB from 10 Hz to 400 kHz; **see Figure 18** and Figure 25" と自分でこの図を指している | **照合が正**（DS の中の食い違い。facts の表 211 行は既に 400 kHz = 50 と書いており、値の誤りではない） | 199 行の条件欄に「DS 内の食い違い: この文が参照する Figure 18（VOUT = 5 V, IOUT = 150 mA, COUT = 10 µF, CNR/SS = CFF = 10 nF）は 400 kHz で約 50 dB（目読み）。52 dB の条件は DS に書かれていない」を足す |
| P3 TPS7A30 PSRR（Features） | 325 行「≥ 55 dB（10 Hz〜700 kHz）」 | Fig 18（CFF = 10 nF）は 400 kHz で約 54 dB、Fig 14/16（CFF = 0）は 100 kHz で約 53 dB | p10、300 dpi・画素換算。Figure 18 CFF = 10 nF: 100 kHz 55.7、200 kHz 60.9、300 kHz 59.5、**400 kHz 53.9**、500 kHz 49.4、**700 kHz 44.8 dB**。Figure 14 COUT = 10 µF: 100 kHz 53.2、**700 kHz 44.6 dB**。p18 §9.1.3 は "above 55 dB from 10 Hz to 700 kHz; **see Figure 18** and Figure 26" | **照合が正。ただし照合は 400 kHz までしか見ておらず、食い違いは 700 kHz の端で約 10 dB ある** | 325 行の条件欄に「DS 内の食い違い: この文が参照する Figure 18（VOUT = −5 V, IOUT = 200 mA, COUT = 10 µF, CNR/SS = CFF = 10 nF）は 400 kHz で約 54 dB、**700 kHz で約 45 dB**（目読み）。Figure 14（COUT = 10 µF, CFF = 0）も 700 kHz で約 45 dB」を足す |
| P4 TPS7A30 Do's and Don'ts | 359 行「2.2 µF 以上を IN・OUT の近くに」 | 原文の「at least」は個数に掛かる。容量の下限は別の箇所（p18） | p23 §9.3 は "Place at least one low-ESR, 2.2-μF capacitor …"（照合の言うとおり個数）。ところが**同じ p23 の §10 Power Supply Recommendations** に "The input and output supplies must also be bypassed with **at least a 2.2-μF capacitor** located near the input and output pins. There must be no other components located between these capacitors and the pins." とある | **facts が正**（照合の注記は §10 を見落としている） | 値は直さない。出典を「p23 §9.3・§10」にして、§10 の原文を引用に足せばよい。§10 の「コンデンサとピンの間に他の部品を置かない」も配置の制約として書く価値がある |
| P5 LT1763 の出典 | 377 行、"1763fg"・Rev G。README の "1763fh" と違う | PDF は各ページ下に "www.BDTIC.com/Linear" の透かし、Author も www.BDTIC.com（第三者のミラー） | `pdfinfo`: Author "www.BDTIC.com"、Creator InDesign CS2、CreationDate 2010-05-17、ModDate 2013-08-07。p1・p5・p11・p16 の下端に "www.BDTIC.com/Linear" | **照合が正** | 出典に「PDF は Linear Technology の Rev G（"1763fg"）を第三者サイト（BDTIC）が配布したもの。ADI の現行版ではない」を足す |
| P6 LT1763 GND ピン電流の試験条件 | 401 行は Note 7 の後半のみ。417 行「試験は VIN = VOUT(NOMINAL) のみ」 | 前半は「VOUT(NOMINAL) または 2.3 V（C/I）/ 2.35 V（MP）の大きい方、電流源負荷」 | p6 Note 7 "GND pin current is tested with VIN = VOUT(NOMINAL) or VIN = 2.3V (C, I grade) or 2.35V (MP grade), whichever is greater, and a current source load." | **照合が正** | 417 行を「試験は VIN = VOUT(NOMINAL) と 2.3 V（C/I）／2.35 V（MP）の大きい方、電流源負荷（Note 7）。これより高い VIN の規定値は無い」に |
| P7 LT1763 Ripple Rejection | 407 行、50 / 65 dB MIN/TYP、120 Hz、500 mA | この行に ● は無く、50 dB の最小値は 25°C だけ | p5 画像。Ripple Rejection の行の ● 欄は空。見出し "The ● denotes the specifications which apply over the full operating temperature range, otherwise specifications are at TA = 25°C." | **照合が正** | 条件欄に「TA = 25°C（● なし。全温度の規定ではない）」を足す |
| P8 LT1763 PSRR の周波数特性（facts に無い） | 120 Hz の 50/65 dB だけ | p11 "Input Ripple Rejection" 2 枚、COUT = 10 µF で 100 kHz 約 40、200 kHz 約 30、1 MHz 約 22 dB | p11、300 dpi・画素換算（2 枚とも IL = 500 mA、VIN = VOUT(NOMINAL) + 1 V + 50 mVRMS）。**左図（CBYP = 0、COUT = 10 µF / 4.7 µF）**: 10 µF の線は 1 kHz 約 49、約 30 kHz に約 49 dB の山、100 kHz 約 37、200 kHz 約 28、1 MHz 約 21 dB。**右図（COUT = 10 µF、CBYP = 0.01 µF / 1000 pF / 100 pF）**: 30 kHz 以上で 3 本が重なり、100 kHz 約 41、200 kHz 約 32、500 kHz 約 24、1 MHz 約 22 dB | **照合が正**（値は ±3 dB の範囲で一致） | LT1763 の節に行を足す:「グラフ: Input Ripple Rejection vs 周波数（p11、目読み）。IL = 500 mA、VIN = VOUT(NOMINAL) + 1 V + 50 mVRMS。COUT = 10 µF で 100 kHz 約 37〜41 dB、200 kHz 約 28〜32 dB、1 MHz 約 21〜22 dB（CBYP による差は 30 kHz 以上でほぼ無い）」 |
| P9 LT1763 最小 ESR（facts に無い） | 412 行、「最小 3.3 µF・ESR 3 Ω 以下」と CBYP 別の推奨容量のみ | p16 Figure 3。最小 ESR はバイパス容量で決まり、COUT が小さいと ESR ≈ 0 は安定域の外 | p16 本文 "The shaded region of Figure 3 defines the range over which the LT1763 regulators are stable. The minimum ESR needed is defined by the amount of bypass capacitance used, while the maximum ESR is 3Ω."。Figure 3（400 dpi）: 安定域の下限の線が ESR = 0 に届く COUT は、**CBYP = 0 で約 2.7〜3 µF、100 pF で約 4 µF、330 pF で約 5 µF、≥ 1000 pF で約 6 µF**。それより小さい COUT では、ESR 0.2〜0.8 Ω 程度より上でないと安定域に入らない。横軸は 10 µF まで | **照合が正** | 412 行の次に足す:「安定域（p16 Figure 3、目読み）: 最大 ESR は 3 Ω。最小 ESR は CBYP で決まり、ESR ≈ 0（セラミック）で安定になる COUT は CBYP = 0 で約 3 µF 以上、100 pF で約 4 µF、330 pF で約 5 µF、1000 pF 以上で約 6 µF 以上。原文 "The minimum ESR needed is defined by the amount of bypass capacitance used, while the maximum ESR is 3Ω."。同じページの本文に "When used with a 5V regulator, a 16V 10µF Y5V capacitor can exhibit an effective value as low as 1µF to 2µF for the DC bias voltage applied and over the operating temperature range." とある（Figure 4・5）」 |
| P10 TPS7A49 EN のヒステリシス | 248 行「EN の閾値のヒステリシスの規定値（Figure 13 のグラフのみ）」 | Figure 13 は境界の線が 1 本だけで、ヒステリシスはグラフにも無い | p9 Figure 13。ON/OFF の境界は 1 本（−40°C 約 1.9 V、25°C 約 1.7 V、125°C 約 1.4 V）。EC 表（p6）は VEN(high) min 2.1 V、VEN(low) max 0.4 V のみ | **照合が正** | 「EN の閾値のヒステリシス: 規定値もグラフも無い（Figure 13 は ON/OFF の境界を 1 本の線で示すだけ。25°C で約 1.7 V、目読み）」に |
| P11a 絶対最大の FB・NR/SS 対 IN の行（facts に無い） | 省略 | TPS7A49 −36/+0.3 V、TPS7A30 −0.3/+36 V | p5 の両方で確認（"FB pin to IN pin"、"NR/SS pin to IN pin"、ほかに "EN pin to IN pin"、"OUT pin to IN pin" も同じ値） | **照合が正**（抜け） | 追記は任意 |
| P11b TPS7A30 の設計例 Eq.8（facts に無い） | TPS7A49 の 35 µF だけ | TPS7A30 は ICL(min) = 220 mA で 15.4 µF | p21 Eq.7・8。「ソフトスタートを支配的にするため、電流制限での立ち上がりをソフトスタート時間の 2 桁下（140 µs）に置く」という設計例で、VOUT = −2 V の例の値。上限の規定ではない。TPS7A49 の例は ICL(max)、TPS7A30 の例は ICL(min) を使っていて、式の置き方も揃っていない | **照合が正**（抜け） | 追記は任意。書くなら「設計例（VOUT = 2 V、tSS = 14 ms）での目安で、規定値ではない」と明記 |
| P11c TPS7A49 p16 のヘッドルーム | 228 行、定義の文のみ | 同じ段落で 1.8 V を「ヘッドルーム」と呼んでいて定義と合わない | p16 "the dropout headroom of 1.8 V is sufficient …" の直後に "Dropout headroom is calculated as VIN – VOUT – VDO(max), and for optimal performance must be at least 1 V." | **照合が正**（DS 内の不整合。facts の誤りではない） | 直さなくてよい |

LT1763 の SHDN 閾値の温度グラフ、GND ピン電流の VIN 依存のグラフ、TPS7A49 のソフトスタート波形（照合が「近い情報がある」とした残り）は、ページにあることだけ確かめた。facts の「規定値は無い」は正しい。

---

## 3. opamps.md

| 項目 | facts の記載 | 照合側の主張 | 私の読み（ページ・引用） | 判定 | facts の直し方 |
|---|---|---|---|---|---|
| O1 OPA1652 入力間ダイオード | 208 行「差動入力（絶対最大）規定なし」、213 行「探したが無かった: 入力間の保護ダイオードの記述」 | p15 §7.3.2 に back-to-back ダイオード、入力電流 10 mA 以下 | p15 画像。§7.3.2 Input Protection "The input terminals of the OPA1652 and OPA1654 are protected from excessive differential voltage with back-to-back diodes, as Figure 36 illustrates. … in low-gain or G = 1 circuits, fast ramping input signals can forward bias these diodes … the input signal current must be limited to 10 mA or less."。Figure 36 に入力間の逆並列ダイオードが描かれている。§7.3.3 に ESD の current-steering diodes の説明が別にある | **照合が正（facts の誤り）** | 213 行から「入力間の保護ダイオードの記述」を消す。行を足す:「入力保護（本文）: 入力間に back-to-back ダイオード。G = 1 など低利得で入力が速く動くと順バイアスになりうるので、入力信号電流を 10 mA 以下に制限（入力直列抵抗か帰還抵抗で）。p15 §7.3.2・Figure 36」 |
| O2 OPA1612 入力間ダイオード | 257 行「規定なし」、262 行「入力間の保護ダイオードの有無の記述（ESD 用 steering diodes の説明 p.13 のみ）」 | p14 §7.3.4 に back-to-back ダイオード | p14 §7.3.4 "The input terminals of the OPA1611 and the OPA1612 are protected from excessive differential voltage with back-to-back diodes, as Figure 31 shows. … If the input signal is fast enough to create this forward bias condition, the input signal current must be limited to 10 mA or less."（Figure 17 の Typical Characteristics に現象の図があるとも書いてある） | **照合が正（facts の誤り）** | O1 と同じ形で直す。出典は p14 §7.3.4・Figure 31 |
| O3 NJM5532 入力ダイオード | 62 行「探したが無かった: 入力保護ダイオードの有無の記述」 | p5 NOTICE、p1 等価回路、p6 寄生回路の注意 | p5 NOTICE "When used in voltage follower circuit, put a current limit resistor into non-inverting input terminal in order to avoid inside input diode destruction when the power supply is turned on. ( ref.Fig.1 )"、Fig.1 は入力直列 1k。p1 EQUIVALENT CIRCUIT に +INPUT と −INPUT の間の逆並列ダイオード 2 個が描かれている。**p6 "Countermeasure to Excess Current by Parasitic Circuit"**: "When the NJM5532 V+ is open (Fig.2), the NJM5532 may be burnt flowing the excess current by internal parasitic circuit"。起こる条件は「入力と V− の電位差が大きい」「入力に 1 kΩ 以上の抵抗が無い」「V+ 端子が低インピーダンスにつながっている」。対策は SBD の挿入（Fig.4-1/4-2）か 1 kΩ 以上の抵抗（Fig.5） | **照合が正（facts の誤り）**。照合は p6 を補足の一言で済ませているが、中身は p5 より重い | 62 行から「入力保護ダイオードの有無の記述」を消す。行を 2 つ足す:「入力保護: 入力間に逆並列ダイオード（p1 等価回路）。ボルテージフォロワでは電源投入時の入力ダイオード破壊を避けるため、非反転入力に電流制限抵抗（図は 1 kΩ）。p5 NOTICE」／「V+ 開放時の過電流: V+ が開放で、入力と V− の電位差が大きく、入力に 1 kΩ 以上の抵抗が無いと、内部の寄生回路で過電流が流れ焼損しうる。対策は SBD か 1 kΩ 以上の入力抵抗。p6」。差動入力の絶対最大 ±0.5 V（59 行）はこのダイオードと合う |
| O4 OPA2134 Headroom | 102 行、typ 21.3 dBu、"VS = 18V"（原文どおり） | p13 §6.2.1 と p9 Figure 5-4 は ±18 V・THD+N < 0.01 % で 11.7 Vrms = 23.6 dBu | p7 表 "Headroom(1) THD < 0.01%, RL = 2kΩ, VS = 18V 21.3 dBu"。p13 "…maximum allowable output voltage level of 11.7Vrms (THD+Noise < 0.01%), have a headroom specification of 23.6dBu. See Figure 5-4."。p9 Figure 5-4 の凡例 "VS = ±18V, RL = 2kΩ, f = 1kHz / THD < 0.01% / OPA134 – 11.7Vrms"。20·log(11.7/0.7746) = 23.6 dBu で本文と合う。21.3 dBu は 9.0 Vrms（12.7 Vpk）で、±18 V でのクリップ手前としては低い（±15 V 程度の値に見えるが、DS はそう書いていないので推測） | **照合が正** | 102 行の条件欄に「DS 内の食い違い: p13 §6.2.1 と p9 Figure 5-4 は VS = ±18 V・THD+N < 0.01 % で 11.7 Vrms = 23.6 dBu。表の 21.3 dBu（= 9.0 Vrms）とは 2.3 dB 違う。表の "VS = 18V" の意味（±18 V か 18 V 単電源か）は DS から決められない」を足す |
| O5 OPA2604 Fig 15 | 154 行「低域で約 26 Vp-p」 | 平坦部は 24 Vp-p の目盛線の上 | p8 Figure 15、400 dpi。縦軸は 0〜30 Vp-p で細目盛 2 Vp-p（30 の枠線 y≈42、20 の太線 y≈258、10 の太線 y≈474 → 2 Vp-p = 43 px）。平坦部は y ≈ 172 で **24 Vp-p の細目盛線に重なる**。約 350 kHz から下がる | **照合が正** | 「低域（10 kHz〜約 300 kHz）で約 24 Vp-p（目読み。負荷の表記なし）」に |
| O6 OPA1612 Fig 27 | 253 行「25°C で 0〜約 45 mA で約 +14.1 V / 約 −14.6 V」 | 正側 +14.35（0 mA）〜+14.2（43 mA）、負側 −14.35（0 mA）〜−14.0（43 mA） | p11 Figure 27、400 dpi・画素換算（上側は 14.5 V と 14.0 V の格子線の間 126 px、下側は −14.0 と −14.5 の間 125 px）。+25°C の引き出し線が指す実線は、正側 **+14.35 V（0 mA）→ +14.2 V（44 mA）**、負側 **−14.3 V（0 mA）→ −14.2 V（44 mA）**。負側で −14.0 V 付近まで上がるのは一点鎖線（+85°C）で、44 mA で約 −14.0 V | **照合が正（facts の −14.6 V は誤り）**。照合の負側の「−14.0 V」の端は +85°C の線を拾った可能性があり、25°C の線としては −14.2 V 付近 | 「25°C の線で、0〜約 45 mA の範囲で約 +14.35〜+14.2 V / 約 −14.3〜−14.2 V（目読み。+85°C の線は負側が約 −14.0 V まで上がる）」に |
| O7 MUSES01 ±15 V 負荷抵抗グラフ | 356 行「±15 V で 2 kΩ 約 +13.5 / 約 −13 V」 | +14.0 / −13.2〜−13.4 V。facts 自身の温度グラフの行（+14）とも合わない | p10 右下 "MAXIMUM OUTPUT VOLTAGE vs LOAD RESISTANCE (TEMPERATURE) V+/V-=±15V"、400 dpi・画素換算（縦 1 V = 27.2 px）。2 kΩ で、3 本（赤・青・黒）の正側は **+13.9〜+14.2 V**、負側は **−13.0〜−13.3 V**（黒 −13.1 V）。10 kΩ で +14.1〜+14.4 / −13.2〜−13.6 V | **照合が正** | 「±15 V で 2 kΩ 約 +14.0 / 約 −13.1 V（目読み。温度 3 本の幅 ±0.2 V）」に |
| O8 OPA627 Fig 5-23 | 229 行「低域で約 25 Vp-p、条件 VS = ±15 V、**RL = 10 kΩ**」 | ページにも図にも負荷の記載は無い | p16 見出し "at TA = 25°C and VS = ±15V (unless otherwise noted)"。図中は "OPA627"・"OPA637" のラベルだけで負荷の記載なし。値は 25 Vp-p（私の読み 25.2）。**加えて: 横軸は 100 kHz〜100 MHz で、「低域」は 100 kHz〜約 1.5 MHz の平坦部のこと** | **照合が正** | 「100 kHz〜約 1.5 MHz の平坦部で約 25 Vp-p（目読み。横軸は 100 kHz から。負荷の記載なし）」、条件「VS = ±15 V、25°C（ページ既定）」に |
| O9a LME49860 ±12 V の THD+N vs Output Voltage | 188 行ほか。±12 V は Fig 96（THD+N = 1 % の Vrms）のみ | p5 Figure 4・8、p6 Figure 12 に ±12 V（2 kΩ / 600 Ω / 10 kΩ）がある。2 kΩ の急増は約 8 V | p5 画像。Figure 4 "VCC = 12V, VEE = −12V, RL = 2kΩ"、Figure 8 同 600 Ω。p6 Figure 12 同 10 kΩ。Figure 4 の急増は約 7〜8 V（横軸は "OUTPUT VOLTAGE (V)" で rms か peak かの表記なし） | **照合が正**（抜け） | 追記推奨:「グラフ: THD+N vs Output Voltage、±12 V（Figure 4 = 2 kΩ、Figure 8 = 600 Ω、Figure 12 = 10 kΩ）。2 kΩ で約 7〜8 V から急増（目読み。単位は "V" のみ）」 |
| O9b OPA1656 Fig 6-8 | 137 行ほか。±15 V の振幅グラフに触れていない | ±15 V の THD+N Ratio vs Output Amplitude、急増は約 10 Vrms | p9 Figure 6-8、ページ見出し "VS = ±15 V, RL = 2 kΩ"。6 本（G = ±1、600 Ω / 2 kΩ / 10 kΩ）。約 7〜8 Vrms から上がり始め、10 Vrms 付近で急増 | **照合が正**（抜け） | 追記は任意 |
| O9c OPA2140 Fig 6-22 | 313 行ほか | ±15 V の線、低域で約 29 Vpp | p12 Figure 6-22 "Maximum Output Voltage vs Frequency"、"VS = ±15 V" の線は約 29 Vpp（ページ既定は ±18 V だが線に ±15 V と明記） | **照合が正**（抜け） | 追記は任意 |
| O9d NE5532 Fig 7-2〜7-4 | 触れていない | 単電源 15 V の応用例の伝達特性。仕様ではない | p9 に Figure 7-2〜7-4。p7 "Information in the following applications sections is not part of the TI component specification" | **照合が正**（ただし仕様ではない） | 追記不要 |

照合の「誤り（目読み）」3 件（O5〜O7）の許容幅「最も細かい目盛の半分」は妥当だった。O6 のみ、照合自身の読みも温度の線を取り違えている疑いがある。

---

## 4. 照合が見落としていたもの（facts・照合とも書いていない）

| 項目 | ページ・原文 | 意味 |
|---|---|---|
| TPS7A30 の PSRR は 700 kHz で約 45 dB | p10 Figure 18（CFF = 10 nF）44.8 dB、Figure 14（COUT = 10 µF）44.6 dB。§9.1.3 の「700 kHz まで ≥ 55 dB」とは約 10 dB 違う | P3 の食い違いは 400 kHz の 1 dB ではなく、帯域の端で 10 dB |
| TPS7A30 §10 の 2.2 µF と配置 | p23 "bypassed with at least a 2.2-μF capacitor located near the input and output pins. There must be no other components located between these capacitors and the pins." | P4 の照合の注記を打ち消す。配置の制約でもある |
| MCP23017 の引用番地は BANK = 1 の配置 | p17 Table 3-4（BANK = 1）の IOCON 05・OLATA 0A。POR 後は BANK = 0（Table 3-5: IOCON 0A/0B、OLATA 14） | ファームで番地を facts から写すと外れる |
| NJM5532 p6 の寄生回路（照合は補足の一言だけ） | 上の O3 | ch ごとに電源を落とす構成に直接かかわる（次節） |
| OPA627 Fig 5-23 の横軸は 100 kHz から | p16 | 「低域 25 Vp-p」は音声帯域の値ではない |
| NJM4580 の等価回路には入力間ダイオードが描かれていない | p1 EQUIVALENT CIRCUIT（画像） | NJR 品のうち NJM5532 だけが該当。MUSES01/02/03 は本文検索で diode・follower・parasitic が 0 件（等価回路の画像は見ていない） |

---

## 5. v2.1 の設計判断に効きうるもの

前提（依頼文のとおり）: ch ごとのソケット電源 ±12 V を TPS7A49 / TPS7A30 で ±15 V から作る。ADC の LDO は LT1763 で PD 12 V の枝から。DC-DC は RS6-1215D。TMUX7612 は ±15 V。

1. **ch ごとに電源を落とす構成と、入力ダイオード（O1〜O3）** — 効く、優先度は最も高い。
   NJM5532 の p6 は「V+ が開放で、入力に 1 kΩ 以上の抵抗が無く、入力と V− の差が大きいと焼損しうる」と書いている。
   v2.1 は「選んだ ch だけ電源と入力を生かす」構成なので、次の点を設計で決めておく必要がある。
   - 正負の LDO を必ず同時に落とすか（片側だけ生きている状態を作らない）
   - 電源を落とした ch の入力を、TMUX7612 などで確実に切り離すか
   - 切り離せない経路があるなら、非反転入力に 1 kΩ 以上の直列抵抗を置くか

   OPA1652 / OPA1612 の入力間ダイオードも、G = 1 のバッファで速い立ち上がりが来たときに 10 mA の制限がかかる。
   facts は 3 石とも「記述は無い」と書いていたので、facts を根拠に「入力保護は気にしなくてよい」と判断していたなら、その判断は根拠を失う。

2. **LDO の除去比を 200 kHz より上で見積もること（P2・P3・P8）** — 効く。
   - RS6 の内部動作周波数は **Min 200 kHz しか規定がない**（p2。Typ・Max は空欄）。リップルの基本波は 200 kHz より上にありうるし、高調波はさらに上に出る
   - TPS7A49 は 400 kHz で約 50 dB。TPS7A30 は 400 kHz で約 54 dB、700 kHz で約 45 dB（どちらも 10 µF / 10 nF / 10 nF のとき）。Features の「≥ 52 / ≥ 55 dB」で見積もると、700 kHz 付近で約 10 dB 楽観的になる
   - **LT1763 は 200 kHz で約 30 dB、1 MHz で約 22 dB** しかない（120 Hz の 50/65 dB とは別物）。PD 12 V の枝に DC-DC の反射リップルや PD 電源自体のスイッチングが乗るなら、LDO の前に LC か RC の前段フィルタを置くかどうかは、この数字で決まる
   - ただし、どのグラフも LDO の入出力差が 1〜1.2 V 程度の条件で測っている。v2.1 の入出力差（15→12 V で 3 V、12→5 V で 7 V）では、実際の除去比はこれより良い方に振れうる。DS にはその条件のグラフが無い

3. **LT1763 の出力コンデンサ（P9）** — 効く。
   ESR ≈ 0 のセラミックだけで組むなら、COUT は約 3〜6 µF 以上（CBYP による）が安定の条件で、CBYP ≥ 1000 pF なら DS の推奨は 6.8 µF。
   同じページの本文には「5 V レギュレータで使うと、16 V・10 µF の Y5V は DC バイアスと温度で実効 1〜2 µF まで下がりうる」とある（Figure 4・5）。
   X5R / X7R で、5 V バイアスをかけた実効値が 6.8 µF を割らない部品を選ぶこと。最大 ESR は 3 Ω。

4. **TMUX7612 の Ron（S1・S2）** — 効かない。
   ±15 V 電源で正側の Ron が底から離れ始めるのは約 +10.6 V、1.5 Ω を越えるのは約 +13.1 V。ここは facts と照合で一致している。
   ±12 V 電源の石の出力（最大でも ±11 V 程度）が来ると、正側の上端だけが Ron の立ち上がりの手前にかかる。これは facts の既存の行から言えることで、7.4 か 7.5 Ω か、0.95 か 1.1 Ω かは関係しない。

5. **最大出力レベルの見積もり（O4〜O7、O9a）** — 小〜中。
   ±15 V のグラフを ±12 V に読み替えるなら、OPA2604 はレールから約 3 V 手前（24 Vp-p）で、facts の 26 Vp-p では 1 V 楽観的だった。
   OPA1612 は負側 −14.3 V でレールまで 0.7 V（facts の −14.6 V では 0.4 V で、楽観的だった）。
   ±12 V で直接の資料があるのは LME49860 の Figure 4・8・12 と Fig 96（約 7.9 Vrms、THD+N 1 %）で、これは facts に足しておくとよい。
   OPA2134 の Headroom は ±18 V（または不明な条件）の値なので、±12 V の見積もりには使えない。

6. **その他（S3〜S6、P1、P4〜P7、P10〜P11、O8、O9b〜d）** — 設計判断には効かない。
   ただし次の 2 つは実装で踏みうる。
   - TBD62083A の tON/tOFF は VIH = 5.0 V での値。3.3 V ロジックで駆動するなら保証外。リレー駆動なので時間の差は実害にならない
   - MCP23017 の番地は、BANK = 0 の表から取ること

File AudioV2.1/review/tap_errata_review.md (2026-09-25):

# tap.md 照合結果（verify_tap.md）の再照合

- 日付: 2026-09-25
- 対象: [`../ds_facts/verify_tap.md`](../ds_facts/verify_tap.md) が「誤り」「一致・補足あり」とした行、および「tap.md に無い」として挙げた項目。照合される側は [`../ds_facts/tap.md`](../ds_facts/tap.md)
- やり方: 各項目の DS ページを `pdftoppm -png` で画像にして自分で見た（表は 100〜150 dpi、グラフは 300〜400 dpi の切り出し、JT-11P-1 の低域は 800 dpi）。グラフは枠線と格子線の画素位置で軸を合わせ、指定周波数の列で曲線の画素を拾って換算した（素の Python で PPM を読んだ。PIL は壊れていた）。表の値は `pdftotext -layout` で見当をつけてから画像で列を確かめた。作業ファイルは scratchpad の `tap_errata/`
- 判定の語: **照合が正**（verify_tap.md の指摘が DS と合う）／**tap.md が正**（指摘は当たらない。tap.md のままでよい）／**どちらも不正確**（どちらの数値も DS と合わない）
- 「目読み」の値は規定値ではない。対数軸での読み取り誤差は tap.md の凡例どおり ±20〜30 % 程度はある。その範囲内のずれは「合う」と扱った

## 集計

| 区分 | 件数 | 照合が正 | tap.md が正 | どちらも不正確 |
|---|---|---|---|---|
| 誤り | 13 | 13 | 0 | 0 |
| 一致・補足あり | 23 | 23 | 0 | 0 |
| tap.md に無い（照合が挙げたもの） | 17 | 15 | 1 | 1 |

- 誤り #9（JT-11P-1）は、指摘の本体（+4 dBu の 130 Hz）は照合が正。ただし照合が同じ行で書いた **「+20 dBu は 30 Hz で約 0.11 %」は誤り**（30 Hz では約 0.06 %、0.1 % を切るのは約 27 Hz）。tap.md の「約 30 Hz で 0.1 %」はおおむね合っている。この部分は照合の読みを採らなかった
- 一致・補足ありのうち 3 件（INA1650 Fig 12、SSM2141 CMR、AD8274 Fig 15）は、補足の方向は正しいが一部の数値を私の読みで置き換えた（下の表）
- 「tap.md に無い」の「どちらも不正確」1 件は **AMC3336 Figure 6-35**。照合は「高調波は約 −117〜−125 dBV」としたが、**3 次（3 kHz）は約 −109 dBV、2 次（2 kHz）は約 −115 dBV** まで出ている。tap.md には元々この図の行が無い
- 「tap.md が正」1 件は ISO7741 の 50 / 100 Mbps。tap.md は食い違いを原文どおり書いており、照合のクロック換算（24.576 MHz → 49.152 Mbps）は設計の読みなので tap.md には入れない

---

## 1. 誤り（13 件）

| # | 部品・項目 | 照合の主張 | 私が DS で見たもの | 判定 | tap.md への反映 |
|---|---|---|---|---|---|
| 1 | ISOW7741 ジッタ／tie（Q4-9） | 「DS に無い」は誤り。tie は p27〜p30 に TYP 0.7 / 0.65 / 0.7 / 0.7 ns | p28 §7.20 を画像で確認: 最終行 "tie Time interval error 2^16 – 1 PRBS data at 100 Mbps"、TYP 列に 0.65 ns。p27（5 V）0.7、p29（2.5 V）0.7、p30（1.8 V）0.7 ns を抽出で確認 | 照合が正 | 行を tie の値に差し替え |
| 2 | Q4「無かった項目」: 規定があるのは ISO7741 / ISO7762 の tie と Si864x の 350 ps だけ | Si860x の 350 ps と ISO7762 Fig 5-17 が漏れ | Si860x p16 Table 5.4（非 I2C チャネル）に "Peak Eye Diagram Jitter tJIT(PK) — 350 — ps"（Typ 列）。ISO7762 p25 Figure 5-17 "Peak-to-Peak Output Jitter vs Data Rate"（TA = 25°C、2.5 / 3.3 / 5 V の立上り・立下り 6 本）。私の読み: 10 Mbps で約 0.76〜0.94 ns、50 Mbps で約 0.93〜1.09 ns、100 Mbps で約 1.09〜1.29 ns（立上りが低く、立下りが高い） | 照合が正 | 箇条を訂正。ISO7762 と Si860x に行を追加 |
| 3 | Q4「無かった項目」: ADuM1400・ADuM5401・ISOW7741 はジッタ・tie なし | ISOW7741 だけ誤り | ADuM1400・ADuM5401 は全文に jitter / interval error が 0 件。ISOW7741 は #1 | 照合が正 | 箇条を訂正 |
| 4 | HCPL-7800 雑音密度（Q3「無かった項目」） | p19 の FAQ に入力換算 約 500 nV/√Hz | p19 を画像で確認: "The noise spectral density is roughly 500 nV/s Hz below 20 kHz (input referred)."（印字は "nV/s Hz"） | 照合が正 | 箇条を訂正、行を追加 |
| 5 | INA1620 Figure 14 | −128 dB ではなく G = −1 約 −126、G = +1 約 −132.5 dB | p9 を 400 dpi で読んだ: 破線（G = −1、3 負荷）約 −126 dB、実線（G = +1、3 負荷）約 −132.5 dB、負荷差はほぼ無い。実線は約 1 kHz から上がり 2 kHz で約 −131 dB、20 kHz で約 −118 dB | 照合が正 | 行を訂正 |
| 6 | INA1650 Figure 9（100 kHz） | GND 約 73、VMID 約 74 dB。78 dB は約 60 kHz | 400 dpi で画素を拾った: 100 kHz で GND 約 73.5、VMID 約 74.5 dB。GND が 78 dB になるのは約 63 kHz。低域 GND 91.0 / VMID 86.0、10 kHz で 89.0 / 85.3 dB | 照合が正 | 行を訂正（10 kHz も 89 dB に） |
| 7 | INA137 高調波（1 kHz の 2 次） | 約 0.00007 % | p4 を 400 dpi で読んだ: 2 次は 20 Hz 約 0.00018 %、約 800 Hz から平坦で約 0.00007 %。3 次（"Noise Limited" の破線）約 0.00004 % | 照合が正 | 行を訂正 |
| 8 | SSM2141 THD（600 Ω・20 kHz） | 約 0.018 %。0.01 % は約 10 kHz | p3 の AP 画面を 400 dpi で読んだ: 600 Ω は 10 kHz で約 0.009 %、20 kHz で約 0.017 %。低域は両負荷とも約 0.0008 %、100 kΩ の 20 kHz は約 0.002 % | 照合が正 | 行を訂正 |
| 9 | JT-11P-1 左の図（+4 dBu の 130 Hz） | 130 Hz で約 0.0016 %、0.001 % は約 240 Hz | 400 dpi で画素、800 dpi で曲線の識別を確認: +4 dBu は 20 Hz 約 0.023 %、60 Hz 約 0.0045 %、130 Hz 約 0.0016 %、0.001 %（図の下端）に届くのは約 245 Hz。+14 dBu は 20 Hz 約 0.052 %、50 Hz 約 0.010 %。**+20 dBu は 20 Hz 約 1 %、0.1 % を切るのは約 27 Hz、30 Hz では約 0.06 %**（照合の「30 Hz 約 0.11 %」は誤り） | 照合が正（+20 dBu の 30 Hz だけ照合を採らない） | 行を訂正 |
| 10 | Q5「無かった項目」: 20〜50 Hz の THD のグラフは Jensen だけ | Hammond 560G p3 にもある | `Hammond_560.pdf` p3 に "560G Rs-150 Rl=150 THD+N"（10 Hz〜100 kHz、0 / 10 / 27 dbm）。縦軸は線形 −20〜50「THD+N (%)」で負の値まで描かれている | 照合が正 | 箇条を訂正 |
| 11 | SSM2143 5 Ω 不整合で 71 dB のページ | p6 ではなく p7 | PDF p7（下端 "–7–"、"APPLICATIONS INFORMATION"）に "a CMRR of 71 dB at dc"。挿入ページは無い | 照合が正 | 出典を p7 に |
| 12 | ADuM1400 3 V CRW 伝搬遅延のページ | p8 ではなく p7 | p7（"Table 2. (Continued)"、下端 "Rev. M \| 7 of 33"）の CRW 欄に 20 / 34 / 45 ns | 照合が正 | 出典を p5, p7 に |
| 13 | ADuM1400 3 V CRW PWD のページ | p8 ではなく p7 | 同じ p7 に 0.5 / 2 ns。p8 にあるのは Refresh Rate 1.1 Mbps | 照合が正 | 出典を p5, p7 に |

## 2. 一致・補足あり（23 件）

| # | 部品・項目 | 照合の補足 | 私が DS で見たもの | 判定 | tap.md への反映 |
|---|---|---|---|---|---|
| 1 | INA134 版 | p1 下に "PDS-1390A … July, 1997" | p1 に "©1997 Burr-Brown Corporation PDS-1390A Printed in U.S.A. July, 1997" | 照合が正 | 反映せず（版の表は「改訂日の印字なし」で誤りではない） |
| 2 | INA137 版 | "PDS-1391B … July, 1997" | 同様に PDS-1391B | 照合が正 | 反映せず |
| 3 | ACPL-C87x 版 | 表紙に "September 16, 2024" | 表紙に AV02-3563EN と September 16, 2024 | 照合が正 | 反映せず |
| 4 | HCPL-7800 版 | 表紙に "November 19, 2020" | 表紙に AV02-0410EN と November 19, 2020 | 照合が正 | 反映せず |
| 5 | INA1620 冒頭の注意（差動アンプの CMRR 規定なし） | p21 Figure 52 に同じ石の全抵抗の最大–最小マッチングの典型分布 | p21 §8.1.2 に Figure 52 "Matching Histogram, Maximum to Minimum"。私の読み: 山は約 0.15〜0.25 %、大半は約 0.35 % 以下、裾は約 1.5 % まで（0.05 % 刻みの棒） | 照合が正（山の位置は照合の「0.15〜0.3 %」より少し狭く読んだ） | 行を追加、「無かった項目」を訂正 |
| 6 | INA1650 Figure 12 | 600 Ω は 20 Hz 約 −106.4、10 kHz 約 −105.5 dB | 2 kΩ は約 −108 dB で平坦。600 Ω は 20 Hz 約 −106.3 dB、中域 約 −108 dB、10 kHz 約 −106.5 dB、20 kHz 約 −101 dB | 照合が正（10 kHz は私の読みで約 −106.5 dB） | 行を訂正 |
| 7 | INA1650 Figure 14 | 最小は約 9.8 Vrms の約 −115 dB、そこから約 −112 dB へ跳ね、約 12 Vrms でクリップ | 1 Vrms で −100 dB。最小は約 9.7 Vrms で約 −115 dB、直後に約 −111〜−112 dB、約 11.5 Vrms で急増 | 照合が正 | 行を訂正 |
| 8 | INA134 CMR vs 周波数 | 20 kHz は約 84.7 dB | 画素で拾った: 平坦部 90.6、10 kHz 89.8、20 kHz 84.6、100 kHz 70.4 dB | 照合が正 | 行を訂正 |
| 9 | INA137 CMR vs 周波数 | 90.9 dB は約 60 kHz まで、95 kHz で 87.7 dB | 平坦部 91.0 dB、折れ始めは約 57 kHz、100 kHz 約 87.5 dB、1 MHz 約 64.3 dB | 照合が正 | 行を訂正 |
| 10 | SSM2141 CMR vs 周波数 | 平坦は約 200 Hz まで、1 kHz 約 96、100 kHz 約 58 dB | 平坦（100 dB）は約 200 Hz まで、1 kHz 約 96 dB、20 kHz 約 72 dB、100 kHz 約 57 dB（スキャン画像で線が太い） | 照合が正（100 kHz は約 57 dB と読んだ。tap.md の 55 dB も誤差の端） | 行を訂正 |
| 11 | AD8274 Figure 15 | G = ½ は約 25 kHz まで平坦、100 kHz では両方約 82 dB | G = ½ 約 94.3 dB で約 20〜25 kHz まで平坦、G = 2 約 100 dB で約 12 kHz まで。100 kHz は両方約 83 dB | 照合が正（100 kHz は約 83 dB） | 行を訂正 |
| 12 | Q2「無い」: INA1620 の差動アンプ CMRR | 値は無い。ペア外のマッチングは Fig 52 | 全文に差動アンプ構成の CMRR 値は無い。Fig 52 は #5 | 照合が正 | 箇条を訂正 |
| 13 | Q2「無い」: 20〜50 Hz のグラフの列挙 | SSM2141 の THD vs 周波数と INA1650 Fig 54 が漏れ | SSM2141 p3 の AP 画面は 20 Hz から（振幅の記載なし）。INA1650 p24 Fig 54 は 20 Hz から 4 dBu / 22 dBu | 照合が正 | 箇条を訂正 |
| 14 | AMC3330 DC/DC の周波数 | 数値は無い。同期先の変調器 20 MHz は p25 本文 | p22 に数値なし。p25 §7.2.2.1 に "the sampling frequency (20 MHz) of the internal ΔΣ modulator" | 照合が正 | 行を訂正 |
| 15 | AMC3336 DC/DC の周波数 | 数値は無い。変調器クロックは CLKIN 9〜21 MHz | p23 に数値なし。CLKIN 9 / 20 / 21 MHz は p4 | 照合が正 | 行を訂正 |
| 16 | AD215 同相入力インピーダンス | 同じ枠に差動 16 MΩ、1 行上に CMRR of Input Op Amp 100 dB | PDF p3 を画像で確認: INPUT IMPEDANCE Differential G = 1 V/V **16 MΩ**（Typ）、INPUT VOLTAGE RATINGS に **CMRR of Input Op Amp 100 dB**（Typ、条件なし） | 照合が正 | 行を 2 つ追加 |
| 17 | AD215 絶縁側電源 | 電流 ±10 mA は Typ 列だけ。注 9 で ±15 V 以上なら ±15 mA | PDF p4 を画像で確認: Voltage は Min / Typ / Max、Current at Rated Supply Voltage は Typ 列に ±10 mA のみ。注 9 の原文も確認 | 照合が正 | 行を訂正 |
| 18 | HCPL-7800 THD / SNR | 規定値は無い。p19 FAQ に SNR 改善の説明と雑音密度 | 同左 | 照合が正 | 行を訂正 |
| 19 | Si8920 高圧側電源 | p7 の図は CMTI の試験回路。応用例の根拠は p5 本文 | p7 Figure 4.1 "Common-Mode Transient Immunity Characterization Circuit" の "Isolated Supply"。p5 に浮動電源から VDDA を作る本文 | 照合が正 | 行を訂正 |
| 20 | Q3「無い」#5 AMC3330 / AMC3336 | 同期先のクロックは DS にある | #14・#15 と同じ | 照合が正 | 箇条を訂正 |
| 21 | Si860x 非 I2C チャネル | 同じ表に PWD max 12 ns と Peak Eye Diagram Jitter 350 ps | p16 Table 5.4 を画像で確認: PWD Max 12 ns、tJIT(PK) Typ 350 ps | 照合が正 | 行を 2 つ追加 |
| 22 | Q4「無い」#3 ISOW1044 Figure 9-4 | p35 の放射のグラフ。p11 の VCM も同じ番号を参照 | p35 "Figure 9-4. ISOW1044 Radiated Emissions Versus CISPR32B Line"。p11 の VCM 行ほか数行が "See Figure 9-4 and Table 9-1" | 照合が正 | 箇条を訂正 |
| 23 | JT-11P-1 右の図 | 50 Hz は −15〜+7 dBu で約 0.006 %、−25 dBu で約 0.004 % | 20 Hz 0.021〜0.024 %、30 Hz 0.012〜0.014 %、50 Hz は −15〜約 +8 dBu で約 0.006 %、−25 dBu で約 0.0043 %。上がり始めは 20 Hz で約 +5、30 Hz で約 +7、50 Hz で約 +10 dBu | 照合が正 | 行を訂正 |

## 3. 照合が「tap.md に無い」として挙げたもの

| # | 部品・項目 | 照合の記述 | 私が DS で見たもの | 判定 | tap.md への反映 |
|---|---|---|---|---|---|
| 1 | INA1650 個別高調波（p24 Fig 56 / 57、p23 本文） | 22 dBu で HD2 −133.2、HD3 −142.1、HD4 −152.7 dBc。4 dBu は 2 次がかろうじて見える | Fig 57 の図中に "HD2: -111.2 dBu (-133.2 dBc)" "HD3: -120.1 dBu (-142.1 dBc)" "HD4: -130.7 dBu (-152.7 dBc)"。基本波は図から約 1 kHz（図に周波数の印字なし）。本文 p23 も同じ値と「4 dBu では 2 次が −140 dBu の雑音床からかろうじて見える」 | 照合が正 | 行を追加 |
| 2 | INA1650 本文「THD+N は雑音が決めている」 | p23 の引用 | p23 §8.2.1.3 に原文あり（Figure 55 は 22-kHz 帯域） | 照合が正 | 行を追加 |
| 3 | INA1650 応用回路の CMRR（Fig 53） | 1 kHz で 94 dB、10 Ω 不整合で 92 dB | p23 本文にそのとおり | 照合が正 | 行を追加 |
| 4 | INA1650 Figure 54 | 22 dBu は 20 Hz で約 −111 dB、4 dBu 約 −101.6 dB | 22 dBu は 20 Hz 約 −111.7 dB、中域 約 −115 dB、約 7 kHz から上昇。4 dBu 約 −101.6 dB で平坦 | 照合が正 | 行を追加 |
| 5 | AD8274 Figure 34（G = ½、1 kHz、THD+N vs 出力振幅） | 約 19 dBu まで下がり、最小約 0.0002 %（約 −114 dB）、約 21.5 dBu でクリップ | 0 dBu で約 0.0006 %、最小は約 19〜20 dBu で約 0.00018 %（約 −115 dB）、600 Ω は約 21.5 dBu、"RL = 2kΩ, 100Ω"（原文の印字）は約 22 dBu で急増 | 照合が正 | 行を追加（Figure 35 は読んでいないので載せない） |
| 6 | AD8274 Figure 36 の H3 | 約 0.00023 %（約 −113 dBc） | 3 次（全負荷）約 0.00023 %、2 次 600 Ω 約 0.000044 %、2 次 100 kΩ/2 kΩ 約 0.000016 %、約 10 kHz から上昇 | 照合が正。tap.md の「約 0.00025 %」も目読み誤差の範囲で合う | 反映せず |
| 7 | SSM2143 Figure 4 / 6 | THD+N vs 振幅と vs 負荷。10 kΩ 以上で約 0.00045 % | Fig 4（RL = 10 kΩ、80 kHz、横軸 dBu、周波数の記載なし）: 0 dBu 約 0.0019 %、約 28 dBu で約 0.0005 %、約 29 dBu で急増、途中にレンジ切替の段差。Fig 6（10 V rms、1 kHz、80 kHz）: 10 kΩ 以上 約 0.00045 %、1 kΩ 約 0.0011 %、約 300 Ω 未満で急増 | 照合が正 | 行を 2 つ追加 |
| 8 | AMC3336 Figure 6-35（1 kHz・2 Vpp のスペクトル） | 高調波は約 −117〜−125 dBV | 400 dpi で画素を拾った: 基本波 約 −3 dBV、**2 次 約 −115 dBV、3 次 約 −109 dBV**、4 次 約 −120.5、5 次 約 −119.5、6 次 約 −125 dBV、約 17 kHz に約 −124 dBV の線、雑音床 約 −130〜−135 dBV | **どちらも不正確**（照合は 2 次・3 次を低く読んでいる。tap.md には行が無い） | 私の読みで行を追加 |
| 9 | INA1620 Figure 52 | 典型分布 | 一致・補足あり #5 と同じ | 照合が正 | 行を追加 |
| 10 | AD215 差動 16 MΩ・入力オペアンプ CMRR 100 dB | PDF p3 | 一致・補足あり #16 と同じ | 照合が正 | 行を追加 |
| 11 | ADuM3190 オペアンプの Common-Mode Rejection 72 dB | PDF p4 | PDF p4（印刷 p3）Table 1 の OP AMP 欄に Common-Mode Rejection 72 dB（Typ、条件なし） | 照合が正 | 行を追加 |
| 12 | HCPL-7800 Equivalent Input Impedance 500 kΩ・クリップ前 308 mV | p7 | p7 を画像で確認: RIN 500 kΩ（Typ）、\|VIN+\|MAX 308.0 mV（Typ、Figure 10） | 照合が正 | 行を追加 |
| 13 | ISOW1044 GPIO の PWD 3.5 / 10 ns | p15 | p15 の GPIO Channel に PWD 3.5（TYP）/ 10（MAX）ns | 照合が正 | 行を追加 |
| 14 | Si860x 非 I2C の PWD max 12 ns | p16 | 一致・補足あり #21 と同じ | 照合が正 | 行を追加 |
| 15 | ISO7741 の 50 Mbps（表）と 100 Mbps（注・Features・§8.2.3） | クロックを通すなら 49.152 Mbps で余裕 2 % 弱 | p7 §5.3 を画像で確認: DR の MAX 列 50 Mbps、注 (2) "100 Mbps is the maximum specified data rate, although higher data rates are possible."。改訂履歴（H→I→J→K）にデータレートの記載は無い | **tap.md が正**（食い違いは tap.md に原文どおり書いてある。クロック換算と余裕は設計の読みなので tap.md に入れない） | 反映せず |
| 16 | AMC1311B の IDD1（3.0〜3.6 V） | 6.0 / 8.4 mA が tap.md に無い | p11 に "3.0 V < VDD1 < 3.6 V, SHTDN = low, AMC1311B only 6.0 8.4 mA" | 照合が正 | 行を訂正 |
| 17 | HCPL-7800 雑音密度の単位の誤植 | "nV/s Hz" | 誤り #4 と同じページで確認 | 照合が正 | 追加行の引用に原文の印字のまま残した |

照合の「DS の中の食い違い」のうち AMC1300 Figure 7-26 の軸単位は、tap.md が既に原文どおりと明記しているので再照合の対象から外した。

## 4. tap.md に加えた変更の一覧

訂正（行の最後の欄に〔2026-09-25 照合で訂正〕）:
INA1620 Fig 14／INA1650 Fig 12・Fig 14・Fig 9／INA134 CMR vs 周波数／INA137 CMR vs 周波数・高調波／SSM2141 CMR vs 周波数・THD+N vs 周波数／SSM2143 5 Ω 不整合のページ／AD8274 Fig 15／AMC1311 IDD1／AMC3330・AMC3336 DC/DC の方式／AD215 絶縁側電源／HCPL-7800 THD・SNR／Si8920 高圧側電源／ADuM1400 CRW 伝搬遅延・PWD のページ／ISOW7741 ジッタ／tie／JT-11P-1 左右の図、および「探したが DS に無かった項目」の Q2・Q3・Q4・Q5 の該当箇条（箇条の末尾に同じ印）

表の形だけの修正（印なし。内容は変えていない）: 引用の中の `|` がエスケープされておらず列数が崩れていた既存の 4 行（INA1620 入力インピーダンス、AMC3330 動作同相入力、ISO7741 PWD、ISO7762 PWD）の `|` を `\|` にした。

追加（〔2026-09-25 照合で追加〕）:
INA1620 Fig 52／INA1650 Fig 53（本文）・Fig 54・Fig 56/57・本文の雑音の記述／SSM2143 Fig 4・Fig 6／AD8274 Fig 34／AMC3336 Fig 6-35／AD215 差動入力インピーダンス・入力オペアンプ CMRR／ADuM3190 オペアンプ CMR／HCPL-7800 入力インピーダンス・クリップ前入力・雑音密度／ISO7762 Fig 5-17／Si860x 非 I2C の PWD・ピーク・アイ・ジッタ／ISOW1044 GPIO の PWD

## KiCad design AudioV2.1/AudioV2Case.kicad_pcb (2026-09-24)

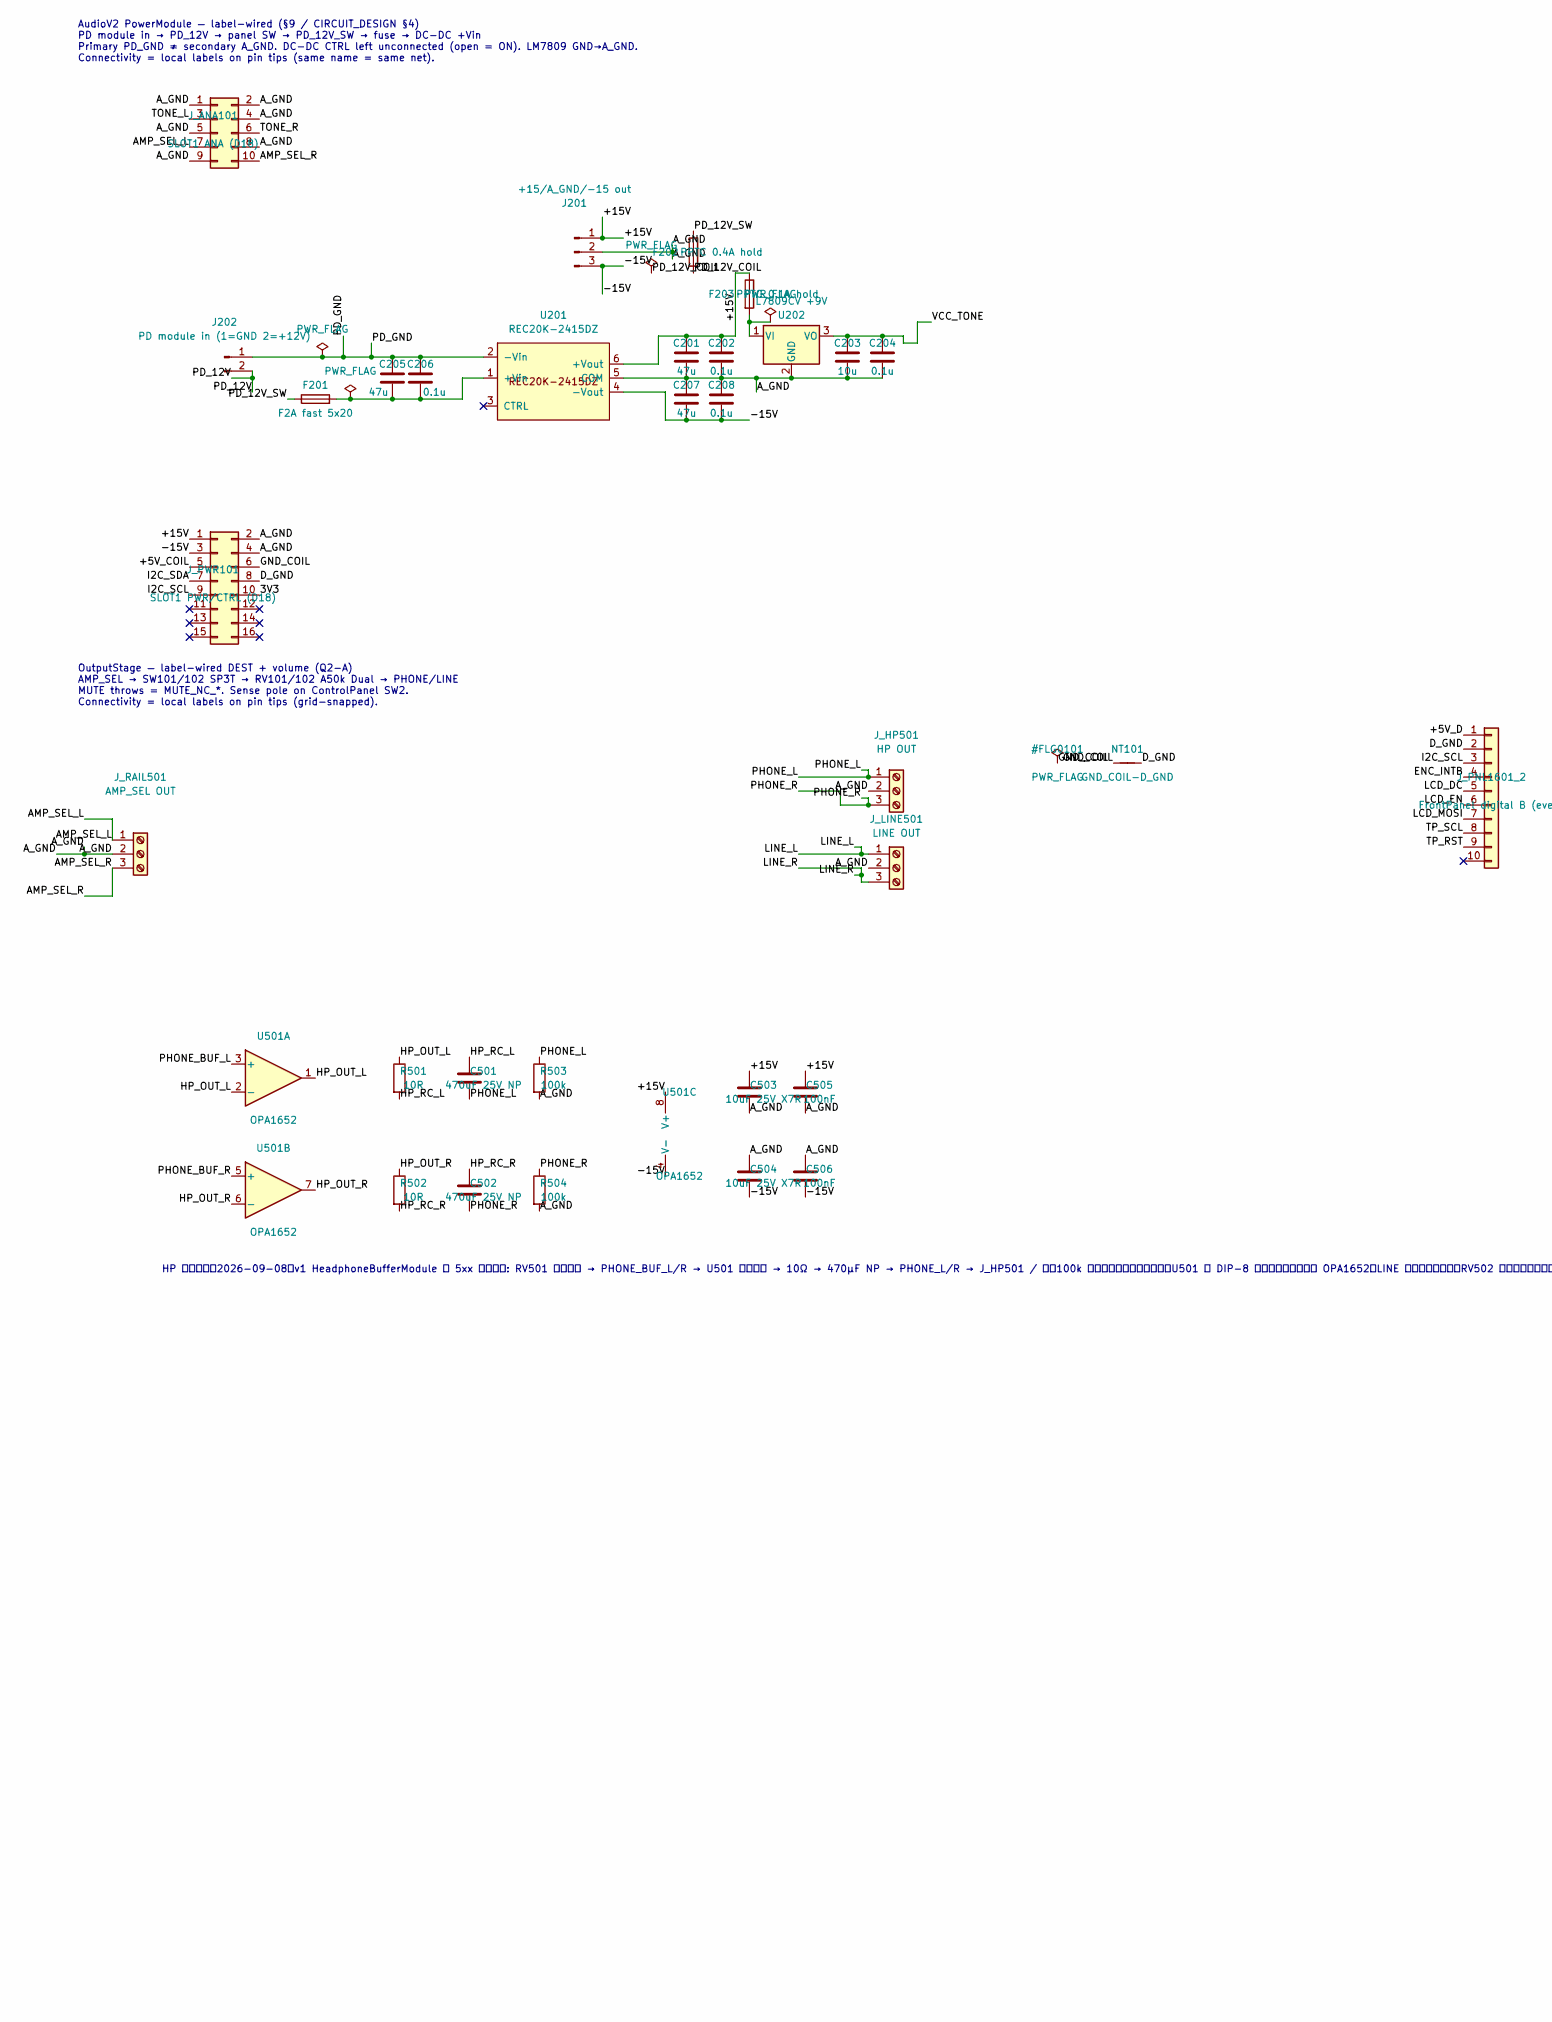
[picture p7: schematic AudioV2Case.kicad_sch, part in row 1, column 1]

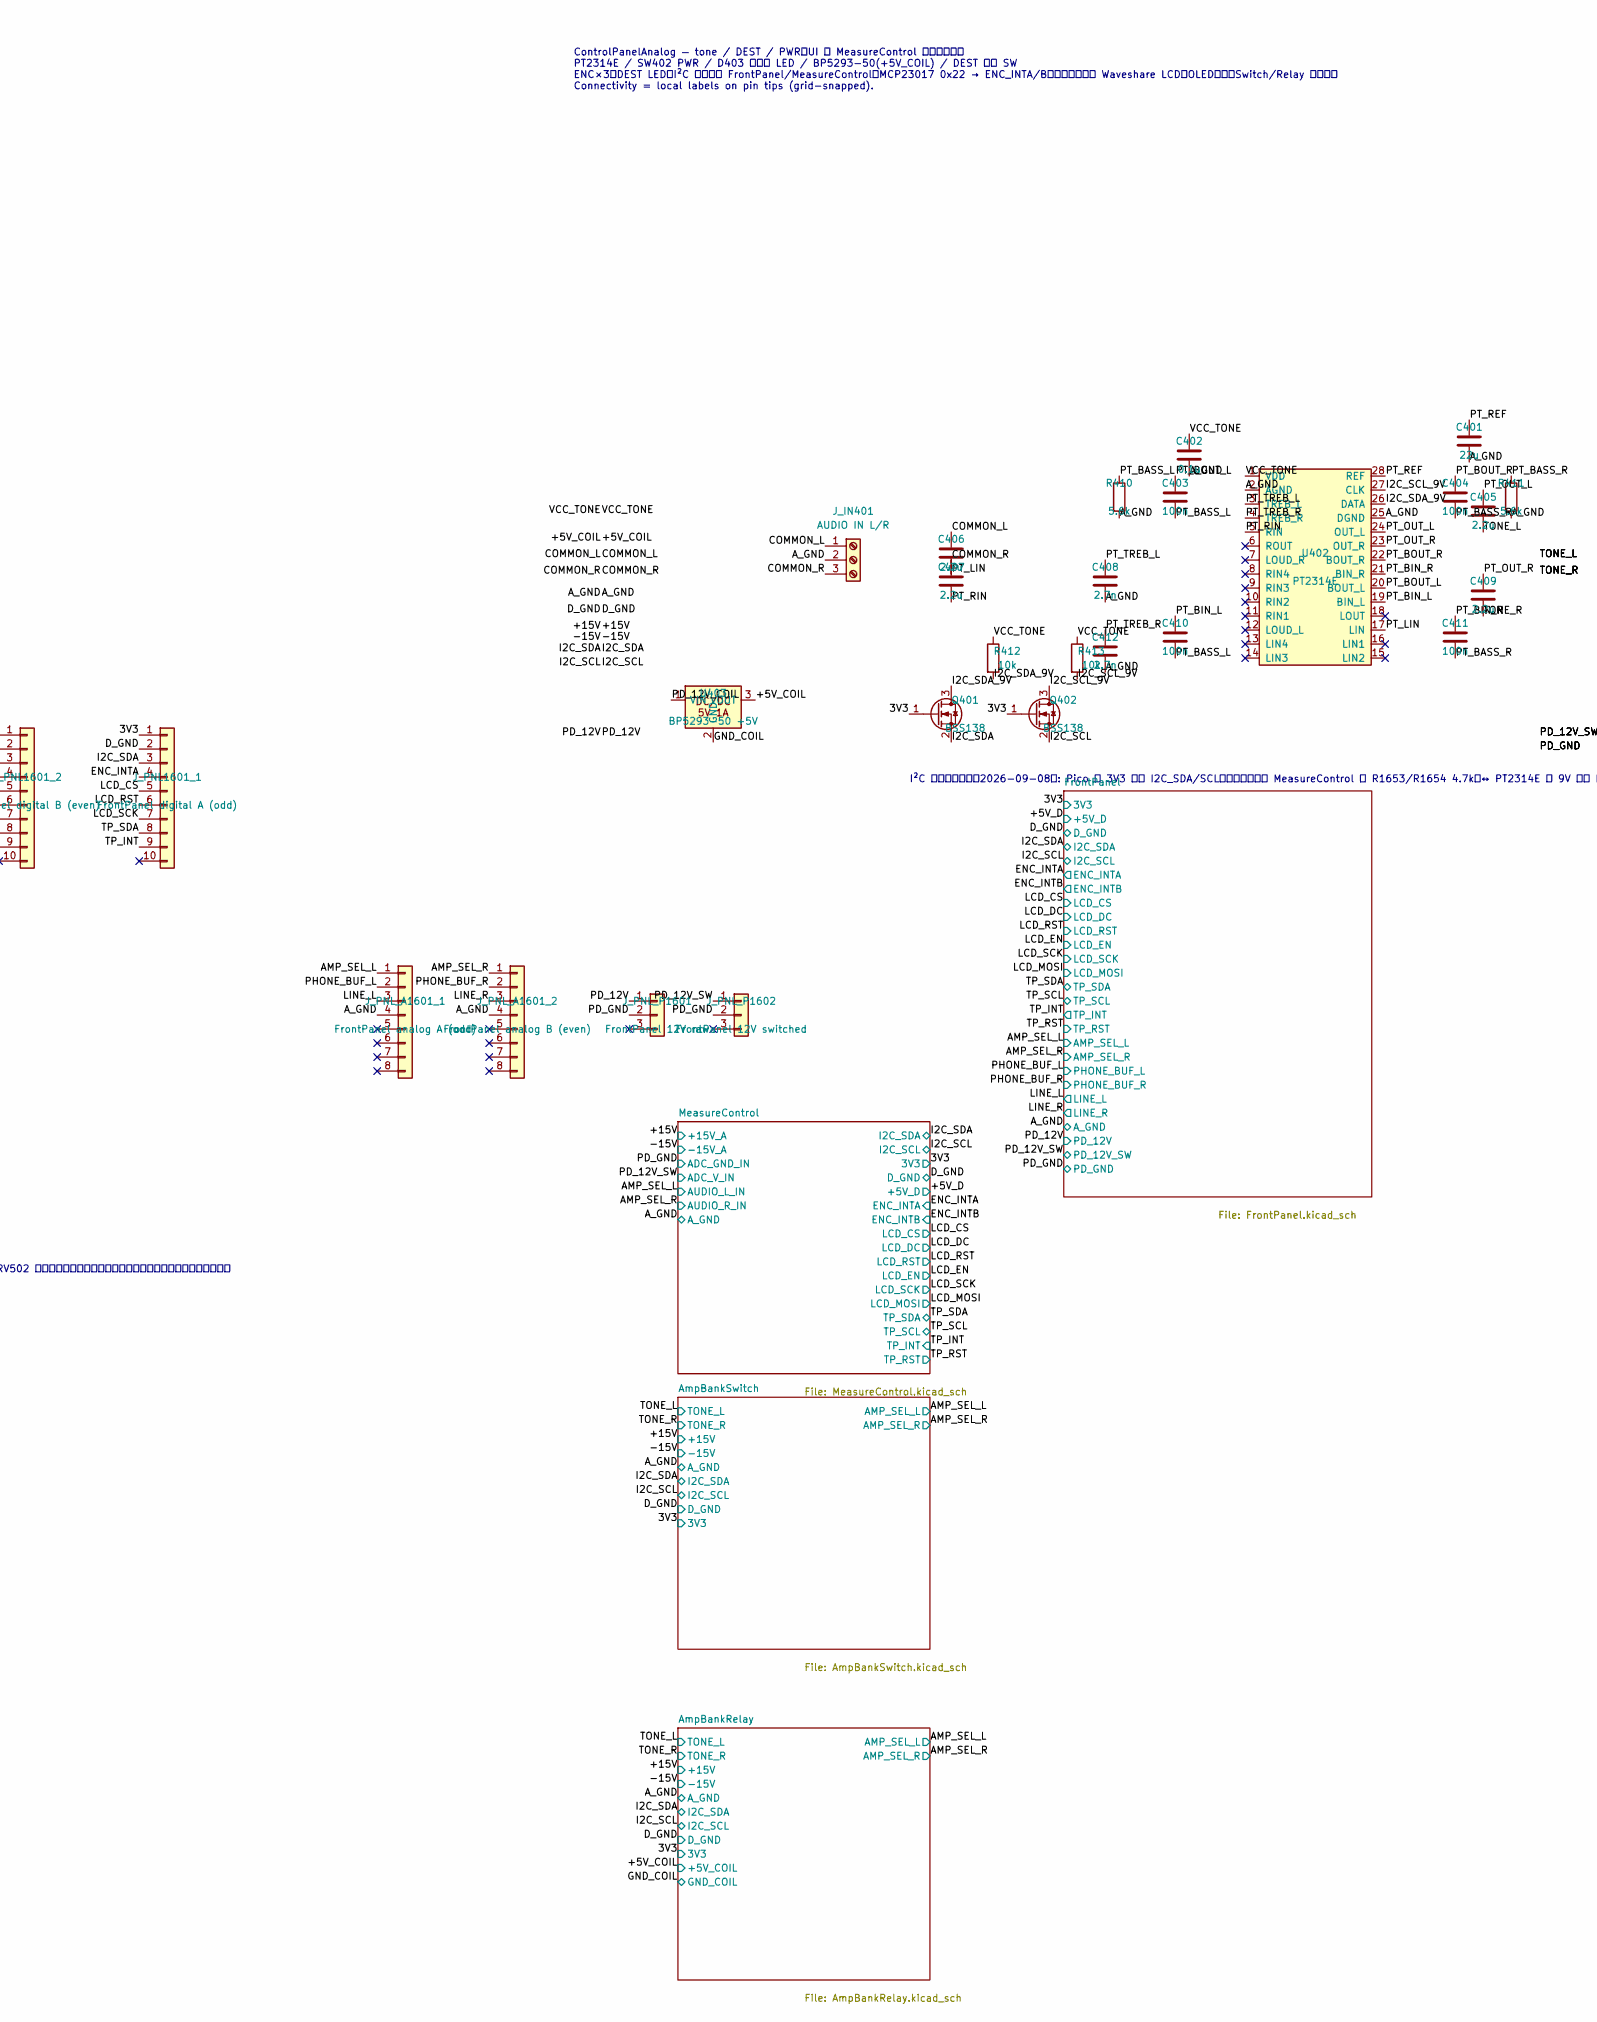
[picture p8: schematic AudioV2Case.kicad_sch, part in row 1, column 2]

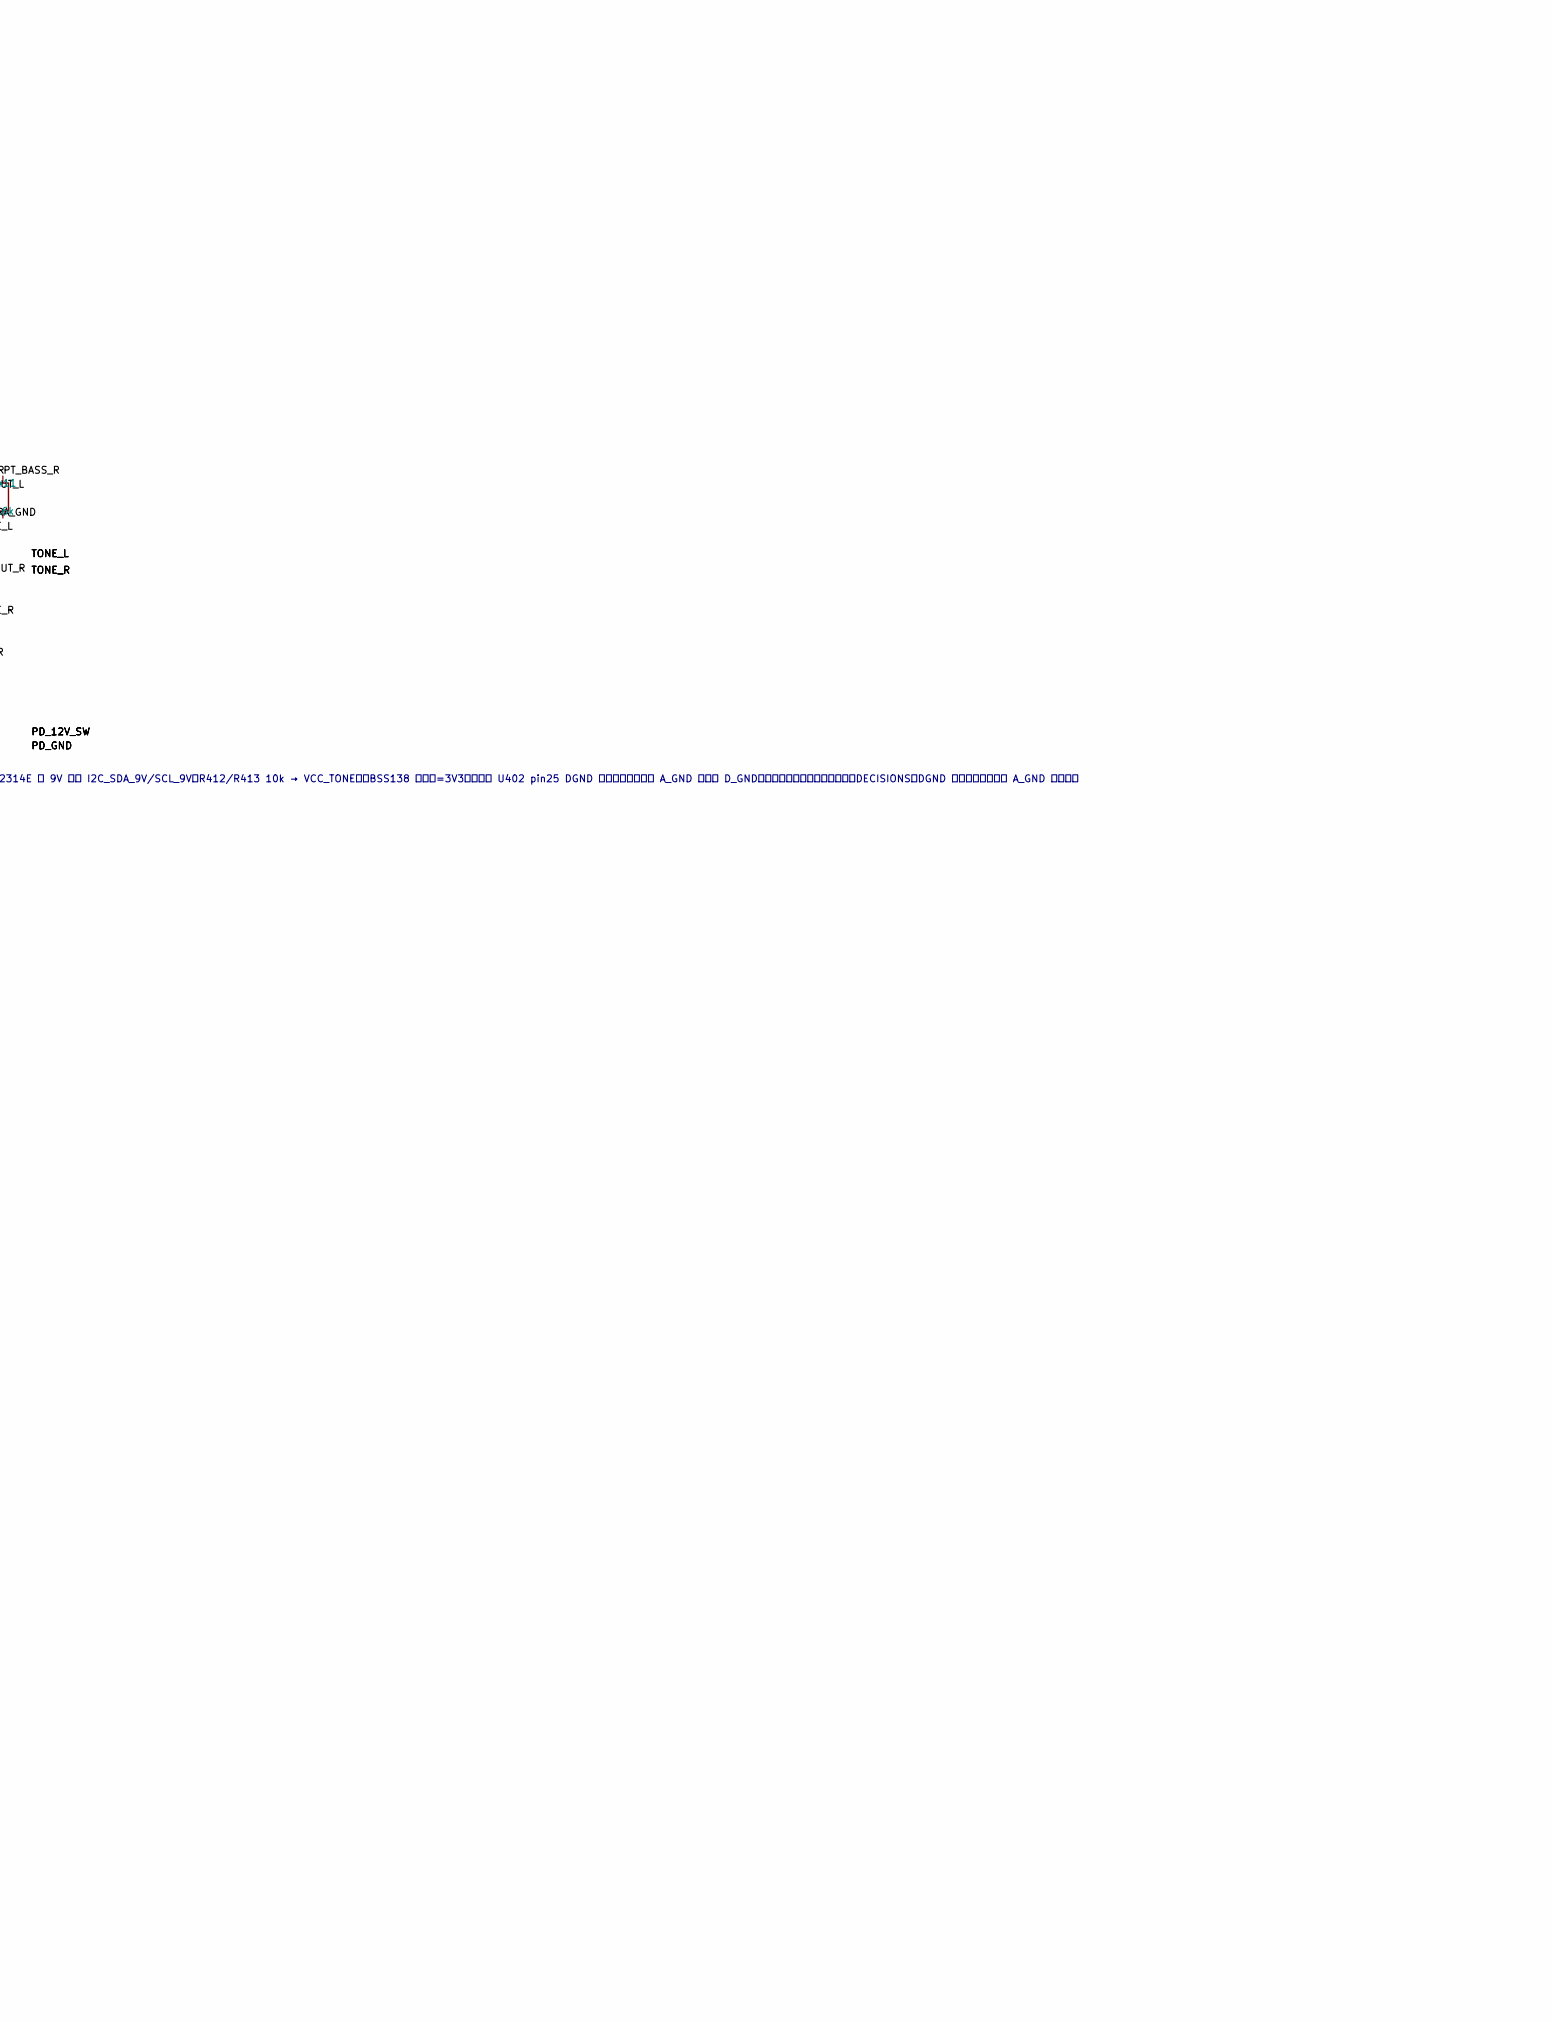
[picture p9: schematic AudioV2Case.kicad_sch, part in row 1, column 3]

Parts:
C201, C205, C207: 47u; CP_Radial_D8.0mm_P3.50mm
C202, C204, C206, C208, C402: 0.1u; C_1206_3216Metric_Pad1.33x1.80mm_HandSolder
C203: 10u; CP_Radial_D5.0mm_P2.00mm
C401: 22u; CP_Radial_D6.3mm_P2.50mm
C403, C404, C410, C411: 100n; C_1206_3216Metric_Pad1.33x1.80mm_HandSolder
C405, C406, C407, C409: 2.2u; C_Rect_L7.2mm_W2.5mm_P5.00mm_FKS2_FKP2_MKS2_MKP2
C408, C412: 2.7n; C_1206_3216Metric_Pad1.33x1.80mm_HandSolder
C501, C502: 470uF 25V NP; CP_Radial_D16.0mm_P7.50mm
C503, C504: 10uF 25V X7R; C_1206_3216Metric_Pad1.33x1.80mm_HandSolder
C505, C506: 100nF; C_1206_3216Metric_Pad1.33x1.80mm_HandSolder
F201: F2A fast 5x20; Fuseholder_Cylinder-5x20mm_Schurter_0031_8201_Horizontal_Op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
F202: PPTC 0.4A hold; PPTC_Radial_D7.9mm_T3.1mm_P5.08mm
F203: PPTC 0.1A hold; PPTC_Radial_D7.9mm_T3.1mm_P5.08mm
J201: +15/A_GND/-15 out; TerminalBlock_Phoenix_MKDS-1,5-3-5.08_1x03_P5.08mm_Horizont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
J202: PD module in (1=GND 2=+12V); TerminalBlock_Phoenix_MKDS-1,5-2-5.08_1x02_P5.08mm_Horizont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
J_ANA101: SLOT1 ANA (D18); PinSocket_2x05_P2.54mm_Vertical
J_HP501: HP OUT; JST_XH_B3B-XH-A_1x03_P2.50mm_Vertical
J_IN401: AUDIO IN L/R; TerminalBlock_Phoenix_MKDS-1,5-3-5.08_1x03_P5.08mm_Horizont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
J_LINE501: LINE OUT; JST_XH_B3B-XH-A_1x03_P2.50mm_Vertical
J_PNL1601_1: FrontPanel digital A (odd); JST_XH_B10B-XH-A_1x10_P2.50mm_Vertical
J_PNL1601_2: FrontPanel digital B (even); JST_XH_B10B-XH-A_1x10_P2.50mm_Vertical
J_PNL_A1601_1: FrontPanel analog A (odd); JST_XH_B8B-XH-A_1x08_P2.50mm_Vertical
J_PNL_A1601_2: FrontPanel analog B (even); JST_XH_B8B-XH-A_1x08_P2.50mm_Vertical
J_PNL_P1601: FrontPanel 12V raw; JST_XH_B3B-XH-A_1x03_P2.50mm_Vertical
J_PNL_P1602: FrontPanel 12V switched; JST_XH_B3B-XH-A_1x03_P2.50mm_Vertical
J_PWR101: SLOT1 PWR/CTRL (D18); PinSocket_2x08_P2.54mm_Vertical
J_RAIL501: AMP_SEL OUT; TerminalBlock_Phoenix_MKDS-1,5-3-5.08_1x03_P5.08mm_Horizont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
NT101: GND_COIL-D_GND; NetTie-2_SMD_Pad2.0mm
Q401, Q402: BSS138; SOT-23
R410, R411: 5.6k; R_1206_3216Metric_Pad1.30x1.75mm_HandSolder
R412, R413: 10k; R_1206_3216Metric_Pad1.30x1.75mm_HandSolder
R501, R502: 10R; R_1206_3216Metric_Pad1.30x1.75mm_HandSolder
R503, R504: 100k; R_1206_3216Metric_Pad1.30x1.75mm_HandSolder
U201: REC20K-2415DZ; REC20K-Z_1in_THT; MPN REC20K-2415DZ
U202: L7809CV +9V; TO-220-3_Vertical
U402: PT2314E; SOIC-28W_7.5x17.9mm_P1.27mm
U403: BP5293-50 +5V; BP5293-50_ROHM_SIP-3
U501: OPA1652; DIP-8_W7.62mm_Socket

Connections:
/3V3: J_PNL1601_1.1, J_PWR101.10, Q401.1 (G), Q402.1 (G); also elsewhere on the board
/+5V_COIL: J_PWR101.5, U403.3 (VOUT); also elsewhere on the board
/+5V_D: J_PNL1601_2.1; also elsewhere on the board
/+15V: C201.1, C202.1, C503.1, C505.1, F203.1, J201.1, J_PWR101.1, U201.6 (+Vout), U501.8 (V+); also elsewhere on the board
/-15V: C207.2, C208.2, C504.2, C506.2, J201.3, J_PWR101.3, U201.4 (-Vout), U501.4 (V-); also elsewhere on the board
/AMP_SEL_L: J_ANA101.7, J_PNL_A1601_1.1, J_RAIL501.1; also elsewhere on the board
/AMP_SEL_R: J_ANA101.10, J_PNL_A1601_2.1, J_RAIL501.3; also elsewhere on the board
/A_GND: C201.2, C202.2, C203.2, C204.2, C207.1, C208.1, C401.2, C402.2, C408.2, C412.2, C503.2, C504.1, C505.2, C506.1, J201.2, J_ANA101.1, J_ANA101.2, J_ANA101.4, J_ANA101.5, J_ANA101.8, J_ANA101.9, J_HP501.2, J_IN401.2, J_LINE501.2, J_PNL_A1601_1.4, J_PNL_A1601_2.4, J_PWR101.2, J_PWR101.4, J_RAIL501.2, R410.2, R411.2, R503.2, R504.2, U201.5 (COM), U202.2 (GND), U402.2 (AGND), U402.25 (DGND); also elsewhere on the board
/COMMON_L: C406.1, J_IN401.1
/COMMON_R: C407.1, J_IN401.3
/D_GND: J_PNL1601_1.2, J_PNL1601_2.2, J_PWR101.8, NT101.2; also elsewhere on the board
/ENC_INTA: J_PNL1601_1.4; also elsewhere on the board
/ENC_INTB: J_PNL1601_2.4; also elsewhere on the board
/GND_COIL: J_PWR101.6, NT101.1, U403.2 (GND); also elsewhere on the board
/HP_OUT_L: R501.1, U501.1, U501.2 (-)
/HP_OUT_R: R502.1, U501.6 (-), U501.7
/HP_RC_L: C501.1, R501.2
/HP_RC_R: C502.1, R502.2
/I2C_SCL: J_PNL1601_2.3, J_PWR101.9, Q402.2 (S); also elsewhere on the board
/I2C_SCL_9V: Q402.3 (D), R413.2, U402.27 (CLK)
/I2C_SDA: J_PNL1601_1.3, J_PWR101.7, Q401.2 (S); also elsewhere on the board
/I2C_SDA_9V: Q401.3 (D), R412.2, U402.26 (DATA)
/LCD_CS: J_PNL1601_1.5; also elsewhere on the board
/LCD_DC: J_PNL1601_2.5; also elsewhere on the board
/LCD_EN: J_PNL1601_2.6; also elsewhere on the board
/LCD_MOSI: J_PNL1601_2.7; also elsewhere on the board
/LCD_RST: J_PNL1601_1.6; also elsewhere on the board
/LCD_SCK: J_PNL1601_1.7; also elsewhere on the board
/LINE_L: J_LINE501.1, J_PNL_A1601_1.3; also elsewhere on the board
/LINE_R: J_LINE501.3, J_PNL_A1601_2.3; also elsewhere on the board
/PD_12V: J202.2, J_PNL_P1601.1; also elsewhere on the board
/PD_12V_COIL: F202.2, U403.1 (VIN)
/PD_12V_SW: F201.1, F202.1, J_PNL_P1602.1; also elsewhere on the board
/PD_GND: C205.1, C206.1, J202.1, J_PNL_P1601.2, J_PNL_P1602.2, U201.2 (-Vin); also elsewhere on the board
/PHONE_BUF_L: J_PNL_A1601_1.2, U501.3 (+); also elsewhere on the board
/PHONE_BUF_R: J_PNL_A1601_2.2, U501.5 (+); also elsewhere on the board
/PHONE_L: C501.2, J_HP501.1, R503.1
/PHONE_R: C502.2, J_HP501.3, R504.1
/PT_BASS_L: C403.2, C410.2, R410.1
/PT_BASS_R: C404.2, C411.2, R411.1
/PT_BIN_L: C410.1, U402.19 (BIN_L)
/PT_BIN_R: C411.1, U402.21 (BIN_R)
/PT_BOUT_L: C403.1, U402.20 (BOUT_L)
/PT_BOUT_R: C404.1, U402.22 (BOUT_R)
/PT_LIN: C406.2, U402.17 (LIN)
/PT_OUT_L: C405.1, U402.24 (OUT_L)
/PT_OUT_R: C409.1, U402.23 (OUT_R)
/PT_REF: C401.1, U402.28 (REF)
/PT_RIN: C407.2, U402.5 (RIN)
/PT_TREB_L: C408.1, U402.3 (TREB_L)
/PT_TREB_R: C412.1, U402.4 (TREB_R)
/TONE_L: C405.2, J_ANA101.3; also elsewhere on the board
/TONE_R: C409.2, J_ANA101.6; also elsewhere on the board
/TP_INT: J_PNL1601_1.9; also elsewhere on the board
/TP_RST: J_PNL1601_2.9; also elsewhere on the board
/TP_SCL: J_PNL1601_2.8; also elsewhere on the board
/TP_SDA: J_PNL1601_1.8; also elsewhere on the board
/VCC_TONE: C203.1, C204.1, C402.1, R412.1, R413.1, U202.3 (VO), U402.1 (VDD)
unnamed: C205.2, C206.2, F201.2, U201.1 (+Vin)
unnamed: F203.2, U202.1 (VI)

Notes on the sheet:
HP バッファ（2026-09-08、v1 HeadphoneBufferModule を 5xx で移設）: RV501 ワイパー → PHONE_BUF_L/R → U501 ユニティ → 10Ω → 470µF NP → PHONE_L/R → J_HP501 / 親。100k はジャック側のブリード。U501 は DIP-8 ソケット、標準実装 OPA1652。LINE はバッファ無し（RV502 直出し）のまま。配線はピン先ラベル（このシートの流儀）。
AudioV2 PowerModule — label-wired (§9 / CIRCUIT_DESIGN §4) PD module in → PD_12V → panel SW → PD_12V_SW → fuse → DC-DC +Vin Primary PD_GND ≠ secondary A_GND. DC-DC CTRL left unconnected (open = ON). LM7809 GND→A_GND. Connectivity = local labels on pin tips (same name = same net).
ControlPanelAnalog — tone / DEST / PWR（UI は MeasureControl へ移設済み） PT2314E / SW402 PWR / D403 パネル LED / BP5293-50(+5V_COIL) / DEST 機械 SW ENC×3・DEST LED・I²C マスタは FrontPanel/MeasureControl（MCP23017 0x22 → ENC_INTA/B）。状態表示は Waveshare LCD（OLED廃止・Switch/Relay 共通）。 Connectivity = local labels on pin tips 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
I²C レベルシフタ（2026-09-08）: Pico 側 3V3 バス I2C_SDA/SCL（プルアップは MeasureControl の R1653/R1654 4.7k）↔ PT2314E 側 9V バス I2C_SDA_9V/SCL_9V（R412/R413 10k → VCC_TONE）。BSS138 ゲート=3V3。同時に U402 pin25 DGND をチップの足元で A_GND へ（旧 D_GND）。片方だけでは成立しない（DECISIONS「DGND はチップの足元で A_GND へ」）。
OutputStage — label-wired DEST + volume (Q2-A) AMP_SEL → SW101/102 SP3T → RV101/102 A50k Dual → PHONE/LINE MUTE throws = MUTE_NC_*. Sense pole on ControlPanel SW2. Connectivity = local labels on pin tips (grid-snapped).

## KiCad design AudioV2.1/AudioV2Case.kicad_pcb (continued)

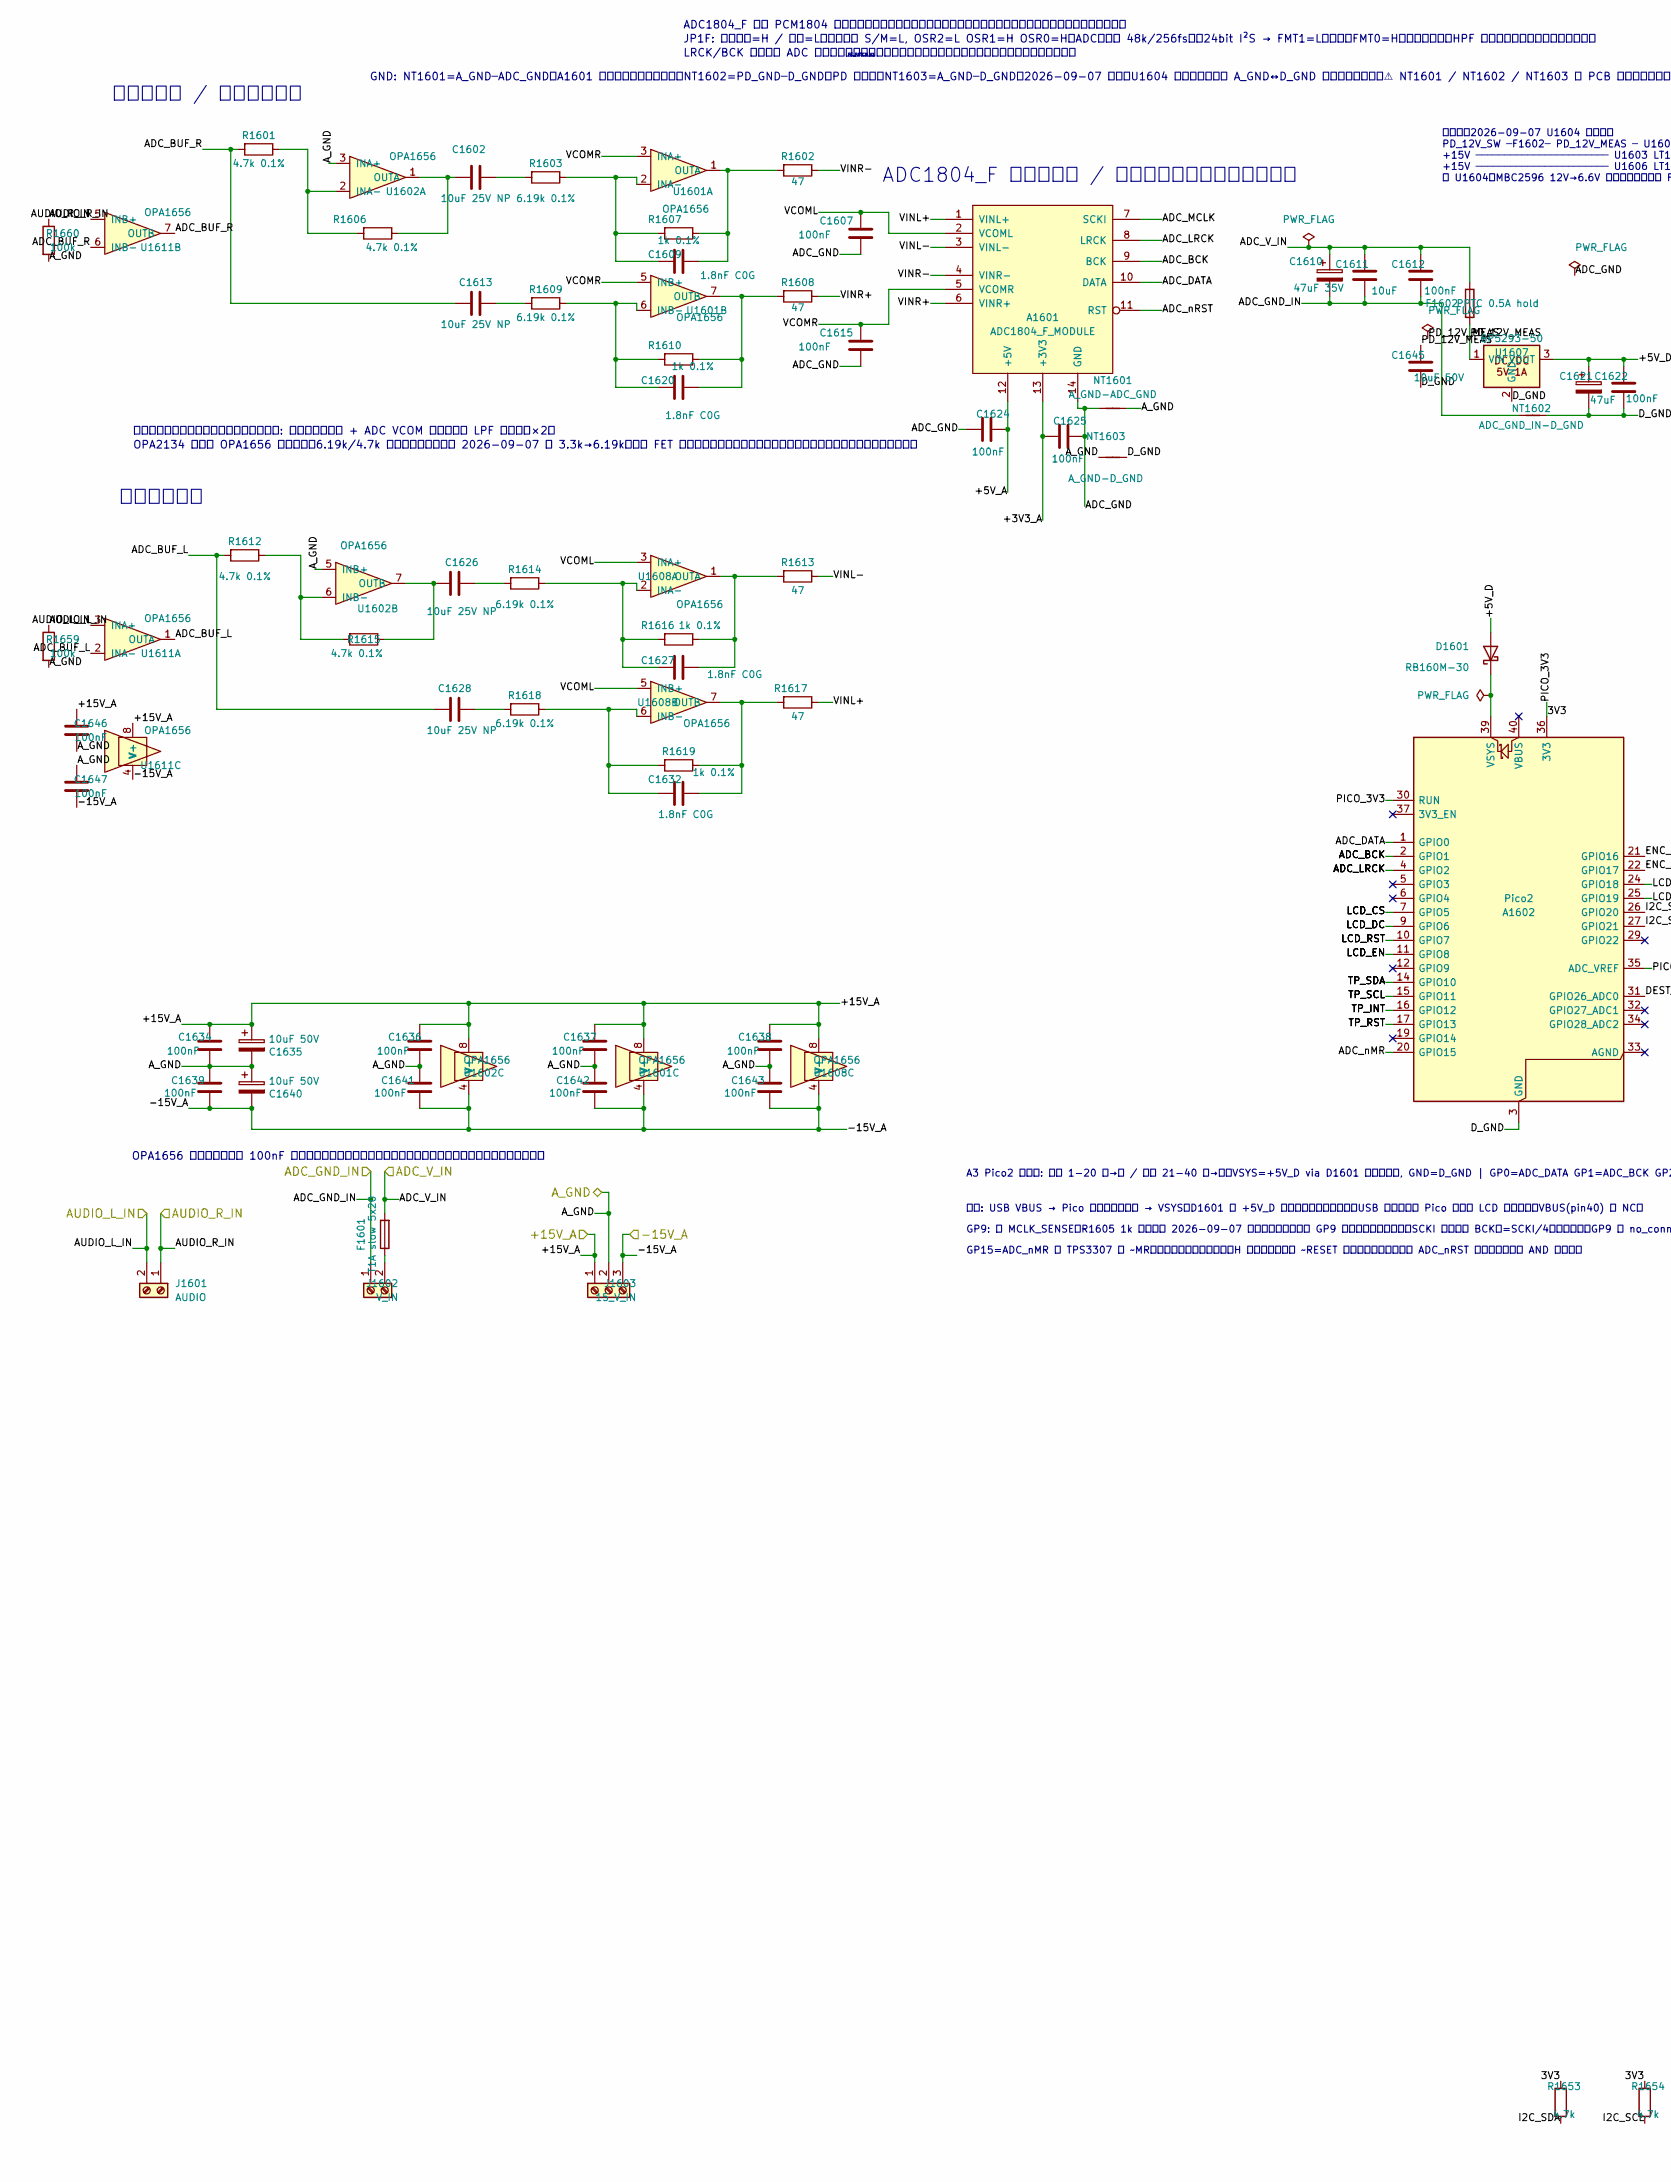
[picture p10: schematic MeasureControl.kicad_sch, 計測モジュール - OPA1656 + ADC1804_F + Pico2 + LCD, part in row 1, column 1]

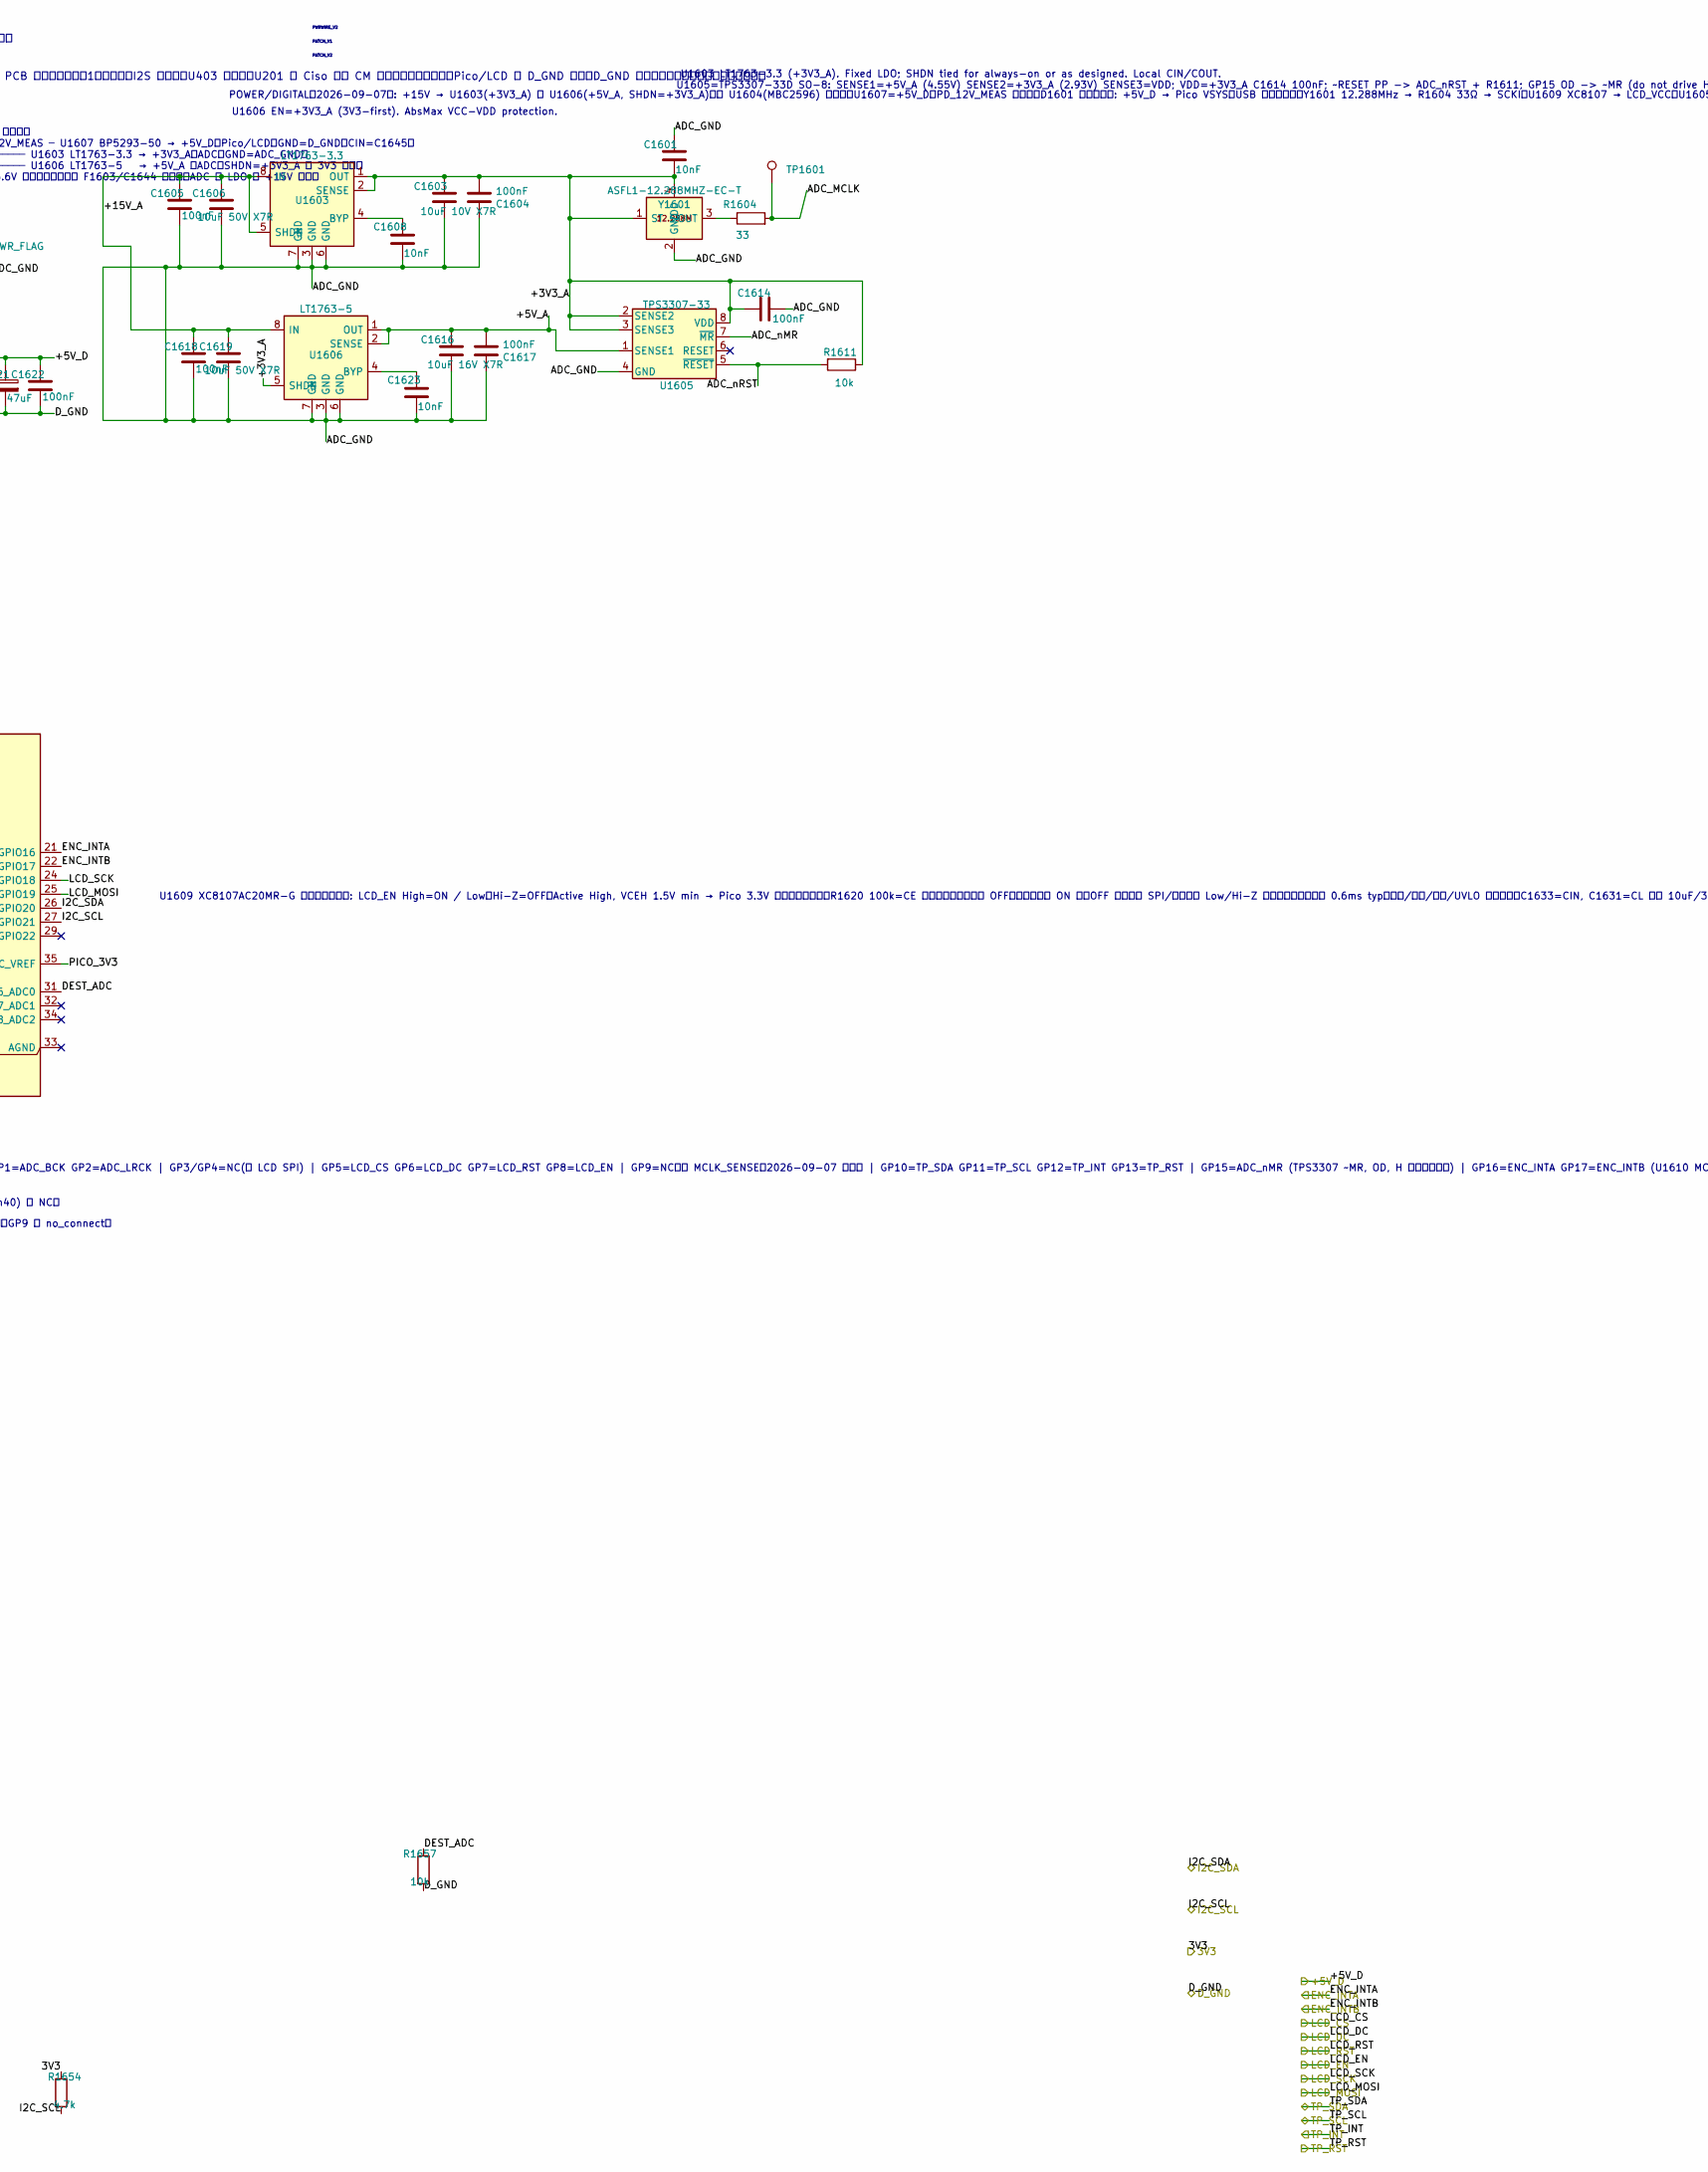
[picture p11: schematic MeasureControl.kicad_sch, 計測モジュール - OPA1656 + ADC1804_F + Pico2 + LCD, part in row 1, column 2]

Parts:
A1601: ADC1804_F_MODULE; ADC1804_F_KYOHRITSU_56x33mm
A1602: Pico2; RaspberryPi_Pico_Common_THT
C1601, C1608, C1623: 10nF; C_1206_3216Metric_Pad1.33x1.80mm_HandSolder
C1602, C1613, C1626, C1628: 10uF 25V NP; C_Radial_D5.0mm_H7.0mm_P2.00mm
C1603: 10uF 10V X7R; C_1206_3216Metric_Pad1.33x1.80mm_HandSolder
C1604, C1605, C1607, C1612, C1614, C1615, C1617, C1618, C1622, C1624, C1625, C1634, C1636, C1637, C1638, C1639, C1641, C1642, C1643, C1646, C1647: 100nF; C_1206_3216Metric_Pad1.33x1.80mm_HandSolder
C1606, C1619: 10uF 50V X7R; C_1210_3225Metric_Pad1.33x2.70mm_HandSolder
C1609, C1620, C1627, C1632: 1.8nF C0G; C_1206_3216Metric_Pad1.33x1.80mm_HandSolder
C1610: 47uF 35V; CP_Radial_D8.0mm_P3.50mm
C1611: 10uF; C_1206_3216Metric_Pad1.33x1.80mm_HandSolder
C1616: 10uF 16V X7R; C_1206_3216Metric_Pad1.33x1.80mm_HandSolder
C1621: 47uF; CP_Radial_D8.0mm_P3.50mm
C1635, C1640: 10uF 50V; CP_Radial_D5.0mm_P2.00mm
C1645: 10uF 50V; C_1206_3216Metric_Pad1.33x1.80mm_HandSolder
D1601: RB160M-30; D_SOD-123
F1601: T1A slow 5x20; Fuseholder_Cylinder-5x20mm_Schurter_0031_8201_Horizontal_Op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
F1602: PPTC 0.5A hold; PPTC_Radial_D7.9mm_T3.1mm_P5.08mm
J1601: AUDIO; TerminalBlock_Phoenix_MKDS-1,5-2-5.08_1x02_P5.08mm_Horizont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
J1602: V_IN; TerminalBlock_Phoenix_MKDS-1,5-2-5.08_1x02_P5.08mm_Horizont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
J1603: 15_V_IN; TerminalBlock_Phoenix_MKDS-1,5-3-5.08_1x03_P5.08mm_Horizont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
NT1601: A_GND-ADC_GND; NetTie-2_SMD_Pad2.0mm
NT1602: ADC_GND_IN-D_GND; NetTie-2_SMD_Pad2.0mm
NT1603: A_GND-D_GND; NetTie-2_SMD_Pad0.5mm
R1601, R1606, R1612, R1615: 4.7k 0.1%; R_1206_3216Metric_Pad1.30x1.75mm_HandSolder
R1602, R1608, R1613, R1617: 47; R_1206_3216Metric_Pad1.30x1.75mm_HandSolder
R1603, R1609, R1614, R1618: 6.19k 0.1%; R_1206_3216Metric_Pad1.30x1.75mm_HandSolder
R1604: 33; R_1206_3216Metric_Pad1.30x1.75mm_HandSolder
R1607, R1610, R1616, R1619: 1k 0.1%; R_1206_3216Metric_Pad1.30x1.75mm_HandSolder
R1611, R1657: 10k; R_1206_3216Metric_Pad1.30x1.75mm_HandSolder
R1653, R1654: 4.7k; R_1206_3216Metric_Pad1.30x1.75mm_HandSolder
R1659, R1660: 100k; R_1206_3216Metric_Pad1.30x1.75mm_HandSolder
TP1601: ADC_MCLK; TestPoint_Pad_D1.5mm
U1601, U1602, U1608, U1611: OPA1656; SOIC-8_3.9x4.9mm_P1.27mm
U1603: LT1763-3.3; SOIC-8_3.9x4.9mm_P1.27mm
U1605: TPS3307-33; SOIC-8_3.9x4.9mm_P1.27mm
U1606: LT1763-5; SOIC-8_3.9x4.9mm_P1.27mm
U1607: BP5293-50; BP5293-50_ROHM_SIP-3
Y1601: ASFL1-12.288MHZ-EC-T; Oscillator_SMD_Abracon_ASFL-4Pin_5.0x3.2mm_HandSoldering

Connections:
/3V3: A1602.30 (RUN), A1602.35 (ADC_VREF), A1602.36 (3V3), R1653.1, R1654.1; also elsewhere on the board
/+5V_D: C1621.1, C1622.1, D1601.2 (A), U1607.3 (VOUT); also elsewhere on the board
/+15V: C1605.1, C1606.1, C1618.1, C1619.1, C1634.1, C1635.1, C1636.1, C1637.1, C1638.1, C1646.1, J1603.1, U1601.8 (V+), U1602.8 (V+), U1603.5 (SHDN), U1603.8 (IN), U1606.8 (IN), U1608.8 (V+), U1611.8 (V+); also elsewhere on the board
/-15V: C1639.2, C1640.2, C1641.2, C1642.2, C1643.2, C1647.2, J1603.3, U1601.4 (V-), U1602.4 (V-), U1608.4 (V-), U1611.4 (V-); also elsewhere on the board
/AMP_SEL_L: J1601.2, R1659.1, U1611.3 (INA+); also elsewhere on the board
/AMP_SEL_R: J1601.1, R1660.1, U1611.5 (INB+); also elsewhere on the board
/A_GND: C1634.2, C1635.2, C1636.2, C1637.2, C1638.2, C1639.1, C1640.1, C1641.1, C1642.1, C1643.1, C1646.2, C1647.1, J1603.2, NT1601.2, NT1603.1, R1659.2, R1660.2, U1602.3 (INA+), U1602.5 (INB+); also elsewhere on the board
/D_GND: A1602.3 (GND), A1602.8 (GND), A1602.13 (GND), A1602.18 (GND), A1602.23 (GND), A1602.28 (GND), A1602.38 (GND), C1621.2, C1622.2, C1645.2, NT1602.2, NT1603.2, R1657.2, U1607.2 (GND); also elsewhere on the board
/ENC_INTA: A1602.21 (GPIO16); also elsewhere on the board
/ENC_INTB: A1602.22 (GPIO17); also elsewhere on the board
/I2C_SCL: A1602.27 (GPIO21), R1654.2; also elsewhere on the board
/I2C_SDA: A1602.26 (GPIO20), R1653.2; also elsewhere on the board
/LCD_CS: A1602.7 (GPIO5); also elsewhere on the board
/LCD_DC: A1602.9 (GPIO6); also elsewhere on the board
/LCD_EN: A1602.11 (GPIO8); also elsewhere on the board
/LCD_MOSI: A1602.25 (GPIO19); also elsewhere on the board
/LCD_RST: A1602.10 (GPIO7); also elsewhere on the board
/LCD_SCK: A1602.24 (GPIO18); also elsewhere on the board
/MeasureControl/+3V3_A: A1601.13 (+3V3), C1601.2, C1603.1, C1604.1, C1614.1, C1625.2, R1611.1, U1603.1 (OUT), U1603.2 (SENSE), U1605.2 (SENSE2), U1605.3 (SENSE3), U1605.8 (VDD), U1606.5 (SHDN), Y1601.1 (ST), Y1601.4 (VDD)
/MeasureControl/+5V_A: A1601.12 (+5V), C1616.1, C1617.1, C1624.1, U1605.1 (SENSE1), U1606.1 (OUT), U1606.2 (SENSE)
/MeasureControl/ADC_BCK: A1601.9 (BCK), A1602.2 (GPIO1)
/MeasureControl/ADC_BUF_L: C1628.2, R1612.2, U1611.1 (OUTA), U1611.2 (INA-)
/MeasureControl/ADC_BUF_R: C1613.2, R1601.2, U1611.6 (INB-), U1611.7 (OUTB)
/MeasureControl/ADC_DATA: A1601.10 (DATA), A1602.1 (GPIO0)
/MeasureControl/ADC_GND: A1601.14 (GND), C1601.1, C1603.2, C1604.2, C1605.2, C1606.2, C1607.1, C1608.2, C1614.2, C1615.1, C1616.2, C1617.2, C1618.2, C1619.2, C1623.2, C1624.2, C1625.1, NT1601.1, U1603.3 (GND), U1603.6 (GND), U1603.7 (GND), U1605.4 (GND), U1606.3 (GND), U1606.6 (GND), U1606.7 (GND), Y1601.2 (GND)
/MeasureControl/ADC_LRCK: A1601.8 (LRCK), A1602.4 (GPIO2)
/MeasureControl/ADC_MCLK: A1601.7 (SCKI), R1604.2, TP1601.1 (1_1)
/MeasureControl/ADC_nMR: A1602.20 (GPIO15), U1605.7 (~MR)
/MeasureControl/ADC_nRST: A1601.11 (RST), R1611.2, U1605.5 (~RESET)
/MeasureControl/DEST_ADC: A1602.31 (GPIO26_ADC0), R1657.1
/MeasureControl/PD_12V_MEAS: C1645.1, F1602.2, U1607.1 (VIN)
/MeasureControl/VCOML: A1601.2 (VCOML), C1607.2, U1608.3 (INA+), U1608.5 (INB+)
/MeasureControl/VCOMR: A1601.5 (VCOMR), C1615.2, U1601.3 (INA+), U1601.5 (INB+)
/MeasureControl/VINL+: A1601.1 (VINL+), R1617.1
/MeasureControl/VINL-: A1601.3 (VINL-), R1613.1
/MeasureControl/VINR+: A1601.6 (VINR+), R1608.1
/MeasureControl/VINR-: A1601.4 (VINR-), R1602.1
/PD_12V_SW: C1610.1, C1611.1, C1612.1, F1601.2, F1602.1; also elsewhere on the board
/PD_GND: C1610.2, C1611.2, C1612.2, J1602.1, NT1602.1; also elsewhere on the board
/TP_INT: A1602.16 (GPIO12); also elsewhere on the board
/TP_RST: A1602.17 (GPIO13); also elsewhere on the board
/TP_SCL: A1602.15 (GPIO11); also elsewhere on the board
/TP_SDA: A1602.14 (GPIO10); also elsewhere on the board
unnamed: A1602.39 (VSYS), D1601.1 (K)
unnamed: C1602.1, R1603.2
unnamed: C1613.1, R1609.2
unnamed: C1626.1, R1614.2
unnamed: C1628.1, R1618.2
unnamed: F1601.1, J1602.2
unnamed: C1609.2, R1603.1, R1607.2, U1601.2 (INA-)
unnamed: C1609.1, R1602.2, R1607.1, U1601.1 (OUTA)
unnamed: C1620.2, R1609.1, R1610.2, U1601.6 (INB-)
unnamed: C1620.1, R1608.2, R1610.1, U1601.7 (OUTB)
unnamed: R1601.1, R1606.2, U1602.2 (INA-)
unnamed: C1602.2, R1606.1, U1602.1 (OUTA)
unnamed: R1612.1, R1615.2, U1602.6 (INB-)
unnamed: C1626.2, R1615.1, U1602.7 (OUTB)
unnamed: C1608.1, U1603.4 (BYP)
unnamed: C1623.1, U1606.4 (BYP)
unnamed: C1627.2, R1614.1, R1616.2, U1608.2 (INA-)
unnamed: C1627.1, R1613.2, R1616.1, U1608.1 (OUTA)
unnamed: C1632.2, R1618.1, R1619.2, U1608.6 (INB-)
unnamed: C1632.1, R1617.2, R1619.1, U1608.7 (OUTB)
unnamed: R1604.1, Y1601.3 (OUT)

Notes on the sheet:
ADC1804_F には PCM1804 のデカップリングとジャンパが内蔵済み。本シートは外部コネクタのみをモデル化。
ADC1804_F モジュール / デジタル・インターフェース
PWRWIRE_V2
電源系（2026-09-07 U1604 削除後） PD_12V_SW ─F1602─ PD_12V_MEAS ─ U1607 BP5293-50 → +5V_D（Pico/LCD。GND=D_GND、CIN=C1645） +15V ─────────────────────── U1603 LT1763-3.3 → +3V3_A（ADC。GND=ADC_GND） +15V ─────────────────────── U1606 LT1763-5 → +5V_A （ADC。SHDN=+3V3_A で 3V3 先行） 旧 U1604（MBC2596 12V→6.6V 非絶縁バック）と F1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
POWER/DIGITAL（2026-09-07）: +15V → U1603(+3V3_A) と U1606(+5V_A, SHDN=+3V3_A)。旧 U1604(MBC2596) は削除。U1607=+5V_D（PD_12V_MEAS から）。D1601 ショットキ: +5V_D → Pico VSYS（USB 逆流止め）。Y1601 12.288MHz → R1604 33Ω → SCKI。U1609 XC8107 → LCD_VCC。U1605 TPS3307 監視。
GP9: 旧 MCLK_SENSE（R1605 1k 経由）は 2026-09-07 に削除。ファームは GP9 を読んでいなかった。SCKI の生死は BCK（=SCKI/4）で分かる。GP9 は no_connect。
A3 Pico2 横置き: 南列 1-20 西→東 / 北列 21-40 東→西。VSYS=+5V_D via D1601 ショットキ, GND=D_GND | GP0=ADC_DATA GP1=ADC_BCK GP2=ADC_LRCK | GP3/GP4=NC(旧 LCD SPI) | GP5=LCD_CS GP6=LCD_DC GP7=LCD_RST GP8=LCD_EN | GP9=NC（旧 MCLK_SENSE、2026-09-07 削除） | GP10=TP_SDA GP11=TP_SCL GP12=TP_INT GP13=TP_RST | GP15=ADC_nMR (TPS330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
LRCK/BCK の向きは ADC マスタモード想定。スレーブ時は階層ピンの方向を合わせて変更すること。
OPA1656 の各電源ペアに 100nF を配置。バルクコンデンサはアナログフロントエンドの電源入口付近に。
U1606 EN=+3V3_A (3V3-first). AbsMax VCC-VDD protection.
PATCH_V1
GND: NT1601=A_GND─ADC_GND（A1601 近傍・アナログ星点）。NT1602=PD_GND─D_GND（PD 入口）。NT1603=A_GND─D_GND（2026-09-07 新設。U1604 削除で失われた A_GND↔D_GND の橋を明示化）。⚠ NT1601 / NT1602 / NT1603 は PCB で近接させる（1点アース。I2S の帰り・U403 の帰路・U201 の Ciso 経由 CM が全部ここを通る）。Pico/LCD は D_GND のみ。D_GND は太く短く、アナログ入力から離す。
U1605=TPS3307-33D SO-8: SENSE1=+5V_A (4.55V) SENSE2=+3V3_A (2.93V) SENSE3=VDD; VDD=+3V3_A C1614 100nF; ~RESET PP -> ADC_nRST + R1611; GP15 OD -> ~MR (do not drive H); RESET pin NC; 200ms delay. Replaces TPS3808G33/G50 SOT-23-6.
チャンネルあたりの公式リファレンス構成: 入力インバータ + ADC VCOM 基準の反転 LPF ドライバ×2。
OPA2134 からの OPA1656 置き換え。6.19k/4.7k 網（前段入力抵抗は 2026-09-07 に 3.3k→6.19k）では FET 入力が有利。試作で安定性とフルスケール・レベルを確認すること。
左チャンネル
PATCH_V2
JP1F: ショート=H / 開放=L。本設計は S/M=L, OSR2=L OSR1=H OSR0=H（ADCマスタ 48k/256fs）、24bit I²S → FMT1=L（開放）FMT0=H（ショート）。HPF はモジュールマニュアルに従う。
U1603 LT1763-3.3 (+3V3_A). Fixed LDO; SHDN tied for always-on or as designed. Local CIN/COUT.
FE_PATCH_V1
電源: USB VBUS → Pico 内部ショットキ → VSYS。D1601 が +5V_D への逆流を止めるので、USB だけ挿すと Pico は動き LCD は消える。VBUS(pin40) は NC。
U1609 XC8107AC20MR-G ロードスイッチ: LCD_EN High=ON / Low・Hi-Z=OFF（Active High, VCEH 1.5V min → Pico 3.3V で直接駆動可）。R1620 100k=CE プルダウンで起動時 OFF。初号は常時 ON 可。OFF 運用時は SPI/タッチを Low/Hi-Z に。ソフトスタート 0.6ms typ・短絡/逆流/過熱/UVLO 保護内蔵。C1633=CIN, C1631=CL は各 10uF/3216 を IC 直近へ。FLG は未使用（NC）。
GP15=ADC_nMR は TPS3307 の ~MR。オープンドレインのみ、H は駆動しない。 ~RESET はプッシュプルなので ADC_nRST には直接ワイヤ AND しない。
階層ポート / 右チャンネル

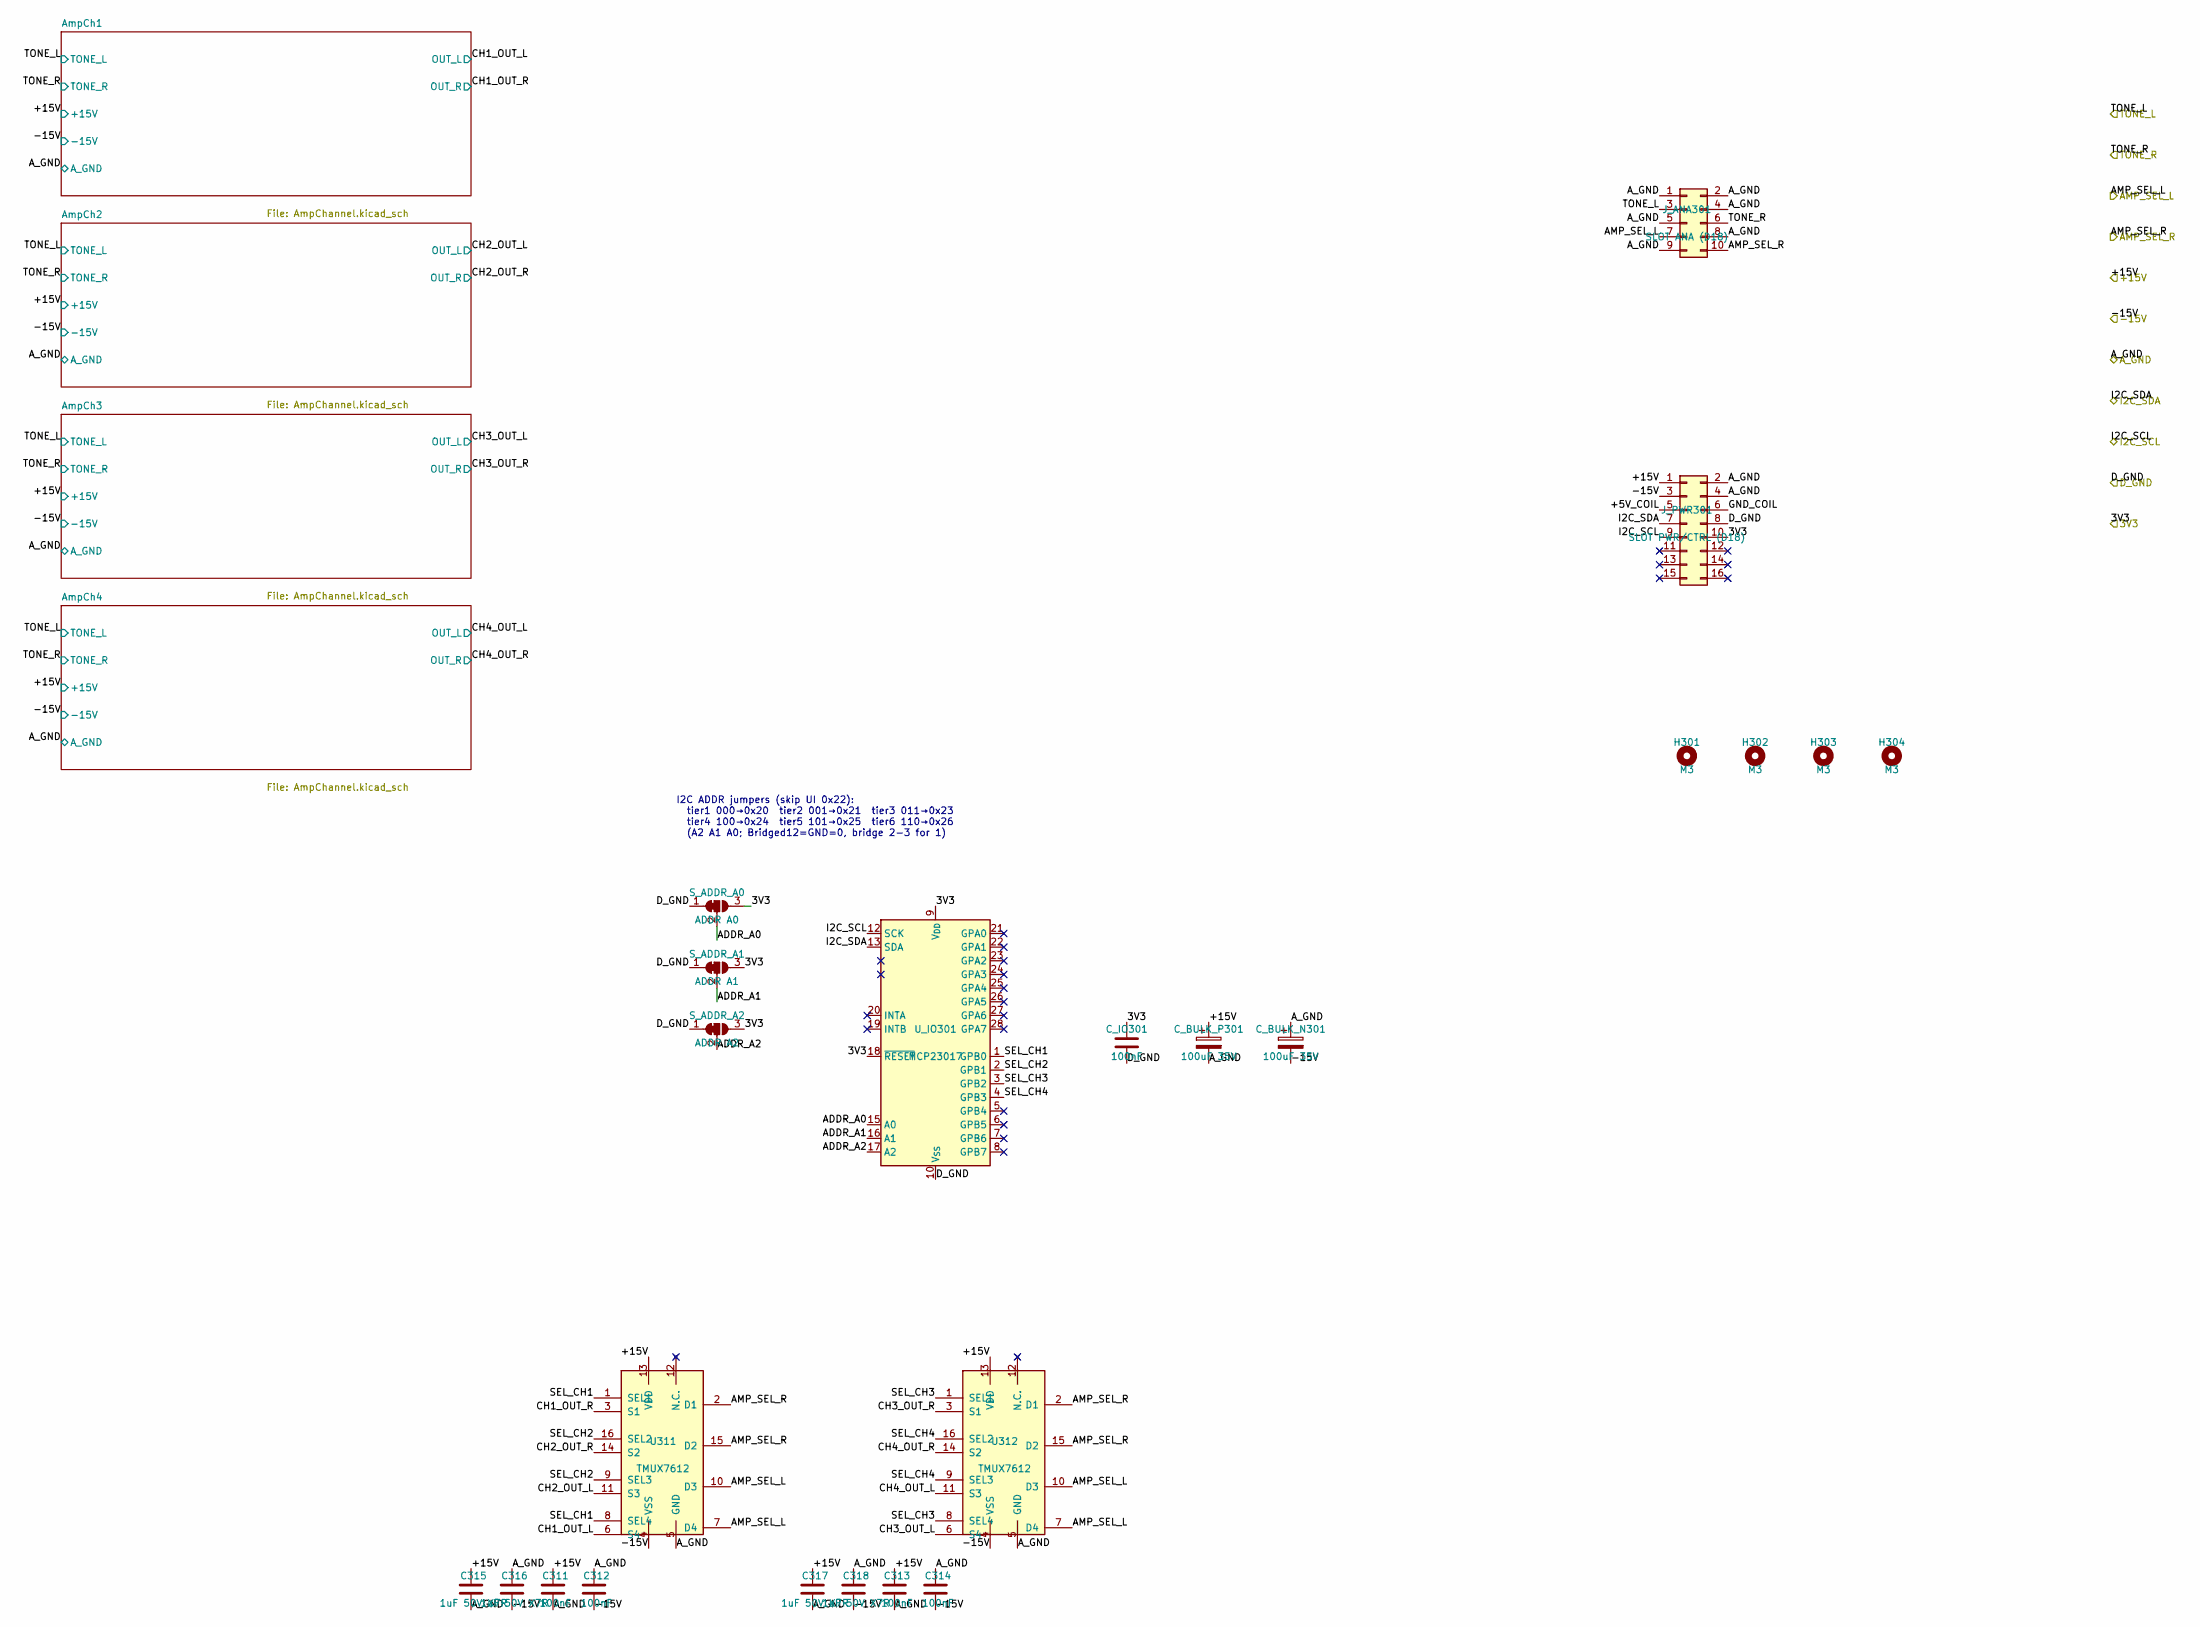
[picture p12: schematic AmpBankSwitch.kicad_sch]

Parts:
C311, C312, C313, C314: 100nF; C_0603_1608Metric_Pad1.08x0.95mm_HandSolder
C315, C316, C317, C318: 1uF 50V X7R; C_0603_1608Metric_Pad1.08x0.95mm_HandSolder
C_BULK_N301: 100uF 35V; CP_Elec_10x12.6
C_BULK_P301: 100uF 35V; CP_Elec_10x12.6
C_IO301: 100nF; C_0603_1608Metric_Pad1.08x0.95mm_HandSolder
H301, H302, H303, H304: M3; MountingHole_3.2mm_M3
J_ANA301: SLOT ANA (D18); PinHeader_2x05_P2.54mm_Vertical
J_PWR301: SLOT PWR/CTRL (D18); PinHeader_2x08_P2.54mm_Vertical
S_ADDR_A0: ADDR A0; SolderJumper-3_P1.3mm_Bridged12_Pad1.0x1.5mm_NumberLabels
S_ADDR_A1: ADDR A1; SolderJumper-3_P1.3mm_Bridged12_Pad1.0x1.5mm_NumberLabels
S_ADDR_A2: ADDR A2; SolderJumper-3_P1.3mm_Bridged12_Pad1.0x1.5mm_NumberLabels
U311, U312: TMUX7612; TSSOP-16_4.4x5mm_P0.65mm
U_IO301: MCP23017; DIP-28_W7.62mm

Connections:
/3V3: C_IO301.1, J_PWR301.10, S_ADDR_A0.3 (B), S_ADDR_A1.3 (B), S_ADDR_A2.3 (B), U_IO301.9 (V_{DD}), U_IO301.18 (~RESET); also elsewhere on the board
/+15V: C311.1, C313.1, C315.1, C317.1, C_BULK_P301.1, J_PWR301.1, U311.13 (VDD), U312.13 (VDD); also elsewhere on the board
/-15V: C312.2, C314.2, C316.2, C318.2, C_BULK_N301.2, J_PWR301.3, U311.4 (VSS), U312.4 (VSS); also elsewhere on the board
/AMP_SEL_L: J_ANA301.7, U311.7 (D4), U311.10 (D3), U312.7 (D4), U312.10 (D3); also elsewhere on the board
/AMP_SEL_R: J_ANA301.10, U311.2 (D1), U311.15 (D2), U312.2 (D1), U312.15 (D2); also elsewhere on the board
/A_GND: C311.2, C312.1, C313.2, C314.1, C315.2, C316.1, C317.2, C318.1, C_BULK_N301.1, C_BULK_P301.2, J_ANA301.1, J_ANA301.2, J_ANA301.4, J_ANA301.5, J_ANA301.8, J_ANA301.9, J_PWR301.2, J_PWR301.4, U311.5 (GND), U312.5 (GND); also elsewhere on the board
/AmpBankSwitch/+5V_COIL: J_PWR301.5
/AmpBankSwitch/ADDR_A0: S_ADDR_A0.2 (C), U_IO301.15 (A0)
/AmpBankSwitch/ADDR_A1: S_ADDR_A1.2 (C), U_IO301.16 (A1)
/AmpBankSwitch/ADDR_A2: S_ADDR_A2.2 (C), U_IO301.17 (A2)
/AmpBankSwitch/CH1_OUT_L: U311.6 (S4); also elsewhere on the board
/AmpBankSwitch/CH1_OUT_R: U311.3 (S1); also elsewhere on the board
/AmpBankSwitch/CH2_OUT_L: U311.11 (S3); also elsewhere on the board
/AmpBankSwitch/CH2_OUT_R: U311.14 (S2); also elsewhere on the board
/AmpBankSwitch/CH3_OUT_L: U312.6 (S4); also elsewhere on the board
/AmpBankSwitch/CH3_OUT_R: U312.3 (S1); also elsewhere on the board
/AmpBankSwitch/CH4_OUT_L: U312.11 (S3); also elsewhere on the board
/AmpBankSwitch/CH4_OUT_R: U312.14 (S2); also elsewhere on the board
/AmpBankSwitch/GND_COIL: J_PWR301.6
/AmpBankSwitch/SEL_CH1: U311.1 (SEL1), U311.8 (SEL4), U_IO301.1 (GPB0)
/AmpBankSwitch/SEL_CH2: U311.9 (SEL3), U311.16 (SEL2), U_IO301.2 (GPB1)
/AmpBankSwitch/SEL_CH3: U312.1 (SEL1), U312.8 (SEL4), U_IO301.3 (GPB2)
/AmpBankSwitch/SEL_CH4: U312.9 (SEL3), U312.16 (SEL2), U_IO301.4 (GPB3)
/D_GND: C_IO301.2, J_PWR301.8, S_ADDR_A0.1 (A), S_ADDR_A1.1 (A), S_ADDR_A2.1 (A), U_IO301.10 (V_{SS}); also elsewhere on the board
/I2C_SCL: J_PWR301.9, U_IO301.12 (SCK); also elsewhere on the board
/I2C_SDA: J_PWR301.7, U_IO301.13 (SDA); also elsewhere on the board
/TONE_L: J_ANA301.3; also elsewhere on the board
/TONE_R: J_ANA301.6; also elsewhere on the board

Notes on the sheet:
I2C ADDR jumpers (skip UI 0x22): tier1 000→0x20 tier2 001→0x21 tier3 011→0x23 tier4 100→0x24 tier5 101→0x25 tier6 110→0x26 (A2 A1 A0; Bridged12=GND=0, bridge 2-3 for 1)

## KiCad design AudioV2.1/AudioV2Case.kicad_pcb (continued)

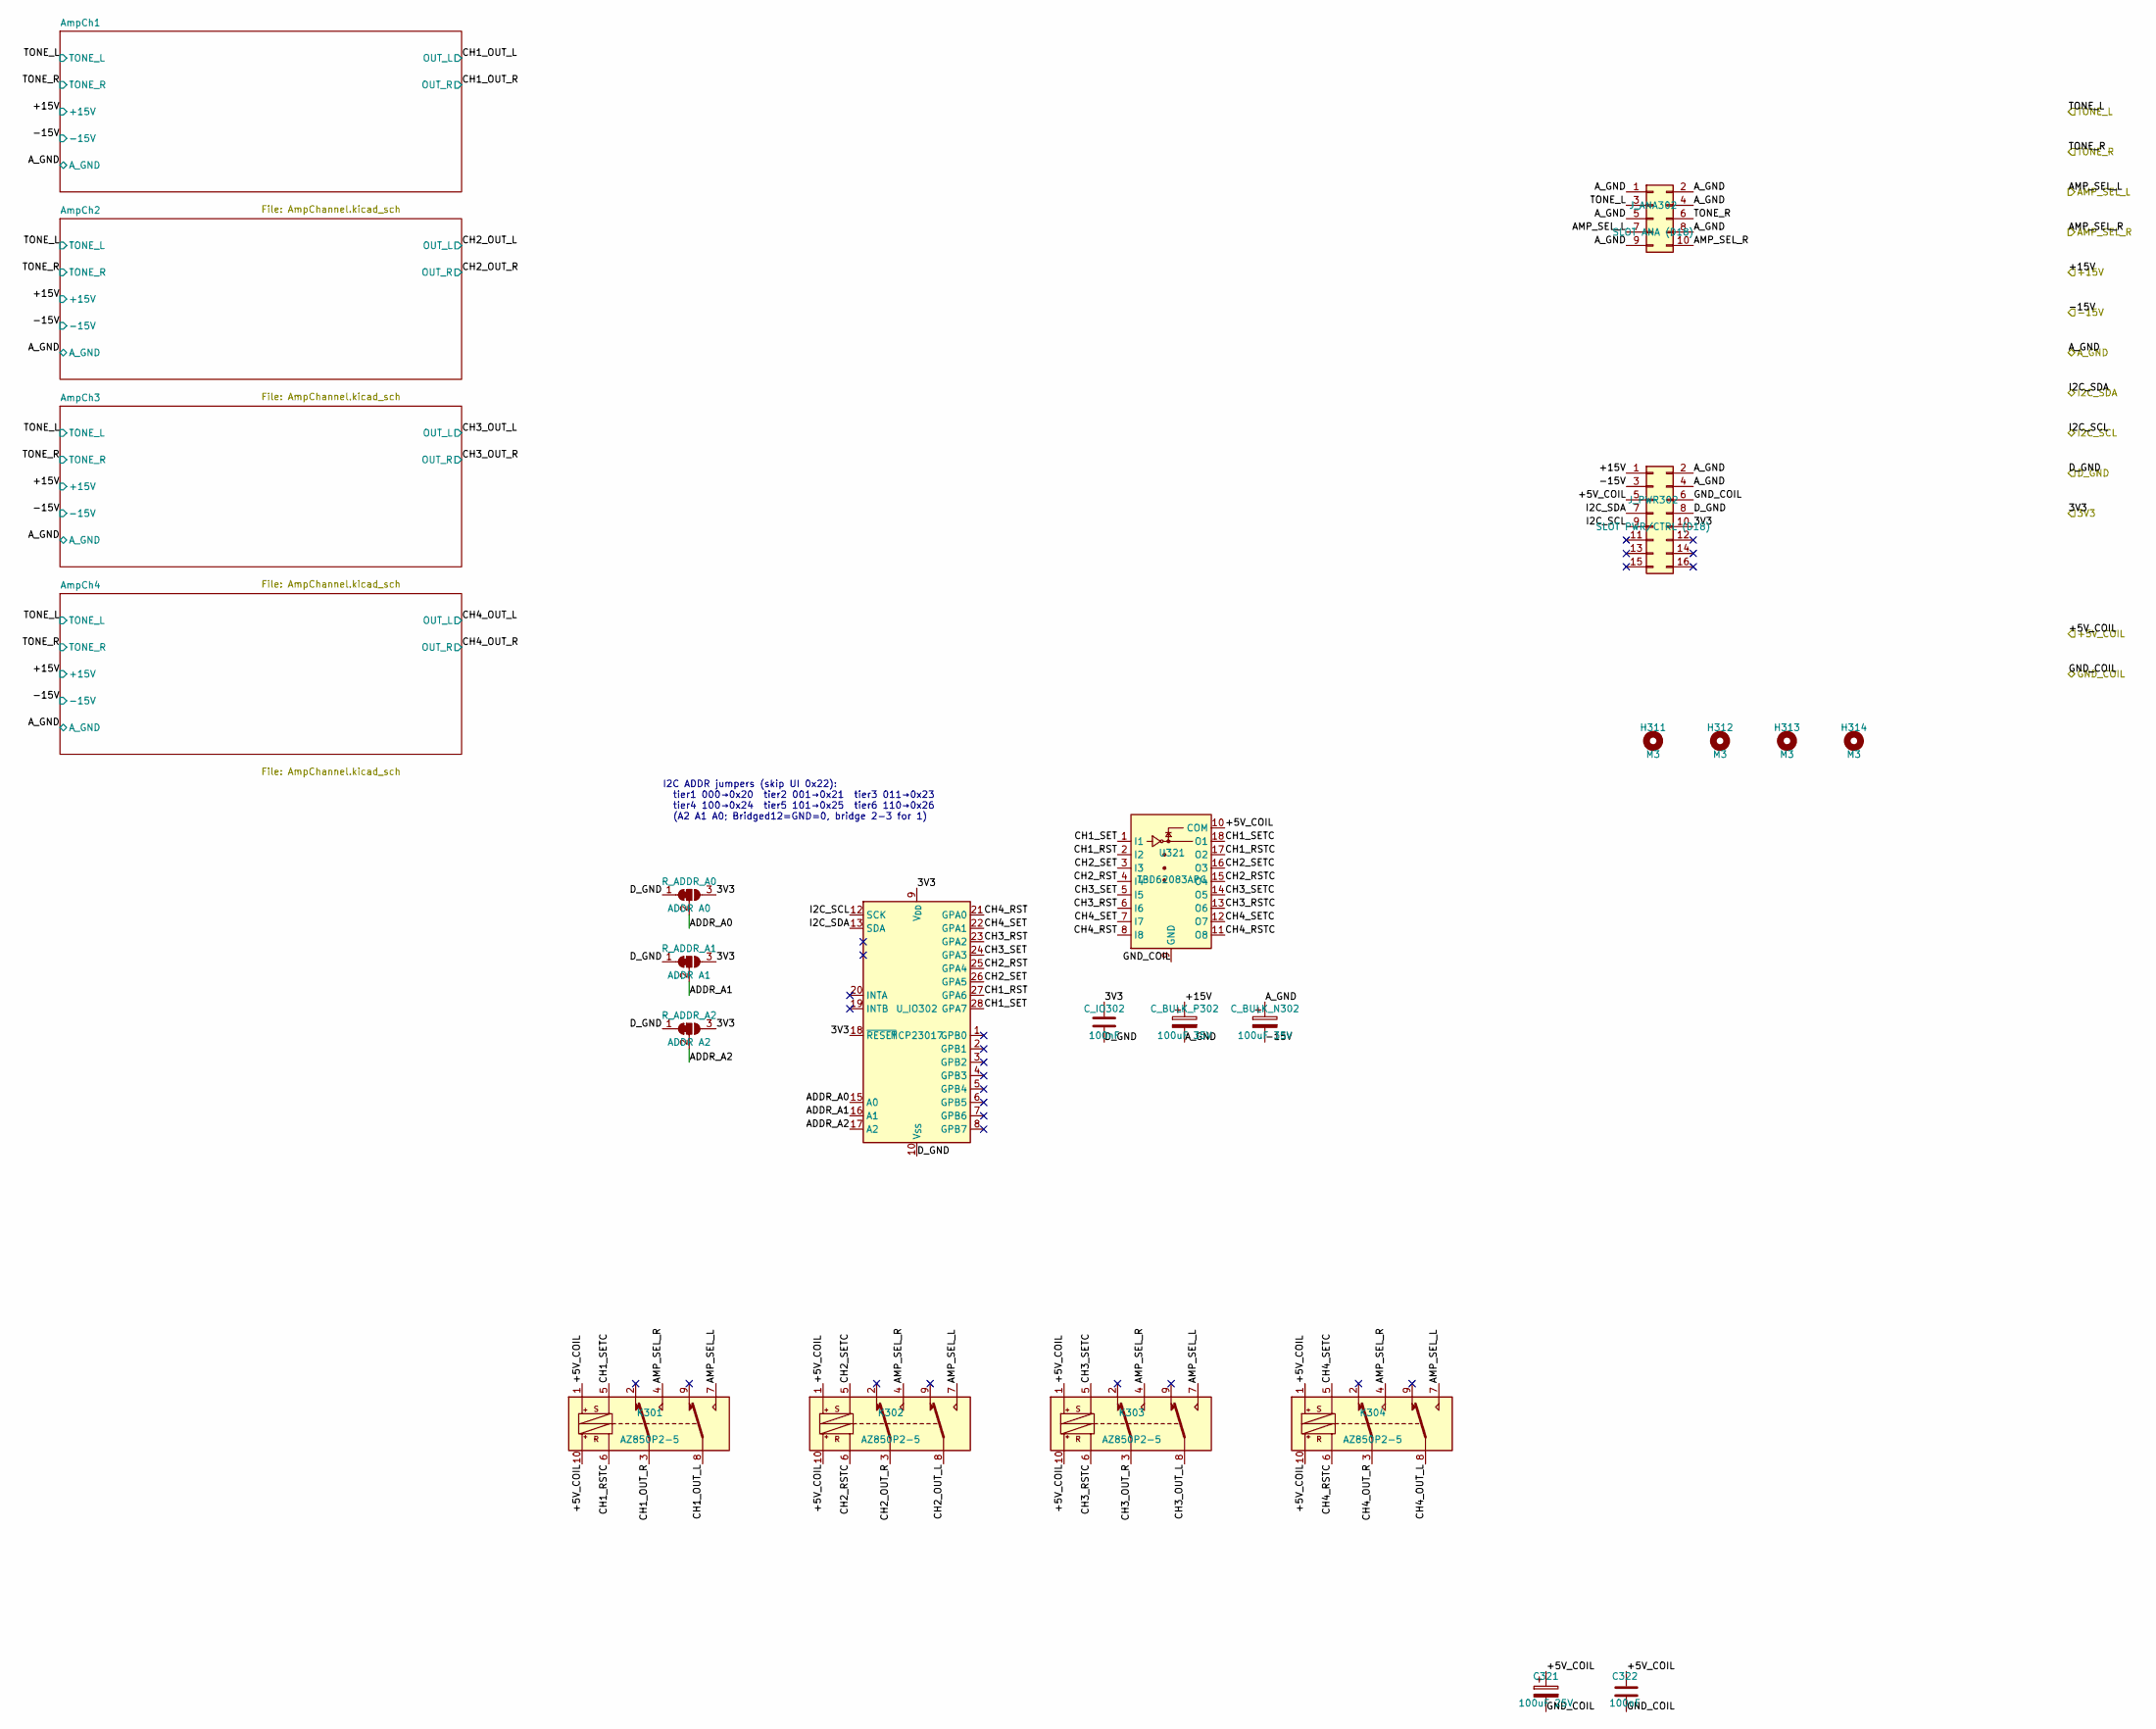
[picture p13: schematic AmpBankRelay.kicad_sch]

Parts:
C321: 100uF 25V; CP_Elec_10x12.6
C322: 100nF; C_0603_1608Metric_Pad1.08x0.95mm_HandSolder
C_BULK_N302: 100uF 35V; CP_Elec_10x12.6
C_BULK_P302: 100uF 35V; CP_Elec_10x12.6
C_IO302: 100nF; C_0603_1608Metric_Pad1.08x0.95mm_HandSolder
H311, H312, H313, H314: M3; MountingHole_3.2mm_M3
J_ANA302: SLOT ANA (D18); PinHeader_2x05_P2.54mm_Vertical
J_PWR302: SLOT PWR/CTRL (D18); PinHeader_2x08_P2.54mm_Vertical
K301, K302, K303, K304: AZ850P2-5; Relay_DPDT_FRT5
R_ADDR_A0: ADDR A0; SolderJumper-3_P1.3mm_Bridged12_Pad1.0x1.5mm_NumberLabels
R_ADDR_A1: ADDR A1; SolderJumper-3_P1.3mm_Bridged12_Pad1.0x1.5mm_NumberLabels
R_ADDR_A2: ADDR A2; SolderJumper-3_P1.3mm_Bridged12_Pad1.0x1.5mm_NumberLabels
U321: TBD62083APG; DIP-18_W7.62mm
U_IO302: MCP23017; DIP-28_W7.62mm

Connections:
/3V3: C_IO302.1, J_PWR302.10, R_ADDR_A0.3 (B), R_ADDR_A1.3 (B), R_ADDR_A2.3 (B), U_IO302.9 (V_{DD}), U_IO302.18 (~RESET); also elsewhere on the board
/+5V_COIL: C321.1, C322.1, J_PWR302.5, K301.1, K301.10, K302.1, K302.10, K303.1, K303.10, K304.1, K304.10, U321.10 (COM); also elsewhere on the board
/+15V: C_BULK_P302.1, J_PWR302.1; also elsewhere on the board
/-15V: C_BULK_N302.2, J_PWR302.3; also elsewhere on the board
/AMP_SEL_L: J_ANA302.7, K301.7, K302.7, K303.7, K304.7; also elsewhere on the board
/AMP_SEL_R: J_ANA302.10, K301.4, K302.4, K303.4, K304.4; also elsewhere on the board
/A_GND: C_BULK_N302.1, C_BULK_P302.2, J_ANA302.1, J_ANA302.2, J_ANA302.4, J_ANA302.5, J_ANA302.8, J_ANA302.9, J_PWR302.2, J_PWR302.4; also elsewhere on the board
/AmpBankRelay/ADDR_A0: R_ADDR_A0.2 (C), U_IO302.15 (A0)
/AmpBankRelay/ADDR_A1: R_ADDR_A1.2 (C), U_IO302.16 (A1)
/AmpBankRelay/ADDR_A2: R_ADDR_A2.2 (C), U_IO302.17 (A2)
/AmpBankRelay/CH1_OUT_L: K301.8; also elsewhere on the board
/AmpBankRelay/CH1_OUT_R: K301.3; also elsewhere on the board
/AmpBankRelay/CH1_RST: U321.2 (I2), U_IO302.27 (GPA6)
/AmpBankRelay/CH1_RSTC: K301.6, U321.17 (O2)
/AmpBankRelay/CH1_SET: U321.1 (I1), U_IO302.28 (GPA7)
/AmpBankRelay/CH1_SETC: K301.5, U321.18 (O1)
/AmpBankRelay/CH2_OUT_L: K302.8; also elsewhere on the board
/AmpBankRelay/CH2_OUT_R: K302.3; also elsewhere on the board
/AmpBankRelay/CH2_RST: U321.4 (I4), U_IO302.25 (GPA4)
/AmpBankRelay/CH2_RSTC: K302.6, U321.15 (O4)
/AmpBankRelay/CH2_SET: U321.3 (I3), U_IO302.26 (GPA5)
/AmpBankRelay/CH2_SETC: K302.5, U321.16 (O3)
/AmpBankRelay/CH3_OUT_L: K303.8; also elsewhere on the board
/AmpBankRelay/CH3_OUT_R: K303.3; also elsewhere on the board
/AmpBankRelay/CH3_RST: U321.6 (I6), U_IO302.23 (GPA2)
/AmpBankRelay/CH3_RSTC: K303.6, U321.13 (O6)
/AmpBankRelay/CH3_SET: U321.5 (I5), U_IO302.24 (GPA3)
/AmpBankRelay/CH3_SETC: K303.5, U321.14 (O5)
/AmpBankRelay/CH4_OUT_L: K304.8; also elsewhere on the board
/AmpBankRelay/CH4_OUT_R: K304.3; also elsewhere on the board
/AmpBankRelay/CH4_RST: U321.8 (I8), U_IO302.21 (GPA0)
/AmpBankRelay/CH4_RSTC: K304.6, U321.11 (O8)
/AmpBankRelay/CH4_SET: U321.7 (I7), U_IO302.22 (GPA1)
/AmpBankRelay/CH4_SETC: K304.5, U321.12 (O7)
/D_GND: C_IO302.2, J_PWR302.8, R_ADDR_A0.1 (A), R_ADDR_A1.1 (A), R_ADDR_A2.1 (A), U_IO302.10 (V_{SS}); also elsewhere on the board
/GND_COIL: C321.2, C322.2, J_PWR302.6, U321.9 (GND); also elsewhere on the board
/I2C_SCL: J_PWR302.9, U_IO302.12 (SCK); also elsewhere on the board
/I2C_SDA: J_PWR302.7, U_IO302.13 (SDA); also elsewhere on the board
/TONE_L: J_ANA302.3; also elsewhere on the board
/TONE_R: J_ANA302.6; also elsewhere on the board

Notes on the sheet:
I2C ADDR jumpers (skip UI 0x22): tier1 000→0x20 tier2 001→0x21 tier3 011→0x23 tier4 100→0x24 tier5 101→0x25 tier6 110→0x26 (A2 A1 A0; Bridged12=GND=0, bridge 2-3 for 1)

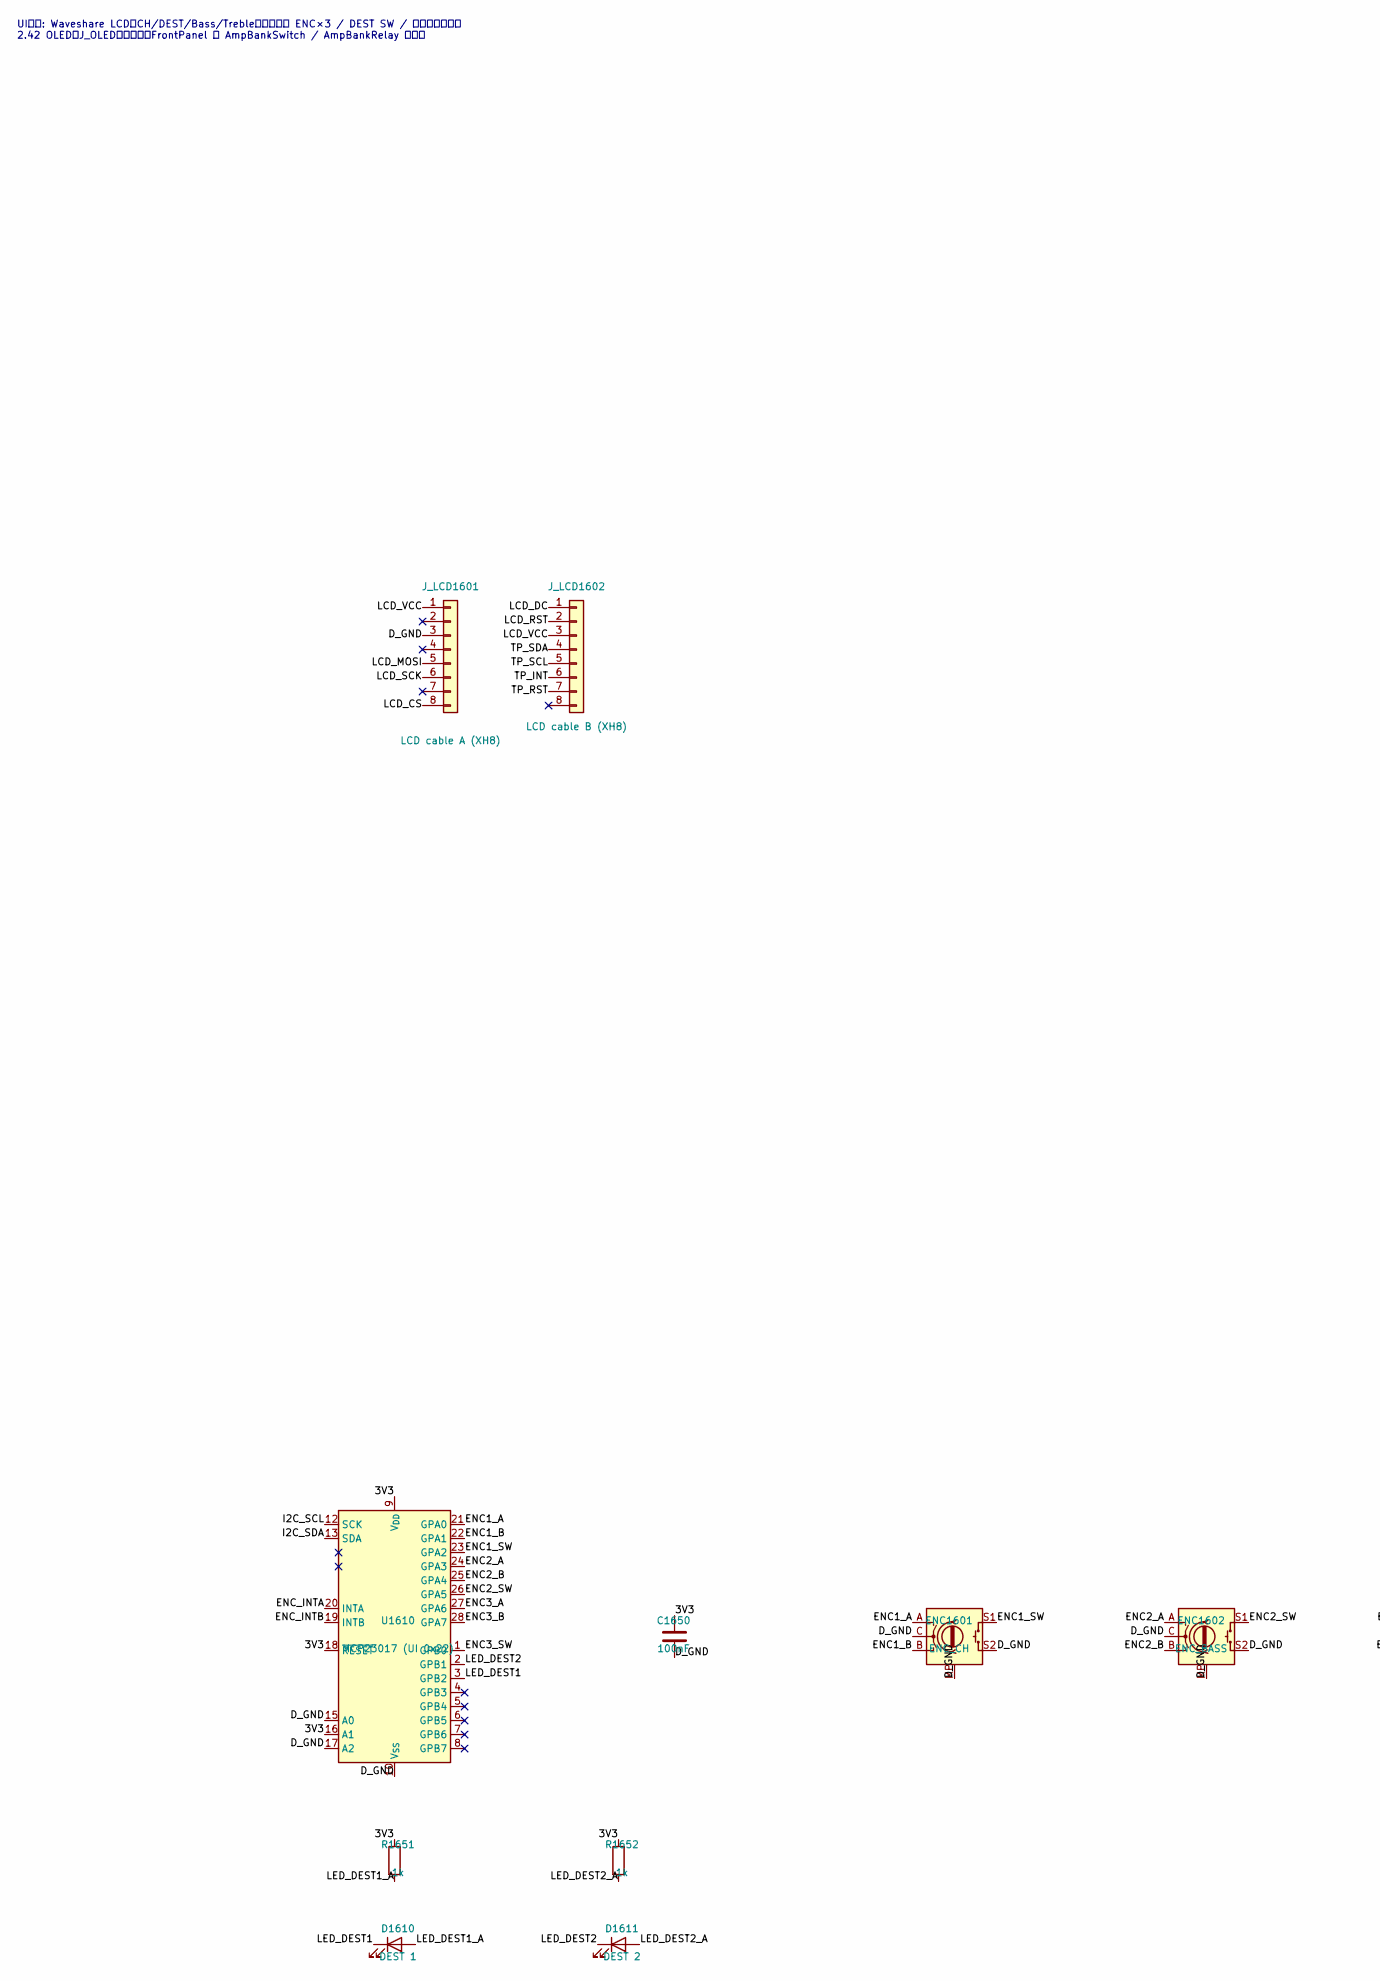
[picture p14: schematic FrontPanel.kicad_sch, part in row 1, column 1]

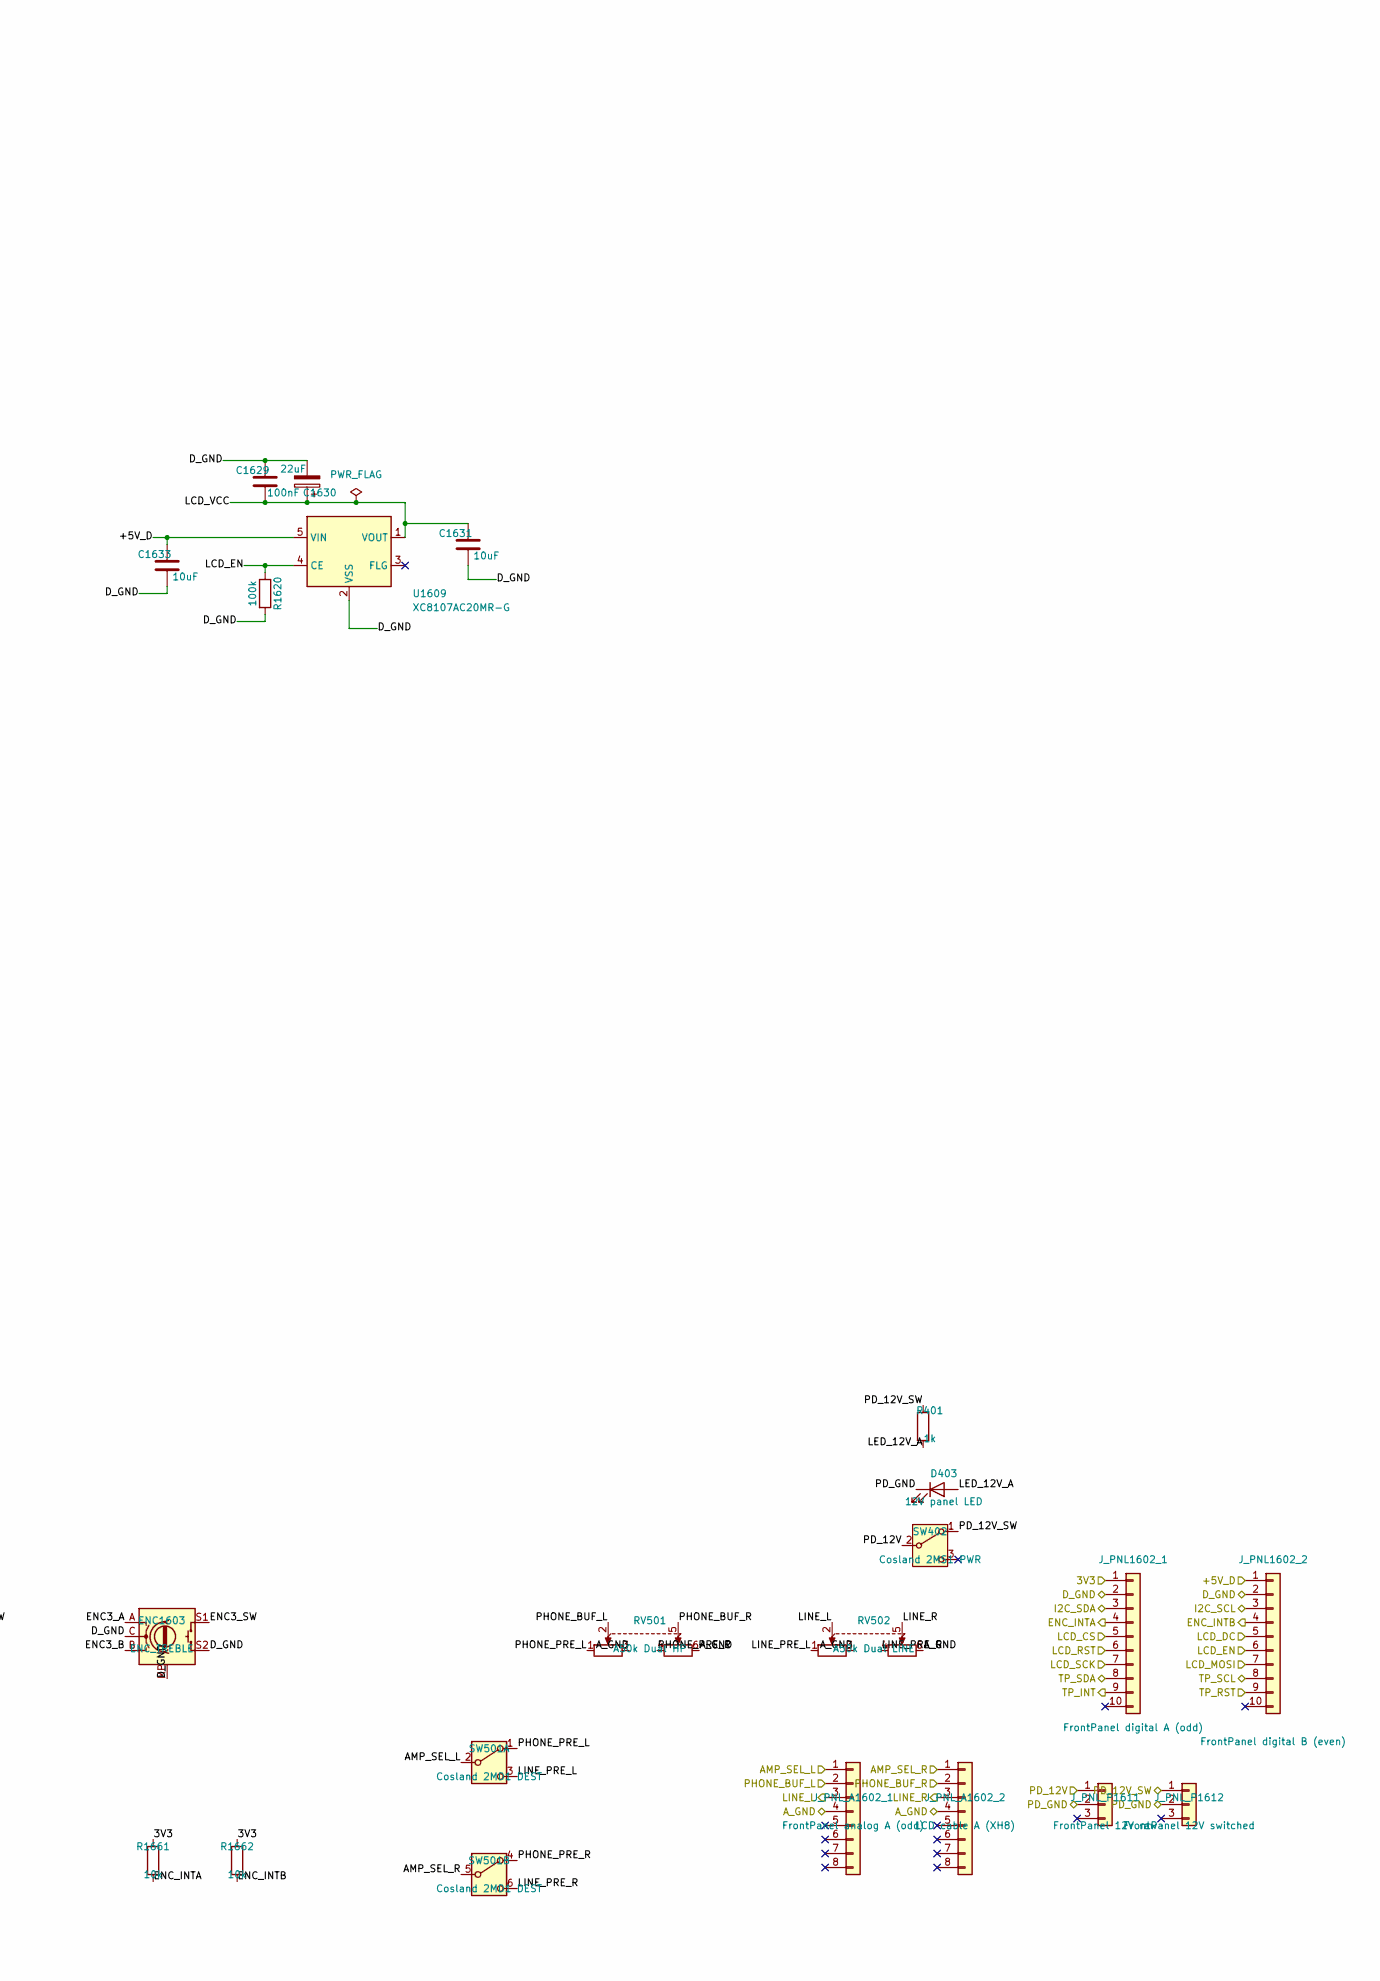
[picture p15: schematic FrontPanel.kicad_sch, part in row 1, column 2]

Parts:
C1629, C1650: 100nF; C_1206_3216Metric_Pad1.33x1.80mm_HandSolder
C1630: 22uF; CP_Radial_D6.3mm_P2.50mm
C1631, C1633: 10uF; C_1206_3216Metric_Pad1.33x1.80mm_HandSolder
D403: 12V panel LED; LED_D5.0mm
D1610: DEST 1; LED_D5.0mm
D1611: DEST 2; LED_D5.0mm
ENC1601: ENC_CH; RotaryEncoder_Alps_EC11E-Switch_Vertical_H20mm
ENC1602: ENC_BASS; RotaryEncoder_Alps_EC11E-Switch_Vertical_H20mm
ENC1603: ENC_TREBLE; RotaryEncoder_Alps_EC11E-Switch_Vertical_H20mm
J_LCD1601: LCD cable A (XH8); JST_XH_B8B-XH-A_1x08_P2.50mm_Vertical
J_LCD1602: LCD cable B (XH8); JST_XH_B8B-XH-A_1x08_P2.50mm_Vertical
J_PNL1602_1: FrontPanel digital A (odd); JST_XH_B10B-XH-A_1x10_P2.50mm_Vertical
J_PNL1602_2: FrontPanel digital B (even); JST_XH_B10B-XH-A_1x10_P2.50mm_Vertical
J_PNL_A1602_1: FrontPanel analog A (odd); JST_XH_B8B-XH-A_1x08_P2.50mm_Vertical
J_PNL_A1602_2: LCD cable A (XH8); JST_XH_B8B-XH-A_1x08_P2.50mm_Vertical
J_PNL_P1611: FrontPanel 12V raw; JST_XH_B3B-XH-A_1x03_P2.50mm_Vertical
J_PNL_P1612: FrontPanel 12V switched; JST_XH_B3B-XH-A_1x03_P2.50mm_Vertical
R401, R1651, R1652: 1k; R_1206_3216Metric_Pad1.30x1.75mm_HandSolder
R1620: 100k; R_1206_3216Metric_Pad1.30x1.75mm_HandSolder
R1661, R1662: 10k; R_1206_3216Metric_Pad1.30x1.75mm_HandSolder
RV501: A50k Dual HP; JST_XH_B6B-XH-A_1x06_P2.50mm_Vertical
RV502: A50k Dual LINE; JST_XH_B6B-XH-A_1x06_P2.50mm_Vertical
SW402: Cosland 2MS1 PWR; SW_Toggle_Cosland_2MS1_VS2_SPDT
SW501: Cosland 2MD1 DEST; SW_Toggle_Cosland_2MD1_VS2_DPDT
U1609: XC8107AC20MR-G; SOT-23-5_HandSoldering
U1610: MCP23017 (UI 0x22); DIP-28_W7.62mm

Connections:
/3V3: C1650.1, J_PNL1602_1.1, R1651.1, R1652.1, R1661.1, R1662.1, U1610.9 (V_{DD}), U1610.16 (A1), U1610.18 (~RESET); also elsewhere on the board
/+5V_D: C1633.1, J_PNL1602_2.1, U1609.5 (VIN); also elsewhere on the board
/AMP_SEL_L: J_PNL_A1602_1.1, SW501.2 (B); also elsewhere on the board
/AMP_SEL_R: J_PNL_A1602_2.1, SW501.5 (B); also elsewhere on the board
/A_GND: J_PNL_A1602_1.4, J_PNL_A1602_2.4, RV501.3, RV501.6, RV502.3, RV502.6; also elsewhere on the board
/D_GND: C1629.1, C1630.2, C1631.2, C1633.2, C1650.2, ENC1601.C, ENC1601.MP, ENC1601.S2, ENC1602.C, ENC1602.MP, ENC1602.S2, ENC1603.C, ENC1603.MP, ENC1603.S2, J_LCD1601.3, J_PNL1602_1.2, J_PNL1602_2.2, R1620.2, U1609.2 (VSS), U1610.10 (V_{SS}), U1610.15 (A0), U1610.17 (A2); also elsewhere on the board
/ENC_INTA: J_PNL1602_1.4, R1661.2, U1610.20 (INTA); also elsewhere on the board
/ENC_INTB: J_PNL1602_2.4, R1662.2, U1610.19 (INTB); also elsewhere on the board
/FrontPanel/ENC1_A: ENC1601.A, U1610.21 (GPA0)
/FrontPanel/ENC1_B: ENC1601.B, U1610.22 (GPA1)
/FrontPanel/ENC1_SW: ENC1601.S1, U1610.23 (GPA2)
/FrontPanel/ENC2_A: ENC1602.A, U1610.24 (GPA3)
/FrontPanel/ENC2_B: ENC1602.B, U1610.25 (GPA4)
/FrontPanel/ENC2_SW: ENC1602.S1, U1610.26 (GPA5)
/FrontPanel/ENC3_A: ENC1603.A, U1610.27 (GPA6)
/FrontPanel/ENC3_B: ENC1603.B, U1610.28 (GPA7)
/FrontPanel/ENC3_SW: ENC1603.S1, U1610.1 (GPB0)
/FrontPanel/LCD_VCC: C1629.2, C1630.1, C1631.1, J_LCD1601.1, J_LCD1602.3, U1609.1 (VOUT)
/FrontPanel/LED_12V_A: D403.2 (A), R401.2
/FrontPanel/LED_DEST1: D1610.1 (K), U1610.3 (GPB2)
/FrontPanel/LED_DEST1_A: D1610.2 (A), R1651.2
/FrontPanel/LED_DEST2: D1611.1 (K), U1610.2 (GPB1)
/FrontPanel/LED_DEST2_A: D1611.2 (A), R1652.2
/FrontPanel/LINE_PRE_L: RV502.1, SW501.3 (C)
/FrontPanel/LINE_PRE_R: RV502.4, SW501.6 (C)
/FrontPanel/PHONE_PRE_L: RV501.1, SW501.1 (A)
/FrontPanel/PHONE_PRE_R: RV501.4, SW501.4 (A)
/I2C_SCL: J_PNL1602_2.3, U1610.12 (SCK); also elsewhere on the board
/I2C_SDA: J_PNL1602_1.3, U1610.13 (SDA); also elsewhere on the board
/LCD_CS: J_LCD1601.8, J_PNL1602_1.5; also elsewhere on the board
/LCD_DC: J_LCD1602.1, J_PNL1602_2.5; also elsewhere on the board
/LCD_EN: J_PNL1602_2.6, R1620.1, U1609.4 (CE); also elsewhere on the board
/LCD_MOSI: J_LCD1601.5, J_PNL1602_2.7; also elsewhere on the board
/LCD_RST: J_LCD1602.2, J_PNL1602_1.6; also elsewhere on the board
/LCD_SCK: J_LCD1601.6, J_PNL1602_1.7; also elsewhere on the board
/LINE_L: J_PNL_A1602_1.3, RV502.2; also elsewhere on the board
/LINE_R: J_PNL_A1602_2.3, RV502.5; also elsewhere on the board
/PD_12V: J_PNL_P1611.1, SW402.2 (B); also elsewhere on the board
/PD_12V_SW: J_PNL_P1612.1, R401.1, SW402.1 (A); also elsewhere on the board
/PD_GND: D403.1 (K), J_PNL_P1611.2, J_PNL_P1612.2; also elsewhere on the board
/PHONE_BUF_L: J_PNL_A1602_1.2, RV501.2; also elsewhere on the board
/PHONE_BUF_R: J_PNL_A1602_2.2, RV501.5; also elsewhere on the board
/TP_INT: J_LCD1602.6, J_PNL1602_1.9; also elsewhere on the board
/TP_RST: J_LCD1602.7, J_PNL1602_2.9; also elsewhere on the board
/TP_SCL: J_LCD1602.5, J_PNL1602_2.8; also elsewhere on the board
/TP_SDA: J_LCD1602.4, J_PNL1602_1.8; also elsewhere on the board

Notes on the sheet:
UI表示: Waveshare LCD（CH/DEST/Bass/Treble）。操作は ENC×3 / DEST SW / ポットのまま。 2.42 OLED（J_OLED）は廃止。FrontPanel は AmpBankSwitch / AmpBankRelay 共通。

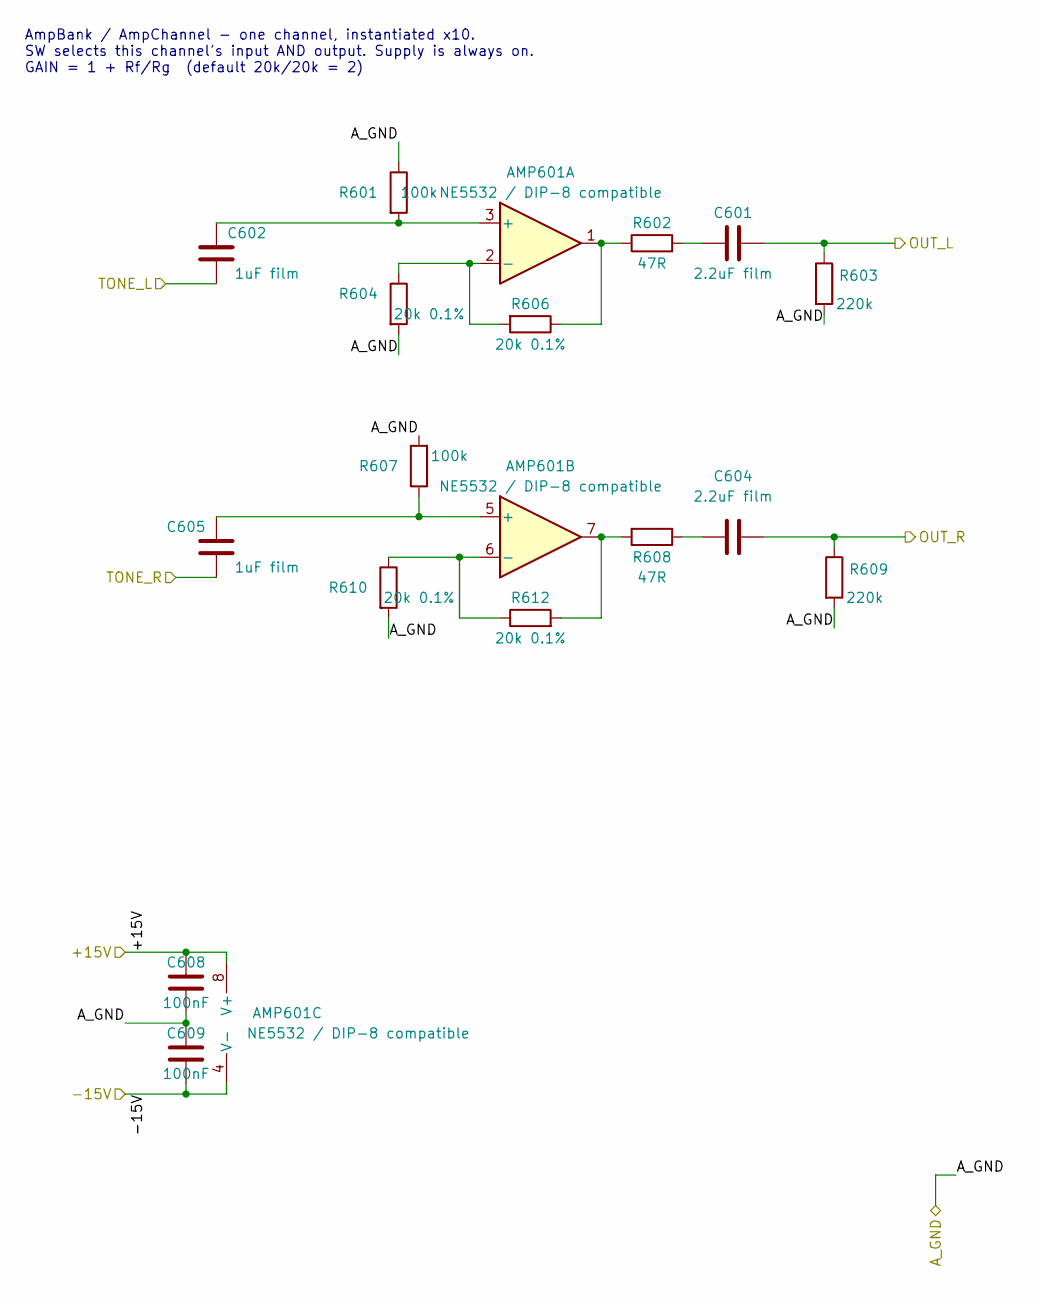
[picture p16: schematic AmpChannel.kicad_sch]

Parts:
AMP601: NE5532 / DIP-8 compatible; DIP-8_W7.62mm_Socket
C601, C604: 2.2uF film; C_Rect_L7.2mm_W7.2mm_P5.00mm_FKS2_FKP2_MKS2_MKP2
C602, C605: 1uF film; C_Rect_L7.2mm_W4.5mm_P5.00mm_FKS2_FKP2_MKS2_MKP2
C608, C609: 100nF; C_1206_3216Metric_Pad1.33x1.80mm_HandSolder
R601, R607: 100k; R_1206_3216Metric_Pad1.30x1.75mm_HandSolder
R602, R608: 47R; R_1206_3216Metric_Pad1.30x1.75mm_HandSolder
R603, R609: 220k; R_1206_3216Metric_Pad1.30x1.75mm_HandSolder
R604, R606, R610, R612: 20k 0.1%; R_0805_2012Metric_Pad1.20x1.40mm_HandSolder

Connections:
/+15V: AMP601.8 (V+), C608.1; also elsewhere on the board
/-15V: AMP601.4 (V-), C609.2; also elsewhere on the board
/A_GND: C608.2, C609.1, R601.1, R603.2, R604.2, R607.2, R609.2, R610.2; also elsewhere on the board
/AmpBankSwitch/CH1_OUT_L: C601.2, R603.1; also elsewhere on the board
/AmpBankSwitch/CH1_OUT_R: C604.1, R609.1; also elsewhere on the board
/TONE_L: C602.1; also elsewhere on the board
/TONE_R: C605.1; also elsewhere on the board
unnamed: AMP601.1, R602.1, R606.1
unnamed: AMP601.7, R608.2, R612.2
unnamed: AMP601.3 (+), C602.2, R601.2
unnamed: AMP601.2 (-), R604.1, R606.2
unnamed: AMP601.5 (+), C605.2, R607.1
unnamed: AMP601.6 (-), R610.1, R612.1
unnamed: C601.1, R602.2
unnamed: C604.2, R608.1

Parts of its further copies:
AMP701, AMP801, AMP901, AMP1001, AMP1101, AMP1201, AMP1301: NE5532 / DIP-8 compatible; DIP-8_W7.62mm_Socket
C701, C704, C801, C804, C901, C904, C1001, C1004, C1101, C1104, C1201, C1204, C1301, C1304: 2.2uF film; C_Rect_L7.2mm_W7.2mm_P5.00mm_FKS2_FKP2_MKS2_MKP2
C702, C705, C802, C805, C902, C905, C1002, C1005, C1102, C1105, C1202, C1205, C1302, C1305: 1uF film; C_Rect_L7.2mm_W4.5mm_P5.00mm_FKS2_FKP2_MKS2_MKP2
C708, C709, C808, C809, C908, C909, C1008, C1009, C1108, C1109, C1208, C1209, C1308, C1309: 100nF; C_1206_3216Metric_Pad1.33x1.80mm_HandSolder
R701, R707, R801, R807, R901, R907, R1001, R1007, R1101, R1107, R1201, R1207, R1301, R1307: 100k; R_1206_3216Metric_Pad1.30x1.75mm_HandSolder
R702, R708, R802, R808, R902, R908, R1002, R1008, R1102, R1108, R1202, R1208, R1302, R1308: 47R; R_1206_3216Metric_Pad1.30x1.75mm_HandSolder
R703, R709, R803, R809, R903, R909, R1003, R1009, R1103, R1109, R1203, R1209, R1303, R1309: 220k; R_1206_3216Metric_Pad1.30x1.75mm_HandSolder
R704, R706, R710, R712, R804, R806, R810, R812, R904, R906, R910, R912, R1004, R1006, R1010, R1012, R1104, R1106, R1110, R1112, R1204, R1206, R1210, R1212, R1304, R1306, R1310, R1312: 20k 0.1%; R_0805_2012Metric_Pad1.20x1.40mm_HandSolder

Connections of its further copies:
/+15V: AMP701.8 (V+), AMP801.8 (V+), AMP901.8 (V+), AMP1001.8 (V+), AMP1101.8 (V+), AMP1201.8 (V+), AMP1301.8 (V+), C708.1, C808.1, C908.1, C1008.1, C1108.1, C1208.1, C1308.1; also elsewhere on the board
/-15V: AMP701.4 (V-), AMP801.4 (V-), AMP901.4 (V-), AMP1001.4 (V-), AMP1101.4 (V-), AMP1201.4 (V-), AMP1301.4 (V-), C709.2, C809.2, C909.2, C1009.2, C1109.2, C1209.2, C1309.2; also elsewhere on the board
/A_GND: C708.2, C709.1, C808.2, C809.1, C908.2, C909.1, C1008.2, C1009.1, C1108.2, C1109.1, C1208.2, C1209.1, C1308.2, C1309.1, R701.1, R703.2, R704.2, R707.2, R709.2, R710.2, R801.1, R803.2, R804.2, R807.2, R809.2, R810.2, R901.1, R903.2, R904.2, R907.2, R909.2, R910.2, R1001.1, R1003.2, R1004.2, R1007.2, R1009.2, R1010.2, R1101.1, R1103.2, R1104.2, R1107.2, R1109.2, R1110.2, R1201.1, R1203.2, R1204.2, R1207.2, R1209.2, R1210.2, R1301.1, R1303.2, R1304.2, R1307.2, R1309.2, R1310.2; also elsewhere on the board
/AmpBankRelay/CH1_OUT_L: C1001.2, R1003.1; also elsewhere on the board
/AmpBankRelay/CH1_OUT_R: C1004.1, R1009.1; also elsewhere on the board
/AmpBankRelay/CH2_OUT_L: C1101.2, R1103.1; also elsewhere on the board
/AmpBankRelay/CH2_OUT_R: C1104.1, R1109.1; also elsewhere on the board
/AmpBankRelay/CH3_OUT_L: C1201.2, R1203.1; also elsewhere on the board
/AmpBankRelay/CH3_OUT_R: C1204.1, R1209.1; also elsewhere on the board
/AmpBankRelay/CH4_OUT_L: C1301.2, R1303.1; also elsewhere on the board
/AmpBankRelay/CH4_OUT_R: C1304.1, R1309.1; also elsewhere on the board
/AmpBankSwitch/CH2_OUT_L: C701.2, R703.1; also elsewhere on the board
/AmpBankSwitch/CH2_OUT_R: C704.1, R709.1; also elsewhere on the board
/AmpBankSwitch/CH3_OUT_L: C801.2, R803.1; also elsewhere on the board
/AmpBankSwitch/CH3_OUT_R: C804.1, R809.1; also elsewhere on the board
/AmpBankSwitch/CH4_OUT_L: C901.2, R903.1; also elsewhere on the board
/AmpBankSwitch/CH4_OUT_R: C904.1, R909.1; also elsewhere on the board
/TONE_L: C702.1, C802.1, C902.1, C1002.1, C1102.1, C1202.1, C1302.1; also elsewhere on the board
/TONE_R: C705.1, C805.1, C905.1, C1005.1, C1105.1, C1205.1, C1305.1; also elsewhere on the board
unnamed: AMP701.1, R702.1, R706.1
unnamed: AMP701.7, R708.2, R712.2
unnamed: AMP701.3 (+), C702.2, R701.2
unnamed: AMP701.2 (-), R704.1, R706.2
unnamed: AMP701.5 (+), C705.2, R707.1
unnamed: AMP701.6 (-), R710.1, R712.1
unnamed: AMP801.1, R802.1, R806.1
unnamed: AMP801.7, R808.2, R812.2
unnamed: AMP801.3 (+), C802.2, R801.2
unnamed: AMP801.2 (-), R804.1, R806.2
unnamed: AMP801.5 (+), C805.2, R807.1
unnamed: AMP801.6 (-), R810.1, R812.1
unnamed: AMP901.1, R902.1, R906.1
unnamed: AMP901.7, R908.2, R912.2
unnamed: AMP901.3 (+), C902.2, R901.2
unnamed: AMP901.2 (-), R904.1, R906.2
unnamed: AMP901.5 (+), C905.2, R907.1
unnamed: AMP901.6 (-), R910.1, R912.1
unnamed: AMP1001.1, R1002.1, R1006.1
unnamed: AMP1001.7, R1008.2, R1012.2
unnamed: AMP1001.3 (+), C1002.2, R1001.2
unnamed: AMP1001.2 (-), R1004.1, R1006.2
unnamed: AMP1001.5 (+), C1005.2, R1007.1
unnamed: AMP1001.6 (-), R1010.1, R1012.1
unnamed: AMP1101.1, R1102.1, R1106.1
unnamed: AMP1101.7, R1108.2, R1112.2
unnamed: AMP1101.3 (+), C1102.2, R1101.2
unnamed: AMP1101.2 (-), R1104.1, R1106.2
unnamed: AMP1101.5 (+), C1105.2, R1107.1
unnamed: AMP1101.6 (-), R1110.1, R1112.1
unnamed: AMP1201.1, R1202.1, R1206.1
unnamed: AMP1201.7, R1208.2, R1212.2
unnamed: AMP1201.3 (+), C1202.2, R1201.2
unnamed: AMP1201.2 (-), R1204.1, R1206.2
unnamed: AMP1201.5 (+), C1205.2, R1207.1
unnamed: AMP1201.6 (-), R1210.1, R1212.1
unnamed: AMP1301.1, R1302.1, R1306.1
unnamed: AMP1301.7, R1308.2, R1312.2
unnamed: AMP1301.3 (+), C1302.2, R1301.2
unnamed: AMP1301.2 (-), R1304.1, R1306.2
unnamed: AMP1301.5 (+), C1305.2, R1307.1
unnamed: AMP1301.6 (-), R1310.1, R1312.1
unnamed: C701.1, R702.2
unnamed: C704.2, R708.1
unnamed: C801.1, R802.2
unnamed: C804.2, R808.1
unnamed: C901.1, R902.2
unnamed: C904.2, R908.1
unnamed: C1001.1, R1002.2
unnamed: C1004.2, R1008.1
unnamed: C1101.1, R1102.2
unnamed: C1104.2, R1108.1
unnamed: C1201.1, R1202.2
unnamed: C1204.2, R1208.1
unnamed: C1301.1, R1302.2
unnamed: C1304.2, R1308.1

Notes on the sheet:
AmpBank / AmpChannel - one channel, instantiated x10. SW selects this channel's input AND output. Supply is always on. GAIN = 1 + Rf/Rg (default 20k/20k = 2)

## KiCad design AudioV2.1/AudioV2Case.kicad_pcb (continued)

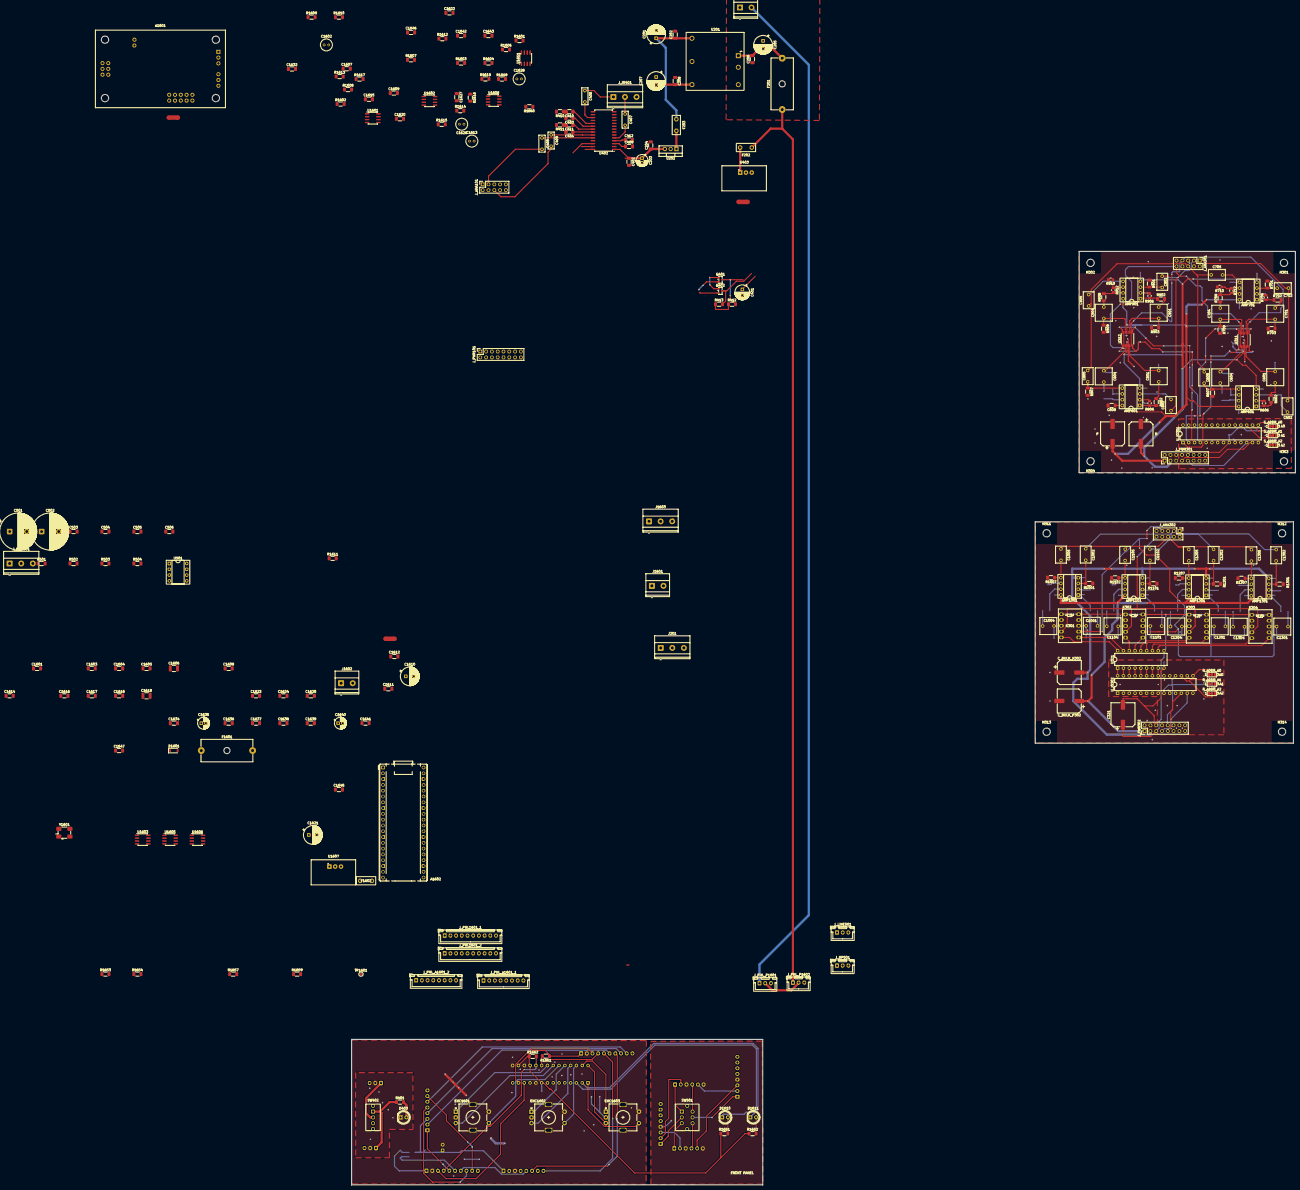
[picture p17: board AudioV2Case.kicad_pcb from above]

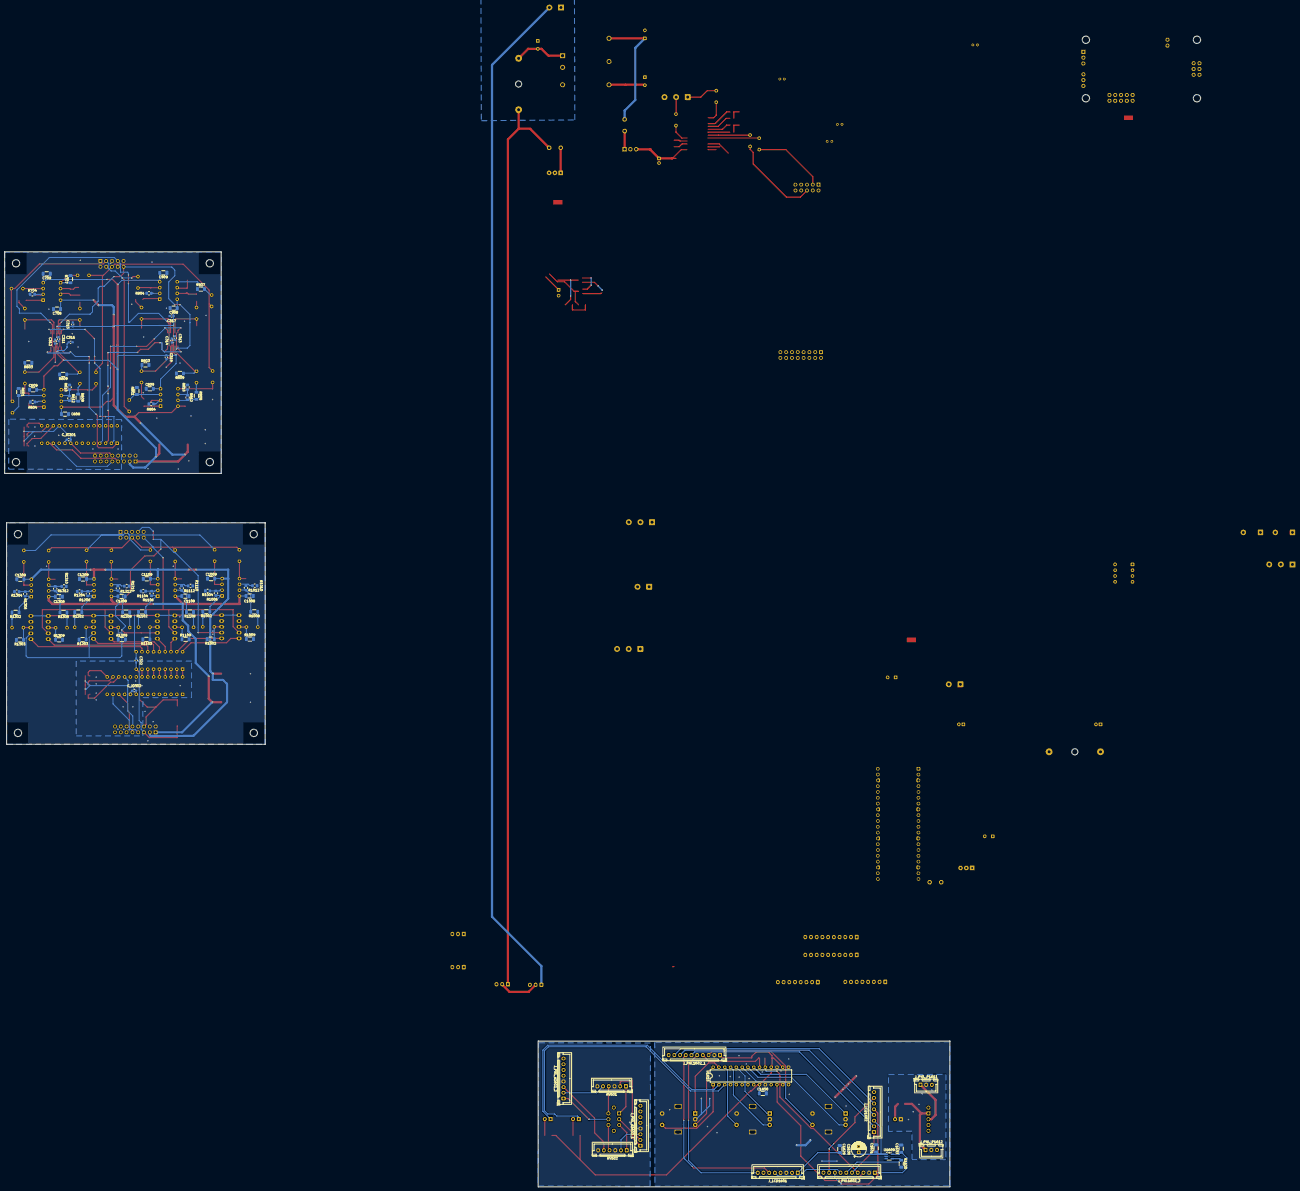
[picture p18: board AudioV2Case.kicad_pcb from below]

Board: 2 copper layers, 355 parts (94 on the bottom side), 225 nets.

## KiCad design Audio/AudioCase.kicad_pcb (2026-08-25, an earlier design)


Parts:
J1: PD給電; TerminalBlock_Phoenix_MKDS-1,5-2-5.08_1x02_P5.08mm_Horizont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
J2: 入力ジャック; TerminalBlock_Phoenix_MKDS-1,5-2-5.08_1x02_P5.08mm_Horizont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
J3: 出力ジャック; TerminalBlock_Phoenix_MKDS-1,5-2-5.08_1x02_P5.08mm_Horizont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

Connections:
unnamed: J2.G, J3.G

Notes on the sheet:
MeasurementADC: ADC_V_IN+ADC_GND_IN=raw PD pair. AUDIO from Amp L/R_OUT. +/-15V_A from PowerModule.


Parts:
C6, C8, C10, C13: 0.047μF; C_Rect_L7.2mm_W3.5mm_P5.00mm_FKS2_FKP2_MKS2_MKP2
C7, C11, C12, C16: 0.01uF; C_Rect_L7.2mm_W3.0mm_P5.00mm_FKS2_FKP2_MKS2_MKP2
C9, C14, C15, C17: 2200pF; C_Rect_L7.2mm_W4.5mm_P5.00mm_FKS2_FKP2_MKS2_MKP2
C18, C20, C22, C23, C24, C25, C26, C27: 0.1μF; C_1206_3216Metric_Pad1.33x1.80mm_HandSolder
C19, C21: 10μF; CP_Radial_D5.0mm_P2.00mm
H5, H6, H7, H8: MountingHole; MountingHole_3.2mm_M3
J6: AUX_IN; TerminalBlock_Phoenix_MKDS-1,5-2-5.08_1x02_P5.08mm_Horizont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
J7: V_IN; TerminalBlock_Phoenix_MKDS-1,5-3-5.08_1x03_P5.08mm_Horizont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
J8: AUX_OUT; TerminalBlock_Phoenix_MKDS-1,5-3-5.08_1x03_P5.08mm_Horizont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
R1, R2, R3, R4, R5, R6, R7, R8, R9, R10, R11, R12: 10K; R_1206_3216Metric_Pad1.30x1.75mm_HandSolder
R13, R14: 0Ω; R_1206_3216Metric_Pad1.30x1.75mm_HandSolder
R15, R16: 47kΩ; R_1206_3216Metric_Pad1.30x1.75mm_HandSolder
R17, R18: 47Ω; R_1206_3216Metric_Pad1.30x1.75mm_HandSolder
R19, R20: 10KΩ; R_1206_3216Metric_Pad1.30x1.75mm_HandSolder
R21, R22, R23, R24: 22KΩ; R_1206_3216Metric_Pad1.30x1.75mm_HandSolder
RV1, RV2, RV3: B100k_Dual; Potentiometer_Alps_RK097_Dual_Horizontal
U2, U3, U4: NJM4558; DIP-8_W7.62mm_Socket

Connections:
/Controll/AMP_V+_IN: C22.1, C24.1, C26.1, J7.1, U2.8 (V+), U3.8 (V+), U4.8 (V+); also elsewhere on the board
/Controll/AMP_V-_IN: C23.2, C25.2, C27.2, J7.3, U2.4 (V-), U3.4 (V-), U4.4 (V-); also elsewhere on the board
/Controll/L_IN: J8.1, R24.1, U4.7; also elsewhere on the board
/Controll/R_IN: J8.3, R23.1, U4.1; also elsewhere on the board
/EQModule/L_BAX_SUM: R8.2, R9.2, R12.2, R20.2, U3.6 (-)
/EQModule/L_BUFF: R6.2, R7.2, R11.2, R17.1
/EQModule/L_BUFF_IN: C20.1, C21.1, R16.1, U2.3 (+)
/EQModule/L_IN: C20.2, C21.2, J6.2
/EQModule/R_BAX_SUM: R3.2, R4.2, R10.2, R19.2, U3.2 (-)
/EQModule/R_BUFF: R1.1, R2.1, R5.1, R18.1
/EQModule/R_BUFF_IN: C18.1, C19.1, R15.1, U2.5 (+)
/EQModule/R_IN: C18.2, C19.2, J6.1
GND: C22.2, C23.1, C24.2, C25.1, C26.2, C27.1, J7.2, J8.2, R15.2, R16.2, U3.3 (+), U3.5 (+), U4.3 (+), U4.5 (+); also elsewhere on the board
unnamed: C6.1, R1.2, RV1.1
unnamed: C6.2, C8.1, R3.1, RV1.2
unnamed: C7.1, R2.2, RV2.1
unnamed: C8.2, RV1.3
unnamed: C9.1, R5.2, RV3.1
unnamed: C10.1, C13.2, R8.1, RV1.5
unnamed: C10.2, R6.1, RV1.4
unnamed: C7.2, C11.1, R4.1, RV2.2
unnamed: C11.2, RV2.3
unnamed: C12.1, C16.1, R9.1, RV2.5
unnamed: C12.2, R7.1, RV2.4
unnamed: C13.1, RV1.6
unnamed: C9.2, C14.1, R10.1, RV3.2
unnamed: C14.2, RV3.3
unnamed: C15.1, C17.1, R12.1, RV3.5
unnamed: C15.2, R11.1, RV3.4
unnamed: C16.2, RV2.6
unnamed: C17.2, RV3.6
unnamed: R13.1, R17.2, U2.1
unnamed: R14.1, R18.2, U2.7
unnamed: R19.1, R21.2, U3.1
unnamed: R20.1, R22.2, U3.7
unnamed: R13.2, U2.2 (-)
unnamed: R14.2, U2.6 (-)
unnamed: R21.1, R23.2, U4.2 (-)
unnamed: R22.1, R24.2, U4.6 (-)


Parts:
AMP1: NE5532; DIP-8_W7.62mm_Socket
C28, C29, C30, C32: 0.1μF; C_1206_3216Metric_Pad1.33x1.80mm_HandSolder
C31, C33: 10μF; CP_Radial_D5.0mm_P2.00mm
C34, C35: 470μF; CP_Radial_D16.0mm_P7.50mm
H9, H10, H11, H12: MountingHole; MountingHole_3.2mm_M3
J9: AMP_PWR; TerminalBlock_Phoenix_MKDS-1,5-3-5.08_1x03_P5.08mm_Horizont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
J10: AMP_AUX_IN; TerminalBlock_Phoenix_MKDS-1,5-2-5.08_1x02_P5.08mm_Horizont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
J11: AMP_AUX_OUT; TerminalBlock_Phoenix_MKDS-1,5-2-5.08_1x02_P5.08mm_Horizont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
R25, R26: 220KΩ; R_1206_3216Metric_Pad1.30x1.75mm_HandSolder
R27, R28, R29, R30: 10KΩ; R_1206_3216Metric_Pad1.30x1.75mm_HandSolder
R31, R32: 47KΩ; R_1206_3216Metric_Pad1.30x1.75mm_HandSolder
R33, R34: 47Ω; R_1206_3216Metric_Pad1.30x1.75mm_HandSolder

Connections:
/AmpModule/L_IN: C32.2, C33.2, J10.2, R26.1
/AmpModule/R_IN: C30.2, C31.2, J10.1, R25.1
/AmpModule/V+_IN: AMP1.8 (V+), C28.2, J9.1
/AmpModule/V-_IN: AMP1.4 (V-), C29.1, J9.3
/MeasurementADC/AUDIO_L_IN: C35.2, J11.1; also elsewhere on the board
/MeasurementADC/AUDIO_R_IN: C34.2, J11.2; also elsewhere on the board
GND: C28.1, C29.2, J9.2, R25.2, R26.2, R27.1, R28.1, R29.2, R30.1; also elsewhere on the board
unnamed: AMP1.1, R31.2, R33.1
unnamed: AMP1.7, R32.2, R34.1
unnamed: AMP1.3 (+), C30.1, C31.1, R29.1
unnamed: AMP1.2 (-), R27.2, R31.1
unnamed: AMP1.5 (+), C32.1, C33.1, R28.2
unnamed: AMP1.6 (-), R30.2, R32.1
unnamed: C34.1, R33.2
unnamed: C35.1, R34.2



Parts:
A701: ADC1804_F_MODULE; ADC1804_F_KYOHRITSU_56x33mm
A702: Pico2; RaspberryPi_Pico_Common_THT
C701, C702, C705, C706, C711, C712, C717, C718, C719, C720, C721, C722, C725, C727, C729, C730, C733, C740, C741, C743: 100nF; C_1206_3216Metric_Pad1.33x1.80mm_HandSolder
C703, C704: 10uF 50V; CP_Radial_D5.0mm_P2.00mm
C707, C708, C709, C710: 10uF 25V NP; C_Radial_D5.0mm_H7.0mm_P2.00mm
C713, C714, C715, C716: 1.8nF C0G; C_1206_3216Metric_Pad1.33x1.80mm_HandSolder
C723: 47uF 35V; CP_Radial_D8.0mm_P3.50mm
C724, C728, C739: 10uF; C_1206_3216Metric_Pad1.33x1.80mm_HandSolder
C726: 47uF; CP_Radial_D8.0mm_P3.50mm
C731, C732, C738: 10uF 16V X7R; C_1206_3216Metric_Pad1.33x1.80mm_HandSolder
C734: 22uF; CP_Radial_D6.3mm_P2.50mm
C735, C736, C742: 10nF; C_1206_3216Metric_Pad1.33x1.80mm_HandSolder
C737: 10uF 10V X7R; C_1206_3216Metric_Pad1.33x1.80mm_HandSolder
D701: RB160M-30; D_SOD-123
F701: Fuse; R_Axial_DIN0411_L9.9mm_D3.6mm_P12.70mm_Horizontal
J701: AUDIO; TerminalBlock_Phoenix_MKDS-1,5-2-5.08_1x02_P5.08mm_Horizont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
J702: V_IN; TerminalBlock_Phoenix_MKDS-1,5-2-5.08_1x02_P5.08mm_Horizont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
J703: 15_V_IN; TerminalBlock_Phoenix_MKDS-1,5-3-5.08_1x03_P5.08mm_Horizont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
LCDDisplay701: WAVESHARE-29318; PinHeader_1x15_P2.54mm_Vertical
NT701: A_GND-ADC_GND; NetTie-2_SMD_Pad2.0mm
NT702: ADC_GND_IN-D_GND; NetTie-2_SMD_Pad2.0mm
R701, R702, R703, R704: 4.7k 0.1%; R_1206_3216Metric_Pad1.30x1.75mm_HandSolder
R705, R706, R707, R708: 3.3k 0.1%; R_1206_3216Metric_Pad1.30x1.75mm_HandSolder
R709, R710, R711, R712: 1k 0.1%; R_1206_3216Metric_Pad1.30x1.75mm_HandSolder
R713, R714, R715, R716: 47; R_1206_3216Metric_Pad1.30x1.75mm_HandSolder
R717: 100k; R_1206_3216Metric_Pad1.30x1.75mm_HandSolder
R718: 33; R_1206_3216Metric_Pad1.30x1.75mm_HandSolder
R719: 10k; R_1206_3216Metric_Pad1.30x1.75mm_HandSolder
R720: 1k; R_1206_3216Metric_Pad1.30x1.75mm_HandSolder
TP701: ADC_MCLK; TestPoint_Pad_D1.5mm
U701, U702, U703: OPA1656; SOIC-8_3.9x4.9mm_P1.27mm
U704: BP5293-50; BP5293-50_ROHM_SIP-3
U705: MBC2596-01; MBC2596-01_TAEJIN_43x21mm
U706: LT1763-3.3; SOIC-8_3.9x4.9mm_P1.27mm
U707: LT1763-5; SOIC-8_3.9x4.9mm_P1.27mm
U708: XC8107AC20MR-G; SOT-23-5_HandSoldering
U709: TPS3307-33; SOIC-8_3.9x4.9mm_P1.27mm
Y701: ASFL1-12.288MHZ-EC-T; Oscillator_SMD_Abracon_ASFL-4Pin_5.0x3.2mm_HandSoldering

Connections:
/Controll/+15_IN: C723.1, C724.1, C725.1, F701.2, U704.1 (VIN), U705.1 (IN+); also elsewhere on the board
/Controll/AMP_V+_IN: C701.1, C703.1, C705.1, C711.1, C717.1, J703.3, U701.8 (V+), U702.8 (V+), U703.8 (V+); also elsewhere on the board
/Controll/AMP_V-_IN: C702.2, C704.2, C706.2, C712.2, C718.2, J703.1, U701.4 (V-), U702.4 (V-), U703.4 (V-); also elsewhere on the board
/MeasurementADC/+3V3_A: A701.13 (+3V3), C722.2, C737.1, C740.1, C742.2, C743.1, R719.1, U706.1 (OUT), U706.2 (SENSE), U707.5 (SHDN), U709.2 (SENSE2), U709.3 (SENSE3), U709.8 (VDD), Y701.1 (ST), Y701.4 (VDD)
/MeasurementADC/+5V_A: A701.12 (+5V), C721.1, C738.1, C741.1, U707.1 (OUT), U707.2 (SENSE), U709.1 (SENSE1)
/MeasurementADC/+5V_D: C726.1, C727.1, C728.1, D701.2 (A), U704.3 (VOUT), U708.5 (VIN)
/MeasurementADC/ADC_BCK: A701.9 (BCK), A702.2 (GPIO1)
/MeasurementADC/ADC_DATA: A701.10 (DATA), A702.1 (GPIO0)
/MeasurementADC/ADC_GND: A701.14 (GND), C719.1, C720.1, C721.2, C722.1, C729.2, C730.2, C731.2, C732.2, C735.2, C736.2, C737.2, C738.2, C740.2, C741.2, C742.1, C743.2, NT701.1, U705.4 (OUT-), U706.3 (GND), U706.6 (GND), U706.7 (GND), U707.3 (GND), U707.6 (GND), U707.7 (GND), U709.4 (GND), Y701.2 (GND)
/MeasurementADC/ADC_GND_IN: C723.2, C724.2, C725.2, J702.2, NT702.1, U704.2 (GND), U705.2 (IN-); also elsewhere on the board
/MeasurementADC/ADC_LRCK: A701.8 (LRCK), A702.4 (GPIO2)
/MeasurementADC/ADC_MCLK: A701.7 (SCKI), R718.2, R720.1, TP701.1 (1_1)
/MeasurementADC/ADC_nMR: A702.20 (GPIO15), U709.7 (~MR)
/MeasurementADC/ADC_nRST: A701.11 (RST), R719.2, U709.5 (~RESET)
/MeasurementADC/AUDIO_L_IN: C708.2, J701.2, R701.2; also elsewhere on the board
/MeasurementADC/AUDIO_R_IN: C710.2, J701.1, R702.2; also elsewhere on the board
/MeasurementADC/D_GND: A702.3 (GND), A702.8 (GND), A702.13 (GND), A702.18 (GND), A702.23 (GND), A702.28 (GND), A702.38 (GND), C726.2, C727.2, C728.2, C733.1, C734.2, C739.2, LCDDisplay701.3 (GND), NT702.2, R717.2, U708.2 (VSS)
/MeasurementADC/LCD_CS: A702.7 (GPIO5), LCDDisplay701.8 (LCD_CS)
/MeasurementADC/LCD_DC: A702.9 (GPIO6), LCDDisplay701.9 (LCD_DC)
/MeasurementADC/LCD_EN: A702.11 (GPIO8), R717.1, U708.4 (CE)
/MeasurementADC/LCD_MOSI: A702.25 (GPIO19), LCDDisplay701.5 (MOSI)
/MeasurementADC/LCD_RST: A702.10 (GPIO7), LCDDisplay701.10 (LCD_RST)
/MeasurementADC/LCD_SCK: A702.24 (GPIO18), LCDDisplay701.6 (SCLK)
/MeasurementADC/LCD_VCC: C733.2, C734.1, C739.1, LCDDisplay701.1 (VCC), LCDDisplay701.11 (LCD_BL), U708.1 (VOUT)
/MeasurementADC/MCLK_SENSE: A702.12 (GPIO9), R720.2
/MeasurementADC/PICO_3V3: A702.30 (RUN), A702.35 (ADC_VREF), A702.36 (3V3), A702.37 (3V3_EN)
/MeasurementADC/TP_INT: A702.16 (GPIO12), LCDDisplay701.14 (TP_INT)
/MeasurementADC/TP_RST: A702.17 (GPIO13), LCDDisplay701.15 (TP_RST)
/MeasurementADC/TP_SCL: A702.15 (GPIO11), LCDDisplay701.13 (TP_SCL)
/MeasurementADC/TP_SDA: A702.14 (GPIO10), LCDDisplay701.12 (TP_SDA)
/MeasurementADC/VCOML: A701.2 (VCOML), C719.2, U703.3 (INA+), U703.5 (INB+)
/MeasurementADC/VCOMR: A701.5 (VCOMR), C720.2, U702.3 (INA+), U702.5 (INB+)
/MeasurementADC/VINL+: A701.1 (VINL+), R716.1
/MeasurementADC/VINL-: A701.3 (VINL-), R715.1
/MeasurementADC/VINR+: A701.6 (VINR+), R714.1
/MeasurementADC/VINR-: A701.4 (VINR-), R713.1
GND: C701.2, C702.1, C703.2, C704.1, C705.2, C706.1, C711.2, C712.1, C717.2, C718.1, J703.2, NT701.2, U701.3 (INA+), U701.5 (INB+); also elsewhere on the board
unnamed: A702.39 (VSYS), D701.1 (K)
unnamed: C707.1, R705.2
unnamed: C708.1, R706.2
unnamed: C709.1, R707.2
unnamed: C710.1, R708.2
unnamed: F701.1, J702.1
unnamed: R702.1, R704.2, U701.2 (INA-)
unnamed: C709.2, R704.1, U701.1 (OUTA)
unnamed: R701.1, R703.2, U701.6 (INB-)
unnamed: C707.2, R703.1, U701.7 (OUTB)
unnamed: C713.2, R707.1, R709.2, U702.2 (INA-)
unnamed: C713.1, R709.1, R713.2, U702.1 (OUTA)
unnamed: C714.2, R708.1, R710.2, U702.6 (INB-)
unnamed: C714.1, R710.1, R714.2, U702.7 (OUTB)
unnamed: C715.2, R705.1, R711.2, U703.2 (INA-)
unnamed: C715.1, R711.1, R715.2, U703.1 (OUTA)
unnamed: C716.2, R706.1, R712.2, U703.6 (INB-)
unnamed: C716.1, R712.1, R716.2, U703.7 (OUTB)
unnamed: C729.1, C730.1, C731.1, C732.1, U705.3 (OUT+), U706.5 (SHDN), U706.8 (IN), U707.8 (IN)
unnamed: C735.1, U706.4 (BYP)
unnamed: C736.1, U707.4 (BYP)
unnamed: R718.1, Y701.3 (OUT)

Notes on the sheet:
ADC1804_F には PCM1804 のデカップリングとジャンパが内蔵済み。本シートは外部コネクタのみをモデル化。
ADC1804_F モジュール / デジタル・インターフェース
PWRWIRE_V2
ADC_V_IN ├─ BP5293-50 → +5V_D（Pico/LCD） └─ MBC2596 → ~6.6V ├─ LT1763-5 → +5V_A （ADC） └─ LT1763-3.3 → +3V3_A （ADC）
POWER/DIGITAL: ADC_VIN->U705(MBC2596 6.6-6.8V)->U706(+3V3_A) then U707(+5V_A EN=+3V3_A). U704=+5V_D; D701 Schottky +5V_D->VSYS so USB cannot backfeed +5V_D. Y701 ASFL1->R718->ADC_MCLK (TP701; R720 1k to GP9 sense). U709 TPS3307-33D SO-8 watches +5V_A/+3V3_A, ~RESET->ADC_nRST (PP, 200ms), GP15 OD ->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
GP9=MCLK_SENSE は R720 1k 経由の入力専用。出力にすると Y701 と衝突して SCKI が化ける。
A3 Pico2 横置き: 南列 1-20 西→東 / 北列 21-40 東→西。VSYS=+5V_D via D701 ショットキ, GND=D_GND | GP0=ADC_DATA GP1=ADC_BCK GP2=ADC_LRCK | GP3/GP4=NC(旧 LCD SPI) | GP5=LCD_CS GP6=LCD_DC GP7=LCD_RST GP8=LCD_EN | GP9=MCLK_SENSE (R720 1k, 入力専用) | GP10=TP_SDA GP11=TP_SCL GP12=TP_INT GP13=TP_RST | GP15=ADC_nMR (TPS3307 ~MR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
LRCK/BCK の向きは ADC マスタモード想定。スレーブ時は階層ピンの方向を合わせて変更すること。
OPA1656 の各電源ペアに 100nF を配置。バルクコンデンサはアナログフロントエンドの電源入口付近に。
U707 EN=+3V3_A (3V3-first). AbsMax VCC-VDD protection.
PATCH_V1
GND: NT702=A_GND─ADC_GND（A701近傍・アナログ星点）。NT701=ADC_GND_IN─D_GND（PD入口）。Pico/LCD は D_GND のみ。D_GND は太く短く、アナログ入力から離す。計測経路は PD 基準（非絶縁完成）。
U709=TPS3307-33D SO-8: SENSE1=+5V_A (4.55V) SENSE2=+3V3_A (2.93V) SENSE3=VDD; VDD=+3V3_A C745 100nF; ~RESET PP -> ADC_nRST + R719; GP15 OD -> ~MR (do not drive H); RESET pin NC; 200ms delay. Replaces TPS3808G33/G50 SOT-23-6.
チャンネルあたりの公式リファレンス構成: 入力インバータ + ADC VCOM 基準の反転 LPF ドライバ×2。
OPA2134 からの OPA1656 置き換え。3.3k/4.7k 網では FET 入力が有利。試作で安定性とフルスケール・レベルを確認すること。
左チャンネル
PATCH_V2
JP1F: ショート=H / 開放=L。本設計は S/M=L, OSR2=L OSR1=H OSR0=H（ADCマスタ 48k/256fs）、24bit I²S → FMT1=L（開放）FMT0=H（ショート）。HPF はモジュールマニュアルに従う。
U706 LT1763-3.3 (+3V3_A). Fixed LDO; SHDN tied for always-on or as designed. Local CIN/COUT.
FE_PATCH_V1
電源: USB VBUS → Pico 内部ショットキ → VSYS。D701 が +5V_D への逆流を止めるので、USB だけ挿すと Pico は動き LCD は消える。VBUS(pin40) は NC。
U708 XC8107AC20MR-G ロードスイッチ: LCD_EN High=ON / Low・Hi-Z=OFF（Active High, VCEH 1.5V min → Pico 3.3V で直接駆動可）。R717 100k=CE プルダウンで起動時 OFF。初号は常時 ON 可。OFF 運用時は SPI/タッチを Low/Hi-Z に。ソフトスタート 0.6ms typ・短絡/逆流/過熱/UVLO 保護内蔵。C740=CIN, C739=CL は各 10uF/3216 を IC 直近へ。FLG は未使用（NC）。
GP15=ADC_nMR は TPS3307 の ~MR。オープンドレインのみ、H は駆動しない。 ~RESET はプッシュプルなので ADC_nRST には直接ワイヤ AND しない。
階層ポート / 右チャンネル

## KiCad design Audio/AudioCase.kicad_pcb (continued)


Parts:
C1: 47μF; CP_Radial_D8.0mm_P3.50mm
C2, C3: 4.7μF; CP_Radial_D5.0mm_P2.00mm
C4, C5: 0.1μF; C_1206_3216Metric_Pad1.33x1.80mm_HandSolder
F1: 1A; R_Axial_DIN0411_L9.9mm_D3.6mm_P12.70mm_Horizontal
H1, H2, H3, H4: MountingHole; MountingHole_3.2mm_M3
J4: PWR_IN; TerminalBlock_Phoenix_MKDS-1,5-2_1x02_P5.00mm_Horizontal
J5: PWR_OUT; TerminalBlock_Phoenix_MKDS-1,5-3-5.08_1x03_P5.08mm_Horizont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
L1, L2: L; L_12x12mm_H8mm
U1: MCW03; MCW03-12D15_SIP7_THT

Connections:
/Controll/+15_IN: F1.1, J4.2; also elsewhere on the board
/Controll/AMP_V+_IN: C2.1, C4.1, J5.1, L1.1; also elsewhere on the board
/Controll/AMP_V-_IN: C3.2, C5.2, J5.3, L2.2; also elsewhere on the board
/MeasurementADC/ADC_GND_IN: C1.2, J4.1, U1.1 (GND); also elsewhere on the board
GND: C2.2, C3.1, C4.2, C5.1, J5.2, U1.7 (Common); also elsewhere on the board
unnamed: C1.1, F1.2, U1.2 (+Vin)
unnamed: L1.2, U1.6 (+Vout)
unnamed: L2.1, U1.8 (-Vout)


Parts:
A1: RaspberryPi_Pico; RaspberryPi_Pico_Common_Unspecified
C36: 47μF; CP_Radial_D8.0mm_P3.50mm
C37, C40: 0.1μF; C_Disc_D5.0mm_W2.5mm_P2.50mm
C38, C41, C42, C43: 0.1μF; C_1206_3216Metric_Pad1.33x1.80mm_HandSolder
C39: 100μF; CP_Radial_D6.3mm_P2.50mm
F2: 1A; R_Axial_DIN0411_L9.9mm_D3.6mm_P12.70mm_Horizontal
H13, H14, H15, H16: MountingHole; MountingHole_3.2mm_M3
J12: AMP1_PWR; TerminalBlock_Phoenix_MKDS-1,5-2-5.08_1x02_P5.08mm_Horizont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
J13: ROTARY_SW; PinHeader_1x05_P2.54mm_Vertical
J14: AMP_PWR_IN; TerminalBlock_Phoenix_MKDS-1,5-2-5.08_1x02_P5.08mm_Horizont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
J15: PD_IN; TerminalBlock_Phoenix_MKDS-1,5-2-5.08_1x02_P5.08mm_Horizont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
J16: AUDIO_IN; TerminalBlock_Phoenix_MKDS-1,5-2-5.08_1x02_P5.08mm_Horizont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
J17: OLED_PIN; PinHeader_1x04_P2.54mm_Vertical
J18: AMP1_LR; TerminalBlock_Phoenix_MKDS-1,5-2-5.08_1x02_P5.08mm_Horizont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
J19: AMP2_PWR; TerminalBlock_Phoenix_MKDS-1,5-2-5.08_1x02_P5.08mm_Horizont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
J20: AMP2_LR; TerminalBlock_Phoenix_MKDS-1,5-2-5.08_1x02_P5.08mm_Horizont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
J21: AMP3_PWR; TerminalBlock_Phoenix_MKDS-1,5-2-5.08_1x02_P5.08mm_Horizont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
J22: AMP4_PWR; TerminalBlock_Phoenix_MKDS-1,5-2-5.08_1x02_P5.08mm_Horizont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
J23: AMP5_PWR; TerminalBlock_Phoenix_MKDS-1,5-2-5.08_1x02_P5.08mm_Horizont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
J24: AMP3_LR; TerminalBlock_Phoenix_MKDS-1,5-2-5.08_1x02_P5.08mm_Horizont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
J25: AMP4_LR; TerminalBlock_Phoenix_MKDS-1,5-2-5.08_1x02_P5.08mm_Horizont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
J26: AMP5_LR; TerminalBlock_Phoenix_MKDS-1,5-2-5.08_1x02_P5.08mm_Horizont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
K1, K2, K3, K4, K5, K6, K7, K8, K9, K10: AZ850P2-x; Relay_DPDT_FRT5
NT1: NetTie_2; NetTie-2_THT_Pad1.0mm
NT2, NT3, NT4, NT5, NT6, NT7, NT8, NT9, NT10, NT11, NT12, NT13, NT14, NT15, NT16, NT17, NT18, NT19, NT20, NT21: NetTie_2
U5: BP5293-50; BP5293-50_ROHM_SIP-3
U6, U7, U8: ULN2803A; ULN2803A_DIP-18_W7.62mm

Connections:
/Controll/3V3: A1.36 (3V3), J13.4, J17.2
/Controll/5V_+: A1.39 (VSYS), C38.2, C39.1, C40.1, C41.2, C42.2, C43.2, K1.1, K1.10, K2.1, K2.10, K3.1, K3.10, K4.1, K4.10, K5.1, K5.10, K6.1, K6.10, K7.1, K7.10, K8.1, K8.10, K9.1, K9.10, K10.1, K10.10, U5.3 (VOUT), U6.10 (COM), U7.10 (COM), U8.10 (COM)
/Controll/+15_IN: F2.1, J15.2; also elsewhere on the board
/Controll/AMP_1_L_OUT: J18.1, K2.7, NT14.2
/Controll/AMP_1_R_OUT: J18.2, K2.4, NT18.2
/Controll/AMP_1_V+_OUT: J12.1, K1.7, NT6.2
/Controll/AMP_1_V-_OUT: J12.2, K1.4, NT10.2
/Controll/AMP_2_L_OUT: J20.1, K4.7, NT15.2
/Controll/AMP_2_R_OUT: J20.2, K4.4, NT19.2
/Controll/AMP_2_V+_OUT: J19.1, K3.7, NT7.2
/Controll/AMP_2_V-_OUT: J19.2, K3.4, NT11.2
/Controll/AMP_3_L_OUT: J24.1, K8.7, NT4.2
/Controll/AMP_3_R_OUT: J24.2, K8.4, NT5.2
/Controll/AMP_3_V+_OUT: J21.1, K5.7, NT2.2
/Controll/AMP_3_V-_OUT: J21.2, K5.4, NT3.2
/Controll/AMP_4_L_OUT: J25.1, K9.7, NT16.2
/Controll/AMP_4_R_OUT: J25.2, K9.4, NT20.2
/Controll/AMP_4_V+_OUT: J22.1, K6.7, NT8.2
/Controll/AMP_4_V-_OUT: J22.2, K6.4, NT12.2
/Controll/AMP_5_L_OUT: J26.1, K10.7, NT17.2
/Controll/AMP_5_R_OUT: J26.2, K10.4, NT21.2
/Controll/AMP_5_V+_OUT: J23.1, K7.7, NT9.2
/Controll/AMP_5_V-_OUT: J23.2, K7.4, NT13.2
/Controll/AMP_V+_IN: J14.1, K1.8, K3.8, K5.8, K6.8, K7.8; also elsewhere on the board
/Controll/AMP_V-_IN: J14.2, K1.3, K3.3, K5.3, K6.3, K7.3; also elsewhere on the board
/Controll/AUDIO_RESET_GPIO_1: A1.2 (GPIO1), U6.7 (I7)
/Controll/AUDIO_RESET_GPIO_2: A1.7 (GPIO5), U6.3 (I3)
/Controll/AUDIO_RESET_GPIO_3: A1.12 (GPIO9), U7.7 (I7)
/Controll/AUDIO_RESET_GPIO_4: A1.17 (GPIO13), U7.3 (I3)
/Controll/AUDIO_RESET_GPIO_5: A1.24 (GPIO18), U8.1 (I1)
/Controll/AUDIO_RESET_RELAY_1: K2.6, U6.18 (O1)
/Controll/AUDIO_RESET_RELAY_2: K4.6, U6.14 (O5)
/Controll/AUDIO_RESET_RELAY_3: K8.6, U7.12 (O7)
/Controll/AUDIO_RESET_RELAY_4: K9.6, U7.16 (O3)
/Controll/AUDIO_RESET_RELAY_5: K10.6, U8.18 (O1)
/Controll/AUDIO_SET_GPIO_1: A1.1 (GPIO0), U6.8 (I8)
/Controll/AUDIO_SET_GPIO_2: A1.6 (GPIO4), U6.4 (I4)
/Controll/AUDIO_SET_GPIO_3: A1.11 (GPIO8), U7.8 (I8)
/Controll/AUDIO_SET_GPIO_4: A1.16 (GPIO12), U7.4 (I4)
/Controll/AUDIO_SET_GPIO_5: A1.25 (GPIO19), U8.2 (I2)
/Controll/AUDIO_SET_RELAY_1: K2.5, U6.17 (O2)
/Controll/AUDIO_SET_RELAY_2: K4.5, U6.13 (O6)
/Controll/AUDIO_SET_RELAY_3: K8.5, U7.11 (O8)
/Controll/AUDIO_SET_RELAY_4: K9.5, U7.15 (O4)
/Controll/AUDIO_SET_RELAY_5: K10.5, U8.17 (O2)
/Controll/CTRL_GND: A1.3 (GND), A1.8 (GND), A1.13 (GND), A1.18 (GND), A1.23 (GND), A1.28 (GND), A1.38 (GND), C36.2, C37.2, C38.1, C39.2, C40.2, C41.1, C42.1, C43.1, J13.5, J17.1, NT1.2, U5.2 (GND), U6.9 (GND), U7.9 (GND), U8.5 (I5), U8.6 (I6), U8.7 (I7), U8.8 (I8), U8.9 (GND)
/Controll/ENC_A: A1.29 (GPIO22), J13.1
/Controll/ENC_B: A1.31 (GPIO26_ADC0), J13.2
/Controll/ENC_SW: A1.32 (GPIO27_ADC1), J13.3
/Controll/L_IN: J16.2, K2.8, K4.8, K8.8, K9.8, K10.8; also elsewhere on the board
/Controll/PWR_RESET_GPIO_1: A1.5 (GPIO3), U6.5 (I5)
/Controll/PWR_RESET_GPIO_2: A1.10 (GPIO7), U6.1 (I1)
/Controll/PWR_RESET_GPIO_3: A1.15 (GPIO11), U7.5 (I5)
/Controll/PWR_RESET_GPIO_4: A1.20 (GPIO15), U7.1 (I1)
/Controll/PWR_RESET_GPIO_5: A1.21 (GPIO16), U8.3 (I3)
/Controll/PWR_RESET_RELAY_1: K1.6, U6.16 (O3)
/Controll/PWR_RESET_RELAY_2: K3.6, U6.12 (O7)
/Controll/PWR_RESET_RELAY_3: K5.6, U7.14 (O5)
/Controll/PWR_RESET_RELAY_4: K6.6, U7.18 (O1)
/Controll/PWR_RESET_RELAY_5: K7.6, U8.16 (O3)
/Controll/PWR_SET_GPIO_1: A1.4 (GPIO2), U6.6 (I6)
/Controll/PWR_SET_GPIO_2: A1.9 (GPIO6), U6.2 (I2)
/Controll/PWR_SET_GPIO_3: A1.14 (GPIO10), U7.6 (I6)
/Controll/PWR_SET_GPIO_4: A1.19 (GPIO14), U7.2 (I2)
/Controll/PWR_SET_GPIO_5: A1.22 (GPIO17), U8.4 (I4)
/Controll/PWR_SET_RELAY_1: K1.5, U6.15 (O4)
/Controll/PWR_SET_RELAY_2: K3.5, U6.11 (O8)
/Controll/PWR_SET_RELAY_3: K5.5, U7.13 (O6)
/Controll/PWR_SET_RELAY_4: K6.5, U7.17 (O2)
/Controll/PWR_SET_RELAY_5: K7.5, U8.15 (O4)
/Controll/R_IN: J16.1, K2.3, K4.3, K8.3, K9.3, K10.3; also elsewhere on the board
/Controll/SCL: A1.27 (GPIO21), J17.3
/Controll/SDA: A1.26 (GPIO20), J17.4
/MeasurementADC/ADC_GND_IN: J15.1, NT1.1; also elsewhere on the board
unnamed: NT2.1, NT6.1, NT7.1, NT8.1, NT9.1
unnamed: NT3.1, NT10.1, NT11.1, NT12.1, NT13.1
unnamed: NT4.1, NT14.1, NT15.1, NT16.1, NT17.1
unnamed: NT5.1, NT18.1, NT19.1, NT20.1, NT21.1
unnamed: C36.1, C37.1, F2.2, U5.1 (VIN)

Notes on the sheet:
Common bus (pre-relay): L_IN, R_IN, AMP_V+_IN, AMP_V-_IN, +15_IN, PD_GND_IN


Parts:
J29, J30: Conn_01x06_Pin; PinHeader_2x03_P2.54mm_Vertical

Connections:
unnamed: J29.1, J30.3
unnamed: J29.2, J30.2
unnamed: J29.3, J30.1
unnamed: J29.4, J30.6
unnamed: J29.5, J30.5
unnamed: J29.6, J30.4



Board: 2 copper layers, 503.2 x 164.2 mm, 236 parts (32 on the bottom side), 185 nets.

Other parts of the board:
H11#2, H11#3, H11#4, H11#5, H11#6, H11#7: MountingHole; MountingHole_3.2mm_M3

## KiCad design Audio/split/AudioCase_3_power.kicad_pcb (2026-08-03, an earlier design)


Board: 2 copper layers, 55.3 x 44.0 mm, 15 parts (0 on the bottom side), 8 nets.

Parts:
C1: 47μF; CP_Radial_D8.0mm_P3.50mm
C2, C3: 4.7μF; CP_Radial_D5.0mm_P2.00mm
C4, C5: 0.1μF; C_1206_3216Metric_Pad1.33x1.80mm_HandSolder
F1: 1A; R_Axial_DIN0411_L9.9mm_D3.6mm_P12.70mm_Horizontal
H1, H2, H3, H4: MountingHole; MountingHole_3.2mm_M3
J4: PWR_IN; TerminalBlock_Phoenix_MKDS-1,5-2_1x02_P5.00mm_Horizontal
J5: PWR_OUT; TerminalBlock_Phoenix_MKDS-1,5-3-5.08_1x03_P5.08mm_Horizont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
L1, L2: L; L_12x12mm_H8mm
U1: MCW03; MCW03-12D15_SIP7_THT

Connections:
/Controll/+15_IN: F1.1, J4.2
/Controll/AMP_V+_IN: C2.1, C4.1, J5.1, L1.1
/Controll/AMP_V-_IN: C3.2, C5.2, J5.3, L2.2
/MeasurementADC/ADC_GND_IN: C1.2, J4.1, U1.1 (GND)
GND: C2.2, C3.1, C4.2, C5.1, J5.2, U1.7 (Common)
unnamed: C1.1, F1.2, U1.2 (+Vin)
unnamed: L1.2, U1.6 (+Vout)
unnamed: L2.1, U1.8 (-Vout)

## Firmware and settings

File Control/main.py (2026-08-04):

from machine import I2C, Pin
import time

from protocol import (
    APPLY_TIMEOUT_MS,
    CMD_APPLY_MAX,
    CMD_APPLY_MIN,
    CMD_PING,
    CMD_RESET,
    I2C_FREQ,
    LOCAL_CHANNELS,
    MAX_CHANNELS,
    OLED_ADDR,
    REG_CMD,
    REG_DONE,
    REG_STATUS,
    SCL_PIN,
    SDA_PIN,
    SLAVE_ADDR,
    STATUS_OK,
    STATUS_PONG,
)
from relays import RelayBoard
from ssd1306 import SSD1306_I2C


WIDTH = 128
HEIGHT = 64
ENC_A_PIN = 22  # Pico physical pin 29
ENC_B_PIN = 26  # Pico physical pin 31
ENC_SW_PIN = 27  # Pico physical pin 32
RESET_TO_SET_SEC = 0.5
LOOP_DELAY_SEC = 0.01
BUTTON_DEBOUNCE_MS = 250


def draw_status(display, title, line1="", line2="", line3="", line4=""):
    display.fill(0)
    display.rect(0, 0, WIDTH, HEIGHT, 1)
    display.text(title[:15], 4, 4)
    display.text(line1[:15], 4, 16)
    display.text(line2[:15], 4, 28)
    display.text(line3[:15], 4, 40)
    display.text(line4[:15], 4, 52)
    display.show()


def update_display(title, line1="", line2="", line3="", line4=""):
    if oled:
        draw_status(oled, title, line1, line2, line3, line4)


def slave_done_seq():
    return i2c.readfrom_mem(SLAVE_ADDR, REG_DONE, 1)[0]


def slave_send(cmd):
    before = slave_done_seq()
    i2c.writeto_mem(SLAVE_ADDR, REG_CMD, bytes([cmd]))
    start = time.ticks_ms()
    while time.ticks_diff(time.ticks_ms(), start) < APPLY_TIMEOUT_MS:
        if slave_done_seq() != before:
            status = i2c.readfrom_mem(SLAVE_ADDR, REG_STATUS, 1)[0]
            return status in (STATUS_OK, STATUS_PONG)
        time.sleep_ms(20)
    return False


def ping_slave():
    try:
        return slave_send(CMD_PING)
    except OSError as exc:
        print("slave ping failed:", exc)
        return False


def wait_for_expansion(timeout_ms=3000):
    """Child starts I2CTarget only after its local boot reset, so retry briefly."""
    start = time.ticks_ms()
    while time.ticks_diff(time.ticks_ms(), start) < timeout_ms:
        try:
            if SLAVE_ADDR in i2c.scan() and ping_slave():
                return True
        except OSError as exc:
            print("expansion probe:", exc)
        time.sleep_ms(100)
    return False


def apply_global_channel(channel):
    if channel <= LOCAL_CHANNELS:
        if has_expansion:
            try:
                if not slave_send(CMD_RESET):
                    update_display("Exp timeout", "reset", "", "", "")
            except OSError as exc:
                print("slave reset failed:", exc)
                update_display("Exp error", "reset failed", str(exc)[:15], "", "")
        board.apply_channel(channel)
        return

    local = channel - LOCAL_CHANNELS
    if local < CMD_APPLY_MIN or local > CMD_APPLY_MAX:
        raise ValueError("expansion channel out of range")

    board.reset_all("Local RESET")
    try:
        if not slave_send(local):
            update_display("Exp timeout", "CH" + str(channel), "slave busy?", "", "")
    except OSError as exc:
        print("slave apply failed:", exc)
        update_display("Exp error", "CH" + str(channel), str(exc)[:15], "", "")


def draw_channel_ui():
    mark = "*" if selected_channel == active_channel else ">"
    update_display(
        "Select CH" + str(selected_channel),
        "Active CH" + str(active_channel),
        mark + " CH" + str(selected_channel),
        "Max CH" + str(channel_count),
        "Push: apply",
    )


led = Pin("LED", Pin.OUT)
led.off()

enc_a = Pin(ENC_A_PIN, Pin.IN, Pin.PULL_UP)
enc_b = Pin(ENC_B_PIN, Pin.IN, Pin.PULL_UP)
enc_sw = Pin(ENC_SW_PIN, Pin.IN, Pin.PULL_UP)

i2c = I2C(0, sda=Pin(SDA_PIN), scl=Pin(SCL_PIN), freq=I2C_FREQ)
devices = i2c.scan()
print("I2C devices:", [hex(device) for device in devices])

oled = None
if OLED_ADDR in devices:
    oled = SSD1306_I2C(WIDTH, HEIGHT, i2c, addr=OLED_ADDR)
elif devices:
    # Fall back to the first non-slave device if address wiring differs.
    for addr in devices:
        if addr != SLAVE_ADDR:
            oled = SSD1306_I2C(WIDTH, HEIGHT, i2c, addr=addr)
            break
else:
    print("No I2C device found on GP20/GP21")

board = RelayBoard(led=led, on_status=update_display)

update_display("Boot", "OLED OK", "Wait exp...", "", "")
has_expansion = wait_for_expansion()
channel_count = MAX_CHANNELS if has_expansion else LOCAL_CHANNELS
print("expansion:", has_expansion, "channels:", channel_count)

if has_expansion:
    update_display("Boot", "OLED OK", "Exp found", "CH1-" + str(channel_count), "")
else:
    update_display("Boot", "OLED OK", "Solo mode", "CH1-" + str(channel_count), "")

board.reset_all("Power-on RESET")
if has_expansion:
    try:
        if not slave_send(CMD_RESET):
            print("slave boot reset timeout")
            has_expansion = False
            channel_count = LOCAL_CHANNELS
    except OSError as exc:
        print("slave boot reset failed:", exc)
        has_expansion = False
        channel_count = LOCAL_CHANNELS

time.sleep(RESET_TO_SET_SEC)

selected_channel = 1
active_channel = 1
apply_global_channel(1)
draw_channel_ui()

last_encoder_state = (enc_a.value() << 1) | enc_b.value()
encoder_direction = 0
last_button_ms = time.ticks_ms()
last_selected_channel = selected_channel
last_active_channel = active_channel

while True:
    encoder_state = (enc_a.value() << 1) | enc_b.value()
    if encoder_state != last_encoder_state:
        if last_encoder_state == 3 and encoder_state == 1:
            encoder_direction = 1
        elif last_encoder_state == 3 and encoder_state == 2:
            encoder_direction = -1
        elif encoder_state == 3 and encoder_direction:
            selected_channel = min(
                channel_count, max(1, selected_channel + encoder_direction)
            )
            encoder_direction = 0

        last_encoder_state = encoder_state

    now_ms = time.ticks_ms()
    if enc_sw.value() == 0 and time.ticks_diff(now_ms, last_button_ms) > BUTTON_DEBOUNCE_MS:
        last_button_ms = now_ms
        if selected_channel != active_channel:
            apply_global_channel(selected_channel)
            active_channel = selected_channel

    if selected_channel != last_selected_channel or active_channel != last_active_channel:
        draw_channel_ui()
        last_selected_channel = selected_channel
        last_active_channel = active_channel

    time.sleep(LOOP_DELAY_SEC)

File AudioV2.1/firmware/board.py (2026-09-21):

"""AudioV2 Pico ピン／I²C（MeasureControl・FrontPanel のネットに合わせる）。

数値の正は回路図。ここはファームが読むためのコピー。
"""

# I²C0 — PT2314E 同居。OLED が無いので 100 kHz でよい。
I2C_ID = 0
I2C_SDA = 20
I2C_SCL = 21
I2C_FREQ_HZ = 100_000

# FrontPanel MCP23017（UI）。ストラップ固定 **0x22**（娘ジャンパから除外）。
MCP_UI_ADDR = 0x22

# 娘 AmpBank MCP — 基板ジャンパ A2/A1/A0（6 段）。UI 0x22 を飛ばす。
# Bridged12=GND=0 / 2-3 bridge=3V3=1。出荷時オール GND → 0x20。
AMP_ADDR_TIERS = (
    0x20,  # 000 tier1
    0x21,  # 001 tier2
    0x23,  # 011 tier3
    0x24,  # 100 tier4
    0x25,  # 101 tier5
    0x26,  # 110 tier6
)

# ENC INT（MCP OD → Pico）
ENC_INTA = 16
ENC_INTB = 17

# Waveshare LCD SPI0
LCD_CS = 5
LCD_DC = 6
LCD_RST = 7
LCD_EN = 8
LCD_SCK = 18
LCD_MOSI = 19

# タッチ（当面未使用でもピンは確保）
TP_SDA = 10
TP_SCL = 11
TP_INT = 12
TP_RST = 13

# DEST_ADC はラダー廃止済み。読む必要なし（図では D_GND プル）。
DEST_ADC = 26

# Amp バックエンド: "switch" | "relay"（起動時に決める／設定定数）
AMP_BACKEND = "switch"

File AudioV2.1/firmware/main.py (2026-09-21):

"""AudioV2 起動入口。

聴きモード: ENC で操作、LCD に状態。Amp は board.AMP_BACKEND。
計測モード（スペアナ／capture）は後続。
"""

import board
import encoders
import tone
import amp_select
import ui_status


def main():
    i2c = encoders.open_bus()
    print("I2C scan", [hex(a) for a in i2c.scan()])

    ui_mcp = encoders.UiMcp(i2c)
    tn = tone.Tone(i2c)
    amps = amp_select.AmpSelect(i2c)
    status = ui_status.StatusUi()

    dest = "PHONE"  # DEST は機械 SW。センスは廃止済み — 表示は仮／将来 GPIO で
    status.show(
        ch=amps.channel, dest=dest,
        bass=tn.bass, treble=tn.treble,
        backend=amps.backend,
    )
    amps.apply(amps.channel)

    # 骨格: INT が落ちたら GPIO を読んで差分処理（クアドラチャ実装は次）
    while True:
        if ui_mcp.irq_pending():
            a, b = ui_mcp.raw()
            print("mcp", hex(a), hex(b))
            # TODO: ENC デコード → amps.nudge / tn.nudge_* → status.show
            status.show(
                ch=amps.channel, dest=dest,
                bass=tn.bass, treble=tn.treble,
                backend=amps.backend,
            )


if __name__ == "__main__":
    main()

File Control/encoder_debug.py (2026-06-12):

from machine import Pin
import time


ENC_A_PIN = 22
ENC_B_PIN = 26
ENC_SW_PIN = 27

enc_a = Pin(ENC_A_PIN, Pin.IN, Pin.PULL_UP)
enc_b = Pin(ENC_B_PIN, Pin.IN, Pin.PULL_UP)
enc_sw = Pin(ENC_SW_PIN, Pin.IN, Pin.PULL_UP)


def read_state():
    return enc_a.value(), enc_b.value(), enc_sw.value()


last = None
start = time.ticks_ms()
print("encoder debug start: A=GP22 B=GP26 SW=GP27")
print("Turn encoder and press switch for 30 seconds.")

while time.ticks_diff(time.ticks_ms(), start) < 30_000:
    state = read_state()
    if state != last:
        elapsed = time.ticks_diff(time.ticks_ms(), start)
        print(elapsed, "ms", "A", state[0], "B", state[1], "SW", state[2])
        last = state
    time.sleep_ms(10)

print("encoder debug done")

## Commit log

2026-05-26 Reorganize audio KiCad project
    Consolidate the audio project files under the Audio directory and update the renamed AmpModule project metadata. Remove obsolete AudioCase project files, history trim metadata, and tracked KiCad lock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
    [AmpModule.kicad_pcb, AmpModule.kicad_sch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]
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2026-05-29 rework pcb
    [AmpModule.kicad_pcb, AmpModule.kicad_sch, AudioCase.empty.kicad_pcb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]
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2026-05-31 remove generated pcb files
    Keep only the AudioCase board as the project PCB and ignore local KiCad/Python state files.
    [AmpModule.kicad_pcb, AudioCase.empty.kicad_pcb, EQModule.kicad_pcb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]
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2026-06-02 Audio: Controll端子・リレー配線とPCB部品配置まで反映。
    ControllにAmp向け2P端子10個とリレー周りの回路を更新し、AudioCaseへフットプリントを配置。EQ/Amp/Controllは回路図レイアウトに合わせて部品位置を調整（PowerModuleは配線済みのため未変更）。BP5293-50フットプリント修正と配置用スクリプトを追加。
    [AmpModule.kicad_sch, AudioCase.kicad_pcb, AudioCase.kicad_sch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]
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2026-06-03 Update AudioCase PCB with new footprints and layout adjustments for components. Added mounting hole and resistor footprints, ensuring proper alignment with the circuit design. Co-authored-by: Cursor 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
    [AudioCase.kicad_pcb]
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2026-06-17 AudioCaseのリレー・EQネット整理と分割Gerberを再生成する。
    Controllでアンプ別リレーネットを分離し、EQのバッファ入力をL/R_BUFF_INに改名。4枚分割PCBと発注用Gerberを更新し、RVパネルKiKit矩形とmacOS向けツール探索も修正。
    [AudioCase.kicad_pcb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]
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2026-07-26 LCDロードスイッチをXC8107に置換し、3.3V GPIOで確実に切れ切れるようにする。
    AO3401AはPicoの3.3V Highでは5Vレールを切れないため、秋月在庫のあるTorex XC8107AC20MR-Gへ置換。CEプルダウンは既存R717を転用し、CIN/CLは購入済10uFを流用する。あわせてOPA1656シンボルのDescription括弧崩れも修正する。
    [MeasurementADC1804_Module.kicad_sch]
2026-07-26 レビュー指摘の任意項目を直し、旧注記と未使用AO3401定義を片付ける。
    POWER/DIGITAL注記をU704–U710表記に揃え、CT open≈20msに修正。初号はLCD常時ON可と明記する。
    [MeasurementADC1804_Module.kicad_sch]
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2026-07-26 MeasurementADCの配置準備とMBC2596向き修正、KiCad MCP設定を追加する。
    C739/C740を購入済み3216に合わせ、ゾーン仮配置とREADMEのポータブルMCP手順を残す。
    [AudioCase.kicad_pcb, AudioCase.kicad_sch, MeasurementADC1804_Module.kicad_sch]
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2026-07-27 docs: MeasurementADC_STATUS を PCB WIP 引き継ぎ用に更新する。
    配置・VCOM/VIN 進捗、NT701/702 役割修正、次アクションを反映。
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2026-08-13 ASFL発振器FPのGND/VDDパッド入れ替えをデータシートどおりに直す。
    Y701で+3V3_Aが短絡相当になっていた根本原因を、pad2/pad4配置の修正で解消する。
    [AudioCase.kicad_pcb, AudioCase_6_measurement_adc.kicad_pcb]
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2026-08-13 初号ブリングアップの確定切り分けを追記し、次手を ADC 出力確認に更新する。
    U710 RESET 不良と ASFL 初号 FP 逆接、I2S 未出力までを記録し、STATUS を現状に合わせる。
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2026-08-25 AMP島のGNDを両面で縫い、加算ノードの4部品を裏面へ寄せて配線を短くする。
    リファイン案（Audio/AmpModule_OPAMP_REFINE.md）の配線側を先に反映する。
    作業に使ったスクリプトを Audio/scripts/ に残す。
    縫合ビア
    - F面GNDベタが2154mm²あるのに縫合ビアが9本すべて x<=256.7 に偏っていた。
    ベタ上の点から最寄ビアまでの距離を11000点サンプリングすると28.2%が15mm超、
    最遠は31.5mm。未縫合域には出力段(R33/R34, C34/C35)とJ11が丸ごと入っていた。
    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
    [AudioCase.kicad_pcb]
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2026-08-26 TEC3フットプリントをデータシート外形（オフセット3.5mm・端2.0mm）に合わせて修正する。
    パッドピッチはDSどおりで変更なし。本体Silk/Fab/CrtYdの位置ずれを直し、
    基板下配線禁止の注記を追加する。
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2026-08-30 fix(AudioV2): PowerModule を §9 どおり簡素配線に修正
    - USB-C VBUS/GND → CH224、12V → PD_12V/J_PD（SW前）
    - PD_12V_SW → F1 → DKMW +Vin、PD_GND を -Vin/R.C. に一本化
    - ±12V/A_GND → J202、+12V → LM7809 → VCC_TONE
    - C101/C102/C103/C104 と 7809 デカップ追加
    - ピン座標ヘルパで F1(rot90)/7809/コネクタを正しく接続
    [PowerModule.kicad_sch]
2026-08-30 AudioV2 PowerModule: embed lib_symbols and fix KiCad 10 symbol instances
    PowerModule was showing pads-only in KiCad Viewer because lib_symbols was
    empty and symbol instances lacked KiCad 10 pin UUID blocks.
    - Add sch_helpers.py: embed_lib_symbols, symbol_inst_v10, pin_connect
    - Regenerate PowerModule with embedded standard/custom symbol graphics
    - Use Connector:USB_C_Receptacle_USB2.0_16P with correct A1/A4/… pin IDs
    - Wire from computed pin tips with schematic Y-axis flip
    [PowerModule.kicad_sch]
2026-08-30 AudioV2: embed lib_symbols on all child schematics (KiCad 10)
    ControlPanel, RelayBoard, and OutputStage had empty lib_symbols and
    legacy symbol_inst without pin UUIDs — same pads-only issue as PowerModule.
    - Extend sch_helpers: SYMBOL_SOURCES aliases, auto pin_numbers_for,
    BP5293 from Audio/, sanitize (type solid), sub-symbol rename on alias
    - Regenerate all sheets via wire_circuit_design.py (power/control/relay/output)
    - Fix Pico lib_id to MCU_Module:RaspberryPi_Pico (KiCad 10 name)
    - SSD1306-128x64 embeds ER_OLEDM0.91 graphic under alias name
    [AudioV2Case.kicad_sch, ControlPanel.kicad_sch, OutputStage.kicad_sch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]
2026-08-30 docs: PGA231x/CS3310 をデータシートで再照合（±12V 条件） (#21)
    - VOLUME_IC_COMPARISON §1.1 追加: DS 式から I/O 上限を @±12V で再計算
    - PGA2310PA/UA, PGA2311PA/UA, PGA2320IDW, CS3310-KS の比較表・オーダラブル・価格目安
    - ±12V Amp ≈7 Vrms 前提に信号レベル節を更新
    - CS3310 は SOIC のみ・EOL と修正（旧 DIP-16 記述を訂正）
    - CIRCUIT_DESIGN: DS 番号 SBOS207C → SBOS187C
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2026-08-30 docs(AudioV2): シンボル修正 TODO と 4視点レビュー要約
    クラウドエージェント向け WP-A/B/C/D と、実装・確認・レビュー・否定の統合判定を追加。
2026-08-30 fix(AudioV2): WP-B embed flatten / OLED / PowerModule 一次二次分離
    WP-A A1/A2 も取り込み: AudioV2.kicad_sym の二重 embedded_fonts 除去と
    PT2314 float 座標正規化。embed_lib_symbols は extends を親ピン付き定義へ
    flatten。OLED は Conn_01x04 ヘッダに置換。PowerModule は PD_GND と
    PD_12V_SW/F1 の Y 衝突を解消し、7809 GND→A_GND、R.C. オープン。
    [AudioV2Case.kicad_sch, ControlPanel.kicad_sch, OutputStage.kicad_sch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]
2026-08-30 AudioV2: ラベル結線で Power/Control/Output をネット接続
    pin_connect を tip=(at) 基準に修正し、同名ローカルラベルをピン tip に
    載せて結線。グリッドスナップ一致・パッシブ間隔・親シートピン橋渡しを
    整え、一次 PD_GND と二次 A_GND の分離を維持。
    [AudioV2Case.kicad_sch, ControlPanel.kicad_sch, OutputStage.kicad_sch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]
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2026-08-31 AudioV2: Amp再版とRelayBoard本配線、番地ストラップを0Ω化
    高速オペアンプを差せるようAmpをバルク対応で再版した（ゲイン2＝20k/20k、
    ±12V、100µF/rail + 100nF + 1nF、DIP-8ソケット）。親には代表1シートだけ置き、
    物理は同一仕様×10製造とする。PCBは既存基板の端子・4穴を維持したまま上辺を
    15mm拡張してバルクを載せた。
    RelayBoardは未給電Ampへ信号を印加しないよう、Amp入力と±12Vを同一の
    SET/RESETで同時切替する構成で本配線した。番地はA1/A0の0Ωストラップで
    0x20–0x23を選び、1枚のPCB設計を最大4枚に使い回す。SolderJumperは
    F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
    [AmpModule.kicad_pcb, AmpModule.kicad_sch, AudioV2Case.kicad_sch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]
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2026-08-31 AudioV2: RelayBoard addr strap/C301/C302/J_I2Cの生成コードを現図に同期
    wire_circuit_design.pyのaddr_strapがSolderJumper_2_Openと古い座標のまま
    だった問題を、RelayBoard.kicad_schの実座標をpin_connect相当の計算で裏取り
    し、CIRCUIT_DESIGN.md/DECISIONS.mdの論理設計と突き合わせて修正した。JP301/
    JP302をDevice:R(0R/1206 HandSolder)に変更し、U301脇の実位置へ再配置。
    ADDR_A0/ADDR_A1のネットラベルも復活させ、無名ネットのレビュー指摘も解消。
    C301/C302とJ_I2Cコネクタの位置、RelayBoard左端の階層ラベル10個の位置/角度
    も実図に合わせた。
    途中でsch_helpers.grid()が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
2026-08-31 AudioV2: 「拓扑」（中国語表記）を「トポロジー」に修正
    WIRING.md / DECISIONS.md / KICAD_SCAFFOLD_TODO.md / generate_kicad_scaffold.py
    に混入していた中国語の「拓扑」を日本語の「トポロジー」に統一。
    KICAD_SCAFFOLD_TODO.mdのQ3チェックはついでにスター確定を反映して[x]に。
    [generate_kicad_scaffold.py]
2026-08-31 AudioV2: AmpModuleを信号順に配線するようgenerator側を修正
    wire_circuit_design.pyのamp_module_wired()はラベルのみで実配線が無く、
    v1のAudio/AmpModule.kicad_sch（配線68本・ラベル0）と対照的だった。
    OpAmp(AMP701)の2ユニットは、各chの帰還/出力段(R705-710,C707/708)が既に
    ch毎に別の行へ配置済みだったのに対し、ユニット自体の回路図上の位置だけが
    逆（unit1=Rが上段、unit2=Lが下段）になっていて信号がクロスしていたので、
    配置だけ入れ替えて揃えた（物理ピン割当=unit A/Bは変更していないためPCBの
    実配線には影響しない）。
    入力バス(J70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
2026-08-31 AudioV2: A_GND/D_GNDのNetTie位置をControlPanelに確定
    WIRING.mdの「NetTie一点 — 位置未決」を、RelayBoard上での結合と誤読して
    いた点を修正。D_GNDの発生源は操作Pico（ControlPanel）なので、システム
    全体で1点だけのNetTieもControlPanel側に置くのが自然で、RelayBoardは
    A_GND(PowerModule J_RAIL経由)とD_GND(ControlPanel J_I2C経由)を両方
    受け取るが最後まで別ネットのまま通す、と整理した。RelayBoardで結合すると
    NetTieが2箇所目になりグラウンドループになるため。DECISIONS.md G1/G2の
    「結合は一点」は同じ1点を指しているという解釈も明記した。
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2026-08-31 AudioV2: AGENT_HANDOFF §1/§7を本日分の作業で最新化
    シート所有権モデル、I2Cスター確定、端子台決定、A_GND/D_GND NetTie位置、
    AmpModule信号順配線、ユーザーによるRelayBoardリレー回転修正、KiCadクラウド
    ビルド環境（別セッション）の状況を要約に反映。別チャットからの再開プロンプト
    （§7）も同様に更新し、新しい会話でも今日の内容を踏まえて続けられるようにした。
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2026-09-01 ツール: drift 検出と BOM 生成を追加し、レビュー指摘を反映
    方針（SOURCE_OF_TRUTH.md）を実際に回るようにするための道具立てと、
    独立レビューで出た指摘の反映。
    drift（kicad-run.sh + sch_drift.py）:
    - 生成スクリプトの出力と実図の乖離をシート単位で報告。同期はしない
    - 一時ディレクトリで強制生成するのでリポジトリの回路図は書き換えない
    - 「一致」は接続の一致ではないため、比較していない範囲（ワイヤ・
    ジャンクション・ラベルがどのワイヤに付くか）を毎回出す
    - 親シートは部品を持たず実質ノーチェック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
    [gen_parts_bom.py]
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2026-09-01 AudioV2: KiCadで開いて保存し、生成ファイルを正規形式へ正規化
    7ファイルすべて構造比較（sch_drift.pyのS式パーサ）で部品・ネット・
    サブシート構成が保存前と完全一致することを確認済み（check_sexpr/ERC/netlist/
    driftも再実行し数値不変）。実質的な変更はKiCad自身の書式正規化と、
    AudioV2Case.kicad_proのシート一覧・参照キャッシュがAmpBank構成へ追従した点のみ。
    [AmpBank.kicad_sch, AmpChannel.kicad_sch, AudioV2Case.kicad_sch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]
2026-09-01 AudioV2: AmpCh2手直しに伴う所有権更新、電源コンバータ代替調査、発注リスト追加
    AmpBank/AmpChannelはユーザーがKiCadでAmpCh2を手直ししたため生成コード所有
    から手編集所有へ卒業（wire_circuit_design.pyのHAND_EDITED/GENERATED更新、
    driftで確認）。バルクコンデンサ周りの未接続配線をユーザーが修正、ERC 60件に復帰。
    DECISIONS.md §11.1に電流マージンの実測ベース数値根拠を追記（±15V化後の実負荷、
    オペアンプ差し替え最悪ケース）。PowerModuleの絶縁型DC-DCコンバータ(DKMW20F-15)
    のコスト代替調査を開始し、AGENT_HANDOFF.md §2.10に途中経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
    [AmpBank.kicad_sch, AmpChannel.kicad_sch, ControlPanel.kicad_sch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]
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2026-09-02 AudioV2: 出力プルダウンを生成コードと文書へ反映、説明の誤りを訂正
    回路本体は 4af4135（KiCad 側で追加済み）。こちらは追随分。
    - wire_circuit_design.py: amp_channel_wired() に出力 220k を追加（R711/R712）。
    手編集所有シートなのでロジックの documentation として追随させるだけで、
    ここから書き戻さない。部品集合は生成 26 / 実図 26 で対応（drift 確認）
    - AmpChannel.kicad_sch: R611/R612 の Description が R608 のコピーで
    "R input pulldown (after switch)" のままだった。実際は L/R の出力側なので
    "L/R output pulldown (before switch)" に訂正。Description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
    [AmpChannel.kicad_sch]
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2026-09-02 AudioV2: DigiKey API の入手性フィールドが信用できないことを記録
    AM10TW-2415DLPZ について API は ProductStatus=アクティブ / 在庫240 /
    リード0週 / MarketPlace=None / EOL=False を返したが、その ProductUrl は
    "This product is no longer available at DigiKey" だった。実際に買えるのは
    別の Marketplace 出品（DComponents Corporation、約55日、別途 $8.49 送料、
    $12.26）だけ。同じ型番に複数出品があり、API は死んだ方を返していた。
    Aimtec 品は DigiKey の正規ルートから消えており、AM10TW は入手性で不利。
    DCWN06A-12 / DPBW06F-12 / REC6K-2412DRW は実ページでも正規在庫・即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
    [dcdc_survey.py]
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2026-09-02 AudioV2: REC10K-2415DAW/H2 のシンボルとフットプリントを作成
    DC-DC 差し替え（DECISIONS.md 8）の実装その1。回路図はまだ差し替えていない。
    まず CTRL ピンの論理をデータシートで確認した。結果は配線変更不要:
    ON/OFF CTRL DC-DC ON : Open or 2.5VDC < V_CTRL < 12VDC
    DC-DC OFF: Short to -V_IN or 0 < V_CTRL < 0.5VDC
    オープン=ON で現行 DKMW20F-15 の R.C. と同極性。ネットリスト上 U201.6 が
    未接続なのと同じく、CTRL は未接続のままで常時 ON になる。
    フットプリント Audio/Library.pretty/REC10K-AW_1in_THT.kicad_mod:
    データシート p.9 の Recommended Footprint を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
2026-09-02 AudioV2: PowerModule の DC-DC を REC10K-2415DAW/H2 へ差し替え
    ユーザーが KiCad で差し替え、こちらで検証と文書追随を行った。
    ネットリストで全6ピンの接続が機能どおりであることを確認:
    1=+Vin -> Net-(U203-+Vin)（F201 3A slow 経由、C205 47u / C206 0.1u 付き）
    2=-Vin -> /PD_GND
    3=CTRL -> unconnected（オープン=ON。DKMW の R.C. と同極性で配線変更不要）
    4=-Vout -> /-15V
    5=COM -> /A_GND
    6=+Vout -> /+15V
    不一致 0 件。旧 U201 は残っていない。
    差し替えの再採番で U201 -> U203 に変わった。生成コード側は U201/DKMW20F-15 の
    ままなので drift の差は広がった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
    [PowerModule.kicad_sch]
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2026-09-02 AudioV2: Pico に電源が来ていなかったのを修正（+5V→ショットキー→VSYS）
    ERC の pin_not_connected を1件ずつ確認していて見つけた実害。
    Pico U401 の VSYS(pin39) が未接続で、基板から給電されていなかった。
    pin36 の 3V3 は Pico 内蔵レギュレータの「出力」で、OLED・I2C プルアップ・
    PT2314 ロジックはそこから貰っている。つまり基板単体では起動しない状態だった。
    同時に BP5293-50 の +5V 出力が 1ノードのみで宙に浮いていた。DECISIONS.md 793 に
    「RelayBoard 廃止に伴い現状未使用」と記録があったが、これは同じ問題の裏表で、
    本来 +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
    [ControlPanel.kicad_sch]
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2026-09-02 AudioV2: 切替素子比較の結果をハンドオフの変更履歴に記録（issue #33 へのポインタ）
    同じ調査を次のセッションが繰り返さないよう1行残す。決定そのものは
    issue #33 に投稿した見解が正で、§11.1a のラッチングリレーは撤回していない。
    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
2026-09-02 AudioV2: 切替素子を「リレー確定」から「両案検討」へ戻し、ハンドオフを issue #33 の状態へ更新
    方針変更（ユーザー判断）: 切替素子はリレー版とアナログスイッチ版の**両案を並行検討**する。
    **基板として両方を設計してもよい**（JLCPCB 最小ロットが5枚なので、両方起こして実機で
    聴き比べる選択肢が現実的にある）。
    差し戻しの理由は issue #33 の比較で選定の前提が崩れたため:
    1. **9.2Vrms は通常経路では到達しない。** PT2314 のクリップ 2〜2.5Vrms x ゲイン2 で
    DUT 出力の実上限は 4〜5Vrms。この実レベルなら TMUX7612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
2026-09-02 AudioV2: issue #33 のレビュー指摘を反映（C案追加・coherent最悪ケース・測定床）
    1. MAX14753/MAX14778 の THD を「モデル値」と明示。部品間の差は「仮定モデル上では」
    と書くよう switch_compare.py の出力にも注記を入れた。
    2. 判定の基準線を switch_compare.py に追加。PCM1804 の DR 112dB は広帯域値で、
    FFT N=2048（measurement_fw/spectrum.py）の処理利得 30.1dB を効かせると離散高調波の
    実質下限は -142.1dBFS。よって「TMUX7612 の -115.2dB は測定床以下」は成り立たない。
    律速するのは ADC ではなく在庫最良の DUT（OPA1612 -136dB）。
    3. switch_offis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
2026-09-02 AudioV2: 「測定床は PCM1804 の 112dB」の誤りを訂正し、ハンドオフを #33 対応後の状態へ
    別セッションが issue #33 コメント2 の5点に対応して push していた（ab11868）が、
    AGENT_HANDOFF.md と DECISIONS.md がその結果に追従していなかった。
    とくに §1 / §7 / DECISIONS §11.1a に、その commit 自身が覆した主張が
    残っていて、新しいエージェントを誤らせる状態だった。
    ■ 訂正した誤り
    「測定床は PCM1804 の DR≈112dB、TMUX7612 は 9.2Vrms でも既に床以下」
    112dB は広帯域値。スペアナは FFT（Audio/measurement_fw/spectrum.py:19 の
    MAX_N=2048）なので、離散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
2026-09-03 AudioV2: 測定床を2度目の訂正。絶対THDの床は ADC 自身の高調波 -102dB
    issue #33 の再指摘。前回の「DR 112dB + FFT処理利得 30.1dB = -142.1dBFS が
    測定床」も誤りだった。指摘3点はいずれも裏が取れた。
    1. MAX_N=2048 は実使用Nではない
    spectrum.py のコメントどおり「起動時に確保する最大点数」。
    SpectrumAnalyzer.__init__ の既定は n=1024、spectrum_lcd.py も
    FFT_SIZES=(1024,2048) / self.ni=0 なので既定は 1024。
    2. 窓は Hann（fft.py:51 _hann）なので ENBW 1.5bin の補正が要る
    N=1024: 10log10(512) - 10log10(1.5) = 25.33dB → bin床 -137.3dBFS
    3. 最重要 — 処理利得が効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
2026-09-03 AudioV2: 測定床を3度目の訂正。THD+N-SNR の引き算と「床より下＝見えない」を撤回
    issue #33 の再々指摘。3点とも妥当で、データシートで裏を取った。
    1. 「THD+N から SNR を引いて高調波 -102.6dB」は成立しない
    TI_PCM1804.pdf p.7 の脚注どおり、THD+N は fIN=1kHz を Audio Precision
    System Two で 20kHz LPF + 400Hz HPF、つまり無加重。一方 SNR / DR は
    明記どおり A-weighted。加重の違う量を線形電力で引き算はできない。
    → ADC 自身の H2/H3 の実値は不明。
    なお THD+N typ -102dB という数字自体は TI 公式値でそこは正しい。
    2. 「TMUX7612 は ADC 床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
2026-09-03 AudioV2: 総THD同士の合成を撤回し、switch_compare.py の古い測定床ロジックを更新
    issue #33 の最終2点。どちらも妥当だった。
    1. -102 / -115.2 / -136 を総THD同士でベクトル合成してはいけない
    ベクトル合成できるのは同じ次数の成分どうし（H2_ADC + H2_switch など）。
    一方で比較していた2つはどちらも総量だった:
    -102dB = PCM1804 の THD+N 総量（次数別の内訳は不明）
    -115.2dB = TMUX7612 の H2..H9 を RSS した総THD
    13dB -> +1.75dB という式自体は正しいが、PCM1804 と TMUX7612 に
    適用する根拠はない。「仮に同一次数がそのレベルに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
2026-09-03 AudioV2: 次数別テーブルの stage/rbias ハードコードを修正し、床の表現を概算へ後退
    issue #33 の指摘2点。1つ目は私が前回入れた実装ミス。
    1. 次数別 H2/H3 テーブルが旧構成を計算していた
    switch_thd.run(key, "pchip", v, 100e3, a.rload, "both") と
    stage と rbias をハードコードしていた。直前の総THD比較表は
    a.stage（既定 output）/ a.rbias（既定 47k）を使っているので、
    同じスクリプトの中で
    上の表 → 現行の input broadcast + output-only MUX 構成
    下の表 → 旧 input+output 両側スイッチ構成
    という食い違いが起きていた。現行設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
2026-09-03 AudioV2: 説明文のハードコードを解消し、落選判定を ADC 非依存の基準へ置換
    issue #33 の最終2点。
    1. 次数別テーブルの説明文が output-only の数値をハードコードしていた
    表は a.stage に追従するようにしたのに、直後の
    「ADG1407 は H3 支配（H2 -133.4 / H3 -96.3 と 37dB 差）」が固定値のままで、
    --stage both / input で実行すると表と説明が食い違っていた。
    説明文も orders[] に保存した実測値から動的生成するようにした。
    （--stage both なら -126.0 / -95.3 の 31dB 差、input なら 17dB 差と出る）
    2. 落選判定が自己矛盾していた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
2026-09-03 AudioV2: 落選判定を「一次スクリーニング」へ格下げし、条件不一致の失敗パターンを明記
    issue #33。前夜に入れた ADC 非依存の落選判定に、また条件不一致があった。
    ■ 何が揃っていなかったか
    switch 側 = この計算の実条件（G=2 / Vout 4.0・9.2Vrms / RL 50k / ±15V）
    DUT 側 = データシートの参考値（一般に G=1 / 3Vrms / RL 2k・600Ω）
    さらに switch は H2/H3 の最大次数、DUT は THD+N の総量で内訳不明。
    よって「その石は測れない」の証明にはならない。保守的なふるい分けまで。
    表題を「落選判定」→「経路歪みリスクの一次ス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
2026-09-03 AudioV2: DUT の THD+N 振幅カーブを抽出し、振幅軸の条件不一致を解消
    issue #33 で指摘された条件不一致のうち、一番効いていた振幅軸を実際に揃えた。
    DUT のデータシートは Audio/datasheets/opamps/ に在ったので抽出できた。
    extract_dut_thd.py を新設。OPA1612 p.1「THD+N Ratio vs Output Amplitude」の
    6本（G=+1/-1/+10 × RL=600R/2k）をベクタパスから数値化した。
    校正の検証: 抽出 G=+1,RL=2k @3.0Vrms = -138.4dB。データシート実表の規定値
    (G=+1, f=1kHz, VO=3Vrms) は -136dB。2.4dB 差で妥当。軸校正は左軸の %
    目盛（0.01% = -80dB）とも一致する。
    ■ 振幅を揃え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
2026-09-03 AudioV2: 振幅掃引で交差点を特定し、経路ごとの振幅上限を3段階に確定
    issue #33。TMUX7612 の最大次数と OPA1612 の THD+N を振幅を揃えて掃引した。
    Vrms Vpk switch最大次数 OPA1612 差
    4.00 5.66 -166.6dB -139.4dB -27.2dB
    7.00 9.90 -167.2dB -143.4dB -23.8dB
    7.50 10.60 -167.1dB -144.0dB -23.1dB
    7.78 11.00 -150.5dB -144.4dB -6.1dB
    7.90 11.17 -144.9dB -144.5dB -0.4dB ← 交差
    8.00 11.31 -141.4dB -144.5dB +3.1dB
    9.20 13.01 -119.7dB -145.3dB +25.6dB
    交差点 7.9Vrms は Ron 平坦領域の膝（±11V = 7.78Vrms）とほぼ一致した。
    独立に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
2026-09-03 AudioV2: 設計上限 7Vrms の根拠を DUT 比較から外し、スイッチ単独の絶対値へ
    issue #33 の最終指摘。「OPA1612 より 23.8dB 下だから 7Vrms」を設計上限の
    根拠にすると崩れる可能性がある。
    理由（スクリプトに自分で書いていたとおり）:
    DUT 側 = G=-1, RL=2k の THD+N（総量）
    実回路 = G=+2, RL≈50k
    switch 側 = H2/H3 の個別次数
    50kΩ は 2kΩ より圧倒的に軽いので、実 OPA1612 は 2kΩ 時より良くなる可能性が
    高い。その場合 23.8dB の差は縮む方向で、設計保証値として扱えない。
    根拠をスイッチ単独で完結させた:
    7 Vrms = 9.90 Vpk は TM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
2026-09-03 Audio: mpremote で繋ぐとスペアナが止まる件を README に明記
    mpremote は接続時に Ctrl-C を送るので、main.py から自動起動している
    spectrum_lcd がその時点で停止する。exec で状態を見に行くだけでも止まるため、
    「動いているか確認」が「動作停止」になる。実際にこの罠に2回はまった。
    測定するときは好都合（スペアナが PIO/DMA を掴んだままだと capture_raw.py と
    衝突するのでどのみち止める必要がある）。
    スペアナへ戻すときは reset を送ったあと mpremote で触らないこと。
    確認は LCD の表示で行う。確実にしたいなら電源の入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
2026-09-03 AudioV2: Control と親を手編集所有へ卒業させ、上書き事故を塞ぐ
    ユーザーが KiCad で親に MeasureControl シートを配置し、ControlPanel に
    -15V(input) / +5V(output) の階層ピンを追加した。生成スクリプトは
    MeasureControl を出力しないため、この状態で `wire_circuit_design.py parent`
    を回すとシート配置ごと消える。
    control / parent を main() の HAND_EDITED へ移動（--force-control /
    --force-parent が脱出ハッチ）。結果として GENERATED は空になり、
    このスクリプトはどのシートも書き換えなくなった。役割はロジックの
    ドキュメントと drift の比較基準だけ。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
2026-09-03 AudioV2: B0i 完了と、シート編集の道具立てを §2.8 / §5 へ
    やることリストを更新（B0i 完了 → 次は B3a: AmpBank を 5ch 娘基板 ×2 へ分割）。
    リレー版（B3b）は AmpChannel が共通になったので切替シートだけで済む。
    道具の一覧と、それぞれが何を保証するかを表にした:
    sch_import.py 往復バイト一致
    sch_edit.py ピン座標は KiCad のシンボルから直読み
    netlist_partition.py 統合・移設の検証はこれ（drift はワイヤを見ない）
    作って捨てた剪定器のことも残した。「浮いた要素を自動判定して落とす」は
    このリポジトリでは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
2026-09-03 Audio: mpremote exec は既定でソフトリセットする罠を記録
    capture_hold.py は RAM に保持したデータを後から読む設計なのに、
    読み出しに `mpremote exec` を使うと **RAM を消してから読みに行く**。
    必ず `resume` を挟むこと。
    mpremote connect <dev> resume exec "import capture_hold; capture_hold.dump()"
    `mpremote --help` の resume に「will not auto soft-reset」とある＝既定はリセットする。
    既知の「mpremote で繋ぐとスペアナが止まる」と同じ系統の罠。
    ファーム自体は実機で動作確認済み（単発キャプチャで RMS=0.00027≒-71dBFS の
    無音判定。閾値 0.003 は妥当）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
2026-09-03 Cloud Agent セットアップ: ngspice を入れる理由を実態へ修正
    「KiCad のシミュレーション連携」と書いてあったが、実際に ngspice を使うのは
    AudioV2/spice/*.cir の `ngspice -b` 単体実行で、KiCad からは呼んでいない。
    スクリプト追加時(2026-08-31)には AudioV2/spice/ がまだ無かったための齟齬。
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2026-09-03 docker: kicad-run.sh の drift を削除し README を現構成へ合わせた
    README の drift 節が drift を検証手段として詳しく勧めていたが、CLAUDE.md は配線の検証に
    sch_drift.py を使うことを明示的に禁じ（ワイヤもジャンクションも比較対象外）、代わりに
    AudioV2/scripts/netlist_partition.py を挙げている。この矛盾を drift の廃止で解消した。
    drift は前提そのものが消えていた。wire_circuit_design.py の GENERATED は空で、all は
    どのシートも書き出さない（旧構成のロジックの記録として残っているだけ）。実際に回すと
    --force-* で旧シートだけが生成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
2026-09-03 AudioV2: ハンドオフが廃止済みの drift の実行を指示していたのを直す
    kicad-run.sh から drift を削除したので、§2.10 の基準値ブロックと §7 の
    検証コマンド一覧が「存在しないコマンドを実行せよ」という状態になっていた。
    - §7 の実行コマンド一覧から drift を外し、代わりに実際に使う
    sch_import.py --roundtrip を入れた。廃止の理由と netlist_partition.py への
    振り替えを明記
    - §7 の基準値（check_sexpr 9ファイル / ERC 53件）は現状と乖離していた。
    数値を書き写すと二重管理で腐るので、CLAUDE.md を正として参照に変えた
    （SO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
2026-09-03 AudioV2: README を現構成へ更新し、案内板の役割に寄せた
    2026-09-03 の構成刷新前のまま取り残されていた。古かったのは
    ±12 V 前提、PowerModule の DC-DC が DKMW20F-12、解体済み ControlPanel
    への言及と「次: ControlPanel ERC 整理」、物理 PCB 14 枚／設計 5 種、
    Audio/ からの流用表（存在しない control_fw を含む）、issue #19 の進捗。
    ただし新しい数値へ置き換えるのはやめた。電源レール・DC-DC 品番・
    シート構成・枚数は DECISIONS.md / CLAUDE.md の所有権表が正で、
    README に写した時点で次の構成変更でまた腐る（SOURCE_OF_TRUTH.md）。
    実際、腐っ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
2026-09-03 AudioV2: ハンドオフ §1 が旧4シート構成のままだったのを直す
    同じファイルの §1 冒頭は現行の4枚（母板 / 計測制御 / 娘基板2版）を書いている
    のに、その少し下の「アーキテクチャの骨格」と「ある / 無いもの」表が刷新前の
    4枚（PowerModule / ControlPanel / AmpBank / OutputStage）のままで、読み比べると
    別のリポジトリの話に見える状態だった。
    - シート構成: 現行4枚へ。娘基板が AmpChannel を5回ずつ（2枚で10ch）に修正。
    シート名と生成器の対応は CLAUDE.md の所有権表へ参照を張った
    - NetTie: 「A_GND / D_GND の NetTie は ControlPanel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
2026-09-03 AudioV2: KiCad で開いて保存し、生成ファイルを正規形式へ（f04f0ad と同種）
    ユーザーが KiCad で全体を確認した際、保存を要求する表記が出たので保存した。
    KiCad が全シートを自身の正規形式へ書き直している。
    ## .kicad_pro が刷新前のシート一覧を持っていた（これが実質的な修正）
    保存で AudioV2Case.kicad_pro の sheet instance / used_designators が
    更新された。中身は PowerModule / AmpBank / ControlPanel / OutputStage の
    まま、つまり 2026-09-03 の構成刷新に追随していなかった。
    **build_motherboard.py / build_daughter.py は .kicad_sch をパッチするが
    .ki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
    [AmpBankRelay.kicad_sch, AmpBankSwitch.kicad_sch, AmpChannel.kicad_sch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]
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2026-09-07 cloud: SessionStart フックを settings.json に登録した
    前のコミットでフック本体と cloud-agent-setup.sh の修正は入れたが、
    登録先の settings.json が無く実際には発火しなかった。それを繋ぐ。
    これで新しいクラウドセッションは、kicad-cli もシンボルも lib-table も
    無い状態からではなく、揃った状態から始まる。
    Claude-Session: https://claude.ai/code/session_01VCArLcCGbMGgxvWJ5HFJiY
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2026-09-07 AudioV2: PT2314 の未使用12ピンに no_connect を立てた
    PT2314 は4入力セレクタ＋音量＋バランス＋トーンの複合 IC だが、この装置が
    使うのはトーンだけ。セレクタと音量段は LOUT/ROUT ごと未接続で孤立させてある。
    ×印が無いと「意図して使わない」と「繋ぎ忘れ」が見分けられない。実際この
    セッションで未配線と誤読した。判断をドキュメントではなく図に残す。
    データシート（PTC, v1.1 1999-03）で裏を取った:
    - 28ピンの名前・番号がシンボルと全一致
    - LOUT/ROUT -> LIN/RIN は Features に言う "Input/Output for External Noise
    Reduction Syst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
2026-09-07 AudioV2: PT2314E に切り替え、トーン網をデータシート通りに組み直した
    無印 PT2314 は DigiKey に在庫が無く（フォーラムでモデレータ自身が調達困難と
    回答し TDA7440 を代替に挙げている）、LCSC / JLCPCB にあるのは PT2314E のみ。
    E は "Improved and replace PT2314 and PT2314A" と明記され、28ピンの名前・番号は
    無印と完全一致（I2C の 26/27 が DATA/CLK -> SDA/SCL に改名されただけ）。
    切り替えにあたって外付け網をデータシートと突き合わせたところ、3箇所ずれていた。
    値の一覧は合っていたが置き場所が入れ替わっていた。2.4k は本来「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
    [ControlPanelAnalog.kicad_sch, MotherBoard.kicad_sch]
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2026-09-08 AudioV2: ADC 枝の PPTC は戻さないと確定。LDO が保護そのもの
    F1603（PPTC 0.15A）は U1604 専用だったので一緒に消えた。戻すか未判断だったのを
    「戻さない」で閉じた。必要性で判断した。
    PPTC が守っていた相手（スイッチャの入力）が消え、残った LT1763 ×2 は自分で保護を
    持っている（ADI_LT1763.pdf: current limiting / thermal limiting /
    Output Short-Circuit Duration Indefinite）。
    故障の木:
    LDO 出力短絡（最もありうる） LDO が自己防衛。+15V は 500mA 級で REC20K 内。アンプ継続 → PPTC の有無で差なし
    LDO の IN→OUT 短絡 15V が ADC へ。P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
2026-09-09 AudioV2: リレーは v1 と同じ AZ850P2-5 に固定。セカンドソース前提を回路図と生成コードから外した
    査読の指摘「AZ850 と TQ2-L2 は外形が同じでも接点ピンの割り当てが違い、挿すと SET/RESET が
    反転する」に対し、ユーザーが v1 と同じ石で固定と判断（2026-09-09）。
    - build_daughter.py: 「TQ2-L2-5V 互換」のコメントを外し、K301-K305 の Description に
    「AZ850P2-5 以外を挿さない」と理由を書いた（place() に description を通した）
    - 接点ピンの使い方（3/8・4/7、2/9 開放、コイル 1-5 / 10-6）は v1 のネットリストと同一で、
    v1 実機で動いてい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
    [AmpBankRelay.kicad_sch]
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2026-09-10 AudioV2 PCB: 娘基板の残り10点を配置し AmpBankSwitch 88点を全て盤面へ
    上部の空き帯へ U_IO301(MCP23017)・J_PWR301/J_ANA301・±15V バルク2個・
    C_IO301 を、TMUX の左に C311-C314 を置いた。部品範囲は 92.3 x 92.2 mm。
    コートヤードの重なりは 0。kicad-cli drc で schematic_parity 0、
    新規の電気・機械違反なし（増分はリファレンス文字のシルク重なり 9 件のみ）。
    配置検証スクリプトの回転規約を修正: KiCad は (x cosθ + y sinθ,
    -x sinθ + y cosθ)。符号を逆にしていたため rot90 の部品の bbox が
    アンカー基準で反転し、U_IO301 が外形の外に出ていた。
    Co-au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
    [AudioV2Case.kicad_pcb]
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2026-09-19 AmpChannel Rf/Rg を 0.1% に確定し、PARTS に調達クラスを書く
    issue #38: PRECISION/MATCH/SPEC 方針を PARTS.md §0c に反映。
    ゲイン抵抗は図上 Value を 20k 0.1% にし D-i を閉じる。
    フィルムは既存 B32529/P5 のまま MATCH（LCR 選別）。BOM を再生成。
    [AmpChannel.kicad_sch]
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2026-09-23 relay rework
    [AmpBankRelay.kicad_sch, AudioV2Case.kicad_pcb]
2026-09-23 AudioV2: AZ850 の SETC/RSTC を DS どおりに揃え、Relay PCB を追従
    コイル pin5=SETC / pin6=RSTC に直し、接点は reset 側 4/7=バスのまま。生成スクリプトも sch/PCB に合わせた。
    [AmpBankRelay.kicad_sch, AudioV2Case.kicad_pcb]
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2026-09-23 AudioV2: 娘の ADDR 早見表シルクと Relay ジャンパ参照を修正
    両娘右下に I2C 番地早見表を追加。Relay の ADDR ジャンパ参照を回路図の JP_ADDR_A*302 に揃える。
    [AudioV2Case.kicad_pcb]
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2026-09-23 AudioV2: build_motherboard の構文エラーを修正
    同一行に潰れていた els.append を分け、再生成が走るようにした。
    [build_motherboard.py]
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2026-09-25 docs: 高速寄りオペアンプ精査の査読反映・AD797 DS 保管・AudioV2 NOW の高速娘メモ (#44)
    * docs: 高速寄りオペアンプ精査メモの査読を反映（LT1364 の条件訂正・雑音見積もり・未決の明記）
    - OPAMP_FAST_DS_REVIEW.md
    - LT1364: DS の Rf=Rg=1k は AV=−1 の図の条件（AV=2 の図に抵抗値の記載なし）と訂正
    - §3.7 雑音の見積もり（1 kHz 入力換算、20k/2k/1k 網）。2k 網でも網の熱雑音が支配、
    低域は入力フィルムとバイアスで決まる点を追記。OPA1612 の「2k で低ノイズ石側に戻る」を修正
    - AD797: DS の不平衡ソース抵抗の条件（200 kΩ/G）と Ib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
2026-09-25 AudioV2.1: 選んだ 1 ch だけ生かす構成の検討用に v2 を複製し、独自の決定ログと根拠データを整える (#45)
    - AD797: DS の不平衡ソース抵抗の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
    [AmpBank.kicad_sch, AmpBankRelay.kicad_sch, AmpBankSwitch.kicad_sch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]
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
